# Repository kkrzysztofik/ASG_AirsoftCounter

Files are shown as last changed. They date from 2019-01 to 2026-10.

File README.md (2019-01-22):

Schemat mocno uproszczony, bez masy, ani zasilania. Same kable sygnałowe. Do otworzenia w progamie http://fritzing.org/home/

Budowa i części opisane w temacie:
https://forbot.pl/forum/topic/12780-airsoftowy-gadzet-koparka-airsoftcoin/

Filmik z działania: https://www.youtube.com/watch?v=qoA_SEkDOQQ

Przy pierwszym uruchomieniu trzeba odkomentować linijkę 27 z pliku System.cpp, żeby wgrać podstawowe ustawienia. Następnie trzeba uruchomić urządzenie, zakomentować linijkę ponownie i wgrać program ponownie. Dopiero wtedy zapis ustawień będzie działał poprawnie. 

Licencja mit, więc można budować, przerabiać, a nawet sprzedawać.

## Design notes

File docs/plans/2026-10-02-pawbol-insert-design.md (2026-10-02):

# Pawbol S-BOX 416-P insert: base tray and lid panel

Date: 2026-10-02
Status: model written 2026-10-02, `make mech` green (13 checks, 9 parts, all single solids). The
retention scheme and the cell cradle both changed while the geometry was being built; see "Changes
during implementation" below. Every number is either read from a source named beside it, or listed
under "Must be measured" / "Unverified".

The budget tier's Pawbol enclosure ships as an empty tub: **no mounting plate, no brass inserts, no
knockouts**. This spec adds two printed PETG parts so a unit can be assembled by dropping parts in
and turning four screws, instead of measuring standoffs into base bosses.

Follows the same generator philosophy as the boards (`design.py` -> `gen_sch.py`/`gen_pcb.py`): one
Python module holds the numbers, one command emits the artefacts.

## Goal

- Give the pack board, its four 18650 cells, the carrier and all off-board parts a defined home.
- Keep the assembly reversible and the enclosure unmodified apart from the holes the panel devices
  need anyway.
- Close the risk the pack design already flags: "spring-contact holders can open momentarily under
  shock (airsoft use) ... add a strap or lid". The printed cradle is that strap.

## Scope

In: the base tray, the lid panel, the speaker grille, drill templates, and the build tooling.

Out: the carrier and pack PCBs, the panel devices themselves, the Deluxe Kradex ZP240.190 enclosure
(240 x 191 x 106, has its own plate), the firmware.

## The enclosure: facts

Source: Pawbol *KARTA KATALOGOWA, Puszka instalacyjna serii S-BOX 190x140x70 / bez dławików*,
S-BOX 416_416B_416-P, fetched 2026-10-02. The drawing carries the note **"Wymiary A, B, C są
wymiarami wewnętrznymi S-BOX"** — A, B and C are inside dimensions.

| Quantity | Value | Origin |
|---|---|---|
| Inside (A x C x B) | 190 x 140 x **70** mm | drawing note; the 70 is the **base** interior, the lid recess sits on top of it |
| Outside | 196 x 146 mm, base height 78 mm | drawing |
| Wall thickness | **3 mm** | (196 − 190) / 2, confirmed by (146 − 140) / 2 |
| Corner screws | 4, plastic, through the **lid** into full-height corner columns | drawing + product photo |
| Corner column thread depth | about 50 mm (drawing dimension "50") | drawing, unverified |
| Seal | gasket between lid and rim, IP65 | product description |
| Body / lid | PS/ABS RAL 7035 / transparent, −25…+60 °C | catalog table |
| Supplied | **bare tub.** No plate, no inserts, no glands | shop listing, `COSTS.md` |
| Internal features | central cross rib with slots, round floor bosses | drawing |

**The box being ordered has plain side walls — no Ø37 PG29 membranes.** The shop's listing for
416-P advertises 10 knockouts at Ø37/PG29, but the version on order has none (confirmed
2026-10-02). Every wall penetration is therefore a hole that gets drilled. Treat *all* internal
floor features as unverified: do not design anything that depends on the rib or the floor bosses.

## Decisions

| Decision | Choice | Basis |
|---|---|---|
| Part split | **base tray + lid panel**, two prints | keeps the transparent lid face intact, so the LCD needs no window and no gasket |
| Retention | tray sleeves drop **over** the 4 corner columns and locate the tray in X/Y; the lid panel rests on the sleeve tops and the closed lid presses the whole stack down. **No screw stack change** | the column top and the lid plate share the rim plane, so a flange between them lifts the lid off its gasket — see "Changes during implementation" |
| LCD | 20x4 pressed against the inside of the clear lid by a printed frame | same call as the Kradex design (`2026-09-28-esp32-lora-carrier-design.md`): "LCD behind clear lid (no window)" |
| NFC | PN532 in a panel pocket, tapped through the clear lid | carrier design: 3–5 cm expected through 3 mm PC; keep >=20 mm off the LCD frame |
| Buttons | 2 x Ø16 in the **lid**, drilled with a printed 1:1 template | user 2026-10-02; matches the panel's button bosses |
| Speaker | 50 mm in a **wall**, printed **mesh grille** plate outside, foam gasket | user 2026-10-02 |
| Wall sealing | one printed bushing + O-ring per penetration, plus an internal backing block | user 2026-10-02; 3 mm PS/ABS cannot carry a tightened nut |
| Cells | printed **saddle rails** the cells rest in; the board's own holders capture them from above | pack design's shock-dropout risk. A separate hold-down bar was dropped: the holders already clamp the top, so a bar would add nothing |
| Panel vent | **none** | YAGNI. If the speaker sounds boxy in the sealed tub, add the small second mesh panel then |

## Changes during implementation

Three things the approved design assumed turned out not to survive contact with the geometry:

1. **The tray no longer takes the lid screws (was: option B).** The corner columns are solid to the
   rim and the lid seals on the rim, so a flange between the column top and the lid would lift the
   lid off its gasket. The sleeves now only locate the tray; the lid panel presses it down.
2. **The cell hold-down bar is gone.** The pack board's holders already clamp the cells from above,
   so the printed part only has to take the recoil load off the contacts. Two saddle rails do that
   with less plastic and no snap fit to get wrong.
3. **The carrier's posts are margin brackets.** All four of the carrier's M3 holes land inside the
   pack board's footprint, so posts cannot rise from the floor to the carrier. They stand in the Y
   margin either side of the pack board and reach in on 45-degree gusseted arms.

A fourth change is a finding rather than a decision: the LCD and the Heltec only clear each other by
5.5 mm on the assumed `LCD_DEPTH` of 13 mm. `check.py` fails if that narrows to under 2 mm.

## Interfaces

### A. Corner columns

The columns are solid from the floor to the rim, and the lid plate seals on the rim, so there is no
room between the column top and the lid for any printed flange: 3 mm of flange is 3 mm of lid lift
off its gasket. The tray therefore does not touch the screw stack at all.

Each corner gets a **sleeve** that drops over its column, 2 mm wall, stopping at the panel's
underside. The sleeves give the tray positive X/Y location, the box floor stops it going down, and
the lid panel — resting on the sleeve tops and pressed by the shut lid — stops it coming up.
`LEG_FLANGE_T` exists as a parameter in case the box proves to have room after all; it defaults to
0 and nothing else depends on it.

`SCREW_RASTER` is still needed, because it sets where the columns are. **Column size and raster are
unmeasured** — the fit coupon settles both.

### B. Board patterns

Read from the board modules, not invented here:

| Board | Outline | M3 hole raster | Source |
|---|---|---|---|
| Pack | 96 x 90 mm | (4, 4) (92, 4) (4, 86) (92, 86) — 88 x 82 | `hardware/pack.py:434,482` |
| Carrier | 90 x 60 mm | (3.5, 3.5) (86.5, 3.5) (3.5, 56.5) (86.5, 56.5) — 83 x 53 | `hardware/design.py:272,278` |

Both are `MountingHole_3.2mm_M3`. The tray posts are PETG, sized for an M3 self-tapping screw.
The pack board's own corner raster is still flagged provisional in the pack design doc, so the tray
posts are a parameter, not a constant.

### C. Cell cradle

Four troughs at the MYOUNG holder pitch, **21.66 mm** (pack design doc: holders 77 x 20.7 x 14.9 mm
bodies at 21.66 mm pitch), trough radius for an 18.4 mm cell plus clearance, with a snap bar over
the top. The pack board sits on posts above the cells and its holders sit in the troughs, so the
cradle takes the recoil load off the holder contacts.

### D. Wall penetrations

| Device | Hole | Notes |
|---|---|---|
| Key switch | Ø22.3 | EAO 82-6121.2000 / KS22; bushing also gives it something to tighten against |
| Speaker K50 | Ø50 | printed mesh grille plate outside, foam gasket; **the only hole that also gets a printed drill guide ring** |
| USB-C panel extension | Ø12.2 nominal, **measure the actual barrel thread** | IP67 only while capped or mated |
| SMA bulkhead | Ø6.5 | O-ring plus star washer, hex pocket inside to hold the nut |
| Buzzer BZ-38 | measure the body | no IP rating of its own — bushing + O-ring is what seals it |

Positions are free parameters; the defaults keep the SMA high on a long wall, away from the u.FL pad
and the LCD.

### E. Lid

- 2 x Ø16 button holes, 1:1 printed template, backed by the panel's button bosses.
- LCD frame presses the 20x4 against the clear face.
- PN532 pocket, >=20 mm from the LCD metal frame.
- 4 corner ears in the screw stack of interface A.

## What gets printed

| Part | Qty | Material | Purpose |
|---|---|---|---|
| Base tray | 1 | PETG | corner legs, cell cradle + snap bar, board posts, cable clips, wall backing blocks |
| Lid panel | 1 | PETG | LCD frame, button bosses, NFC pocket, 4 corner ears |
| Speaker grille plate | 1 | PETG | 50 mm mesh, covers the wall hole from outside, foam gasket |
| Drill guide ring | 1 | PETG | clamps to the wall for the Ø50 holesaw only |
| Drill templates | — | paper | 1:1 sheets, same style as the existing `fab/print_1to1.pdf` |

## The height budget

Measured from the tray floor up:

| Item | mm |
|---|---|
| Tray floor | 2.4 |
| 18650 cell | 18.4 |
| Pack board | 1.6 |
| Standoffs, pack -> carrier | 8 |
| Carrier | 1.6 |
| Heltec in its 2x18 headers | 15 |
| **Subtotal from the floor** | **47.0** |
| LCD + HW-61 backpack (hangs from the lid) | 12–20 |
| Lid panel | 3 |
| **Total** | **62–70** |

Against 70 mm of base interior plus the unmeasured lid recess. It fits, with the lid recess as the
margin. This replaces the first estimate, which wrongly assumed the 70 mm included the lid.

## Parts and repo layout

```
hardware/mech/
  insert.py      # parameters + the tray, panel, grille and template builders
  out/           # generated *.step/*.stl (gitignored); print_1to1.pdf is committed,
                 #   as fab/print_1to1.pdf already is for the boards
```

The build123d model is one module in the repo's style: all dimensions as named top-level parameters,
one `main()` that writes every artefact, one self-check that runs on plain `python3` without
build123d installed.

```bash
make mech          # new target in hardware/Makefile, next to `boards`
```

**Toolchain:** `uv` with PEP-723 inline script metadata, so `uv run hardware/mech/insert.py` resolves
build123d without a venv or a requirements file. Verified 2026-10-02: build123d 0.13.0 imports under
`uv run --with build123d` on this machine.

## Parameters (named, with defaults)

| Parameter | Default | Status |
|---|---|---|
| `BOX_IN` | (190, 140, 70) | firm |
| `WALL` | 3.0 | firm |
| `COLUMN_XY`, `COLUMN_SIZE` | — | **must measure** |
| `SCREW_RASTER` | — | **must measure** |
| `SCREW_THREAD` | M4 assumed | **must measure** |
| `LID_T`, `LID_RECESS` | — | **must measure** |
| `PACK_XY`, `PACK_HOLES` | (96, 90), 4 mm inset | from `pack.py` |
| `CARRIER_XY`, `CARRIER_HOLES` | (90, 60), 3.5 mm inset | from `design.py` |
| `CELL_PITCH`, `CELL_D` | 21.66, 18.4 | pack design doc |
| `STANDOFF_H` | 8.0 | stack budget |
| `FIT` (drop-in clearance) | 0.4 | tune on the coupon |
| `BUTTON_D` | 16.0 (19.0 Deluxe) | `COSTS.md` |
| `SPEAKER_D` | 50.0 | `OFFBOARD_PARTS.md` |
| `MESH_OPEN` (open area) | >= 40 % | acoustic floor for a printed grille |

## Must be measured before the first real print

1. Corner column: outer size, inner bore, depth, wall-to-column gap.
2. Corner screw: thread, length, how deep it engages.
3. Lid: thickness, the internal corner posts, and the recess depth above the base rim.
4. 20x4 LCD + HW-61 backpack depth.
5. Heltec V4 board-to-header-top height when seated in the carrier.
6. Button body depth and thread length; USB-C barrel thread; SMA thread length.

## v2 (2026-10-02): simplified tray

v1's tray was 117.7 cm3, and a per-feature measurement showed where it went:

| feature | v1 cm3 | share |
|---|---|---|
| floor plate | 44.5 | 35 % |
| wall backings + stems | 23.3 | 18 % |
| carrier posts + arms | 20.1 | 16 % |
| cell saddle rails | 18.6 | 15 % |
| corner L-sleeves | 12.3 | 10 % |
| pack posts | 5.5 | 4 % |
| cable clips | 2.2 | 2 % |

v2 is three changes, none of which moves a single interface:

1. **The floor's empty middle is cut away.** A rim and the two Y bands that actually carry the
   posts, clips and sleeves; the windows stop exactly at the saddle rail edges, because a window
   boundary inside a rail would leave a sliver of floor beside it. 32 % of the floor area goes.
2. **The wall backings are gone** (−23.3 cm3). They existed to hold a nut while you tighten a
   panel device in a 140 mm-deep tub. A nyloc and a finger do the same job. The devices, their
   hole sizes and their drill templates are unchanged.
3. **The saddle rails are 6 mm wide instead of 8** (−4.6 cm3).

Tray 117.7 → **77.9 cm3** (MJF) / 80.6 (FDM). Everything 145.7 cm3, down from 185.4.

### The carrier did not move, and that was decided by search

Moving the carrier onto the lid panel was measured at 20.1 cm3, about $6. It was not taken,
because it does not fit: an exhaustive search at 2 mm resolution over every legal panel position
found **609 valid LCD+carrier pairs and zero valid LCD+carrier+NFC triples**. The panel is
188.4 x 138.4; the LCD (98 x 60) and the carrier (90 x 60) already take two 60 mm bands, and the
NFC needs a 45 x 45 patch that is also >= 20 mm from the LCD frame, while four corner reliefs
punch the margins. Without the NFC it fits immediately (LCD at y 0.4–60.4, carrier at
64.4–124.4, 4 mm apart, ~50,000 legal button positions), but that would have moved the player's
tap from the top of the box to its side, for $6.

So the carrier keeps its margin posts and gusseted arms. Nothing on the panel, in the assembly
order or in the cable route changed between v1 and v2.

## Print cost

MJF and SLA are priced per cm3 of solid material, and the first quote came back at about $100 for one
unit. `quote.py` measures the exported mesh (`stl_volume_cm3`, a signed-tetrahedron sum, so it is
independent of the CAD) and puts a number on where that goes:

| Part | cm3 | Share |
|---|---|---|
| Tray | 77.9 | 53 % |
| Lid panel | 45.6 | 31 % |
| Grille | 8.0 | 5 % |
| Guide ring | 7.2 | 5 % |
| 4 wall rings | 6.9 | 5 % |
| **Total** | **145.7** | |

v1 was 262 cm3 before the guideline pass and 185.4 after it; v2 is 145.7, so the two rounds together
have taken 44 % off. The wall backings and the floor windows were the two features that were pure
bulk; the corner sleeves, saddles and posts are structure and do not shrink further without
giving something up.

A first pass took this from 262 cm3 to 180 cm3 by cutting the two features that were pure bulk: the
wall backings were 26 x 12 mm solid blocks (now a 20 x 6 mm nut pocket, which also stopped them
colliding with the corner columns) and the corner sleeves were closed square tubes (now L-shaped,
same location, a third of the material).

**Two big flat plates are the wrong shape for a volume-priced process.** The tray and lid are 88 % of
the cost and both are things an FDM printer does well: at 15-20 % infill they are roughly 40 g of
filament. Options, cheapest first: print them locally in PETG; buy them from an FDM service; or keep
MJF for the small parts, where the four bushings and the grille are about 15 cm3 together.

Do not skeletonise the tray further to chase cost. Its floor carries the posts, the saddles and the
wall backings, and the remaining bulk is structure, not slack.

## JLC3DP design guideline compliance

Source: <https://jlc3dp.com/help/article/3d-printing-design-guideline>, read 2026-10-02. The MJF
column applies. `check.py` asserts each rule, so a later tweak cannot quietly break one.

| Rule | Guideline | This design |
|---|---|---|
| Build size | MJF max 380 x 284 x 380; min 5 x 5 x 5 or 10 x 2 x 2 | largest 188.4 x 138.4 x 67.6; smallest a 4 mm thick ring, which passes on the 10 x 2 x 2 form |
| Wall thickness | 1.0 / 1.2 / 1.5 mm at 50 / 100 / 200 mm part size | every wall sized against its own part: floor field 1.6, sleeve 2.0, panel 2.5, mesh land 1.5, ring width 6.0 |
| Assembly clearance | 0.2-0.4 mm per side | 0.4 mm per side |
| Hole aperture vs depth | about 3x the diameter | pilot 2.7 x 5, clip groove 4.4 x 10, mesh 3.5 x 1.5 |
| Small columns | D = 3 mm permits H = 3-6 mm | posts are 4:1, so each gets a 3 mm 45-degree base flare |
| Escape holes | 2.5 mm minimum into any enclosed cavity | no part encloses a cavity; asserted by shell count |
| Embossed detail | 0.8 mm deep and wide | none modelled yet; the NFC "tap here" mark will need it |
| Threads | M6 minimum if printing threads | none printed; the posts take M3 self-tapping screws into a 2.7 mm pilot |

Four real non-compliances turned up, all fixed:

1. **Wall thickness.** The tray floor field was 1.2 mm where MJF wants 1.5 at this part size, and the
   speaker mesh land was 1.0 mm where it wants 1.2. The floor field is now 1.6 mm and the mesh land
   1.5 mm (2.7 holes became 3.5 mm at a 5.0 mm pitch, which still opens 42 %).
2. **Assembly clearance.** An 0.4 mm total drop-in gap is 0.2 mm per side, but MJF's hole tolerance is
   +/-0.3 mm *and* holes shrink, so the gap was inside the process noise and the tray could arrive
   unable to go in. `FIT` is now 0.8 mm: 0.4 mm per side.
3. **The bushings were degenerate.** Once the wall is drilled at the device's own size there is no
   annulus left for a barrel: for the SMA, 6.5 mm hole against a 6.4 mm device gives a *negative*
   wall. They are rings now, which is what a 3 mm PS/ABS wall around a 22 or 30 mm hole actually
   needs, and the O-ring still seats on the ring.
4. **The printed posts are 4:1 slender**, where the column table allows 2:1. They are attached at the
   base rather than free-standing, but bead blasting is unkind, so each gets a 3 mm 45-degree flare
   for about 2 cm3.

One thing to raise with the shop before committing: the guideline says a large hollow structure is
priced as a "special-shaped model" with a surcharge, and the tray and lid are exactly that.

## Verification

1. **Self-check** (`python3 -c` importable without build123d): bounding box fits `BOX_IN` minus
   clearance, the two post rasters equal the board modules' `PLACE["H*"]` coordinates, and the stack
   total in the table above is <= the base interior.
2. **Fit coupon first** — a single small print carrying one corner leg, one column sleeve and one
   board post. It settles interface A (the only interface with no second chance: a wrong column
   means a reprint of the whole tray). Print the coupon before the tray, always.
3. **1:1 paper templates** against the real box for the button and wall holes, before any drilling.
4. `make mech` green, plus a 1:1 outline print of the tray to lay on the box floor.

## Risks

- **Corner column unmeasured.** The leg is the one feature that cannot be salvaged after printing.
  Mitigated by the coupon and by `FIT` being a parameter.
- **Lid internal corner posts** may collide with the panel ears. Measure before printing the panel.
- **Screw length.** Adding 6 mm may exceed the original screw. Fallback: four longer plastic screws,
  or a printed captive-nut corner that drops the column's thread entirely.
- **Drilling PS/ABS by hand** crazes or cracks the wall. Use a step drill or holesaw at low speed,
  back the wall, and use the printed guide ring for the Ø50.
- **Printed mesh** attenuates high frequencies. Keep open area >=40 %, slots not round holes, and put
  the grille as close to the speaker as the wall allows.
- **Sealed tub** with the speaker inside: no vent. Accepted for now; the small mesh vent is the
  known upgrade path if it sounds boxy.
- **PETG at 60 °C** (the box's rated top): Tg is about 80 °C, so no creep expected, but the panels
  are clamped, not load-bearing.

## Unverified

- Every `must measure` item above.
- Whether the delivered plain-wall box still has the central cross rib and the floor bosses. Nothing
  in the design depends on them.
- The corner column's thread depth ("50" on the drawing is almost certainly this, but it was read
  from a section view, not from a dimension table).
- The exact 416-P lid screw part. The tray assumes a reusable, standard plastic screw.

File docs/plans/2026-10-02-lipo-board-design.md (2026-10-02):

# AirsoftCounter LiPo board: 2S/3S airsoft LiPo instead of the 18650 pack

Date: 2026-10-02
Status: hardware generated (`make BOARD=lipo all` into `fab/lipo/`). A third power board next to the 18650 pack variants A
(`2026-10-01-pack-board-design.md`) and B (`2026-10-02-pack-board-variant-b-design.md`). Fit one
power board per build; the carrier does not change.

## Goal

Run the device from the 2S/3S LiPo an airsoft player already carries (XT60 or T-plug, with a balance
lead). **No charging**: players charge on their own balance charger. The board must protect the
LiPo from over-discharge per cell, without relying on the Heltec firmware.

## Why a separate board

Putting a LiPo input on the 18650 pack board was rejected: feeding a buck into SYS lets the
BQ25601 BATFET charge the 18650s from the LiPo with nothing controlling it. Avoiding that needs
ideal-diode ORing before the key, a second ADC and board space the 96 x 90 mm pack does not have.
A separate board has no cells, charger or per-cell switches, so it is small.

A "dummy cell" (a buck module whose output goes into an 18650 holder) was rejected: it has no LVC.

## Why it keeps an MCU

The system is 1S throughout (`VBAT_SW` 3.0-4.2 V feeds the Heltec battery socket and the amp), so
the board bucks the LiPo down to a fake single cell. The low-voltage cutoff must **latch**: a cutoff
that removes its own supply restarts and trips again in a loop until the pack is flat (this kills
the "ADS1115 ALERT pulls buck EN" idea, and any Heltec-driven cutoff). An always-on MCU holds the
cutoff and does a per-cell check through the balance lead. Three comparators, a reference and a
latch would cost more parts than one STM32C071, and that chip is already used in variant A.

## Block diagram

```
XT60 pigtail ─ fuse 5 A ─ rev-pol P-FET ─ TVS ─┬─ HV LDO 3.3 V (Iq <= 5 uA) ── STM32C071 [always on]
                                               ├─ buck A -> 4.10 V -> VBAT_SW ─┐
                                               └─ buck B -> 5.07 V -> +5V ────┤ J_PWR1 6-pin XH
both buck EN = key (pull-up) AND MCU_OK (open-drain)                          │ to the carrier
balance 4-pin XH ─ dividers (always on) ─ MCU ADC; MCU = I2C slave 0x30 ──────┘
```

## Blocks

### Input
- **XT60 pigtail**: a short 14 AWG (1.5 mm2) lead soldered to the 1.5 mm2 2-pad solder-jumper
  footprint, with a female XT60 panel or inline connector. T-plug users use an adapter lead.
- **Fuse 5 A** SMD, first part after the input. A LiPo short is hundreds of amps.
- **Reverse polarity**: P-FET in the positive lead, gate to GND through a resistor, zener gate clamp.
- **TVS** across the input, standoff above 12.6 V (3S full), clamp below the bucks' absolute max.
- Input range to design for: **5.5-17 V working, >= 20 V absolute** (2S empty to 4S full, so 4S
  could be added later without new parts).

### Bucks
- **One IC type used twice**, >= 20 V input, >= 3 A, with an EN pin that has a defined threshold.
  Pick the part with datasheet facts and live stock, like P0 of the pack plan.
- **Buck A -> 4.10 V on `VBAT_SW`**: Heltec battery socket and amp (1.5 A peaks). 4.10 V is below
  4.2 V, so a plugged-in Heltec USB charges into the buck output harmlessly (the buck cannot
  sink; its output rises and it stops switching). Keep `VBAT_SW` bulk capacitance at the amp as on
  the carrier.
- **Buck B -> 5.07 V on `+5V`**: LCD, LEDs, buzzer. Two bucks convert more efficiently than a buck
  to 4 V plus the MT3608 boost back up, for the same part count.

### Always-on supply
- HV LDO 3.3 V, >= 20 V input, Iq <= 5 uA, feeding only the MCU and the divider gate.

### Enable
- **EN = key AND MCU_OK**: the off-board key (`J_KEY`, same connector as the pack boards) supplies
  the EN pull-up, so only microamps pass through it. The MCU pulls EN low through an open-drain pin
  to cut both bucks. Check the EN pin's voltage rating against the pull-up source.

### MCU (STM32C071)
| Function | Use |
|---|---|
| ADC | 3 balance taps + pack total, through dividers |
| GPIO out | buck EN override (open-drain kill FET) |
| I2C slave 0x30 | on the carrier bus over `J_PWR1`; pull-ups on the carrier (no back-powering) |
| Flashing | SWD pads + BOOT0; no USB on this board |

### Balance input
- **One 4-pin XH header**: a 2S balance plug (3-pin XH) fits its pins 1-3. Pin 4 (3S tap) gets a
  pull-down, so a 2S pack reads about 0 V there.
- Dividers sized for 4.2 V x 3 at the top tap, always on: with Basic megohm values they draw
  about 10 uA, next to the MCU's 85 uA Stop current. Each ADC pin gets a 100 nF cap for a low
  source impedance. The top tap is also the pack total, so no separate total divider.

### Carrier connector
`J_PWR1`, unchanged from the pack boards: 1-2 GND, 3 `VBAT_SW`, 4 `+5V`, 5-6 SDA/SCL.

## LVC policy (firmware, defaults to tune with real packs)

- At power-up detect the cell count: 3S tap below 0.5 V means 2S. Reject a pack with a cell below
  the cutoff (stay off, flag it).
- **Warn** at 3.5 V per cell under load (flag for the Heltec to show).
- **Cut** at 3.3 V on any cell, debounced about 2 s so amp peaks do not trip it. The cutoff
  **latches**: EN held low through key cycles.
- **Release** only when every cell rests above 3.7 V (in practice: a fresh pack was plugged in).
- No balance lead: run on the total voltage with the cell count unknown, so warn and stay off (or
  allow with an assumed count; decide during firmware).

Register map: a subset of variant A at 0x30 (version, flags, cell mV x3, cell count, state,
cutoff reason), so the Heltec driver and the `asg-core` `pack` register definitions carry over.

## Key-off drain

STM32C071 Stop about 85 uA (variant A figure) + LDO <= 5 uA + bucks in shutdown (a few uA) +
dividers always on (about 10 uA): **about 110 uA**, so more than a year to drain a 1300 mAh pack.
A LiPo left plugged in is not drained in practice.

## Left out
Charging, balancing, coulomb counting (no current sense), 4S (the input rating leaves room).

## Repo effort
- `hardware/lipo.py` as a board module, built with `make BOARD=lipo all` into `fab/lipo/`. Reuse
  the MCU block from `pack.py` by import if it separates cleanly, as `pack_b.py` does; otherwise copy it.
- Firmware: a `firmware/lipo` sibling of the deferred pack firmware (ADC, thresholds, one GPIO,
  I2C slave). Deferred together with the pack firmware.

## Parts (verified 2026-10-02)

Sources: vendor datasheets and the live JLCPCB parts API (type: B Basic / P Preferred / E Extended).

| Item | Decision | Source | Date |
|---|---|---|---|
| Buck (x2) | TPS54302DDCR, TSOT-23-6, C311983 (E): VIN 4.5-28 V rec / 30 V abs; VREF 0.596 V typ; EN rising 1.23-1.28 V, EN abs max 7 V (rec max 5.5 V); shutdown 2 uA; HS current limit 4/5/6 A; 100% duty at 6 V in / 4.1 V out; fSW 400 kHz | TI SLVSDG6C (rev. 2026-03) | 2026-10-02 |
| EN node | R_EN1 100k / R_EN2 47k: EN = 0.32 x VIN -> 4.17 V at 13.05 V and 5.37 V at 4S 16.8 V, under the 5.5 V recommended max and 7 V abs max | TI SLVSDG6C | 2026-10-02 |
| Feedback | Vout = 0.596 x (1 + Rtop/Rbot). Buck A 30k/5k1 -> 4.10 V; buck B 75k/10k -> 5.07 V. Datasheet recommends Rtop ~ 100k (Table 7-2); the Basic 30k/75k tops give exact E24 ratios at ~100 uA divider current while the key is on (bucks are off when the key is open) | TI SLVSDG6C Table 7-2 | 2026-10-02 |
| Output filter | 10 uH + 2 x 22 uF 25V per buck (Table 7-2: 10 uH, 44 uF at 5 V) | TI SLVSDG6C | 2026-10-02 |
| Inductor (x2) | Bourns SRN6045TA-100M, C2046332 (E): 10 uH +-20%, DCR 52 mOhm, Irms 3.20 A (40 C rise), Isat 4.60 A (30% L drop) >= 3.5 A, so one part for both bucks | Bourns SRN6045TA datasheet | 2026-10-02 |
| Always-on LDO | Holtek HT7533-1, SOT-89-3, C14289 (B): supply abs max -0.3..33 V, VIN max 30 V, Iq 2.5 uA typ / 4.0 uA max, 100 mA; pins 1 GND, 2 VIN, 3 VOUT; C_in = C_out = 10 uF | Holtek HT75xx-1 Rev 2.40 | 2026-10-02 |
| LDO series R | none: the 33 V abs max is above the SMBJ15A 24.4 V clamp | Holtek + Littelfuse | 2026-10-02 |
| Reverse FET | AO3401A, SOT-23, C15127 (B): VDS -30 V, VGS +-12 V, RDS(on) 60 mOhm at VGS -4.5 V, ID -4 A; pinout 1 G, 2 S, 3 D. Was AO3407A (E, VGS +-20 V); the 10 V gate clamp keeps VGS inside +-12 V | AOS AO3401A datasheet; JLCPCB API | 2026-10-02 |
| Input TVS | SMBJ15A, DO-214AA, C19077569 (P, hongjiacheng; was C113988 E): VRWM 15 V (above 12.6 V 3S full), VBR 16.7-18.5 V, VC 24.4 V at 24.6 A, 600 W; below the buck 30 V and LDO 33 V abs max | Littelfuse / Diodes SMBJ15A | 2026-10-02 |
| Gate clamp | MMSZ5240B, SOD-123, C19077425 (P): 9.5-10.5 V, 500 mW. Below the AO3401A's 12 V VGS limit, also with VIN at the 24.4 V TVS clamp (0.14 mA through R_REV1). Replaces BZT52C12 (E); the earlier "no Preferred 12 V zener" note was wrong (MMSZ5242B C19077426 is Preferred) | JLCPCB API | 2026-10-02 |
| Input leads | Connector_Wire:SolderWire-1.5sqmm_1x02_P6mm_D1.7mm_OD3mm, 14 AWG / 1.5 mm2: the ~3 A worst case at 2S empty is marginal on 1 mm2 (17 AWG); 1.5 mm2 matches common XT60 pigtails and the 1.7 mm hole takes 14 AWG | design-doc current; KiCad footprint | 2026-10-02 |
| Balance header | one B4B-XH-A (C144395): JST XH is a 2.5 mm friction-lock box-shrouded header; a 3-circuit XHP housing seats on pins 1-3 and locks on the full-length shroud wall. Tap 3 then reads 0 V on a 2S pack | JST XH series drawing | 2026-10-02 |
| Dividers | Basic 1M (C17514) / 470k (C17709): tap1 470k/1M -> x0.680, tap2 1M/470k -> x0.320, tap3 2M/470k -> x0.190; at 4.35 V/cell (13.05 V pack) the taps read 2.96 / 2.78 / 2.48 V, all under the 3.3 V ADC ref | design values | 2026-10-02 |

### Plan-time changes

- Balance dividers are always on: no divider switch and no separate pack-total divider (the top tap
  is the pack total). With Basic megohm values they draw about 10 uA, next to the MCU's 85 uA Stop
  current; each ADC pin gets a 100 nF cap for a low source impedance.
- No reset/boot buttons and no status LED: SWD pads only (a blank STM32C0 boots its ROM bootloader
  by itself). Saves the TACT and LED and their drain.
- The bucks default ON when the key is on: the kill FET's gate has a pull-down (R_GK), so the bucks
  run with the MCU unflashed (bring-up) and the firmware latches them off.
- One 10 uH inductor (`L_A` = `L_B`, C2046332) for both bucks: its 4.6 A Isat covers buck A's peaks.

## Generated

`hardware/lipo.py` -> `make BOARD=lipo all` writes `lipo.kicad_sch`, `lipo.kicad_pcb` and the JLCPCB
package into `fab/lipo/` (gerber zip, BOM/CPL, schematic and renders). Freerouting: 462 tracks/vias,
0 unrouted; ERC 0, DRC 0 violations, 0 schematic-parity issues; gerbers 11 files, 70 x 50 mm,
4 x 3.2 mm NPTH. The 49 placed parts are 38 Basic, 4 Preferred (75k C17819, BSS138 C7420339, MMSZ5240B C19077425, SMBJ15A C19077569) and
7 Extended LCSC numbers (9 placements): 4 SMD types (5 A fuse C48332, TPS54302 x2 C311983,
SRN6045TA x2 C2046332, STM32C071 C42116633) and the
3 through-hole XH headers (KEY C158012, BAL C144395, PWR C144397). Economic PCBA charges one
feeder-setup fee per SMD Extended type; the XH headers are per-joint.

**SW node width (whole-branch review, 2026-10-02).** The two switch nodes route at the Default
0.25 mm, not the Power 0.8 mm the plan listed: the TSOT-23-6 SW pad at 0.95 mm pitch only admits a
necked exit, so no class width widens the run (Freerouting left it unrouted at 0.8 mm). `SW_A`'s
~8 mm run carries buck A's inductor current, ~1.5-2 A RMS (Heltec TX peaks plus brief amp peaks);
0.25 mm / 1 oz is about 0.9-1.4 A at a 10-30 C rise, i.e. at the edge of its rating. It is accepted
for the bursty airsoft duty on a short run with GND pours on both layers; a manual neck-and-widen
(the autorouter cannot express it) is the upgrade path if a wider margin is wanted.

## Bring-up

Bench supply on `J_IN1` at 7.4 V with a 100 mA limit:
1. Key open: only the LDO runs. `TP_3V3` reads 3.3 V and the input current is a few hundred uA with a
   blank MCU (STM32C0 Stop ~85 uA + LDO ~2.5 uA + dividers ~10 uA + buck shutdown).
2. Key closed: `VBAT_SW` 4.10 V and `+5V` 5.07 V. The bucks default on because `R_GK` pulls the kill
   FET's gate low; the firmware latches them off later.
3. Reversed supply: no current (the reverse P-FET blocks; the TVS should not conduct).
4. Then a real 2S pack and a real 3S pack, reading the three balance taps through the firmware.

## Unverified
- STM32C071 system bootloader over I2C (AN2606): if it is supported, the Heltec could flash the
  board over `J_PWR1` and the SWD pads would be for recovery only.
- Debounce time and thresholds with a real amp load on a worn pack.

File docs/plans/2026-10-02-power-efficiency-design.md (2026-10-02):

# AirsoftCounter power efficiency: a weekend on the 18650 pack

Date: 2026-10-02
Status: docs and model done (E1-E3); firmware C2-C8 and validation wait for the hardware. No board changes.

## Goal

One charge of the 18650 pack (4x Samsung 35E, variant A or B) lasts a **weekend**: 2 game days of
10 h plus a 12 h night with the key left on, at 0 °C, on cells aged to 80 % capacity. A player's
LiPo (LiPo board) is a one-day battery and is swapped like a gun battery; it is out of scope.

## Where the energy goes (`hardware/power_budget.py`, Deluxe, game running)

| Load | mA (battery side) |
|---|---|
| 5 V rail via MT3608 (100 mA backlight planning value) | 209 |
| Heltec awake, LoRa RX (240 MHz, no light sleep) | 75 |
| GNSS | 29 |
| PN532 polling | 20 |
| LoRa TX + amp | 13 |
| **Total** | **346** |

Weekend budget: 13400 mAh x 0.84 usable x 0.8 (0 °C) x 0.8 (aged), minus 12 h parked at ~7 mA,
over 20 h of game = **~350 mA**. Today's estimate passes with no margin, and the backlight figure
is still a guess.

Modelled after the display change (E1, `power_budget.py` weekend block, budget 353 mA): today's
firmware with the backlight always on 236 mA (+50 % margin), backlight on a timeout 196 mA (+80 %),
optimized firmware 74 mA (+377 %). The Newhaven alone meets the goal; the firmware work is margin.

## Decisions

### 1. Display: Newhaven NHD-0420D3Z-FL-GBW-V3 replaces the blue 2004A + HW-61

One display for the Deluxe and Budget builds.

- Transflective STN(+), yellow-green: readable in daylight with the **backlight off**. The blue
  2004A is a negative panel and unreadable without its backlight.
- Backlight brightness 1-8 over I2C (`0xFE 0x53 n`, 1 = off, 100 us); the module PWMs it.
- 5 V, 21-44 mA total with the backlight on (datasheet), -20..+70 °C.
- I2C address 0x28 (7-bit), no clash (TCA9534 0x20/0x21, PN532 0x24, PAC1934 0x10, pack MCU
  0x30, ADS1115 0x48). **I2C max 50 kHz**: the shared bus runs at 50 kHz.
- 10k pull-ups on the module, so `R_SDA5/R_SCL5` stay DNP. Same 4 wires to `J_LCD1`
  (GND 5V SDA SCL): **no carrier change**.
- Ships in RS-232 mode: **bridge jumper R1** for I2C. 100 ms power-up delay before the first
  command. Its own command set (not HD44780), so C3 writes one small driver and the PCF8574 path
  is not needed.
- About $17 (Mouser 763-0420D3ZFLGBW-V3, Newhaven direct); TME has none.

Rejected: generic yellow-green 2004A + PCF8574 (on/off only, transmissive, backlight current
undocumented); SparkFun SerLCD RGB (3.3 V logic, not transflective); PWM from an ESP32 GPIO (only
GPIO43/44 are free and they are UART0); PWM by toggling PCF8574 P3 (keeps the CPU awake).

### 2. Firmware power requirements (added to the C-tasks, implemented with the hardware)

| Task | Requirement | Target |
|---|---|---|
| C2 | I2C at 50 kHz (Newhaven limit) | - |
| C3 | Backlight off after a timeout; on (level from config) for a button, card or game event | backlight ~5 % duty |
| C1/C4 | CPU 80 MHz + automatic light sleep | Heltec 75 -> ~20 mA |
| C4 | Light only the ring that carries information | rings 2x -> 1x |
| C6 | PN532 PowerDown between polls; poll only when a card is expected | 20 -> ~5 mA |
| GNSS | One fix at boot, then VGNSS off | 29 -> ~1 mA |
| LoRa | SX1262 RX duty cycle; HQ sends a preamble longer than the sleep window | protocol note |

`R_LLR1/R_LLB1` (0R today) stay the ring brightness knob if the rings are too bright.

### 3. Power model (`power_budget.py`)

- Backlight duty parameter (default 5 %) and the Newhaven current.
- An "optimized firmware" scenario with the targets above.
- A weekend check that prints PASS/FAIL against the budget for today's and the optimized
  firmware, and asserts in the self-check that the optimized one passes.

### 4. Validation (once the hardware exists)

- Instrument: pack variant A's PAC1934 energy accumulators (per-cell Wh); USB meter on `J_PWR1`
  as a cross-check.
- Run each `power_budget.py` scenario for 30 min, replace every EST figure with the measured one,
  re-run the weekend check.
- Pass: measured Deluxe game current fits the weekend budget (~350 mA) with at least 30 % margin.
- Soak: full charge, game-loop firmware until the pack MCU cuts off; compare with the model.

## Not doing (add if the measurements miss)

- +5V load switch: parked drain is ~90 mAh per night, under 1 % of the pack.
- Hardware backlight PWM, LiPo-board changes, lower LoRa TX power.

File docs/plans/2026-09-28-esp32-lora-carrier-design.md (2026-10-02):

# AirsoftCounter v2: Heltec V4 + LoRa carrier board and Rust firmware

Date: 2026-09-28
Status: design approved, implementation not started

## Goal

Replace the hand-wired Arduino Nano build (soldered point-to-point, hot glue,
per-unit LCD address tweaks, not waterproof) with:

- a KiCad carrier PCB for a **Heltec WiFi LoRa 32 V4 (no-display build, R2 or R8)**,
- LoRa **remote control from HQ** (start/stop/configure + status reports),
- **GPS** position in status reports,
- phone configuration over **WiFi AP + web page** (IR remote dropped),
- a **20x4 transflective I2C LCD** (Newhaven NHD-0420D3Z-FL-GBW-V3, see the power-efficiency design),
- **RFID/NFC cards**: player cards (score + per-player stats) and admin cards,
- a **loudspeaker** (I2S class-D amp) in addition to the buzzer, with GPIOs freed by an **I2C GPIO expander** (Part 6),
- a **weatherproof enclosure** (Kradex ZP240.190.105SJp, clear PC lid, IP67),
- firmware rewritten in **Rust** (esp-hal + Embassy).

Existing Nano units are left as they are; no Nano carrier is planned.

## Part 1: MCU board, pins, power

### Heltec V4 facts (verified from Heltec pin maps and Meshtastic variants)

- J2 and J3 are 1x18 2.54 mm headers, identical physical layout on V3/V4.
  V4 adds a separate 4-pin strip (GPIO15-18) at the antenna end: not used.
- Native USB (no USB-UART chip). 5V pin is powered **only from USB** (max 500 mA).
- Battery: SH1.25 2-pin socket, onboard charger. VBAT sense on GPIO1 via
  100k/390k divider (R2 needs ADC_Ctrl GPIO37 HIGH; R8 has no ADC_Ctrl).
- Internally used GPIOs:
  - 2, 5, 7: LoRa front end (KCT8103L CSD, CTX, LDO power) on V4.3
  - 8-14: SX1262 (NSS, SCK, MOSI, MISO, RST, BUSY, DIO1)
  - 38-42: GNSS connector (TX 38, RX 39, PPS 41; EN 34/RST 42/STANDBY 40 on R2, EN 42 on R8)
  - 33-37: octal PSRAM on R8
  - 35/36 (R2) or 46/40 (R8): LED / Vext
  - 0, 45, 46: strapping; 19/20: USB; 26: PSRAM CS
- All EU868 V4s are the 28 dBm high-power version.

### GPIO assignment (valid on both no-display V4-R2 and V4-R8)

| Signal | GPIO | Header pin |
|---|---|---|
| I2C SDA (LCD) | 4 | J3-15 |
| I2C SCL (LCD) | 3 | J3-14 |
| Red button in | 6 | J3-17 |
| Blue button in | 44 | J2-5 (U0RXD; firmware must not use UART0) |
| Red LED out | 47 | J2-13 |
| Blue LED out | 48 | J2-14 |
| Buzzer out | 21 | J2-16 |
| Battery sense | 1 | onboard |
| GPS | 38/39/41/42 (+40 R2) | Heltec GNSS connector, no carrier involvement |

Spare: GPIO43 and the top 4-pin strip. Left unconnected.

### Power path

**Superseded 2026-10-01:** the cell protector, key switch, 2 A PTC and MT3608 boost moved to the pack
board (`docs/plans/2026-10-01-pack-board-design.md`). The carrier now takes GND / GND / VBAT_SW / +5V
/ SDA_3V3 / SCL_3V3 on a 6-pin J_PWR1; J_BAT, J_KEY and the boost no longer exist here.

```
1S Li-ion (2x18650 parallel) ─J_BAT─ PTC 1A ─ key switch (J_KEY) ─ VBAT_SW ─┬─ J_HBAT ─> Heltec SH1.25 battery socket
                                                                            ├─ 220 µF bulk
                                                                            └─ MT3608 boost ─> 5V_AUX (LCD, button LEDs, buzzer)
Heltec 5V pin: NOT connected (it is the charger input; feeding it would loop).
```

- MT3608 with fixed feedback resistors (no trimmer modules: they can ship set to 20V+).
- Charging only happens with the key ON (known, accepted trade-off).
- With key OFF and USB plugged in, the Heltec charger output (no battery) feeds
  VBAT_SW, so the boost and 5V loads run from it. Chargers may cycle without a
  battery: LCD flicker on the bench is expected and harmless.
- Budget: ~150-250 mA from battery; 6000 mAh ≈ 24+ h.
- Parallel cells must be matched and equalised before connecting.

## Part 2: I/O circuits and connectors

- **Output drivers (x3: LED R, LED B, buzzer):** BSS138 low-side, 1k gate
  series, 10k gate pull-down (keeps loads off during boot). R_LOAD footprint in
  series with load: 150 Ω (red), 100 Ω (blue), 0 Ω for buzzer or 5V-LED buttons. *(As built: 0 Ω for both, because the chosen ONPOW LAS1-AGQ 6 V buttons have built-in LED resistors; see hardware/fab/OFFBOARD_PARTS.md.)*
  1N4148W flyback across buzzer.
- **Button inputs (x2):** 10k pull-up to 3V3, 100 nF to GND, 1k series to GPIO.
- **I2C level shift:** 2x BSS138, 4.7k pull-ups on 3V3 side; 5V-side pull-ups
  footprinted, DNP (backpack already has them).
- **Connectors:** JST-XH 2.50 mm vertical, silkscreen-labelled with pin names.

| Ref | Pins | To |
|---|---|---|
| J_BAT | 2 | battery holder |
| J_KEY | 2 | key switch |
| J_HBAT | 2 | Heltec battery socket (SH1.25 to XH pigtail) |
| J_LCD | 4 | GND, 5V, SDA, SCL |
| J_BTN_R, J_BTN_B | 4 | SW, GND, LED+, LED- |
| J_BUZ | 2 | buzzer |
| J_NFC | 4 | GND, 3V3, SDA, SCL (3V3 side of the I2C bus, 100 µF nearby) |

Heltec USB-C, LoRa u.FL and GNSS cable go straight from the Heltec to panel parts.
Heltec sits in 2x 1x18 female headers. Parts: 0805, SOT-23, SOT-23-6, THT connectors.

## Part 3: PCB and enclosure

- 2-layer, 1.6 mm, solid ground pour on bottom. 90 x 60 mm (holes must clear the Heltec), 4x M3 holes 3.5 mm from corners.
- Heltec along one long edge, USB-C at board edge; antenna end overhangs the
  outline (no copper under the antennas). Connectors along the opposite edge,
  same orientation. Power section grouped in one corner, away from u.FL.
- **Header row spacing: 22.86 mm** (measured from Heltec STEP: 2x18 holes, 2.54 pitch); still verify
  with a 1:1 paper print against a real board.
- Enclosure: **Kradex ZP240.190.105SJp** (240 x 191 x 106 mm, clear PC lid, IP67,
  brass inserts) + **ZP240.190-PCB** mounting plate.
  - Lid: 20x4 LCD behind clear lid (no window), 2x IP67 anti-vandal 5V-LED pushbuttons.
  - Walls: IP65 key switch, IP67 capped USB-C panel extension, SMA bulkhead with O-ring (high on a wall).
  - Floor plate: carrier on M3 standoffs, 2x18650 holder, cable ties.
  - L76K GNSS module on a standoff near the lid, away from the LCD frame and battery.

## Part 4: Rust firmware

### Stack

esp-hal 1.2 + Embassy (embassy-executor 0.10, esp-rtos 0.4), no_std.
Toolchain: `espup` (Xtensa Rust), `espflash`, `esp-generate`.

| Concern | Crate | Notes |
|---|---|---|
| HAL | esp-hal | |
| Radio | lora-phy 3.0 (SX1262) | TCXO 1.8V via DIO3, DIO2 as RF switch; FEM pins 7/2/5 driven manually |
| LCD | own driver for the Newhaven command set (0xFE prefix) | I2C 0x28 at 50 kHz, 100 ms power-up delay |
| GPS | nmea 0.8 | UART1 on 38/39 |
| Config | sequential-storage + esp-storage | defaults when key missing |
| Phone config | esp-radio (WiFi AP) + embassy-net + picoserve | esp-radio is beta: implemented last |
| Auth | ccm + aes | AES-CCM, pre-shared key, per-sender sequence counter (replay protection) |
| NFC | pn532 0.5 | verify embedded-hal 1.0 support first; fallback: own minimal driver (InListPassiveTarget + page read) |

### Layout

```
firmware/
├── core/    no_std, host-testable: game state machine, protocol encode/decode, auth, config types
└── device/  esp32s3 binary: tasks, drivers, pin map; features v4-r2 / v4-r8
```

### Radio protocol (raw LoRa, star)

- Packet: `[net_id, dev_id, seq, type, payload, tag]`, AES-CCM authenticated.
- HQ → device: START, STOP, CONFIG, PING. Device → HQ: STATUS (state, score, battery, GPS), ACK.
- Commands are ACKed and retried.
- Channel 869.525 MHz (g3 sub-band, 10% duty, ≤500 mW ERP). TX power set
  explicitly in code; never rely on driver defaults (hardware can do 28 dBm).

### Milestones

0. Toolchain + blinky on V4
1. LCD + buttons + outputs: port Airsoftcoin mode, no radio
2. Config storage + battery reading
3. RFID: player captures, admin menu, first-admin enrollment
4. LoRa PING/STATUS between two V4s, then authenticated commands and capture events
5. GPS in STATUS
6. WiFi AP config page (incl. admin card list/remove)
7. HQ firmware: USB-serial ↔ LoRa bridge on a bare V4

Out of scope for now: laptop HQ app, OTA updates, additional game modes.

## Part 5: RFID cards

### Hardware

- PN532 module ("NFC V3" red board) in I2C mode (DIP switches), address 0x24,
  on the **3V3 side** of the I2C bus, powered from Heltec 3V3 (500 mA budget).
- No IRQ/RST wires: firmware polls over I2C (GPIO43 is U0TXD and toggles at boot).
- Mounted under the clear lid with a "tap here" mark, ≥2 cm from the LCD metal
  frame. Expected range ~3-5 cm through 3 mm PC.

### Cards

- **Player card:** NTAG213/215 with NDEF text record `ASG1:<team>:<id>`,
  team `R` or `B`, id 1-999. Written with any phone NFC app.
- **Admin card:** identified by UID, allowlist in device config.
- Unknown card: error beep.

### Behaviour

- Ready state: player card tap = capture for the card's team with player id.
  Buttons still capture anonymously (player id 0).
- Admin card tap (any state) opens admin menu on LCD, navigated with the two
  buttons: Reset game / WiFi setup / Status (battery, radio, GPS).
- First admin: when no admin is enrolled, holding both buttons while tapping a
  card enrolls it.
- Each capture `(team, player_id, time)` is queued and sent to HQ as an ACKed
  event. HQ owns per-player stats.
- RF field polled in bursts (~50 ms on / 300 ms), only in states where a card
  does something (~20 mA average).
- Card text parsing (NTAG pages → TLV → NDEF text → `PlayerCard`) lives in `core`.

## Part 6: Audio, GPIO expander, fewer Extended parts (approved 2026-09-29)

### Why
The user asked for a real loudspeaker in addition to the buzzer, and for Basic JLCPCB
parts wherever possible. I2S needs 3 fast GPIOs and none are free on both V4 variants,
so every slow signal moves to an I2C GPIO expander.

### Native GPIO map (supersedes Part 1 for these pins)

| GPIO | Signal |
|---|---|
| 3 / 4 | I2C SCL / SDA (LCD via the level shifter, PN532, expander) |
| 47 | I2S BCLK |
| 48 | I2S LRCLK |
| 21 | I2S DIN |
| 6 | Expander INT (active low, open-drain, pull-up on the carrier) |
| 44, 43 | Spare, not connected on this revision |

### Expander (8 I/O, 3V3 side of the I2C bus)
- Inputs: BTN_R, BTN_B. The 10k pull-up, 100 nF and 1k series RC stay.
- Outputs: LED_R, LED_B and BUZ gate drives (same BSS138 low-side drivers with
  1k + 10k), plus AMP_SD (through a 1k resistor), which drives the amplifier's shutdown pin so it stays
  off during boot and while silent.
- Two spare I/O.
- Its I2C address must not collide with the PN532 (0x24) or the LCD backpack (0x27/0x3F).

### Speaker path
- *(As built 2026-09-30: U3 is an NS4168, not a MAX98357A; CTRL high selects the **right** I2S slot and there is
  no gain pin. See `hardware/fab/PART_ALTERNATIVES.md`.)*
- MAX98357A-class I2S class-D amplifier, **powered from VBAT_SW (3.0–4.2 V)**, not the
  5 V boost. That gives about 1 W into 8 Ω, or 1.5–2 W into 4 Ω if a 4 Ω speaker is
  used, and keeps audio peaks off the 5 V rail
  (no LCD flicker). GAIN_SLOT is tied to GND (12 dB); volume is set digitally in firmware.
- The output is BTL: the new 2-pin XH connector `J_SPK` must never be tied to GND
  (silkscreen note).
- Off-board: Visaton K 50 (2901; the WP variant is out of stock) (8 Ω, 2 W, IP65) in the enclosure wall behind a grille
  with a front gasket (see `hardware/fab/OFFBOARD_PARTS.md`). About 1 W into 8 Ω from
  VBAT. `ORDERING.md` must list this same 8 Ω part.

### Power changes
- Polyfuse raised to 2 A hold (1206L200/16NR, C22374899), for LoRa TX + audio peaks + boost.
- Bulk capacitance moves from THT electrolytics to Basic 1206 ceramics: 2x 47 µF 10 V
  (C96123) on VBAT_SW and 100 µF 6.3 V (C15008) on +3V3.
- The boost (MT3608), inductor and fuse have no Basic/Preferred equivalent at JLCPCB
  (the whole libraries were searched). The MT3608 stays, because 5 V loads remain
  about 200 mA.

### Firmware impact
- An expander driver handles buttons (via INT), LEDs, the buzzer and AMP_SD. P6/P7
  must be set as outputs driven low (the TCA9534 has no internal pull-ups).
- An audio task streams clips over I2S DMA from flash (beeps, siren, spoken lines).
- `core` gets a `Sound` event next to `Beep`.

## Part 7: Build variants (Deluxe / Budget) (approved 2026-09-30)

### Why
The Deluxe unit costs ~700 zł in parts (see `hardware/fab/COSTS.md`). A cheaper tier
should share the board, pin map and firmware `core`, not fork them.

### Model
One PCB, one pin map. A variant is a set of modules; a module is a set of board parts
left unpopulated when absent (`MODULES`/`VARIANTS` in `hardware/design.py`).
`jlc.py` writes a BOM/CPL per variant (`fab/jlc_bom.csv` = deluxe, `fab/jlc_bom_budget.csv`).

| Module | On-board parts | Off-board |
|---|---|---|
| buttons | 2 BSS138 LED drivers, RC input filters, `J_BTN_R/B` | 2 IP67 buttons |
| rfid | `J_NFC1` | PN532, cards |
| speaker | `U3` NS4168, caps, `R_SD1`, `R_SDPD1`, `J_SPK1` | VISATON K 50 |
| GPS, enclosure, key/toggle | none | L76K, box, switch |

Core (always): Heltec V4, power path, expander `U2`, buzzer path, LCD. The expander stays in
every variant because the LEDs, buzzer and buttons sit behind it.

- **Deluxe:** buttons + rfid + speaker + GPS, Kradex IP67, key switch.
- **Budget:** buttons only, Pawbol S-BOX 416-P IP65 box (190 x 140 x 70 mm inside), generic 16 mm buttons, no GPS, KS22 key (or a toggle). Same board.
- Any mix is valid if it has **buttons or RFID** (`design.check()` enforces it).

### Firmware
- I2C probe at boot: PN532 at 0x24, the expander at 0x20, the LCD at 0x27/0x3F. A missing module
  disables its task instead of failing.
- `cargo` features only for what cannot be probed: speaker fitted, buttons fitted, GPS fitted.
- No buttons: set expander P0/P1 as outputs (no pull-ups fitted, floating inputs would toggle INT).
- No speaker: the I2S nets (GPIO 47/48/21) and `AMP_SD` (expander P5, `U2.10`) have nothing fitted on the board.
  Firmware must leave GPIO 47/48/21 as inputs or unused (never drive them) and must not start the audio task.
- STATUS omits position without GPS. The buzzer is present in every variant.

### Open
Red 6 V ONPOW button availability, key-switch choice (maintained vs momentary), buzzer code,
budget generic-part prices: tracked in `hardware/fab/COSTS.md`.

## Open items to verify during implementation

- Heltec V4 header fit (paper print; 22.86 mm row spacing measured on V3 STEP).
- Heltec charger current: 540 mA (CN3165, R13 2.2k, V4.2 schematic); about 0.08C for 2x3400 mAh, slow but safe. Check again for V4.3.
- hd44780-driver and pn532 embedded-hal 1.0 compatibility.
- PN532 read range through the actual lid.
- ZP240.190.105 internal dimensions and plate hole pattern (Kradex drawing).
- Button choice: IP67 anti-vandal buttons with 5V LED (R_LOAD values depend on it).
- Measure idle current; MT3608 efficiency at light load.

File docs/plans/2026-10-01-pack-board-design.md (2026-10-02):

# AirsoftCounter pack board: 4x18650 power subsystem

Date: 2026-10-01
Status: hardware done 2026-10-01 (pack.py generated, routed and fabbed; `make boards` green). Pack
firmware is designed here but its implementation is deferred. Lines marked "verified" were checked
against a source; everything else is listed under "Unverified" at the end. The generated board is
96 x 90 mm with the four holders (MYOUNG BH-18650-A6AJ012, THT) on the **bottom** side and every SMD
part on top (2026-10-01 rework; the first layout, 140 x 100 mm with Keystone 1042 holders on top,
placed parts under the holder floor). Re-check the holder against its drawing and the hole pattern
against the ZP240.190 plate before ordering.

This is **variant A** (pack MCU). Variant B, the same pack with no MCU and the Heltec as I2C master,
is `2026-10-02-pack-board-variant-b-design.md` (hardware generated from `hardware/pack_b.py`; not fabbed); both are kept.

## Simplification delta (2026-10-02)

The first quote was about $140 for 5 assembled boards, mostly Extended setup fees (15 types x ~$3) and
per-board chip cost. Changes, regenerated with `make BOARD=pack all` (ERC/DRC/gerbers green):

- **No protector IC.** The four XB8089D (and their 1k/100nF) are gone; holder- goes straight to GND.
  Each job it did is covered elsewhere: short circuit by the per-cell 5 A fuse and the output PTC;
  overcharge by the BQ25601 (CV 4.208 V plus its battery over-voltage cutoff at 104 % of VREG,
  103-105 %, verified 2026-10-02 in the datasheet's BATOVP table); over-discharge by the default-off switches (a dead or reset MCU leaves every cell
  open through `R_PD`) and the firmware UV limit; reversed cell by the crowbar and fuse, as before.
  Remaining gap: firmware that runs but keeps a switch closed below 2.5 V. The firmware must run the
  IWDG and host-test the UV disconnect in `asg-core`.
- **One shared protector was rejected.** With the switches open the pack rail is at 0 V, the protector
  stays off and cuts the cells' negative from GND, so the MCU (powered through the diode-OR) never boots
  to close a switch: a lock-out.
- **Diode-OR:** 3x BAT54C (Extended) -> 5x B5819W SOD-123 (C8598, Basic), one per cell (`D_OR1-4`, in
  each cell's band) and one for SYS (`D_OR5`).
- **TS bias:** 5.23k/30.9k (Extended) -> 5.1k/30k (C27834/C17621, Basic). With the 10k B3435 NTC the
  thresholds move from 0/60 C to 0.5/60.8 C.
- **Sense taps** `R_SNSF*`/`R_SNSS*`: 0R -> 10R (C17415, Basic). Holder- is now solid GND, so a reversed
  cell's crowbar holds `CELL_F` at about -0.5 to -1 V until the fuse clears (ms), below the monitor's
  -0.3 V input limit; 10 Ohm limits the clamp current (PAC1934: +-100 mA per pin).
- **Monitor: 2x INA3221 -> 1x PAC1934T-I/JQ** (C623960, UQFN-16 4x4, Extended, 583 in stock), four
  channels in one chip, `Sensor_Energy:PAC1934x-xJQ`. Cell n on channel n; ADDRSEL to GND = 0x10;
  SLOW/ALERT -> MCU pin 28 (`R_ALERT` pull-up), PWRDN -> MCU pin 29 (`R_PWRDN` pull-up, so it runs
  without firmware). On-chip power accumulators do the coulomb counting. Facts under Datasheet facts.
- **Shunt 20 -> 10 mOhm** (FMF06FTHR010-LH, C105362, 1 W, 1 %): the PAC1934's differential limit is
  500 mV (INA3221: 26 V). Without the protector a hard short drives about 25 A per cell until the fuse
  clears; 10 mOhm keeps that at 0.25 V and gives a +-10 A full scale.
- **Result:** 11 SMD Extended types instead of 15, 104 placements instead of 115, 13 parts fewer per
  board. Assemble 2 of the 5 boards at JLC to cut the per-board chip cost further.
- Not changed: per-cell switching (any 1-4 cell combination), per-cell current/voltage/temperature,
  the MCU, charger, boost and connectors. The INA3221 and XB8089D datasheet notes further down are
  kept for the record; this section overrides them.

## Goal

Move all battery and power management off the carrier (`2026-09-28-esp32-lora-carrier-design.md`)
onto a separate **pack board** that holds four 18650 cells and manages each cell:

- **Runtime:** 4 x 3.35 Ah (Samsung INR18650-35E) = about 13.4 Ah, about double the current 2 cells.
  With `power_budget.py` (2026-10-01, still with the 100 mA backlight estimate): 33 h deluxe game with
  the backlight on and 60 h with it off at 20 C; 78 days parked with the key left on; 109 uA and so
  about 12 years for the pack's own electronics with the key off (cell self-discharge dominates after
  a season). The ~150 mOhm branch drop is not modelled: below 0.3 V at these currents, inside the
  0.84 usable-capacity derate.
- **Per-cell management:** short/overcurrent, over/under-voltage, temperature and current
  monitoring, and disabling a failing cell, so shorts, imbalance and ageing are caught.
- **Own USB-C charging** (about 2 A), so the Heltec USB-C becomes programming-only.
- **Key-off charging**: charger and pack sit upstream of the key switch.
- **Frees the carrier**, which is full.

## Topology

**1S4P** (all four cells in parallel, 3.0-4.2 V). Chosen because the load is under 1 W, the
runtime goal is capacity not voltage, and parallel cells cannot drift apart in voltage, so no
balancing is needed. Series stacks were rejected: they need a boost-capable charger, multi-cell
protection and balancing, and the 5.1 V boost already works from one cell.

Parallel-specific risks (not imbalance): inrush when joining unequal cells, a failing cell fed
by the healthy ones, and ageing mismatch (shows as slightly less runtime).

## Block diagram

```
USB-C (5.1k CC; D+/D- to the MCU for DFU)
  └─ BQ25601 charger (I2C to pack MCU, TS <- board NTC, ~2 A)
       ├─ BAT ── pack rail (1S4P, per-cell chain below)
       └─ SYS ─┬─ LDO 3.3 V (low Iq) ── STM32C071, PAC1934             [always on]
               └─ J_KEY (off-board) ─ F1 ─ VBAT_SW ─┬─ MT3608 boost ─ +5V ─┐
                                                    └──────────────────────┼─ 6-pin XH to carrier
                                                                           │  GND,GND,VBAT_SW,+5V,SDA,SCL
carrier: VBAT_SW -> J_HBAT1 -> Heltec battery socket;  VBAT_SW -> amp;  +5V -> LCD, LEDs, buzzer
```

## Pack board blocks

1. **USB-C input**, 5 V, 5.1k CC pull-downs (3 A bricks advertise 3 A to them). D+/D- go to the MCU.
2. **Charger: BQ25601RTWR** (C468236, 5877 in stock on 2026-10-01). Switching (little heat beside the
   cells), NVDC power path, I2C, /CE, /INT, TS input. Its power-on defaults (about 2 A, 4.208 V) charge
   correctly with a dead or unflashed MCU; its I2C watchdog restores them if the MCU hangs. A fifth NTC on
   TS gives the charger its own temperature limits without the MCU.
3. **Four cell holders**, MYOUNG BH-18650-A6AJ012 (LCSC C19184084), THT on the bottom side, hand-soldered.
   Polarity on the bottom silkscreen.
4. **Per-cell chain (x4)**, see below.
5. **MCU: STM32C071KBT6** (C42116633, LQFP-32, 600 in stock), see below.
6. **Boost and rails moved from the carrier:** MT3608 with L1, D1, R_FB1/2, C_IN1, C_OUT1/2, the
   2 A PTC F1 at the start of `VBAT_SW`, and the key-switch connector.

### Per-cell chain

```
holder+ ─ fuse ─┬─ shunt 10 mOhm ─┬─ back-to-back P-FET (2x AO3401A) ─ pack rail
                │                 │    gates: 1M to source (4 uA when on), pulled low by an N-FET <- MCU GPIO
                │                 └─ PAC1934 SENSE-; SENSE+ (= VBUS) on the fuse side reads this cell, also when off
                ├─ crowbar Schottky to holder- (a reversed cell blows the fuse)
                └─ B5819W diode-OR -> LDO -> MCU
holder- ─ GND (no protector IC since 2026-10-02)       bead NTC on each cell -> MCU ADC
```

- **Switch on the positive side, shunt on the cell side of it.** The PAC1934 measures bus voltage at SENSE+;
  with the shunt between cell and switch each channel reads its own cell even while it is disconnected,
  which the connect check needs. (The earlier FS8205-in-the-negative-lead idea read only the pack rail.)
- **Switch defaults to OFF.** A dead MCU leaves an open pack, which is also the over-discharge protection.
  Each switch has a **DNP 0 Ohm bypass** footprint for bring-up without firmware.
- **MCU power does not depend on the switches:** the four cell+ nodes and SYS are diode-ORed (5x B5819W) into the
  LDO, so the MCU runs from the highest cell at uA load even with every switch open, and from USB with no cells (DFU).
- **Shunt 10 mOhm:** 0.6 mV (200 LSB at 3 uV, bidirectional mode) for 60 mA per cell, +-10 A full scale
  (one cell carrying all load plus charge). The PAC1934 cancels its offset in the averaged result.
- **Fuse 5 A fast-blow:** above the per-cell working current (about 2 A); with no protector IC it is the
  hardware short-circuit protection. It must clear the crowbar current before the Schottky fails (see the
  fuse ruling under Datasheet facts).
- Series resistance per branch (fuse, shunt, two FETs) is about 130 mOhm, larger than the cell IR
  (about 35 mOhm) and matched between branches, so it helps current sharing.
- AO3401A and B5819W are JLC Basic. FS8205A is no longer used.

### MCU

| Function | Pins / parts |
|---|---|
| USB DFU | PA11/PA12 <- USB-C D-/D+ (crystal-less USB, ROM DFU, flashed with `dfu-util`) |
| Internal I2C (master) | PAC1934 (0x10), BQ25601 (0x6B); pull-ups to pack 3.3 V |
| External I2C (slave 0x30) | to the 6-pin XH; no pull-ups on the pack (the carrier's 3V3 ones are used) |
| GPIO out | 4x switch drive, BQ25601 /CE, one status LED |
| GPIO in / EXTI | BQ25601 /INT, PAC1934 SLOW/ALERT (pin 28) |
| GPIO out (monitor) | PAC1934 PWRDN (pin 29), pulled up |
| ADC | 4x cell NTC (divider fed from a GPIO, off between samples) |
| BOOT0 (PA14, shared with SWCLK), NRST (PF2) | BOOT0 button to 3V3 and a reset button: the MCU runs from the cells, so replugging USB does not reset it. A blank chip boots DFU by itself; later firmware can jump to DFU on command |
| SWD | 3 test pads |

Two I2C buses keep the Heltec the only master on the carrier bus. The slave pins are open-drain and the
pull-ups are on the carrier, so the pack cannot back-power the carrier through SDA/SCL with the key off.

## Pack firmware (designed, implementation deferred)

- Crate `firmware/pack` (embassy-stm32). The pure logic goes in an `asg-core` `pack` module (no_std,
  host-tested): connection sequence, disable policy, coulomb counting, and the register map, so the
  Heltec and the pack MCU share one definition.
- Loop: wake every few seconds (key off) or every second (load or charging), PAC1934 REFRESH then
  SLEEP (5 uA; PWRDN loses the configuration), apply policy, kick the BQ25601 watchdog, Stop mode. The
  PAC1934 ALERT wakes it early. Set the channels bidirectional (NEG_PWR register): charge current is negative.
- **Connection sequence:** read all four cells, close the median one, then every cell within about 50 mV
  of the rail. Others stay open and are flagged; no on-board equalising, rebalance such a cell externally.
- **Disable policy:** a cell is disconnected and flagged when, for longer than a debounce time, its current
  differs strongly from the mean of the others, its temperature rises well above the others or crosses an
  absolute limit, it carries near-zero current while the others carry load, or its voltage leaves the safe
  window. Thresholds are compile-time constants, set with real cells.
- Per-cell currents give real charge termination even with the key on (the charger only sees the sum).

Register map (little-endian, one burst read):

| Reg | Content |
|---|---|
| 0x00 | version |
| 0x01 | flags: per cell connected / disabled and reason (OV, UV, temp, mismatch, no-current, never connected) |
| 0x02.. | cell mV x4, cell mA x4 (signed), cell degC x4, pack SOC %, charger state |
| 0x40 | command: reconnect cell n, enter DFU |

## Heltec power feed (verified)

Source: `HTIT-WB32LAF_V4.3.pdf` from resource.heltec.cn, read 2026-10-01.

- The header "5V" pin (JP4 pin 2) is **`VUSB`**, wired directly to USB-C VBUS ahead of F1, with no diode.
  Feeding it would put pack power on the VBUS of any attached cable (back-feeding an unpowered host).
  **Do not use it.**
- The battery socket (JP2) is `VBAT`; Q1 (AO3401A) connects VBAT to the system rail when `VDD_5V` is absent,
  and D2 (LMBR340) diode-ORs USB in. Feeding JP2 from `VBAT_SW` is the configuration the board is designed for.
- **Decision:** the Heltec keeps its feed through `J_HBAT1` from `VBAT_SW`. While the Heltec USB is plugged
  in, its CN3165 (540 mA, `I=1188/R13`) charges the pack in parallel with the BQ25601; harmless (both CC/CV
  to 4.2 V, BQ25601 OVP and the MCU switches in the path). With the key off it feeds only `VBAT_SW` loads, as today.

## Carrier changes

Remove: `J_BAT1`, `J_KEY1`, `F1`, `U4`, `R_PROT1`, `C_PROT1`, the boost (`U1`, `L1`, `D1`, `R_FB1/2`,
`C_IN1`, `C_OUT1/2`). Merge `BAT_N` into `GND`.

Keep: `J_HBAT1` on `VBAT_SW` (Heltec feed, above) and `C_BULK1/2` on `VBAT_SW` beside the amp, whose 1.5 A
peaks now arrive through a cable and the key switch. The Heltec 5V pin stays unconnected.

Add one **6-pin XH** `J_PWR1`:

| Pin | Signal |
|---|---|
| 1-2 | GND |
| 3 | `VBAT_SW` (amp, Heltec battery socket) |
| 4 | `+5V` (LCD, LEDs, buzzer) |
| 5-6 | SDA, SCL (carrier 3V3 bus) |

Addresses on the carrier bus: 0x20 (expander), 0x24 (PN532), 0x27/0x3F (LCD backpack), 0x30 (pack MCU).
A 6-pin XH is a new Extended part (setup fee per order; see `ORDERING.md`). `power_budget.py` needs 4 cells,
the pack quiescent current and the branch series drop.

## Mechanical and assembly

- Board 96 x 90 mm: four holders (77 x 20.7 mm bodies, 21.66 mm pitch) on the bottom, all SMD parts on
  top above them; check the ZP240.190-PCB plate and enclosure (cells hang under the board).
- Holders and the four cell bead NTCs are hand-soldered THT on the bottom; all SMD parts stay on the top
  side for JLCPCB single-side assembly.
- Spring-contact holders can open momentarily under shock (airsoft use): choose holders with positive
  retention and add a strap or lid. Four parallel cells ride through a brief dropout of one.
- Keep the charger, boost and inductor away from the cells; NTCs must touch the cells.
- Unprotected cells: mark polarity and keep exposed contacts covered.

## Verification and bring-up

1. Generator checks: `check_netlist.py` / `check_gerbers.py` for the pack board, plus an assertion that
   every cell branch is fuse -> shunt -> switch -> rail in that order.
2. Bench, with a current-limited PSU in place of cells:
   - USB DFU enumerates (`dfu-util -l`).
   - With bypasses fitted: rail, LDO and charger come up; key-off quiescent current (target tens of uA).
   - BQ25601 stops at 4.208 V and its battery OVP trips with the PSU above it; firmware opens a cell
     at its UV limit; a short through the PSU limit is seen by the PAC1934 alert.
   - Reversed "cell": PSU at low current limit confirms the crowbar path; then one sacrificial cell with the
     real fuse.
   - Once firmware exists: switches close in order, a cell 200 mV off stays open; 2 A charge of four
     matched cells with per-cell current log (sharing, termination with key on).
3. Carrier: `make all` green after the removals; the Heltec boots from `J_HBAT1` fed by the pack.

## Risks

- **No protector IC (2026-10-02).** Over-discharge protection is firmware plus the default-off switches;
  a running MCU with wrong firmware can over-discharge a cell. Mitigated by the IWDG, a host-tested UV
  disconnect and the Heltec's own brown-out cutting the load with the key on.
- **Reversed cell.** Crowbar Schottky plus fuse; the fuse and Schottky I2t are unverified.
- **Ageing mismatch:** use matched cells from one batch and check capacity before building a pack.
- **No MCU, no power:** a firmware fault leaves the pack open until watchdog reset; bypass footprints exist
  for bring-up only.

## Repo effort

The hardware flow is generator-based (`design.py` -> `gen_sch.py`/`gen_pcb.py` -> KiCad -> `fab/`). A second
board means a second design definition and a second set of fab outputs, plus removing the parts listed
above from the carrier (and regenerating its BOM/CPL and `power_budget.py`).

## Parts (settled 2026-10-01, from datasheets and live JLCPCB stock)

Every LCSC number below was queried live against the JLCPCB parts API on 2026-10-01;
library type (B = Basic, P = Preferred Extended, E = Extended), maker and stock are recorded.

### Chosen parts

| Item | Decision | LCSC | Type | Stock | Source |
|---|---|---|---|---|---|
| MCU | STM32C071KBT6, LQFP-32, `MCU_ST_STM32C0:STM32C071KBTx` | C42116633 | E | 600 | JLCPCB API |
| Charger | BQ25601RTWR, QFN-24, `Battery_Management:BQ25601` | C468236 | E | 5877 | JLCPCB API |
| Current monitor | PAC1934T-I/JQ, UQFN-16 4x4, `Sensor_Energy:PAC1934x-xJQ` (was 2x INA3221 C181255) | C623960 | E | 583 | JLCPCB API 2026-10-02 |
| Cell protector | none since 2026-10-02 (was XB8089D C79928, see the simplification delta) | | | | |
| LDO | XC6206P332MR, SOT-23-3, `Regulator_Linear:XC6206PxxxMR` | C5446 | B | 474563 | JLCPCB API |
| P-FET (x8) | AO3401A, SOT-23, `Transistor_FET:AO3401A` | C15127 | B | 782223 | JLCPCB API |
| N-FET | BSS138, SOT-23, `Transistor_FET:BSS138` | C7420339 | P | (carrier part) | `design.py` |
| Diode-OR (x5) | B5819W (SL), SOD-123, `Device:D_Schottky` (was BAT54C C37704) | C8598 | B | 512045 | JLCPCB API 2026-10-02 |
| Crowbar + boost diode | SS34, SMA, `Diode:SS34` | C8678 | B | 4440087 | JLCPCB API |
| Charger inductor | Murata DFE322512F-1R5M, 1210, 1.5 uH, Irms 3.0 A, Isat 3.9 A, DCR 48 mOhm | C703084 | E | 4596 | Murata dynamic-model list + JLCPCB API |
| Boost IC / L / caps | MT3608 + 10 uH 2 A + 22 uF 25 V, copied from the carrier | C84817 / C2046332 / C12891 | E / E / B | | `design.py` |
| Branch fuse | Bourns SF-1206F500-2, 1206, 5 A fast, I2t 0.966 A2s | C48332 | E | 9975 | Bourns SF-1206F datasheet + JLCPCB API |
| Shunt | FOJAN FMF06FTHR010-LH, 1206, 10 mOhm 1% 1 W (was RLS12FTCR020 20 mOhm C163047) | C105362 | E | 244330 | JLCPCB API 2026-10-02 |
| NTC (charger TS) | Nanjing Shiheng CMFB 103F3435, 0805, 10k B3435 1% | C2889056 | E | 15625 | JLCPCB API |
| Tact switch (BOOT0, NRST) | XUNPU TS-1088-AR02016, SMD 4x3 mm, 2-pad, `Button_Switch_SMD:SW_SPST_TS-1088-xR020` | C720477 | B | 787409 | JLCPCB API |
| LED red (STAT) | NCD0805R1, 0805 | C84256 | B | 4820981 | JLCPCB API |
| LED green (MCU status) | KT-0805G, 0805 | C2297 | B | 3140725 | JLCPCB API |
| USB-C receptacle | HCTL HC-TYPE-C-16P-01A, `Connector_USB:USB_C_Receptacle_HCTL_HC-TYPE-C-16P-01A` | C2894897 | E | 43482 | JLCPCB API |
| USB-C symbol | `Connector:USB_C_Receptacle_USB2.0_14P` | | | | KiCad 9.0.8 |
| 6-pin XH | JST B6B-XH-A(LF)(SN), `Connector_JST:JST_XH_B6B-XH-A_1x06_P2.50mm_Vertical` | C144397 | E | 43646 | JLCPCB API |
| 18650 holder | MYOUNG BH-18650-A6AJ012, `local:BatteryHolder_MYOUNG_BH-18650-A6AJ012` (from drawing MY-CP-0373), bottom side, hand-soldered | C19184084 (off-board) | E | 3748 | JLCPCB API + MYOUNG drawing |
| Cell NTC (x4) | MF52A103F3435 bead, `local:NTC_Bead_P2.54mm`, bottom side, hand-soldered | C84036 (off-board) | E | 32878 | JLCPCB API |
| 4-pin XH | JST B4B-XH-A(LF)(SN), carrier part | C144395 | E | | `design.py` |

Pack-only passives (Basic where noted, all live-checked 2026-10-01): 1M 0805 C17514, 100k 0805 C149504,
5.1k 0805 C27834 (also CC1/CC2), 10 uF 0805 C15850, 4.7 uF 0805 C1779, 1 uF 0805 C28323,
47 nF 0805 C53134. TS bias resistors were the datasheet values 5.23 kOhm C17739 and 30.9 kOhm
C204398 (both Extended; kept exact because they set the JEITA window). The 5.2 mm-pitch TS-1187A
was dropped for the 2-pad TS-1088 so the symbol (`Switch:SW_Push`) pairs with a 2-pad footprint
without unconnected pads.

The `BAT54C` guess in the plan ("C47546 or similar") is wrong: C47546 is a BAT54**S** (series), not
common-cathode. Use C37704. There is no Basic BAT54C at JLC; it is Extended.

### Datasheet facts

**STM32C071KBT6** (DS14693 Rev 2, 2025-04; RM0490 Rev 5; both read 2026-10-01)

- LQFP-32 pin numbers (KiCad symbol cross-checked against DS14693 Table 12 and Figure 6):
  VDD 4, VSS 5, PF2-NRST 6, PA0-PA3 7-10, PA4 11, PA5 12, PA6 13, PA7 14, PB0 15, PB1 16, PB2 17,
  PA8 18, PA9 19, PC6 20, PA10 21, PA11 22, PA12 23, PA13 24, PA14-BOOT0 25, PA15 26, PB3 27,
  PB4 28, PB5 29, PB6 30, PB7 31, PB8 32. Unused/NC: PB8, PB9, PC14, PC15, PA9, PA10, PC6.
- USB FS device on PA11/PA12 is **crystal-less** (DS14693 section 3.20: "USB 2.0 FS device
  (crystal-less)"); the HSI48 oscillator plus CRS (SOF-based clock recovery) covers USB clock
  accuracy (DS14693 sections 3.16.2/3.20). No crystal parts.
- **Internal DP pull-up exists**: USB electrical table 67 gives `R_PU` on PA12 (USB_DP) 0.9-1.575 kOhm
  (typ 1.25 k). No external 1.5 k.
- ROM bootloader over USB on PA11/PA12 (DS14693 section 3.5). Boot selection (RM0490 Table 9 and
  FLASH_OPTR, 0x1FFF7800): the factory **option bytes are nBOOT_SEL = 1, NBOOT0 = 1, NBOOT1 = 1**,
  i.e. the **PA14-BOOT0 pin is ignored by default** and the NBOOT0 option bit selects main flash.
  Because a blank chip has the FLASH EMPTY flag set, first power-up is forced to system memory (USB
  DFU). Consequence: the BOOT0 button only does anything after an option-byte change that sets
  nBOOT_SEL = 0 (legacy BOOT0 pin) or NBOOT0 = 0; the board still works unflashed. Keep the button
  as a convenience for later firmware, not as the DFU entry path.
- NRST: factory `NRST_MODE = 11` (bidirectional reset, legacy NRST pin), so PF2-NRST works as an
  input with the 100 nF + reset button. It has an embedded weak pull-up (DS14693 pin table).
- Stop-mode current (DS14693 Table 32, 3 V, 25 C): typ **85.5 uA** all clocks off, 86.0 uA with
  RTC + LSE bypass; Standby typ 7.2 uA (Table 33); Shutdown lower (Table 34). A "tens of uA"
  pack quiescent target is **not** reachable with the MCU in Stop mode: budget about 85 uA for the MCU.

**BQ25601** (SLUSCK5A, March 2017, revised March 2023; read 2026-10-01)

- Application circuit (section 10.2, Figure 10-1): SW-BTST bootstrap 0.047 uF, PMID 10 uF ceramic to
  GND (pin table), SYS 10 uF, BAT 10 uF, REGN 4.7 uF / 10 V; inductor 1.5 MHz switcher,
  `ISAT >= ICHG + IRIPPLE/2` (eq. 3), ripple 20-40 % of ICHG (section 10.2.2.1). Chosen 1.5 uH / 3.9 A.
- Charging defaults with no host (Table 9-2): **ICHG 2.048 A, VREG 4.208 V**, precharge/termination
  180 mA, JEITA profile, 10 h safety timer. The I2C watchdog restores these defaults if the MCU hangs.
- PSEL (pin 2): **high = 500 mA, low = 2.4 A** input current limit in default mode (pin table, Table 9-1).
  Tie PSEL to GND for the ~2 A charge target.
- TS (pin 11, section 9.3.7.4 and Figure 9-5): resistor network from REGN to TS to GND in parallel with
  the thermistor. TI's worked 0-60 C example for a 103AT gives **RT1 = 5.23 kOhm (REGN-TS) and
  RT2 = 30.9 kOhm (TS-GND)** with the 10k B3435 NTC. Use those values (TH_CHG). Check at 25 C:
  RT2||NTC = 30.9k||10k = 7.56k, VTS/VREGN = 59 % inside the VT1/VT5 window.
- STAT (pin 4): open-drain, **6 mA sink** (Table: STAT output sink current), 10k + LED to a logic rail
  (pin table), LOW = charging, HIGH = done/disabled, blinking = fault (section 9.3.7).
- /CE (pin 9): LOW = charging enabled. Pull down 10k so charging runs with the MCU unpowered.
- /INT (pin 7): open-drain, 10k pull-up.
- /PG (pin 3): open-drain power-good. Not used: leave unconnected.
- /QON (pin 12): has an **internal 200 kOhm pull-up** (section 9.4.4.4), so it is safe to leave
  unconnected; not used.
- VAC is pin 1, VBUS is pin 24 (separate pins on the symbol): tie both to USB VBUS.

**PAC1934** (Microchip DS20005850E; read 2026-10-02)

- Pins (table 3-1, UQFN-16): SLOW/ALERT 1, VDD 2, GND 3, SM_CLK 4, SM_DATA 5, ADDRSEL 6, SENSE3- 7,
  SENSE3+ 8, SENSE4- 9, SENSE4+ 10, SENSE1+ 11, SENSE1- 12, SENSE2+ 13, SENSE2- 14, VDD I/O 15,
  PWRDN 16, EP 17 (not connected inside, "recommended" to GND). Matches `Sensor_Energy:PAC1934x-xJQ`.
- VDD 2.7-5.5 V, VDD I/O 1.62-5.5 V, 100 nF on each. Active 585 uA at 1024 samples/s, 16 uA at 8/s,
  SLEEP 5 uA, PWRDN 0.1 uA, but PWRDN keeps no configuration or data (section 4.1.6).
- Address (table 5-1): ADDRSEL resistor to GND, 0 Ohm = 0x10 ... tie to VDD = 0x1F.
- VBUS is measured at **SENSE+** (section 4); SENSE+ goes on the supply side of the shunt.
- Limits: SENSE pins -0.3 to 40 V absolute, common mode -0.2 to 32 V; **|SENSE+ - SENSE-| 500 mV
  absolute**; +-100 mA into any pin; back-to-back ESD diodes between SENSE+/- with 1 kOhm in series.
- VSENSE +-100 mV full scale; bidirectional per channel (NEG_PWR, 1Dh), default unipolar.
- SLOW/ALERT: input at power-up (high forces 8 samples/s); can be reprogrammed as open-drain ALERT.

**INA3221** (SBOS576C, revised September 2026; read 2026-10-01; replaced by the PAC1934 on 2026-10-02)

- A0 straps (Table 7-1): **GND = 0x40, VS = 0x41, SDA = 0x42, SCL = 0x43**. So U_INA1 A0 = GND (0x40),
  U_INA2 A0 = +3V3 (0x41).
- Pin numbers (Table 5-1): IN+1 12, IN-1 11, IN+2 15, IN-2 14, IN+3 2, IN-3 1; VS 4, GND 3, VPU 16,
  PV 10, Critical 9, Warning 8, TC 13, SDA 7, SCL 6, A0 5. Matches `Power_Management:INA3221`.
- **VPU (pin 16)** is the power-valid pull-up rail; the typical application connects it to the supply
  rail. Tie VPU to +3V3 (same as VS) with the 100 nF bypass (section 9.3: 0.1 uF close to VS/GND).
- Unused channels (section 7.4.2): connect the unused-channel **IN- externally to a used channel** and
  **float IN+**, or leave the channel unmonitored. For U_INA2 only ch1 is used, so short IN+2/IN-2 and
  IN+3/IN-3 together onto the ch1 IN- net (cell-4 sense); differential 0 V, common mode within range.
- Absolute maximum (section 6.1): differential (IN+)-(IN-) +/-26 V; **common-mode (IN+ + IN-)/2
  -0.3 V to 26 V**. The -0.3 V floor is the crowbar-event limit called out in the design.
- Input filter (section 7.4.3, Figure 7-8): **series R <= 10 Ohm** per input plus 0.1-1 uF to GND.
  **Not fitted** (ruling in `docs/HANDOVER-2026-10-01-pack-board-P0-P2.md`): the datasheet makes the
  filter conditional on noise above 1 MHz and the INA's averaging covers it. The sense taps
  (`R_SNSF*`/`R_SNSS*`, 0805) were 0R; since 2026-10-02 they are 10 Ohm, because without the protector
  holder- is solid GND and a reversed cell's crowbar pulls the INA inputs below -0.3 V until the fuse
  clears (simplification delta). No filter caps are fitted.

**XB8089D** (XySemi datasheet Apr 2022; read 2026-10-01)

- Protection thresholds: overcharge 4.25 V typ (4.2-4.3), overcharge release 4.10 V,
  overdischarge 2.5 V typ, overdischarge release 3.0 V. FET R_SS(ON) 20 mOhm typ.
- Overcurrent (section "Detection Current" / "Detection Delay Time"): **Overdischarge Current 1
  typ 10 A, delay 10 ms; Overdischarge Current 2 typ 15 A, delay 0.4 ms; Load Short-Circuit typ
  40 A, delay 75 us.** Current consumption in normal operation 6-12 uA.
- Recovery: overdischarge is released by charging (VDR) or by removing the load; overcurrent/
  short-circuit release when the load is removed (VM pin returns to GND). No latch, no host reset.
- **Fuse ruling.** The plan/design text said "5 A fast-blow, above the XB8089D overcurrent trip".
  The datasheet trip is 10 A, so a 5 A fuse is *below* it. The correct rule, and what the board uses:
  the fuse sits **above the maximum per-cell current** (about 2 A) and **below the crowbar fault
  current**, so it is the slow backup to the protector rather than a nuisance blow. Crowbar check:
  Bourns SF-1206F500-2 melting I2t = 0.966 A2s; at 20-30 A it clears in 0.966/400 .. 0.966/900 =
  **1.1-2.4 ms**. SS34 non-repetitive surge is **100 A for 8.3 ms** (Vishay/onsemi SS32-SS39), i.e.
  I2t about 41 A2s, so the diode sees under 3 A2s during clearing. The XB8089D short-circuit trip
  (40 A, 75 us) normally acts first; the fuse covers a sustained 10-15 A that the protector times out
  on and a failed protector during a reversed cell.

**XC6206P332MR** (Torex XC6206 series datasheet; read 2026-10-01): Iq **1.0 uA typ (3.0 uA max)**,
VIN 1.8-6.0 V, IOUT 200 mA (500 mA current limit). Confirmed C5446 is the -G SOT-23-3 Basic part.

**AO3401A** (AOS datasheet; read 2026-10-01): RDS(ON) **<= 85 mOhm at VGS = -2.5 V (typ 60 mOhm)**,
<= 60 mOhm at -4.5 V, ID -4.0 A. Back-to-back at a 3.0 V cell is about 120-130 mOhm per branch.

**Gate resistor:** 1 MOhm per cell (4 uA at 4.2 V, 16 uA for four) as already in the per-cell diagram.

### Footprints

All named footprints/symbols exist in KiCad 9.0.8: `Connector_USB:USB_C_Receptacle_HCTL_HC-TYPE-C-16P-01A`,
`Connector_JST:JST_XH_B6B-XH-A_1x06_P2.50mm_Vertical`,
`Battery:BatteryHolder_Keystone_1042_1x18650`,
`Package_DFN_QFN:QFN-24-1EP_4x4mm_P0.5mm_EP2.6x2.6mm` (BQ25601),
`Package_DFN_QFN:Texas_RGV0016A_VQFN-16-1EP_4x4mm_P0.65mm_EP2.1x2.1mm` (INA3221 RGV, no longer used),
`Package_DFN_QFN:UQFN-16-1EP_4x4mm_P0.65mm_EP2.6x2.6mm` (PAC1934, since 2026-10-02).

**18650 holder:** MYOUNG BH-18650-A6AJ012 (drawing MY-CP-0373, 2023-09-01): body 77 x 20.7 x
14.9 mm, flat SUS304 contacts (0.35 mm), THT tabs in plated slots 1.3 x 2.6 mm at 71.45 mm pitch, snap
pegs d3.3 at (+27.6, -8) / (-27.6, +8) and d2.4 at (+35.8, +8) mm (top view, + on the right). The bottom
view shows a floor window about 67 x 8 mm (scaled from the drawing, not dimensioned) that the bead NTC
uses. The Keystone 1042 used first is only 14.86 mm tall around an 18.3 mm cell, so its floor lies on
the board: the SMD parts placed under it in the first layout could not have fitted.

## Unverified (check before building)

Closed on 2026-10-01 by the datasheet and stock check above: XB8089D trip/release, fuse and Schottky
I2t, STM32C071 USB DFU / crystal-less USB / Stop current, BQ25601 defaults and TS network, AO3401A
RDS(on) at low gate voltage, holder and 6-pin XH LCSC/stock.

Still open, and only answerable with real hardware or the pack firmware:

- Long-term reliability of protected cells in parallel and the crowbar protection once a real fuse
  and a sacrificial cell are used (bench item).
- Pack quiescent current as built: the model puts the MCU Stop contribution at about 85 uA, so the
  "tens of uA" target is revised upward and measured on the bench (P6.1).
- Total LDO + monitor quiescent current as built.
- 18650 capacity (3350 mAh is the datasheet minimum used by `power_budget.py`) for the actual cells.
- embassy-stm32 support level for STM32C071 USB and Stop mode (firmware, deferred).
- ZP240.190 plate and enclosure hole pattern (M3 corners of the 96 x 90 mm board are provisional).
- BH-18650-A6AJ012 on the 1:1 print: tab slots, pegs, and the floor window (size and position are
  scaled from the drawing) leaving room for the bead NTC to reach the cell.

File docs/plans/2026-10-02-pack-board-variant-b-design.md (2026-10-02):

# AirsoftCounter pack board, variant B: no pack MCU (Heltec is the master)

Date: 2026-10-02
Status: hardware generated (`hardware/pack_b.py`, `make BOARD=pack_b all` into `fab/pack_b/`); the
Heltec firmware still to come. Variant A (pack MCU, STM32C071) is
`2026-10-01-pack-board-design.md` and stays the built and fabbed design; this doc only lists what
variant B changes. Both are kept so they can be compared and either one ordered. Facts marked
"verified" were read from the datasheet named next to them on 2026-10-02.

## Goal

Same pack functions as variant A (1S4P, per-cell switch in any 1-4 combination, per-cell voltage,
current and temperature, own USB-C charging, key-off charging), with no microcontroller and no
firmware on the pack. The Heltec reads and drives the pack over the I2C pair already on `J_PWR1`.

Why: one firmware instead of two, no DFU/USB data path, no option-byte and boot-pin handling, and
the pack's key-off drain drops from about 112 uA to about 30 uA (the STM32C071 Stop current, 85 uA,
was most of it).

## What changes against variant A

| Block | Variant A | Variant B |
|---|---|---|
| Brain | STM32C071 on the pack, I2C slave 0x30 to the Heltec | Heltec (`asg-device`), I2C master of the pack chips |
| Switch drive | 4 MCU GPIOs | **TCA9534** I/O expander (C783615, the carrier's part), address **0x21** |
| Switch default | OFF (`R_PD` 100k pulls the BSS138 gate low) | **ON** (1M pull-up to +3V3 on each BSS138 gate) |
| Cell NTCs | MCU ADC, divider fed by a GPIO | **ADS1115** (C37593), 4 single-ended channels, address **0x48**; divider fed by an expander pin |
| PAC1934 | always on, MCU puts it to sleep | **PWRDN held high only with the key on** (divider from `VBAT_SW`) |
| Charger /CE, /INT, PAC ALERT | MCU pins | expander pins, polled by the Heltec |
| Internal I2C bus + 4k7 pull-ups | yes | no: the pack chips sit on the carrier bus (pull-ups on the carrier) |
| USB-C | data to the MCU (DFU) | CC resistors only; D+/D- unconnected |
| Removed | | STM32C071, C_MCU1/2, C_NRST, R_BOOT, SW_BOOT, SW_RST, LED_MCU + R, 4 test pads, R_SCL_INT, R_SDA_INT, R_PWRDN (its +3V3 pull-up; the VBAT_SW divider replaces it) |

Unchanged: the cell branches (fuse, 10 mOhm shunt, back-to-back AO3401A, crowbar, 10R sense taps),
the B5819W diode-OR into the XC6206 LDO, the BQ25601 with its own board NTC on TS, the boost, the key
connector, the 6-pin XH and the carrier. **The carrier needs no change**: `J_PWR1` pins 5/6 simply
reach three pack chips instead of the pack MCU.

### Expander pin map (TCA9534, 0x21)

| Pin | Use | Direction / default |
|---|---|---|
| P0-P3 | SW1-SW4 BSS138 gate (cell switch) | output; at power-up an input (high-Z, *no internal pull-ups*, verified TCA9534 pin table), so the 1M pull-up turns the cell **on**. Write 0 to open a cell |
| P4 | NTC divider supply (4x 10k NTC + 10k) | output high only while sampling (4 x 165 uA otherwise) |
| P5 | BQ25601 /CE | output; at power-up high-Z, `R_CE` 10k pull-down keeps charging enabled |
| P6 | BQ25601 /INT | input, 10k pull-up |
| P7 | PAC1934 SLOW/ALERT | input, 10k pull-up (SLOW high = 8 samples/s until reprogrammed as ALERT) |

TCA9534 standby 0.9 uA typ at 3.6 V (verified). It runs from the always-on +3V3 (diode-OR -> LDO), so
it keeps the chosen cell set while the Heltec is off, through key-off and Heltec reboots; it only
returns to "all on" after the pack loses power completely. One hazard follows: if the policy
opens every cell, the Heltec - fed from the rail the expander controls - dies mid-command and the
pack stays dead until **all four** cells are removed to drop +3V3, so the firmware must never open
the last closed cell while a usable cell remains.

### I2C map on the carrier bus

0x10 PAC1934 (pack), 0x20 TCA9534 (carrier), **0x21 TCA9534 (pack)**, 0x24 PN532, 0x27/0x3F LCD
backpack, **0x48 ADS1115 (pack)**, **0x6B BQ25601 (pack)**. No collisions. 0x30 (pack MCU) is free.

### Power-up and the boot lock-out

Variant A needed the pack MCU, fed from the cells through the diode-OR, to close the default-off
switches; without an MCU nothing would close them, the pack rail would stay at 0 V and the Heltec
(fed from SYS through the key) could never boot. Variant B avoids this by making the switches
**default on**, like an ordinary power bank: insert cells, the rail comes up, the Heltec boots and
opens whatever cell its policy rejects. The diode-OR stays, so the expander, ADC and LDO stay powered
even when the Heltec opens every cell.

### Temperature

The 4 bead NTCs stay in the holder floor windows and are read by the ADS1115 (per-cell temperature
is kept). ADS1115 power-down 0.5 uA typ, its power-up default (verified, ADS111x 7.4 and table 5.5).

Rejected: the 4 NTCs in parallel on the BQ25601 TS pin. Computed with the TS window
(VT1 73.3 %, VT5 34.2 % of REGN, verified BQ25601 table): a bias that trips at 60 C with all four
cells at 60 C (RT1 1.3k, RT2 7.5k) trips only at **about 101 C for one hot cell** with the others at
25 C. A parallel network does not follow the hottest cell closely enough.

The BQ25601 keeps its own board NTC `TH_CHG` on TS, so charging still stops on temperature with the
Heltec off.

### PAC1934 power

With the key off nothing can put the PAC1934 to sleep (the Heltec is unpowered), and at its
power-up rate it draws 585 uA (16 uA with SLOW high). Its PWRDN pin is therefore driven from the
key-switched rail: a divider from `VBAT_SW` (for example 10k/47k: 4.2 V -> 3.46 V, 3.3 V -> 2.72 V)
keeps it running only while the key is on; with the key off it is in power-down (0.1 uA, verified).
PWRDN drops the configuration and the accumulators (verified, section 4.1.6), so the Heltec
configures it on every boot (bidirectional channels, sample rate, ALERT).

## Functionality kept and lost

| Function | Variant A | Variant B |
|---|---|---|
| Any 1-4 cell combination | yes | yes |
| Per-cell V, I, temperature | yes | yes (key on) |
| Coulomb counting | continuous | key on only; charge added with the key off is estimated from the charger's "done" state or rest voltage |
| Supervision with the key off (incl. key-off charging) | per-cell policy in the pack MCU | **none per cell**: the charger's CV, BATOVP (104 % of VREG, verified) and board-NTC TS limit, plus the fuses |
| Connect-check before a cell joins | yes (default off) | **no**: a cell joins as soon as it is inserted (power-bank behaviour; buy matched cells) |
| Reaction to a short / alert | MCU interrupt, ms | Heltec polling (about 1 s); the fuses handle hard shorts |
| Pack firmware, DFU | needed | none |
| Key-off drain (est.) | 112 uA | about 8 uA with every cell closed (TCA9534 1, ADS1115 0.5, PAC1934 0.1, BQ25601 4.5, LDO 1); each open cell adds 3.3 uA through its 1M gate pull-up at 3V3, so all four open is about 20 uA |

Option, not in the baseline: supervise key-off charging by letting USB power wake the Heltec. The
BQ25601 /PG (open-drain, low = good input) could drive an AO3401A that bridges SYS to `VBAT_SW`
around the key. The catch is that the Heltec then cannot tell whether the key is on (both feed the
same node); it needs a second key contact on the spare `J_KEY1` pins 3-4, which depends on the EAO
switch having one (unverified).

## Cost

| | Variant A | Variant B |
|---|---|---|
| SMD Extended types (about $3 each per order) | 11 | **12**: minus STM32C071, plus TCA9534 and ADS1115 |
| Main chips per board (rough) | STM32C071 | TCA9534 + ADS1115 (somewhat more) |
| Placements | 104 | about 98 (11 MCU-side parts out, about 5 in) |

Variant B is **not cheaper to order**; it is simpler to own (no second firmware) and draws less
with the key off. B without the ADS1115 (no per-cell temperature, board NTC only) would be 11 types.
A single chip that does both jobs exists, ADS7128 (8 pins, each ADC or GPIO, C2867992, 1297 in
stock), but it has no KiCad symbol and the GPIO power-up state is unchecked.

## Firmware

The `asg-core` `pack` module (connection policy, disable rules, coulomb counting) is unchanged in
substance but runs on the Heltec in `asg-device` instead of a pack MCU, and the register-map
section of variant A becomes a set of drivers: PAC1934 (configure on boot, REFRESH, read
accumulators), TCA9534 (switches, /CE, polling P6/P7), ADS1115 (single-shot per NTC with P4 on),
BQ25601 (status, watchdog kick or disable). Two rules the hardware forces on that policy: it must
never open the last currently-closed cell while any usable cell remains - opening every cell removes
the Heltec's own supply through the rail the expander controls, and the pack cannot recover without
pulling all four cells to drop +3V3 - and the TCA9534 output register must be loaded before P0-P3
become outputs, with P4 raised before each NTC conversion. Unlike the carrier expander, writing 0 to
the output register here opens all four cells. The policy must open a cell when the Heltec sees it
fail, since nothing else will while the key is on.

## Repo effort

Keep both: a second board module `hardware/pack_b.py` that imports `pack.py` and edits its
`PARTS`/`NETS`/placement (remove the MCU block, swap `R_PD*` for pull-ups, add `U_EXP`/`U_ADC` and
the PWRDN divider), built with `make BOARD=pack_b all` into `fab/pack_b/`. `pack.py` (variant A)
stays as it is.

## Unverified

- ADS7128 GPIO power-up state (only matters if it replaces TCA9534 + ADS1115).
- A second contact on the EAO 82-6121.2000 key switch (only for the USB-wakes-Heltec option).
- I2C behaviour with the key off: the pack chips are powered while the carrier pull-ups are not, so
  SDA/SCL sit low; check on the bench that no pack chip misreads the key-on/key-off edges.
- Cable length and bus capacitance: three more chips on the carrier bus over the XH cable; 100 kHz
  should be fine at 20-30 cm.

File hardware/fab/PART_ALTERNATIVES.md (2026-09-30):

# Part alternatives considered (not adopted)

Ideas from the parts-list review (2026-09-30). **Nothing here is built or verified on the board.**
JLCPCB stock, price and Basic/Extended status were not checked (the parts API was unreachable);
LCSC numbers below come from a web search and need confirming on jlcpcb.com/parts before use.

**Why bother:** U2 and U3 are Extended parts, so each carries a one-off setup fee on the order
(see `ORDERING.md`, "Setup fees"). Per-unit chip prices matter little at 2-5 boards. A swap only
pays off if the replacement is Basic or Preferred Extended (no fee), or is dropped outright.

## U2: TCA9534PWR (I2C GPIO expander, C783615)

| Option | Fit | Notes |
|---|---|---|
| PCF8574T (SOIC-16, C398075), PCF8574PW (TSSOP-16, C1542493) | Same pinout and 0x20 address range as the TCA9534 | See the differences below. Basic/Preferred status unverified. |
| PCA9534, PCA9554 | Same registers and pinout family as the TCA9534 | Only worth it if one is Preferred or Basic. No LCSC numbers found. |

**PCF8574 differences:**
- No direction/config registers, so the firmware changes.
- Quasi-bidirectional outputs: high is a weak (~100 uA) pull-up.
- Every pin **powers up high**. That would switch on the `Q_LR1`, `Q_LB1` and `Q_BZ1` gates and `AMP_SD`
  at every reset until the firmware writes to it. The TCA9534 powers up as inputs, and the 10k
  gate pull-downs keep those loads off.

**Decision:** keep the TCA9534. The saving is a setup fee, and the PCF8574 would need extra hardware or firmware to hold the buzzer and LEDs off at reset.

## U3: MAX98357AETE+T (I2S class-D amp, C910544), replaced by the NS4168

| Option | Fit | Notes |
|---|---|---|
| NS4168 (Nsiway) | Cheaper I2S amp with integrated DAC, about 2.5 W (MAX98357A: about 3.2 W) | Not footprint-compatible. Gain and channel/enable pins differ, so `AMP_SD`, the gain strap and the amp block (`U3`, `C_AMP1`, `C_AMP2`, `R_SD1`) need redoing. LCSC number and Basic/Extended status not checked. |
| No amp | Budget variant (`VARIANTS` in `design.py`) | Already drops `U3` and its setup fee. |

Into 8 ohm the board delivers about 1 W either way, so the NS4168 costs no real output.

**Decision (2026-09-30):** switched to the **NS4168** (C910588, Extended, $0.38 vs $1.33 at LCSC; same setup fee).
Symbol in `local.kicad_sym`, footprint `HSOP-8-1EP_3.9x4.9mm_P1.27mm_EP2.3x2.3mm_ThermalVias` (package EP is
2.0 mm). What changed with it:
- **CTRL instead of SD_MODE:** below 0.4 V = off, 0.9-1.15 V = left slot, 1.5 V-VDD = right slot. The expander
  drives it high, so **the firmware must put audio in the right I2S slot** (or both). CTRL's absolute maximum is
  VDD, so R_SD1 (1k) stays in series; `R_SDPD1` (10k to GND on `AMP_SD`) holds it off at reset, since no
  internal pull-down is documented. Pulses of 1-12 us on CTRL set the input high-pass filter; I2C expander
  writes are far slower, so the default filter stays.
- **No gain pin:** gain is fixed; volume is digital, as before.
- **13 mA quiescent when on** (MAX98357A: 2.4 mA): the firmware should hold CTRL low between clips.
- **C_AMP1** is now the 100 uF 6.3 V part (datasheet: ~100 uF + 1 uF at VDD; VBAT_SW stays under 4.2 V).

## To verify before acting

- Basic/Preferred/Extended status, stock and price of PCF8574T/PW, PCA9534, PCA9554 and NS4168 on JLCPCB.
- NS4168 pinout, footprint and gain/enable behaviour against the datasheet.

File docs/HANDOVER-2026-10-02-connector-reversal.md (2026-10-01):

# Handover: 2-wire connectors back to XH-2 (2026-10-02)

Reversed the 2026-09-30 `a42af2a` decision that unified every off-board connector on JST-XH 4-pin
B4B-XH-A (C144395), leaving pins 3-4 no-connect on the 2-wire loads. A 2-wire load now gets a 2-pin
B2B-XH-A (C158012); the four 4-wire connectors (LCD, NFC, BTN_R, BTN_B) and the 6-pin pack link
(J_PWR1, B6B-XH-A C144397) are unchanged.

Why: the unification bought one connector part number, but forced a 4-pin harness housing on every
2-wire lead and pushed J_BTN_R1 off the top edge for width. Both parts are through-hole Extended
types, so the 2-pin addition carries no feeder-setup fee, and it is cheaper per board.

## Changed

- `design.py`: `XH2` footprint; `J_HBAT1`/`J_BUZ1`/`J_SPK1` -> `Conn_01x02` + XH2; LCSC split
  (C158012 vs C144395); `XH_SPARE` gone. Top edge re-spaced at pad-1 x 10 / 30.5 / 41 / 56.5 / 72 for
  J_PWR1 / J_HBAT1 / J_BTN_R1 / J_LCD1 / J_NFC1 (~2 mm courtyard gaps). J_BTN_R1 is back on the top
  edge and its `REF_AT` workaround is gone.
- `gen_sch.py`: dropped the `XH_SPARE` no-connect test.
- `gen_pcb.py`: dropped the stale "2-wire connectors on 4-pin XH" label comment.
- `pack.py`: `J_KEY1` -> XH2 / C158012; `XH4` and `XH_SPARE` gone. Position unchanged (the freed
  length buys nothing on the right edge).
- `fab/ORDERING.md`, `fab/OFFBOARD_PARTS.md`: THT type counts, silk/preview note, housing list, backups.

## Verified

- `make boards` on KiCad 9.0.8: carrier 522 tracks, pack 1394 tracks, both 0 unrouted; ERC 0 errors /
  0 warnings and DRC 0 violations on both; `fab/` and `fab/pack/` regenerated.
- Carrier BOM gained one line: the 4-pin C144395 (LCD/NFC/BTN_R/BTN_B) and 2-pin C158012
  (HELTEC_BAT/BUZ/SPK) connector lines are now separate.
- C158012 checked live on LCSC: JST B2B-XH-A(LF)(SN), XH 2.5 mm THT, 2P, 3 A / 250 V, 322,420 in
  stock, $0.0409 at 20+.

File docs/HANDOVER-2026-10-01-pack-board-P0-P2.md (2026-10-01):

# Handover: pack board implementation (P0-P2 done, P3.1 in progress)

Date: 2026-10-01
Branch: `esp32-lora-design` (repo root `/home/kmk/dev/ASG_AirsoftCounter`)
Plan: `docs/plans/2026-10-01-pack-board-implementation.md` (the task list to execute)
Spec: `docs/plans/2026-10-01-pack-board-design.md` (binding design; has the P0 "Parts" section)
Working ledger: `.superpowers/sdd/2026-10-01-pack-board-implementation/progress.md` (git-ignored scratch;
this handover carries the durable version of it)

Goal of the plan: a JLCPCB-ready 4x18650 pack board (`hardware/pack.*`, `hardware/fab/pack/`) generated
by the same flow as the carrier, plus the carrier with its power section moved off (`J_PWR1`).

## State in one line

P0.1, P1.1-P1.5, P2.1, P2.2 are done, verified and committed. P3.1 (pack schematic layout) was started
and reverted because the block layout did not generate; P3.2 through P6.2 are not started. The carrier
still builds and its generated files are byte-identical to the committed routed set.

## Environment / commands

- Run everything from `hardware/`. Use `/usr/bin/python3` (only it has `pcbnew`); `kicad-cli` 9.0.8;
  Freerouting 2.4.1 jar in `hardware/tools/`; Java 25.
- `rtk` rewrites some output; use plain `make`, `/usr/bin/grep -F`, `diff`, `cmp` when output matters.
- Self-checks: `python3 board.py`, `python3 design.py` (carrier), `python3 pack.py` (pack).
- Carrier: `make pcb`, `make all`, `make boards`. Pack: `make BOARD=pack sch|pcb|route|check|fab`.
- `make all` takes ~4 min (autorouting). It rewrites tracked `fab/*.pdf` and the Gerber zip with new
  timestamps; restore them with `git checkout` if you do not intend to commit them.

Carrier byte-identity gate (same_as_base.sh was deleted in P1.5; recreate the check this way):

```sh
cd hardware && make pcb >/dev/null && mkdir -p /tmp/carrier_base && cp carrier.kicad_sch carrier.kicad_pro carrier.kicad_pcb /tmp/carrier_base/
git checkout -- carrier.kicad_pcb carrier.kicad_sch carrier.kicad_pro     # restore routed
# after a change:  make pcb >/dev/null && for f in carrier.kicad_sch carrier.kicad_pro carrier.kicad_pcb; do cmp "$f" "/tmp/carrier_base/$f"; done && git checkout -- carrier.kicad_*
```
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

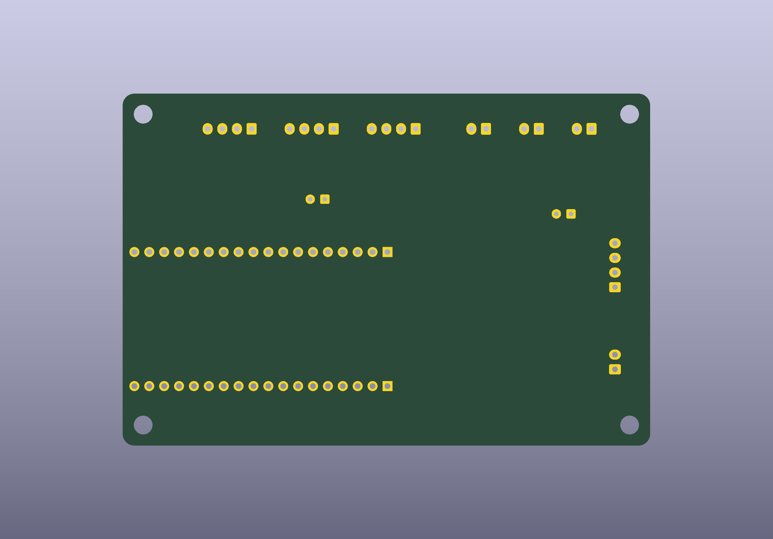
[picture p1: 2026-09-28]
hardware/fab/placed_bottom.png

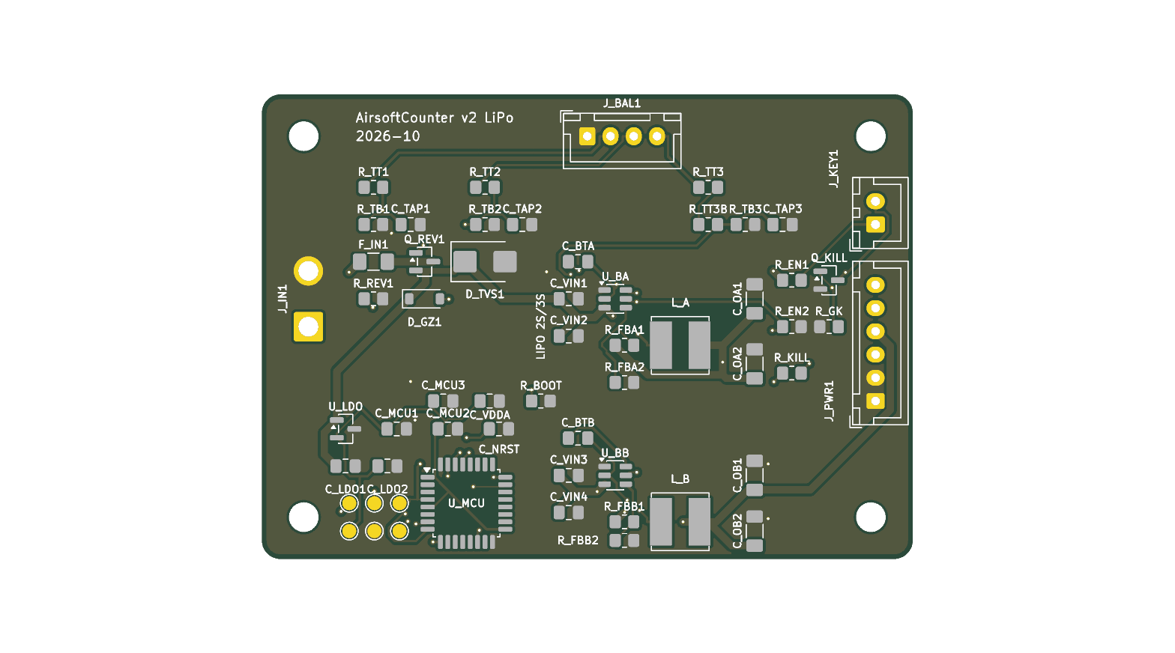
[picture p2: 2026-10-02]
hardware/fab/lipo_tme/top.png

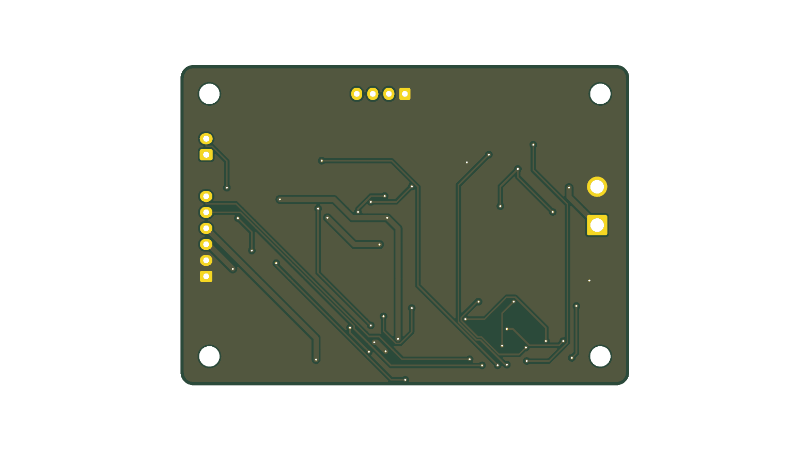
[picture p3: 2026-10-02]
hardware/fab/lipo/bottom.png

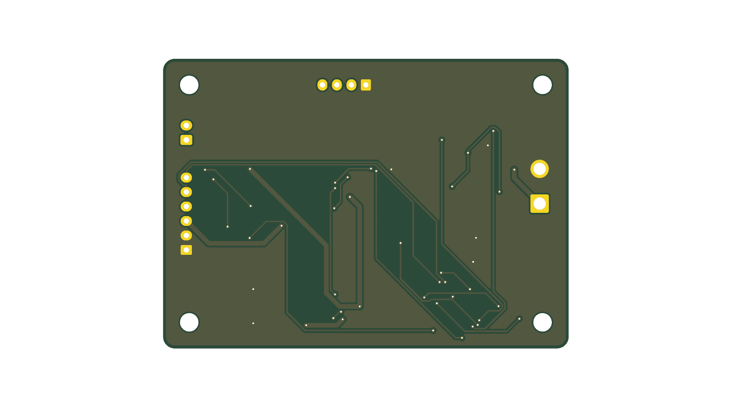
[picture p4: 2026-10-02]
hardware/fab/lipo_tme/bottom.png

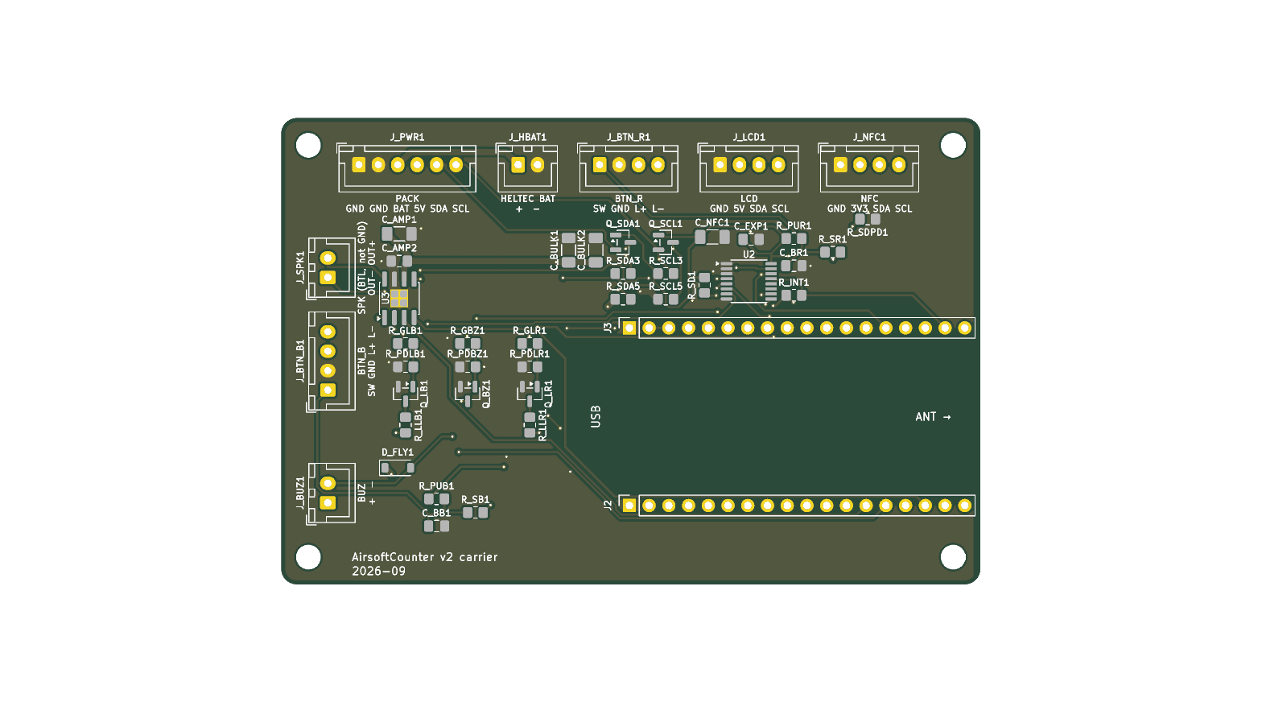
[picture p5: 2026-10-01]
hardware/fab/top.png

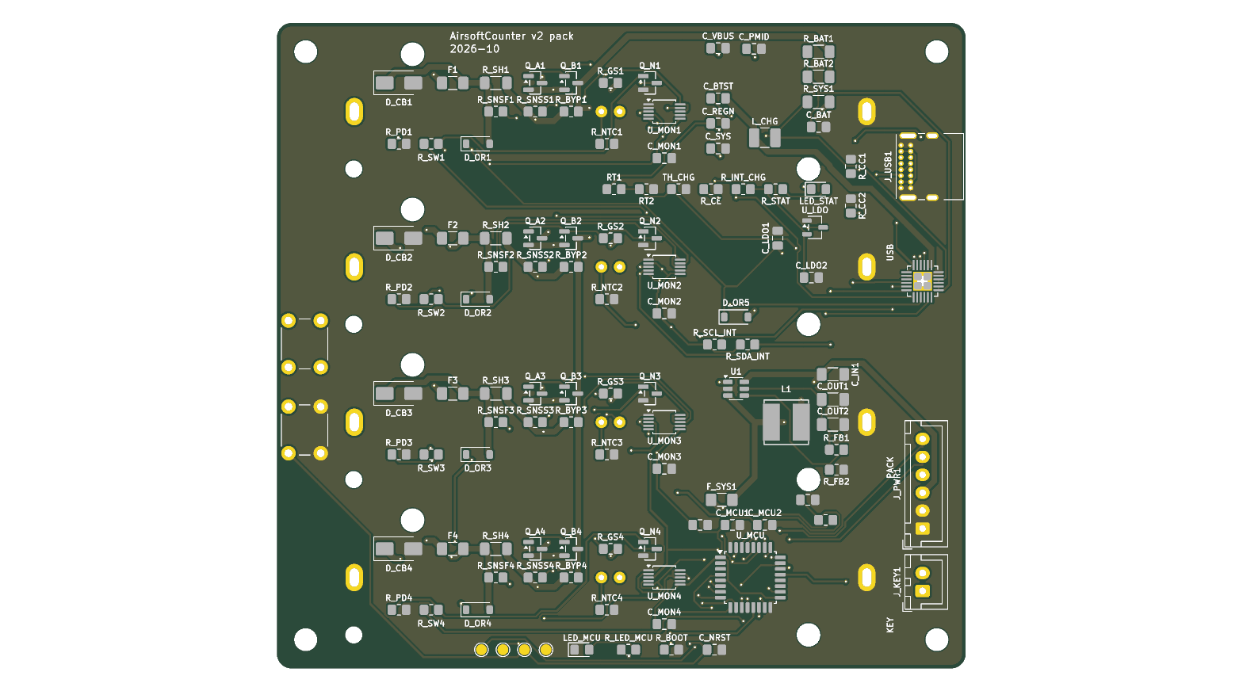
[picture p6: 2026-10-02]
hardware/fab/pack_tme/top.png

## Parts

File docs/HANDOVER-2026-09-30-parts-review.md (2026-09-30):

# Handover: PCB parts-list review (2026-09-30)

Branch: `esp32-lora-design` (pushed, latest commit `f516105`). The cloud session had no KiCad, so
**all source changes are made but nothing was regenerated.** Start by running `make all` in
`hardware/` on a machine with KiCad 9 and fixing whatever it reports.

## Commits this session

| Commit | What |
|---|---|
| `a42af2a` | All 9 off-board connectors unified to JST-XH 4-pin B4B-XH-A (C144395); the five 2-wire ones (BAT, KEY, HELTEC_BAT, BUZ, SPK) leave pins 3-4 NC (`design.XH_SPARE`, flagged no-connect in `gen_sch.py`). |
| `89aaec2` | AO3400A dropped; `Q_LR1`, `Q_LB1`, `Q_BZ1` now BSS138 (C7420339), like the I2C shifter. Loads are ~15 mA (ONPOW LAS1-AGQ 6 V ring) and ~8 mA (BZ-38), both from web-search snippets, not datasheets. |
| `7f64a6c` | `hardware/fab/PART_ALTERNATIVES.md`: TCA9534 (U2) and MAX98357A (U3) alternatives, none adopted. |
| `f516105` | Driver gate resistors 100R -> 1k, gate pull-downs 100k -> 10k; `hardware/fab/PARTS_REVIEW.md`. |

`ORDERING.md`, `OFFBOARD_PARTS.md`, `COSTS.md` and the design doc were updated to match. Current
counts: 19 BOM lines Deluxe / 18 Budget, 7 Extended types Deluxe / 6 Budget, 2 Preferred, 10 Basic.
`python3 design.py` passes.

## To do before this is usable (needs KiCad)

**Items 1–4 done locally (KiCad 9.0.8):** `make all` passes with ERC 0, DRC 0, 0 unrouted, and the
`fab/` outputs are regenerated (19/18 BOM lines). The six top connectors did not fit at 90x60, so
J_BTN_R1 moved to the bottom edge under J2; see the "As built" note under the placement table in the
implementation plan. Two-wire connectors label only pins 1-2 on silk (pads 3-4 blank = NC). In
`gen_sch.py` the five former 2-pin connectors (and F1, C_AMP1/2) were shifted, because `Conn_01x04`
has pin 2 on the symbol origin where `Conn_01x02` had pin 1. Item 5 (bench check) is still open.

**Later the same day:** U4 XB8089D cell protection added (the Heltec V4 has no UVLO), U3 swapped to the
NS4168, and `hardware/power_budget.py` added. See `PARTS_REVIEW.md` and `PART_ALTERNATIVES.md`.

1. **`gen_pcb.py` placement.** A 4-pin XH is ~12.4 mm long (2-pin ~7.4 mm). On the top edge
   J_BAT1/J_KEY1/J_HBAT1/J_LCD1 are 9-12 mm apart and will overlap; the left-edge J_SPK1/J_BTN_B1/J_BUZ1
   are tight. Re-place them; the 90x60 mm board may need to grow.
2. **Silkscreen `LABELS`** in `gen_pcb.py` for the now-unused pins 3-4.
3. **`make all`:** regenerates schematic, PCB, routing, ERC/DRC and `fab/*.csv` (`jlc_bom*.csv`,
   `bom.csv`, CPL). Those CSVs are stale until then.
4. **Schematic auto-router:** check `gen_sch.py` copes with the taller 4-pin symbols in the existing
   `BLOCKS` layout (may report clashes; adjust positions/block sizes).
5. **Gate divider:** with 1k gate R and 10k pull-down the FET gate sits at ~3.0 V (3.3 V x 10/11).
   Fine for ~15 mA loads; confirm on the bench.

## Open questions (nothing decided)

- **Battery protection.** F1 (2 A hold PTC) is the only protection on unprotected 18650s. Hold current
  derates to ~1.4 A at 60 C (estimate) vs ~1.5 A worst-case load, so nuisance trips are possible in a
  hot enclosure. There is no under-voltage cutoff on the board and the MT3608 EN is tied to VIN (always
  on). **Whether the Heltec V4 cuts off a discharged cell is unverified** (Heltec's datasheets were
  unreachable): check the V4 schematic. Options: protected cells, or firmware cutoff on VBAT sense
  (GPIO1) plus a boost enable on spare expander pin P6/P7 (`U2.11`/`U2.12`).
- **Optional merges not done:** `C_BULK1/2` to the 100 uF 6.3 V part (drops one line, less hot-plug
  margin); drop `D_FLY1` (BZ-38 is a piezo with generator, not inductive).
- **Alternatives unverified:** JLCPCB Basic/Extended status, stock and price of PCF8574T/PW,
  PCA9534, PCA9554, NS4168 were never checked (jlcpcb.com was unreachable). Decision so far: keep
  TCA9534 (PCF8574 powers up high, which would switch on buzzer/LEDs at reset) and MAX98357A.

## Reasoning recorded in the repo

- `hardware/fab/PART_ALTERNATIVES.md`, `hardware/fab/PARTS_REVIEW.md`
- Why the two ICs exist: MT3608 makes the 5 V rail (LCD, 6 V LED rings, buzzer) that the Heltec does
  not provide; TCA9534 frees GPIOs so I2S (47/48/21) fits, see "Part 6" of
  `docs/plans/2026-09-28-esp32-lora-carrier-design.md`.
- Setup fees apply only to Extended parts, so merging Basic values saves BOM lines, not money.

## Environment notes

- The cloud sandbox blocked jlcpcb.com and heltec.cn; nothing there could be verified.
- Bash tool calls failed intermittently on a safety-check error; retries eventually succeeded.

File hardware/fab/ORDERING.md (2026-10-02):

# Ordering the PCBs from JLCPCB (bare board or assembled)

**Separate boards, separate orders.** The carrier is `fab/carrier_gerbers_jlcpcb.zip` (90 x 60 mm,
sections 1-6 below), the 4x18650 pack board is `fab/pack/pack_gerbers_jlcpcb.zip` (96 x 90 mm,
section 7) and the 2S/3S LiPo board is `fab/lipo/lipo_gerbers_jlcpcb.zip` (70 x 50 mm, section 8).
The hand-build TME variants are the same three outlines, ordered **bare** (section 9).
The Economic setup fee is per order per Extended part type, so the totals below are per board.

Regenerate everything with `cd hardware && make boards` (all boards; it exits non-zero if ERC, DRC
or the gerber check fails, for any board).

## 1. Upload

Go to https://jlcpcb.com/, click "Order now" and upload **`fab/carrier_gerbers_jlcpcb.zip`** (9 Gerber layers + PTH/NPTH Excellon drill files).
JLC should detect **90 x 60 mm, 2 layers** on its own. If it shows a different size or layer count, stop and don't order.
Check the Gerber viewer: the outline has rounded corners, there are 4 mounting holes 3.5 mm in from each edge, and both sides have a GND pour.

## 2. Form settings

| Field | Setting | Why |
|---|---|---|
| Base material | FR-4 | |
| Layers | 2 | |
| Dimensions | 90 x 60 mm (auto) | |
| PCB Qty | 5 | This is the minimum. |
| Product type | Industrial/consumer electronics | |
| Different design | 1 | |
| Delivery format | Single PCB | No panel needed for hand assembly. |
| PCB thickness | 1.6 mm | Matches the design and the standoffs. |
| PCB color | Green | Cheapest and fastest. Other colours work but can take longer. |
| Silkscreen | White | |
| Surface finish | LeadFree HASL (recommended) or HASL with lead | Leaded HASL is the cheapest and a bit easier to hand-solder. Lead-free is RoHS, which suits an EU build and lead-free solder. ENIG is not needed. |
| Outer copper weight | 1 oz | |
| Via covering | Tented | This is the standard option for small vias. |
| Min via hole size/diameter | 0.3mm/(0.4/0.45mm), the default | The design uses 0.3 mm drill vias with a 0.6 mm pad. |
| Board outline tolerance | ±0.2 mm (Regular) | |
| Mark on PCB | Default (order number) | JLC prints its order number somewhere on the silkscreen. Placing it at a chosen spot needs a marker text on the board, which this design doesn't have. Removing it is a paid option. It is harmless for this board. |
| Electrical test | Flying Probe Fully Test | Free for small boards. |
| Gold fingers | No | |
| Castellated holes | No | |
| Edge plating | No | |
| Impedance control | No | |
| Confirm production file | Optional | "Yes" means you approve JLC's processed files before production. It is slower, but a useful extra check on a first order. |
| PCB assembly / stencil | Off for a bare board | For an assembled board, see section 5. |

Leave the other fields at their defaults. Price and lead time follow from these choices. Compare the options on the form itself.

## 3. Board facts (for capability questions)

| Item | Value |
|---|---|
| Size / layers | 90 x 60 mm, 2 copper layers, rounded corners |
| Material / thickness | FR-4, 1.6 mm, 1 oz outer copper |
| Min track / clearance | 0.25 mm signal / 0.8 mm power tracks (0.15 mm rule, for necks into the fine-pitch U1/U2/U3 pads); 0.2 mm clearance |
| Vias | 0.6 mm pad / 0.3 mm drill, tented (56 vias, 8 of them GND), plus 4 thermal vias of the same size in U3's exposed pad |
| Plated component holes | 0.95 / 1.0 mm (the U3 thermal vias are 0.3 mm, like the vias) |
| Non-plated holes | 4 x 3.2 mm (M3 mounting), in the NPTH drill file |
| Copper to board edge | 0.5 mm |
| Silkscreen | text 0.8–1.0 mm, 0.15 mm stroke, top only |
| Copper pours | GND on top and bottom |
| Components | top side only (SMD + THT), no bottom-side parts |
| Special features | none: no castellations, edge plating, gold fingers or impedance control |

## 4. Before paying: Heltec fit check (Task A5)

You can get a price quote now. **Don't pay until the 1:1 paper fit check has passed** with a real Heltec V4:

1. Print `fab/print_1to1.pdf` at 100 % (no "fit to page"). Check the scale on the J2/J3 header holes: the centres of the first and last hole in a row are **43.2 mm** apart (17 x 2.54 mm), and the two header rows are **22.86 mm** apart. The board is plotted from the page's top-left corner, so the top and left board edges may not print. That is expected, so don't use the outline as the scale reference.
2. Push the Heltec header pins through the paper at J2/J3. All 18 pins of each row should go straight through.
3. Orientation: the Heltec's USB-C end goes at the **"USB"** label (the left end of the header rows, where pin 1 is the **square** pad in each row), and the antenna end points at **"ANT →"** and the right board edge. **J3 (GPIO1–7) is the top row**; the rows are labelled J3/J2 at the left and "Heltec_J3"/"Heltec_J2" at the right. A mirrored or reversed module would put GND/3V3 on GPIO pins.

## 5. Assembly (PCBA, optional)

JLC can assemble every on-board part, SMD and through-hole, from `fab/jlc_bom.csv` (parts with LCSC numbers) and `fab/jlc_cpl.csv` (placements). Both are written and checked by `make all` (`jlc.py`). The DNP pull-ups R_SDA5/R_SCL5 and the mounting holes are left out on purpose.

**Service.** Use **Economic** PCBA. It solders through-hole parts by wave soldering and takes 2 to 50 boards (older JLC pages say 30). Standard PCBA needs a board of at least 70 x 70 mm, and at 90 x 60 mm this one only fits as a panel. Sources: https://jlcpcb.com/capabilities/pcb-assembly-capabilities and https://jlcpcb.com/help/article/pcb-assembly-faqs

**Steps**

1. Upload `fab/carrier_gerbers_jlcpcb.zip` and fill in the form as in section 2.
2. Turn on "PCB Assembly". Choose **Economic**, assemble the **Top** side, and set how many boards to assemble (2 or all 5).
3. Upload **`fab/jlc_bom.csv`** as the BOM and **`fab/jlc_cpl.csv`** as the CPL / pick-and-place file.
4. Check the parts matching. There are 14 BOM lines, and each should match the LCSC number in its row with stock for your quantity. Nothing should be left unmatched or skipped.
5. Open the 3D placement preview and do the checks below before you confirm.

**Through-hole parts are included**: J2/J3 (1x18 sockets) and the 8 JST-XH headers (7 off-board plus J_PWR1). JLC solders them by wave soldering and charges per THT joint on top of the SMD assembly. The price shows on the form. The old THT electrolytics (220 µF C_BULK1, 100 µF C_NFC1) are gone: the bulk capacitors are now 1206 ceramics (2x 47 µF on VBAT_SW, 100 µF on 3V3).

**Setup fees.** Economic PCBA charges a setup (feeder loading) fee, about $3 per order, for each **SMD Extended** part type. Basic and Preferred Extended parts don't have it, and through-hole parts don't either (JLC lists them as Extended, but they are wave-soldered). This board has:

- **2 SMD Extended types (fee):** U2 (TCA9534PWR, C783615) and U3 (NS4168, C910588). About $6 per order. (U4, U1, L1 and F1 moved to the pack board in P5; see section 7.)
- **4 through-hole Extended types (no loading fee, per-joint THT charge instead):** J2/J3 socket (C2905422), the JST-XH 4-pin (C144395: LCD, NFC, BTN_R, BTN_B) and 2-pin (C158012: HELTEC_BAT, BUZ, SPK) off-board connectors, and J_PWR1 (JST-XH 6-pin, C144397).
- None of the two SMD Extended types has a Basic or Preferred replacement (JLC parts API, 2026-09-30: I2C expanders and I2S/class-D amps were searched). The only ways to cut the
  fee are the Budget variant (no U3) or hand-soldering some of them yourself.
- Cheaper alternatives for U2 and U3 that were considered are in `PART_ALTERNATIVES.md`; other review findings are in `PARTS_REVIEW.md`.
- **2 Preferred Extended types (no fee):** BSS138 (Q_SDA1/Q_SCL1 and the three low-side drivers, C7420339) and the 75k resistor (R_FB1, C17819).
- **8 Basic types:** everything else, including the ceramic bulk capacitors C_BULK1/C_BULK2 (47 µF 10 V, C96123) and C_NFC1 (100 µF 6.3 V, C15008), and the 0 Ω LED jumpers R_LLR1/R_LLB1 (C17477).

**Placement preview checks.** The CPL uses KiCad's rotations with no JLC corrections. Sources disagree on the SOT-23 offset (180° or −90°), and JLC's engineers correct rotation using the silkscreen polarity marks. Mid X/Y is the centre of each part's courtyard, so the through-hole parts sit on their holes. In the preview, check:

| Part | What to check |
|---|---|
| U1 (SOT-23-6) | The pin-1 dot sits at the silkscreen pin-1 mark. |
| U2 (TCA9534, TSSOP-16) | The pin-1 dot sits at the silkscreen pin-1 mark (top left, on the R_SD1 side). |
| U3 (NS4168, eSOP-8) | The pin-1 dot sits at the silkscreen pin-1 mark (U3 is rotated 90°: pin 1 is at the lower left, towards J_BTN_B1). The exposed pad is centred on the square pad with its vias. |
| Q_SDA1, Q_SCL1, Q_LR1, Q_LB1, Q_BZ1 (SOT-23) | The single pin (drain, pin 3) is on the single-pad side. These are the parts most likely to be off by 90° or 180°. |
| D1 (SMA), D_FLY1 (SOD-123) | The cathode band is on the silkscreen band side. |
| U4 (XB8089D, SOIC-8-EP) | gone: the protector is on the pack board now (section 7). |
| J2, J3 | Pin 1 is on the square pad at the USB end, and the socket covers all 18 holes. |
| J_PWR1 (6-pin XH) | The latch/key side faces the board edge, and pin 1 is at the left (see the silkscreen "PACK" label: GND GND BAT 5V SDA SCL). |
| JST-XH headers | The latch/key side faces the same way as the silkscreen outline, and each header's pin count matches its label (2-pin HELTEC_BAT/BUZ/SPK, 4-pin LCD/NFC/BTN_*). |

If a part is wrong, fix its `Rotation` in `fab/jlc_cpl.csv` (degrees, counter-clockwise positive) and upload the file again. You can also leave it and note it in the order, because JLC's engineers follow the silkscreen polarity marks. Don't edit the CSVs by hand as a long-term fix: `make all` rewrites them.

**Stock.** The J2/J3 socket (about 2.8k in stock) and L1 (about 3.2k), as of 2026-09-29, are the parts most likely to run out. Verified backups: socket C2897381, JST-XH 4-pin clone C37815, BSS138 C82045 (check the 2-pin XH's own clone separately). (The old PTC backup C5358568 is a 1 A part and no longer fits F1.) To switch, change the number in `LCSC` in `design.py` and run `make all`. Check the new part's package and pinout on its LCSC page first.

**Budget variant.** The same board, assembled without the speaker and NFC modules (see `design.py` `VARIANTS`
and `COSTS.md`). Order the same Gerber zip, then upload **`fab/jlc_bom_budget.csv`** and
**`fab/jlc_cpl_budget.csv`** instead. Differences from the steps above:

- 13 BOM lines and 36 placements (Deluxe: 14 and 43). Nothing else in the form changes.
- **1 SMD Extended type**, not 2: U3 (NS4168, C910588) is not fitted, so its setup fee is gone. The Preferred (1) and Basic (8) counts are unchanged.
- Not fitted: U3, C_AMP1, C_AMP2, R_SD1, J_SPK1 and J_NFC1. In the placement preview, check that none of them appear.
- Buy the speaker and the PN532 only if you add those modules later; the footprints stay empty on the board.

## 6. Parts

A bare board ships without parts. `fab/bom.csv` lists the on-board parts to buy separately, grouped by value and footprint. The DNP pull-ups R_SDA5/R_SCL5 are left out on purpose.
Off-board parts (details in `docs/plans/2026-09-28-esp32-lora-carrier-design.md`, Parts 1–3 and 5):

- Heltec WiFi LoRa 32 V4 (no display, EU868) and an L76K GNSS module
- PN532 NFC module ("NFC V3", I2C mode)
- 20x4 serial LCD Newhaven NHD-0420D3Z-FL-GBW-V3 (bridge R1 for I2C)
- 2x ONPOW LAS1-AGQ-11E/x/6V IP67 pushbuttons (6 V ring LED with a built-in resistor, so R_LLR1/R_LLB1 are 0 Ω jumpers; fit a resistor there to dim an LED)
- Active 5 V buzzer
- Weatherproof **8 Ω, 2 W speaker** on J_SPK (see below)
- IP65 key switch (its lead goes to the pack board's J_KEY1)
- 4x MYOUNG BH-18650-A6AJ012 holders and 4x MF52 10k B3435 bead NTCs (hand-soldered on the pack board's
  bottom side) and 4 matched INR18650-35E cells
- JST-XH 6-pin cable, straight 1:1, carrier J_PWR1 <-> pack J_PWR1 (pin 1 to pin 1)
- IP67 USB-C panel extension
- u.FL-to-SMA bulkhead pigtail and an 868 MHz antenna
- SH1.25-to-XH battery pigtail (for the Heltec battery input)
- JST-XH housings and crimps
- M3 standoffs
- Kradex ZP240.190.105SJp enclosure and ZP240.190-PCB mounting plate

**Speaker.** U3 (NS4168) drives J_SPK as a bridge-tied load (BTL): both pins switch, and neither is ground. Connect the speaker's two leads straight to J_SPK (pin 1 OUT-, pin 2 OUT+, as on the silkscreen) and **never connect either lead to GND, the enclosure or a shared return wire**: that shorts an output stage. Use an **8 Ω, 2 W** speaker (Visaton K 50; roughly 0.6 W into 8 Ω from a 1S cell, estimated from the datasheet's 1.2 W into 4 Ω at 3.6 V), plus an ePTFE acoustic vent in the enclosure wall if needed.

Other files in `fab/`: `schematic.pdf`, `top.png`/`bottom.png` (3D renders), `gerbers/` (created by `make all` and not committed: the unzipped Gerbers plus drill maps and a Gerber job file, which are not in the zip).

## 7. The pack board (4 x 18650)

`fab/pack/pack_gerbers_jlcpcb.zip`, 96 x 90 mm, 2 layers, 1.6 mm, rounded corners, top-side
assembly only (the cell holders go on the bottom, by hand). Upload it as its own order and fill in the form as in section 2 (JLC auto-detects the
size and layer count; if it shows something else, stop). Schematic `fab/pack/schematic.pdf`, renders
`fab/pack/top.png` / `bottom.png`.

**Assembly.** Same Economic PCBA flow. BOM `fab/pack/jlc_bom.csv` (36 lines), CPL
`fab/pack/jlc_cpl.csv` (103 placements, all top side). The DNP 0R bring-up bypasses R_BYP1-R_BYP4 are
left off on purpose. **By hand, after the board arrives:**
1. **Bead NTCs TH1-TH4** (MF52A103F3435, LCSC C84036) on the **bottom** side, bead in the middle of each
   holder outline (it sits in the holder's floor window and touches the cell), leads soldered on top.
   Fit them before the holders.
2. **Holders BT1-BT4** (MYOUNG BH-18650-A6AJ012, LCSC C19184084) on the **bottom** side: the snap pegs
   locate them, the two tabs are soldered on top. The bottom silkscreen `+` marks the positive end; all
   four face the same way.
3. **Charger NTC TH_CHG** (0805 10k B3435, CMFB 103F3435, LCSC C2889056) on the **top** side, between
   RT2 and R_CE. Left off, the charger reads "cold" and does not charge.
The holders and NTCs are not in the BOM/CPL (JLC's Economic PCBA is top side only; TH_CHG is left off
to save its Extended setup fee).

**Setup fees (SMD Extended types, about $3 each).** 10 types, about $30 per order:
BQ25601RTWR (C468236), STM32C071KBTx (C42116633), PAC1934T-I/JQ (C623960),
MT3608 (C84817), the 1.5 uH charger inductor (C703084), the 10 uH boost inductor (C2046332),
the USB-C receptacle (C2894897), the 10 mOhm shunt (C105362),
the 5 A fuse (C48332) and the 2 A PTC (C22374899). None has a Basic replacement at JLC (parts API,
2026-10-02; the MT3608 -> TPS61040 (Preferred) swap was rejected: about 89 mA out at 3.0 V in, worst
case, against an 82 mA peak +5V load). The 2026-10-02 simplification removed the XB8089D, BAT54C and the 5.23k/30.9k TS pair
and replaced the two INA3221s with one PAC1934
(design doc, "Simplification delta"). To cut the per-board chip cost, assemble 2 of the 5 boards. **2 through-hole Extended types** (no loading fee, per-joint charge):
J_KEY1 (XH 2-pin, C158012) and J_PWR1 (XH 6-pin, C144397). **Preferred (no fee):** 75k (C17819) and
BSS138 (C7420339). Everything else is Basic.

**Placement preview checks** (the CPL carries KiCad rotations, no JLC corrections):

| Part | What to check |
|---|---|
| U_CHG (BQ25601, QFN-24) | The pin-1 dot sits at the silkscreen pin-1 mark. |
| U_MCU (STM32C071, LQFP-32) | The pin-1 dot sits at the silkscreen pin-1 mark. |
| U_MON (PAC1934, UQFN-16) | The pin-1 dot sits at the silkscreen pin-1 mark; the exposed pad is centred. |
| Q_A*/Q_B*/Q_N* (SOT-23) | The single pin (drain, pin 3) is on the single-pad side. Most likely to be off by 90/180 deg. |
| D_CB*, D_OR*, D1 (SMA / SOD-123) | The cathode band is on the silkscreen band side. |
| J_USB1 (USB-C) | The opening faces the right board edge (the "USB" silk); the shield pads straddle their holes. |
| BT1-BT4, TH1-TH4 (bottom side), TH_CHG | Not in the CPL: hand-soldered (see Assembly above). |
| LED_STAT, LED_MCU | The cathode (bar) is on the silkscreen band side. |

**Board facts.** 96 x 90 mm, 1 oz; 142 vias of 0.6/0.3 mm (tented); signal tracks 0.25 mm, power
0.8 mm (0.15 mm rule for necks into the fine-pitch QFN/LQFP/UQFN pads); NPTH: 4 x 3.2 mm M3
mounting, 12 holder snap pegs (3.3/2.4 mm) and 2 USB-C shell pins (0.65 mm); PTH: 8 plated holder-tab
slots 1.3 x 2.6 mm, 0.95/1.0 mm (J_KEY1/J_PWR1), 0.8 mm (bead NTCs) and 0.6 mm (the USB-C shell).
GND pours on both layers.

**Note.** The M3 hole pattern is provisional (the ZP240.190 plate is unmeasured). With the cells under
the board, standoffs need about 20 mm plus clearance (holder 14.9 mm, the cell top sits higher). Before paying
for boards, put a real BH-18650-A6AJ012 on the 1:1 print (`fab/pack/print_1to1.pdf`): check the tab
slots and pegs, and that the floor window leaves room for the bead NTC (design doc, Unverified).

## 8. The LiPo board (2S/3S)

`fab/lipo/lipo_gerbers_jlcpcb.zip`, 70 x 50 mm, 2 layers, 1.6 mm, rounded corners, top-side
assembly only. Upload it as its own order and fill in the form as in section 2 (JLC auto-detects the
size and layer count; if it shows something else, stop). Schematic `fab/lipo/schematic.pdf`, renders
`fab/lipo/top.png` / `bottom.png`.

**Assembly.** Same Economic PCBA flow. BOM `fab/lipo/jlc_bom.csv` (25 lines), CPL
`fab/lipo/jlc_cpl.csv` (49 placements, all top side). **By hand, after the board arrives:**
1. The XT60 pigtail on `J_IN1`: two solder pads at a 6 mm pitch with a 1.7 mm drill. Use a 14 AWG /
   1.5 mm2 lead (design doc, Parts) and a female XT60 inline or panel connector; T-plug users use an
   adapter lead. `J_IN1` is not in the BOM/CPL.
2. The five test pads (`TP_SWDIO`, `TP_SWCLK`, `TP_NRST`, `TP_3V3`, `TP_GND`) are bare pads: solder a
   wire for bring-up, or leave them and use a pogo/SWD adapter. They are not in the BOM/CPL either.

Order an XT60 female pigtail (or a bare female XT60 + 14 AWG wire) and JST-XH housings/crimps for
`J_BAL1` (4-pin; a 2S 3-pin plug fits pins 1-3), `J_KEY1` (2-pin, the IP65 key switch) and `J_PWR1`
(6-pin, the same 1:1 harness as the pack board's `J_PWR1`).

**Bring-up** (bench supply on `J_IN1`, 7.4 V, 100 mA limit; see the design doc's Bring-up):
key open -> only 3.3 V on `TP_3V3`, a few hundred uA in; key closed -> 4.10 V on `VBAT_SW` and
5.07 V on `+5V`; reversed supply -> no current; then a real 2S and a real 3S pack.

**Setup fees (SMD Extended types, about $3 each).** 4 types, about $12 per order: the 5 A fuse
(C48332), TPS54302DDCR (C311983), SRN6045TA-100M (C2046332) and STM32C071KBTx (C42116633). None has
a Basic/Preferred replacement (parts API, 2026-10-02). **3 through-hole Extended types** (no
loading fee, per-joint charge): `J_KEY1` (C158012), `J_BAL1` (C144395), `J_PWR1` (C144397).
**Preferred (no fee):** 75k (C17819), BSS138 (C7420339), MMSZ5240B (C19077425) and SMBJ15A
(C19077569). Everything else is Basic.

**Placement preview checks** (the CPL carries KiCad rotations, no JLC corrections):

| Part | What to check |
|---|---|
| U_BA/U_BB (TPS54302, TSOT-23-6) | The pin-1 mark sits at the silkscreen pin-1 mark. |
| U_MCU (STM32C071, LQFP-32) | The pin-1 corner sits at the silkscreen pin-1 mark. |
| Q_REV1/Q_KILL (SOT-23) | The single pin (drain, pin 3) is on the single-pad side. |
| D_GZ1 (SOD-123), D_TVS1 (SMB) | The cathode band is on the silkscreen band side. |
| J_KEY1/J_BAL1/J_PWR1 (XH) | The latch side faces the same way as the silkscreen outline; pin 1 is at the marked end. |
| `J_IN1` (solder pads) | Not in the CPL: hand-soldered. |

**Board facts.** 70 x 50 mm, 1 oz; 462 tracks/vias; signal 0.25 mm, power 0.8 mm (the two SW nodes
stay 0.25 mm: the TSOT-23-6 SW pad at 0.95 mm pitch cannot take 0.8 mm; accepted, the runs are
~8 mm with GND pours on both layers); vias 0.6/0.3 mm (tented);
PTH 0.95/1.0 mm (the XH headers) and the 1.7 mm `J_IN1` solder pads; NPTH 4 x 3.2 mm M3. GND pours
on both layers.

**Note.** 4S is out of scope, but the input rating (TPS54302 28 V, HT7533-1 30 V) leaves room if the
SMBJ15A is swapped for a higher-standoff TVS.

## 9. TME hand-build boards (carrier_tme, pack_tme, lipo_tme)

The same three boards re-drawn for an iron-only build from TME parts. **Order bare PCBs only, no JLC
assembly**: `fab/carrier_tme/carrier_tme_gerbers_jlcpcb.zip` (90 x 60 mm, settings as sections 1-2),
`fab/pack_tme/pack_tme_gerbers_jlcpcb.zip` (96 x 90 mm, section 7) and
`fab/lipo_tme/lipo_tme_gerbers_jlcpcb.zip` (70 x 50 mm, section 8).

**Parts.** Upload `fab/tme_bom_all.csv` (`symbol;qty`, all three boards, written by
`/usr/bin/python3 tme_all.py`) to TME Quick Buy: small passives carry spares (+10 %, at least 5) and
resistors are rounded up to TME's 100 pcs cut tape. `fab/<board>_tme/tme_bom.csv` is one board's exact
count. Substitutes for parts TME lacked (2026-10-02): INA226AIDGSR for the INA228 (same pins and
addresses; the firmware needs INA226 registers), TPS563200DDCR for the LiPo TPS54302 (3.3 uH, 22k/56k
dividers; **17 V max input**, so 3S only), SRN6045-3R3Y, SSA34 (SMA), Bel C1F-5 fuses. **PCM5100APWR
(carrier_tme U_DAC) is not in the list**: TME only had it as 70 pcs tubes or 2000 pcs reels, so buy
one at LCSC or Mouser. The other LCSC-only parts are not in it: the pack's 18650 holders (MYOUNG
BH-18650-A6AJ012) and bead NTCs, plus the off-board parts in `fab/offboard/`.

**Hand-solder notes.**
- **BQ25601 (U_CHG, pack_tme)** is a QFN-24 with a 1.5 mm plated hole through the exposed pad
  (`local:QFN-24-...HandSolder`, pads extended 0.6 mm): flux the pad ends and drag the numbered pins,
  then fill the exposed pad through the hole from the **back** with the iron tip.
- The **USB4085** USB-C and the **6x6 tact switches** are through-hole and must clear the bottom-side
  holders; the pack places them in the holder-free strips. Check `fab/<board>_tme/print_1to1.pdf`
  (F.Fab + silk, with the QFN pin-1 marker) before soldering.
- The LQFP-32 L072 and the VSSOP-10 INA226s are leaded and drag-solderable.

**Board facts.** Same outline, holes and 2-layer stack as the JLC originals; the pack keeps 0.8 mm
power traces except `+5V`, which is 0.25 mm (82 mA peak) so the MCP1640's fine VOUT pad takes it.

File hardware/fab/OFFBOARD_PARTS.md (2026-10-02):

# Off-board parts (per device)

These are the parts the carrier and pack PCBs do not carry. Codes and URLs were checked live on
2026-09-29; stock changes, so re-check before ordering. Sources are TME (tme.eu) and
Botland (botland.com.pl) where possible; anything else is marked **other**. Prices and
cheaper alternatives per row are in the section below the table.

Order lists (per device, TME codes re-checked 2026-10-02) are in `offboard/`: `tme_offboard.csv` and
`tme_offboard_crimp.csv` (only for crimping your own leads instead of the pigtails of #25) go
straight into TME Quick Buy > "Upload from file"; `offboard_other.csv` is everything else, with a
Build column (all / pack / lipo). The board parts themselves have the same lists next to each JLC BOM
(`tme_bom.csv`, `tme_other.csv`, written by `tme.py`).

| # | Part | Qty | Shop | Code | URL | Notes |
|---|---|---|---|---|---|---|
| 1 | Heltec WiFi LoRa 32 V4 (863–870 MHz, no display, S3R2 or S3R8) | 1 | **other: Heltec** (DE warehouse) | variant selector | https://heltec.org/project/wifi-lora-32-v4/ | Not sold at Botland or TME. Confirm the no-display build is selectable; the page says "custom orders without OLED" go through sales. Pick R2 or R8 deliberately (different firmware build). The 28 dBm version needs EU TX-power capping in firmware. |
| 2 | Heltec L76K GNSS module | 1 | **other: Heltec** | – | https://heltec.org/project/l76-gnss-module/ | 1.25 mm 8-pin cable included. Mount under the clear lid, facing the sky. |
| 3 | PN532 NFC module | 1 | **other: kamami.pl** | Czytnik RFID/NFC PN532 13,56MHz Mifare I2C/SPI + brelok i karta | https://kamami.pl/szukaj?controller=search&s=PN532 | **24.90 zł, verified 2026-09-29.** Same boxed red "V3" board with card and fob as Botland MOD-08240, which is 59.90 zł. Check the photo shows the I2C DIP switches; the PN532 sits at 0x24 and the Newhaven LCD is fixed at 0x28, so they do not clash. |
| 4 | NTAG213 player cards | per player | TME | RFID-GW-NTAG213 | https://www.tme.eu/pl/details/rfid-gw-ntag213/moduly-i-czytniki-rfid/goodwin/pvc-white-card-ntag213-thermal-s-n/ | Alternative: stickers RFID-STICK-NT213. Write `ASG1:R:017` with any phone NFC app. |
| 5 | 20x4 serial LCD, transflective yellow-green | 1 | Mouser | 763-0420D3ZFLGBW-V3 (Newhaven NHD-0420D3Z-FL-GBW-V3) | https://www.mouser.com/c/?q=NHD-0420D3Z-FL-GBW-V3 | ~$17 (also Newhaven direct, DigiKey NHD-0420D3Z-FL-GBW-V3-ND; TME has none). 5 V, 98x60 mm PCB, 13.5 mm max depth, **4x Ø2.5 mm holes** on a 93x55 mm grid (M2.5, not M3; see #21). STN(+) transflective: readable in daylight with the backlight off. Backlight 1-8 by I2C command. I2C 0x28 (7-bit), **50 kHz max**, 10k pull-ups on the module (carrier R_SDA5/R_SCL5 stay DNP). **☐ Before wiring: bridge jumper R1 (I2C mode)** — it ships in RS-232 mode. **☐ On arrival: measure** 5.0 V supply current at backlight level 8 and level 1; those replace `LCD_ON_5V` and `LCD_IDLE_5V` in `power_budget.py`. I2C is on **J2** (2.54 mm holes, no pins fitted: 1 SPISS, 2 SDO, 3 SCL, 4 SDA, 5 VSS, 6 VDD), not J1 (RS-232). The order differs from J_LCD1, so solder the XHP-4 pigtail crossed: XH 1 GND -> J2.5, XH 2 5V -> J2.6, XH 3 SDA -> J2.4, XH 4 SCL -> J2.3; J2.1/J2.2 open. |
| 6 | Red button, IP67, 19 mm, 6 V ring LED | 1 | TME | V19-11R-06R-S | https://www.tme.eu/pl/details/v19-11r-06r-s/przelaczniki-przyciskane/onpow/las1-agq-11e-r-6v/ | ONPOW LAS1-AGQ-11E/R/6V. Use COM+NO. The LED has a built-in resistor, so the carrier's R_LLR1 is 0 Ω. Test brightness at 5 V. |
| 7 | Blue button, IP67, 19 mm, 6 V ring LED | 1 | TME | V19-11R-06B-S | https://www.tme.eu/pl/details/v19-11r-06b-s/przelaczniki-przyciskane/onpow/las1-agq-11e-b-6v/ | As #6 (R_LLB1 is 0 Ω). |
| 8 | Buzzer, panel piezo with generator, 3–28 V, 90 dB | 1 | TME | BZ-38 | https://www.tme.eu/pl/details/bz-38/sygnalizatory-piezoelektr-z-generatorem/ | No IP rating: seal it to the wall with a gasket or silicone. |
| 9 | Loudspeaker, waterproof IP65, 8 Ω 2 W, 50 mm | 1 | TME | VS-K50-8 | https://www.tme.eu/pl/details/vs-k50-8/glosniki/visaton/2901/ | VISATON K 50 (2901), 10.23–14.20 zł, 829 in stock 2026-09-30; the WP (2915) is out of stock, only a narrower 250 Hz–10 kHz band. Mount behind a grille of holes with a front gasket. **Never connect a speaker lead to GND** (BTL output). Smaller option: VS-K36WP-8 (36 mm, 1 W). |
| 10 | Key switch, IP65, 22 mm, 2 maintained positions | 1 | TME | 82-6121.2000 | https://www.tme.eu/pl/details/82-6121.2000/stacyjki-i-zamki/eao/ | EAO; only 5 were in stock. Check the datasheet for a rating of at least 1 A at 5 V DC. Its two leads run to the **pack board's J_KEY1** (not the carrier, since P5); current is the whole pack, so keep the leads short and thick. |
| 11 | 18650 holder, MYOUNG BH-18650-A6AJ012 (THT, flat stainless contacts) | 4 | LCSC | C19184084 | https://www.lcsc.com/product-detail/C19184084.html | **Hand-soldered on the pack board's bottom side** (not in the JLC BOM/CPL): two THT tabs plus three snap pegs per holder; drawing MY-CP-0373 is what the footprint follows. Order it with the JLC parts (LCSC) or separately. Unprotected cells only (protected cells are longer). Polarity is on the bottom silkscreen. Fallback with a KiCad footprint: MPD BH-18650-PC (taller, 21.3 mm; needs a footprint swap). Avoid generic coil-spring holders (uneven contact resistance, loose pin pitch). |
| 11a | Bead NTC, MF52A103F3435 (10k, B3435, 1 %) | 4 | LCSC | C84036 | https://www.lcsc.com/product-detail/C84036.html | TH1-TH4, hand-soldered on the bottom side in each holder's floor window, before the holders; the bead should touch the cell. |
| 12 | 18650 cell, Samsung INR18650-35E | 4 | Botland | BAL-15216 | https://botland.com.pl/akumulatory-li-ion/15216-ogniwo-18650-li-ion-samsung-inr18650-35e-3400mah-5904422343071.html | Buy all four in one batch and match their voltages before inserting. Parallel cells that differ will fight through the protectors (design doc, Risks). |
| 13 | USB-C panel extension, IP67 with cap, male–female, about 30 cm | 1 | **other: Allegro / AliExpress** | – | – | None suitable at TME or Botland. Generic ones are IP67 only with the cap closed. |
| 14 | u.FL (IPEX) to SMA pigtail, 150 mm | 1 | TME | GSM-IPX/SMA-150 | https://www.tme.eu/pl/details/gsm-ipx_sma-150/anteny-gps/sr-passives/ | Check in the datasheet that it is SMA (not RP-SMA) female bulkhead with a nut. Alternative: Botland SPF-02942 (10 cm). |
| 15 | 868 MHz antenna, SMA male | 1 | TME | ANT-868-CW-RCS-SMA | https://www.tme.eu/pl/details/ant-868-cw-rcs-sma/anteny-rf/linx-technologies-te-connectivity/ | 3.6 dBi. Short stub alternative: 2J0C15-868-C885G. Avoid RP-SMA antennas. |
| 16 | Heltec battery plug: Molex PicoBlade 2-pin housing | 1 | TME | MX-51021-0200 | https://www.tme.eu/pl/details/mx-51021-0200/zlacza-sygnalowe-raster-1-25mm/molex/51021-0200/ | Heltec's "SH1.25" mates with **PicoBlade 1.25 mm**, not JST SH or GH. **Check polarity with a meter.** |
| 17 | PicoBlade crimp contacts | 2 (+spares) | TME | MX-50079-8000 | https://www.tme.eu/pl/details/mx-50079-8000/zlacza-sygnalowe-raster-1-25mm/molex/50079-8000/ | 26–28 AWG wire only; keep the lead short. |
| 18-19 | JST XHP housings | 4 x XHP-4, 4 x XHP-2 (+spares) | TME | XHP-4, XHP-2 | https://www.tme.eu/pl/details/xhp-4/zlacza-sygnalowe-raster-2-50mm/jst/ | Pin count matches the wires. Carrier XHP-4: LCD, NFC, BTN_R, BTN_B (all four positions used). Carrier XHP-2: HELTEC_BAT, BUZ, SPK. Pack XHP-2: KEY. Search TME for the XHP-2 in the same series. Plus a spare of each. |
| 18b | JST XHP-6 housing and cable, carrier <-> pack | 2 housings, 1 cable | TME | XHP-6 | https://www.tme.eu/pl/details/xhp-6/zlacza-sygnalowe-raster-2-50mm/jst/ | The power link: **straight 1:1, pin 1 to pin 1** on both boards (GND GND BAT 5V SDA SCL). Both boards' J_PWR1 are pin-1-left on the top edge, so a straight cable keeps the polarity. Make it short and use 24 AWG; it carries the pack current. Check pin 1 with a meter before plugging in. |
| 20 | JST SXH-001T-P0.6 crimp contacts | ~30 | TME | SXH-001T-P0.6 | https://www.tme.eu/pl/details/sxh-001t-p0.6/zlacza-sygnalowe-raster-2-50mm/jst/ | 28–22 AWG. No crimper? Botland kit JUS-19558 (clone parts, contacts still need crimping). |
| 21 | M3 brass standoffs | 8 | Botland | KAB-09700 (120-pc kit) | https://botland.com.pl/tuleje-dystansowe/9700-tuleja-dystansowa-mosiezna-rozne-rozmiary-m3-zestaw-120szt-5904422308179.html | Carrier (4 holes) and LCD (4 holes), so 8 standoffs. **The Newhaven LCD holes are Ø2.5 mm: M3 does not fit, so its 4 standoffs must be M2.5** (or drill the LCD holes out to 3.2 mm, clear of traces). The kit is 52.90 zł for 120 pcs: buy loose standoffs, or the kit only when building several units. |
| 22 | Enclosure Kradex ZP240.190.105SJp, clear lid, IP67 | 1 | Botland (in stock) / TME | KDX-16650 / ZP240.190.105SJP TM ABSPC | https://botland.com.pl/obudowy/16650-kradex-hermetyczna-obudowa-zp240190105sjp-ip67-tm-abs-240x190x105mm-z-mosieznymi-tulejami-jasnoszara-przezroczysta-5905275016433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 | Botland's has an ABS base; TME's `ZP240.190.105SJP TM ABSPC` is the same box (all-PC: `ZP240.190.105SJP TM PC`, out of stock 2026-09-29). |
| 23 | Kradex ZP240.190-PCB mounting plate | 1 | TME | ZP240.190-PCB | https://www.tme.eu/pl/details/zp240.190-pcb/obudowy-akcesoria-pozostale/kradex/ | "While stocks last" (38 in stock). |
| 24 | Harness wire, 24 AWG stranded | – | any | – | – | XH contacts take up to 0.34 mm² and PicoBlade up to 0.13 mm². |
| 25 | Pre-crimped pigtails, JST-XH | 1 set | **other: msalamon / Allegro** | – | see "Ready-made cables" below | Alternative to #16–20. Arrives already terminated, so **no crimper is needed**. Per-lead list and links below. |

## Prices and cheaper alternatives

Checked 2026-09-29. The Botland and kamami figures were read live from the shop pages.
TME blocks scripted fetches (HTTP 403), so TME figures are **estimates — verify before
ordering**. Swaps marked **no** are not viable: the `J_NFC` I2C port, the L76K GNSS pinout
and the Heltec V4 pin map are frozen by the carrier.

| # | Price (2026-09-29) | Cheaper option | Saving | Risk |
|---|---|---|---|---|
| 1 | est. ~95 zł (Heltec) | V4 → V3 | ~25 zł | **no** — pins, FEM pins and R2/R8 PSRAM differ |
| 2 | est. ~65 zł (Heltec) | ATGM336H / NEO-6M | ~35 zł | **no** — L76K-specific EN/RST/STANDBY pins |
| 3 | **24.90 zł** (kamami, verified) | AliExpress clone, 10–20 zł | 35 zł vs Botland | none — same red V3 board |
| 4 | est. ~3 zł each | NTAG213 stickers (#4 alternative) | ~2.5 zł each | low — cards get handled, stickers do not |
| 5 | ~$17 (Mouser) | generic yellow-green 2004A + PCF8574 backpack, ~25 zł | ~45 zł | **high** — on/off backlight only, transmissive (unreadable in sun with the backlight off), firmware needs the HD44780 driver back |
| 6, 7 | est. ~35 zł each (TME) | generic 19 mm IP67 6 V ring-LED | ~30 zł total | low — must be **6 V**, not 12 V |
| 8 | est. ~15 zł (TME) | generic active 5 V piezo with generator | ~10 zł | low |
| 9 | est. ~45 zł (TME) | generic IP65 8 Ω 2 W speaker | ~25 zł | low — the amp only makes ~1 W into 8 Ω |
| 10 | est. ~90 zł (TME) | generic 22 mm IP65 2-position keyswitch | ~60 zł | low — it carries only ~250 mA |
| 12 | **29.90 zł each** (Botland, verified) | cheaper 2600 mAh cell | ~30 zł | **no** — eats the 24 h runtime |
| 14 | est. ~15 zł (TME) | AliExpress u.FL→SMA pigtail | ~10 zł | low |
| 15 | est. ~70 zł (TME) | any 863–870 MHz SMA whip | ~45 zł | **medium** — this one sets LoRa range |
| 16–20 | est. ~10 zł total | pre-crimped pigtails (row 25) | see row 25 | none |
| 21 | **52.90 zł** (Botland, verified, 120-pc kit) | buy 8 standoffs | ~40 zł | none |
| 22 | **119.90 zł** (Botland, verified) | generic IP65 clear-lid box | ~30–60 zł | **high** — clear lid, 105 mm depth and 20x4 LCD constrain the fit |
| 23 | est. ~15 zł (TME) | 3 mm acrylic cut to size | ~15 zł | low |
| 25 | est. ~15 zł set | — | avoids a crimper | none |

**The crimper is the biggest single line and is not in the table.** A usable JST/PicoBlade
crimper is 60–250 zł. Pre-crimped pigtails (#25) cost ~15 zł and remove that purchase,
which is more than every other swap here combined. Order them before anything else.

## Ready-made cables (no crimper)

Checked 2026-10-02. Every board connector is a JST XH 2.5 mm header (B*B-XH-A). Shops sell the mating
XHP housing on a wire as a "JST-XH 2,54 **męski**, przewód 20 cm + gniazdo" set: the wired plug is what
you need; the loose PCB socket in the bag is a spare. "XH2.54" and "XH2.5" are the same series. All
pigtails below are single-ended (bare tinned ends), 26 AWG, 20 cm: solder and heat-shrink the far end.

| Lead | Board end | Far end | Buy | Qty | Link | Notes |
|---|---|---|---|---|---|---|
| Carrier J_PWR1 <-> pack / LiPo J_PWR1 | XHP-6 | XHP-6 | 2 x 6-pin pigtail, joined wire-to-wire **1:1** | 2 | [msalamon 6-pin, 2.68 zł](https://sklep.msalamon.pl/produkt/przewod-gniazdo-jst-xh-254mm-20cm-6-pin/) | Cut both to ~7 cm and join same colour to same colour, so pin 1 meets pin 1. Ready double-ended cables exist ([Keszoox 6-pin, 22 AWG, "Same Side"](https://keszoox.com/products/jst-xh-2-54mm-6pin-cable-connector-both-sided), ~$4.26, often sold out), but **never buy a "Reverse Side" one**: it swaps BAT with I2C. 26 AWG is enough for a 15 cm link; 22-24 AWG if you can get it. |
| J_LCD1 | XHP-4 | LCD I2C pins | 4-pin pigtail | 1 | [msalamon 4-pin, 2.37 zł](https://sklep.msalamon.pl/produkt/przewod-gniazdo-jst-xh-254mm-20cm-4-pin/) | **Newhaven NHD-0420D3Z:** solder into the J2 holes (no pins fitted), crossed: XH 1 GND -> J2.5, XH 2 5V -> J2.6, XH 3 SDA -> J2.4, XH 4 SCL -> J2.3. **Fallback 2004A + PCF8574 backpack (HW-61):** its header is GND VCC SDA SCL, so it is straight; solder to the pins or use an XH-to-Dupont-female lead ([Abra](https://abra-electronics.com/interconnects/connectors/jst-connectors/jst-xh/con-jst-xh-4d-connector-jst-4-pin-xh2-54-to-dupont-jumper-connector-female-4x1-pin-20cm.h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), [Funduino](https://funduinoshop.com/en/components/cable-systems/kabeltypen/jst-system/jst-xh2.54-male-to-dupont-female-cable-4p-24awg-150cm)). |
| J_NFC1 | XHP-4 | PN532 I2C header | 4-pin pigtail | 1 | as J_LCD1 | Solder straight into the PN532 holes instead of the supplied pin strip; the V3 board's I2C header is GND VCC SDA SCL, same as J_NFC1. |
| J_BTN_R1, J_BTN_B1 | XHP-4 | button lugs | 4-pin pigtail | 2 | as J_LCD1 | Solder to the ONPOW lugs (COM/NO, LED +/-) per the carrier silkscreen. |
| J_BUZ1, J_SPK1, pack J_KEY1 | XHP-2 | buzzer leads, speaker tabs, key switch | 2-pin pigtail | 3 | [Gotronik 6-pack, 14.15 zł](https://www.gotronik.pl/wtyczka-jst-xh254-z-przewodem-20cm-gniazdo-x-6szt-p-5042.html) / [msalamon 2-pin, 2.16 zł](https://sklep.msalamon.pl/produkt/przewod-gniazdo-jst-xh-254mm-20cm-2-pin/) (out of stock 2026-10-02) | Allegro has the same for ~2 zł ("JST XH 2.54 2pin z przewodem 20cm"). |
| J_HBAT1 | XHP-2 | Heltec battery socket (1.25 mm) | 2-pin XH pigtail + **the battery cable that ships with the Heltec V4** | 1 | as above | The V4 box contains two SH1.25 leads (battery, solar). Join one to an XH-2 pigtail: XH 1 = VBAT (+), XH 2 = GND. **Check the Heltec lead's polarity with a meter** before joining; 1.25 mm leads have no standard colours. Spares: Allegro "Micro JST 1.25 2PIN" (PicoBlade-compatible; avoid "GH1.25", which does not mate). Makes #16-17 unnecessary. |
| LiPo J_IN1 | solder pads | battery XT60 | XT60 **female** (gniazdo) with 14 AWG, 10 cm | 1 | [Botland 7517](https://botland.store/wires-and-power-connectors/7517-xt60-socket-with-cable-10cm-5904422335854.html) / [modele.sklep.pl, 3.99 zł](https://modele.sklep.pl/gniazdo-xt-60-z-przewodem-14awg-10-cm-czarny-czerwony-msp-p-3526.html) | Battery packs carry the male XT60, so the board lead is the female. Matches the 1.7 mm pad holes (14 AWG). |
| LiPo J_BAL1 | B4B-XH | battery balance plug | **nothing** | – | – | The pack's balance plug (XHP-4 for 3S, XHP-3 for 2S on pins 1-3) plugs straight in. |

Per device: 2 x 6-pin, 4 x 4-pin, 4 x 2-pin pigtails, plus the XT60 lead for the LiPo build; about 25 zł
with spares. Before the first plug-in, **meter every lead pin 1 to pin 1**: cheap pigtails use random colours.

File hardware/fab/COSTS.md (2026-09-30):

# Per-unit cost: Deluxe and Budget variants

Checked 2026-09-30, PLN gross. **V** = read from a shop page; **~** = estimate or unverified generic part.
TME hides its exact price, so a TME figure is the high end of its schema price range, which matched the
gross price on the items cross-checked. Excludes the carrier PCB/PCBA (no quote yet), shipping, standoffs
and wire (never priced). Player cards are ~3 zł each on top.

Variants are defined in `hardware/design.py` (`MODULES`, `VARIANTS`); `make fab` writes
`fab/jlc_bom.csv`/`jlc_cpl.csv` (deluxe) and `fab/jlc_bom_budget.csv`/`jlc_cpl_budget.csv`.

## Presets

| Line | Deluxe | Budget | Basis |
|---|---|---|---|
| Heltec V4 (863–870 MHz, no display) | 85 | 85 | V: $17.90–27.50 range, exact option price shown only at checkout |
| LCD 20x4 I2C | 34.90 | 34.90 | V Botland |
| Buttons, 2x | ~93 | ~42 | Deluxe: ONPOW 19 mm IP67, blue 46.46 V, red not stocked (est. same). Budget: generic 16 mm IP65 metal, 5 V LED (Allegro ~20.99 each), IP rating unverified |
| Buzzer | 22 | ~15 | Deluxe: 3–28 V piezo, 13.45–22.22 V (the BZ-38 URL redirected to this part, code unconfirmed) |
| Key switch | 53.33 | 53.33 | V TME AUSPICIOUS KS22-1O/C, 38.11–53.33, 322 in stock; maintained, IP65 |
| 2x 18650 cells | 59.80 | 59.80 | V Botland (2x 29.90) |
| 2x 18650 holders | 7.80 | 7.80 | V Botland (2x 3.90) |
| Antenna + u.FL pigtail | 53.74 | ~30 | Deluxe: Linx 40.51 V + pigtail 13.23 V. Budget: generic whip ~ (sets LoRa range: test first) |
| USB-C panel extension | ~35 | ~35 | ~ IP67 when capped/mated accepted. Fallback: Kamami 32.02 V + rubber plug 1.90 V + gasket |
| JST/PicoBlade connectors | ~10 | ~10 | ~ |
| Enclosure | 178.55 | 65.74 | Deluxe: Kradex ZP240.190.105SJp 119.90 V + plate 58.65 V. Budget: Pawbol S-BOX 416-P, 52.59–65.74 V at TME (36 in stock); 34.05 at elektryczny.pl but 2 in stock |
| L76K GPS | 29 | – | V $8 + cable |
| PN532 NFC | 24.90 | – | V kamami |
| Speaker (VISATON K 50, IP65, 8 Ω 2 W) | 14.20 | – | V TME 10.23–14.20, 829 in stock |
| **Total (priced lines)** | **~700** | **~440** (~390 with a ~5 zł toggle) | Budget: ~305 of it is V |

## Module mix

Add or remove per module. Everything works on the same PCB; only the BOM changes (see `design.MODULES`).

| Module | Adds | Deluxe part | Budget part | On-board parts dropped when absent |
|---|---|---|---|---|
| Buttons | +93 / +42 | ONPOW pair | generic 16 mm pair | 2 BSS138 drivers, 2 RC input filters, `J_BTN_R/B` |
| RFID | +24.90 (+3/card) | PN532 | same | `J_NFC1` |
| Speaker | +14.20 | VISATON K 50 | same | NS4168 (`U3`), its caps, `R_SD1`, `R_SDPD1`, `J_SPK1` |
| GPS | +29 | L76K | same | none (Heltec connector only) |
| Key vs toggle | +53.33 vs ~5 | KS22 | KS22 or toggle | none |
| Enclosure | 178.55 / 65.74 | Kradex + plate | Pawbol | none |

Rules: a variant needs **buttons or RFID** (`design.check()` fails otherwise). RFID without buttons means no
local admin menu. Dropping the speaker also drops the only Extended-part setup fee on the amp (`U3`, C910588);
`U2` (the expander) stays in every variant because the LEDs, buzzer and buttons sit behind it.

## Budget trade-offs

- **Buttons:** IP65 instead of IP67, unbranded, 16 mm hole instead of 19 mm. A 12 V ring LED would be dim on
  our 5 V rail (~3 mA estimated); buy a 5 V-rated one. Buy one pair as a test first.
- **Key switch:** 3 A / 230 V AC rating, no published DC rating (our load is ~250 mA at 4 V).
- **Case:** Pawbol S-BOX 416-P is IP65 (manufacturer catalog), clear PS/ABS/PC lid, 4 plastic screws, IK08.
  The catalog lists **190 x 140 x 70 mm as inside dimensions** (whether the 70 mm includes the lid depth is
  not stated). No brass inserts and no mounting plate: standoffs into the base bosses or glued bases. Wall
  thickness and boss spacing unknown: do a 1:1 mock-up with one box before ordering more.
- **USB-C:** IP67 only while capped or mated; open while charging or flashing. Accepted.
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

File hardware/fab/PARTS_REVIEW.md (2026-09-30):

# Parts review notes (2026-09-30)

Findings from reviewing the fuse, capacitors, resistors and diodes. Datasheet figures are typical
values, not checked against the exact LCSC parts. JLCPCB stock/price was not checked (API unreachable).

## Changed

- Driver gate resistors 100R -> 1k and gate pull-downs 100k -> 10k (`design.py`): removes two BOM
  lines (C17408, C149504); every 0805 resistor is now 10k, 1k, 4k7, 0R or the 75k feedback part.
  The gate divider sets the FET gate to about 3.0 V (3.3 V x 10k / 11k) instead of 3.3 V. That is
  still well above the BSS138 threshold for ~15 mA loads. Costs about 0.3 mA per active driver.
- Both parts were Basic, so this saves no setup fee, only BOM lines.
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

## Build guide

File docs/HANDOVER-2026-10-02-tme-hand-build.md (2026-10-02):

# Handover: TME hand-build boards (T0-T4 and T5.1 done, T5.2 blocked, T6 not started)

Date: 2026-10-02
Branch: `esp32-lora-design` (repo root `/home/kmk/dev/ASG_AirsoftCounter`)
Plan: `docs/plans/2026-10-02-tme-hand-build-implementation.md` (the task list to execute)
Spec: `docs/plans/2026-10-02-tme-hand-build-design.md` (binding design; its "Parts" section is the T0.1 result)
Working ledger: `.superpowers/sdd/2026-10-02-tme-hand-build-implementation/progress.md` (git-ignored
scratch; this handover carries the durable version of it)

Goal of the plan: iron-solderable, TME-sourced versions of the carrier, pack A and LiPo boards
(`hardware/{carrier,pack,lipo}_tme.*`, `hardware/fab/<board>_tme/`), generated by the same flow as the
JLC boards. Firmware is out of scope.

## State in one line

T0.1, T1.1-T1.3, T2.1, T3.1-T3.3 and T4.1-T4.2 are done, verified and committed (`1c71c9c..86c59a3`);
**the LiPo and carrier TME boards build green**. T5.1 is done (pack data + self-check). **T5.2 (pack
schematic/PCB) is blocked** on the schematic autorouter; T6.1 and T6.2 are not started. The four JLC
boards still build and their `hardware/fab/` output is byte-identical to before this plan.

## Environment / commands

Run everything from `hardware/`. Use `/usr/bin/python3` (the `pcbnew` bindings are only in the system
Python). `rtk` rewrites output; use plain `make`, `/usr/bin/grep -F` and `diff` when you need exact text.

- Build one board: `make BOARD=<board> all` (sch -> netlist parity -> pcb -> autoroute -> ERC -> DRC -> fab).
  `<board>` is one of `carrier pack pack_b lipo carrier_tme pack_tme lipo_tme`.
- Faster loop while iterating on placement: `make BOARD=<board> pcb` then
  `kicad-cli pcb drc --schematic-parity --severity-all -o build/<board>_drc.rpt <board>.kicad_pcb`.
  On an unrouted board only courtyard/silk/parity matter; unconnected-pad reports are expected.
- Schematic only: `make BOARD=<board> sch`; a failed layout writes `build/<board>_bad.kicad_sch`
  and prints the clash list.
- Every board module self-checks: `/usr/bin/python3 <board>.py`. The JLC originals must stay green:
  `for b in carrier pack pack_b lipo; do BOARD=$b /usr/bin/python3 -c "from board import design; design.check()"; done`
- Toolchain in use: kicad-cli 9.0.8, pcbnew 9.0.8, freerouting-2.4.1.jar, openjdk 25, GNU make.

## What is committed (9a0eb18..86c59a3)

- `docs/plans/2026-10-02-tme-hand-build-design.md` — the "Parts" section replaces "Facts to confirm":
  every datasheet fact with its source and date, plus the 16 new TME symbols. Facts came from local
  PDFs (`pdftotext`) for TI/Diodes/Microchip; **st.com is unreachable from this host** (curl, the web
  fetch tool and the markitdown MCP all fail/time out), so the STM32L072KZT6 datasheet was fetched from
  the `part-elec.com` mirror and the AN2606 bootloader facts from the ST community plus the datasheet's
  USB/CRS sections.
- `hardware/board.py` — `check_structure` gains the TME rule: a module with a `TME` table must have no
  LCSC/placements, every bought part (not DNP, not `NOT_TME`, not a mounting hole) must have a TME
  symbol, and no stale table entries. Self-checked in `__main__` (RED->GREEN).
- `hardware/tme.py` — `from_lcsc(lcsc_table, keys)` helper, and a `BOARD` ending in `_tme` writes
  `$FAB/tme_bom.csv` straight from the module (`symbol;qty`). `import board` (not
  `from board import design`) is deliberate: a board module imports `tme`, so the form-import cycled.
- `hardware/Makefile` — `make fab` skips `jlc.py` for `%_tme` boards; `board.py` maps the three new
  names. (The `boards:` lines are T6.2 and are NOT added yet.)
- `hardware/tools/handsolder_qfn.py` + `hardware/local.pretty/QFN-24-1EP_4x4mm_P0.5mm_EP2.6x2.6mm_HandSolder.kicad_mod`
  — the BQ25601 land pattern extended 0.6 mm outward with the exposed pad as a 1.5 mm plated hole.
  Build + reload self-check: `/usr/bin/python3 tools/handsolder_qfn.py` -> `handsolder_qfn ok`.
- `hardware/lipo.py` — `LDO_VIN`/`TAP_ADC_PIN` constants; `check_power_path(m=None)` reads them.
- `hardware/lipo_tme.py` + `lipo_tme.kicad_{sch,pcb,pro}` + `fab/lipo_tme/` — L072 + AP7381-33SA-7.
- `hardware/carrier_tme.py` + `carrier_tme.kicad_{sch,pcb,pro}` + `fab/carrier_tme/` — PCM5100A + PAM8302A.
- `hardware/pack_tme.py` — the complete pack data module (self-checks), including the USB4085 drill
  floors (`PTH_COMPONENT_MIN = 0.4`, no USB NPTH), **but see the blocker below**.

Verification evidence (all re-run at handover time):

| command | result |
|---|---|
| `/usr/bin/python3 board.py` | `board.py self-check ok` |
| four JLC `design.check()` | all `ok` |
| `/usr/bin/python3 lipo_tme.py` | `lipo_tme ok: 62 parts, 31 nets` |
| `/usr/bin/python3 carrier_tme.py` | `carrier_tme ok: 65 parts, 43 nets` |
| `/usr/bin/python3 pack_tme.py` | `pack_tme ok: 129 parts, 78 nets` |
| `make BOARD=lipo_tme all` | exit 0, ERC 0/0, DRC 0 violations / 0 unconnected / 0 parity, `tme_bom.csv` 26 lines |
| `make BOARD=carrier_tme all` | exit 0, ERC 0/0, DRC 0/0/0, `tme_bom.csv` 22 lines |
| `git diff 9a0eb18..HEAD -- hardware/fab` (JLC dirs) | no change |

The generated files are committed (`.kicad_sch`, `.kicad_pcb`, `.kicad_pro`, `bom.csv`,
`schematic.pdf`, `top.png`, `bottom.png`, `print_1to1.pdf`, `tme_bom.csv`, the Gerber zip). The
`gerbers/` scratch dir is git-ignored.

## The blocker: T5.2 (pack schematic/PCB)

`gen_sch` cannot route `pack_tme`. `BOARD=pack_tme /usr/bin/python3 gen_sch.py` fails with an
`IndexError` in `name_label` (an empty-routed one-block net). Diagnostics from a monkeypatched
`gen_sch.astar`/`route`:

- Draft 1 — four INA228s in one row in block 1 (spacing 35.56 mm, tags at y 137.16): 7 router
  failures (`SDA_INT`, `SCL_INT` from the INA228 row; `NRST`, `BOOT0`, `SCL_EXT`, `MON_ALERT` from the
  MCU block) and one empty-routed net.
- Draft 2 — 2x2 INA228 grid at 50 mm spacing, tags moved to y 158.75: still at least one empty-routed
  net and the same `name_label` crash.
- The failing starts always have open neighbours, so it is the **goal region** that is unreachable, not
  the pin's escape: usually the pull-up pins in block 1 or the MCU tree. The relevant symbol change is
  that `MCU_ST_STM32L0:STM32L072KZTx` is 25.4 mm wide (pins at x +/-15.24) versus the C071's 15.24 mm
  (pins at +/-10.16), which shifts every MCU pin's escape corridor. The INA228 (via INA226) symbol is
  ~20 x 25 mm.

Both drafts were reverted; `hardware/pack_tme.py` is at the T5.1 commit and still self-checks. The
T5.2 edits are in git's reflog if you want them, but they do not work.

**What to do:** design the pack `BLOCKS`/`PLACE` fresh around the wider L072 symbol and the four
INA228s. The most promising direction is to put each INA228 in the **cell block it serves** (next to
that cell's shunt) instead of four in one block, which also matches the plan's intent for the PCB
("each next to its cell's shunt pair, Kelvin traces from the 10R split"). The carrier TME block (see
`carrier_tme.py` `BLOCKS[1]`) shows the pattern that finally routed: 25.4 mm part spacing, explicit
global labels for every internal net, and `"wired": {...}` + tags for rails whose pins are 2.54 mm
apart. Also note `gen_sch` writes `build/<board>_bad.kicad_sch` and prints the clash list on failure —
use it as the oracle instead of guessing.

## PCB constraints for T5.2 (from the plan, all still relevant)

- 96 x 90 mm, holders on the bottom, SMD on top, unchanged outline and holes. The four 18650 holders
  cover roughly x 8-85 in each cell band, so **only x < 8 and x > 85 are holder-free**.
- `J_USB1` (GCT USB4085, through-hole) must not sit over a holder and keeps its board-edge position
  (`_STRIP["J_USB1"] = (90, 23, 90)`). Its footprint has **no NPTH** and 0.4 mm signal drills, so
  `PTH_COMPONENT_MIN` must be lowered to 0.4 and the USB shell entries must be dropped from
  `NPTH_EXPECT`. The committed `pack_tme.py` already does this.
- The BQ25601 hand-solder footprint is 1.2 mm larger; nothing within 1 mm of its pad ends, and its
  back-side exposed-pad hole must not be under a holder (it is soldered from the back). The right strip
  (`x > 85`) is the only holder-free place big enough for the 7.7 mm footprint; the left margin is only
  8 mm wide. The committed `pack_tme.py` moves `U_CHG` to `(90, 36)` and the THT tact switches to
  `(4, 58)`/`(4, 66)` for this reason.
- `BOTTOM = {BT1..4, TH1..4}` (holders and bead NTCs are bottom-side).

## Not started: T6.1 and T6.2

- **T6.1** `power_budget.py --tme`: L072 Stop current (Table 37: 0.43 uA typ; features list: 0.86 uA
  Stop + RTC + 20 KB retention), 4x INA228 (2.8 uA typ shutdown), PCM5100A standby (0.5 mA typ) +
  PAM8302A shutdown instead of the NS4168. Must still pass the weekend target.
- **T6.2** add `$(MAKE) BOARD=carrier_tme|pack_tme|lipo_tme all` to the Makefile `boards:` target,
  update the design doc status (built; deviations), and add the "TME hand-build" section to
  `hardware/fab/ORDERING.md` (order bare PCBs only; TME Quick Buy from `tme_bom.csv`; hand-solder notes
  for the QFN; LCSC-only parts: holders and bead NTCs). Run `make boards` (seven boards) and the
  Conventions check.

## Rulings and decisions (all carried in the ledger, with their cost)

- **R_INP = R_INN = 240 k** (carrier amp gain). PAM8302A differential gain is
  `20 log(150k / (10k + R_IN))`; the DAC's full-scale differential is 2 x 2.1 Vrms = 4.2 Vrms, the BTL
  swing at VDD 3.6 V is ~2.55 Vrms, so the gain must be <= 0.607 -> R_IN >= 237 k. TME symbol
  `SMD0805-240K-1%`.
- **Tact switch = Omron B3F-1000** (6x6 mm THT, 4.5x6.5 mm pitch), which matches
  `Button_Switch_THT:SW_PUSH_6mm`. The plan named no symbol.
- **L1 = Bourns SRN6045-4R7Y** (TME `SRN60454R7Y-BOU-0`, Isat 4 A) on the existing `LRN6045`
  footprint; the plan's guess `SRN6045TA-4R7M` is not in the TME catalogue.
- **lipo_tme keeps `NOT_ASSEMBLED`** (the plan said `set()`). `gen_sch` marks the `TestPoint`/
  `SolderWire` symbols `in_bom=no` from the library and `gen_pcb` only honours `DNP|NOT_ASSEMBLED`, so
  an empty set produced 7 `footprint_symbol_mismatch` parity errors. Same applies to pack_tme, which
  keeps variant A's set minus `TH_CHG` (now bought at TME).
- **`tme.py` imports `board` as a module** and reads `board.design` inside `main()`; the form-import
  ran during `board`'s own import and cycled.
- **Carrier amp block** (this one took many iterations; read `carrier_tme.py` before touching it):
  every DAC/amp net has an explicit global label, `+3V3`/`GND` are `"wired"` in that block (the DAC's
  three supply pins are 2.54 mm apart and cannot each take a power port - `port_comb` only combines
  horizontally facing pins), the block sits at `(403.86, 12.7)`, and the 17 new parts' reference text is
  hidden. PCB: DAC/amp passives were placed with a courtyard-and-silk free-space search, 6-22 mm from
  `U_AMP`.
- **lipo_tme C_MCU3/C_VDDA sit ~11 mm from U_MCU** (the LQFP-32 corner is fully occupied), found by the
  same free-space search.
- **`pack_tme` adds only C_MON3/C_MON4**: the plan re-added C_MON1/C_MON2 that variant A already wires
  (caught by `check_structure`'s duplicate-pin rule).
- **QFN paste apertures over the exposed pad are kept** (`pcbnew.FootprintRemove`/`Remove` segfaults,
  and F.Paste is unused without a stencil). **`FootprintSave` returns `None`** in this SWIG build, so
  `handsolder_qfn.build()` asserts the file is non-empty instead.
- **TME stock**: INA228AIDGSR and PCM5100APWR showed 0 in stock on 2026-10-02 and the USB4085 16346.
  Stock is checked at order time (per the design doc).

## Environment gotchas (save yourself the time)

- **TME blocks curl (HTTP 403)** and its search page is JS-rendered, so neither curl nor a plain fetch
  sees results. What worked: `tme.eu` product-detail pages are indexed by Exa, so a
  `web_search` with `domainFilter: ["tme.eu"]` returns pages that show the `TME Symbol:` field. The
  product URL shape is `https://www.tme.eu/en/details/<symbol-lower>/...`. Single `fetch_content` calls
  on detail URLs also work but rate-limit (HTTP 429) after a couple.
- **st.com is unreachable**; use a datasheet mirror or the vendor page. TI/Diodes/Microchip PDFs fetch
  fine with curl and `pdftotext -layout` greps.
- **`gen_sch` layout rules** that cost the most time: `name_label` needs a straight run >= the label
  length with free cells on both sides (short internal nets fail), `rail_ports` gives each pin its own
  power port unless the pins face the same side and are 2 cells apart (`port_comb`), and every part must
  be in exactly one block, inside that block's rectangle. Tags are claimed before routing and must land
  on free grid cells. `STEP` is 1.27 mm.
- The pi-lens hook blocks edits that leave unguarded `open()` or unsorted imports; `ruff check <file>`
  is the repo's linter and is clean on all the committed files. `pcbnew` and local sibling imports need
  `# pyright: ignore[reportMissingImports]`.
- `make BOARD=lipo_tme all` and `make BOARD=carrier_tme all` take a few minutes each (freerouting).

## Suggested next steps, in order

1. Rebuild the pack `BLOCKS`/`PLACE` for the L072 + four INA228s (one INA228 per cell block is the
   most promising), get `make BOARD=pack_tme all` green, commit T5.2.
2. T6.1 (`power_budget.py --tme`), then T6.2 (`boards:` target, design doc status, `ORDERING.md`), then
   `make boards` for all seven.
3. Before ordering: print `fab/<board>_tme/print_1to1.pdf` and check the THT USB-C, the tact switches
   and the BQ25601 footprint with an iron tip (the design doc's Verification section).
4. Delete the plan workspace (`.superpowers/sdd/2026-10-02-tme-hand-build-implementation/`) once the
   final review is clean.

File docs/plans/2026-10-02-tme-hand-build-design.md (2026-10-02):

# TME hand-build variants: carrier, pack A, LiPo (design)

Date: 2026-10-02. Status: built (T0-T6); the three boards pass `make boards`. Layout deviations are
recorded at the end of "Changes against this design".

## Goal

A second version of the carrier, pack A (MCU) and LiPo boards that can be built **by hand with
an iron only** from parts **TME (tme.eu) stocks**. JLCPCB makes bare PCBs; nothing is machine-placed.
The JLC-assembled originals (`design.py`, `pack.py`, `pack_b.py`, `lipo.py`) and their fab files stay
as they are. Pack B gets no TME version (not requested).

## Why the parts change

`hardware/tme.py` (commit cf7939c) maps the JLC BOMs to TME. Not at TME: STM32C071KBT6 (pack A,
LiPo), MT3608 (pack A), NS4168 (carrier), TS-1088 (pack A). Not iron-solderable: BQ25601 (QFN-24)
and PAC1934 (UQFN-16), both with exposed pads.

## Structure

- New board modules `carrier_tme.py`, `pack_tme.py`, `lipo_tme.py`. Each imports its original and edits
  PARTS/NETS/placement, the same way `pack_b.py` derives from `pack.py`. `board.py` and the Makefile learn
  `BOARD=carrier_tme|pack_tme|lipo_tme`; outputs go to `hardware/fab/<board>/`.
- Each module carries a `TME` table `(value, footprint) -> TME symbol` instead of `LCSC`, and `assembled()`
  returns no parts. `board.check_structure` requires every non-mechanical part to have a TME symbol when
  the module has a `TME` table (and keeps the LCSC rule for the JLC boards).
- `make fab` for a TME board writes the Gerber zip, `tme_bom.csv` (TME Quick Buy `symbol;qty`, straight
  from the module's TME table), the schematic PDF, renders and the 1:1 print. No JLC BOM/CPL.

## Part changes

Approved chip set (all found in the TME catalogue on 2026-10-02):

| Block | JLC version | TME hand-build version |
|---|---|---|
| MCU, pack A + LiPo | STM32C071KBT6 (LQFP-32) | **STM32L072KZT6** (LQFP-32): crystal-less USB on PA11/PA12, I2C1 (PB6/PB7, internal master) + I2C3 (PA8/PB4, carrier link slave), ADC on PA0-PA7/PB0/PB1, Stop ~0.4 uA (C071: ~85 uA) |
| Cell monitor, pack A | PAC1934 (UQFN-16) | **4x INA228AIDGSR** (VSSOP-10): 20-bit, on-chip energy + charge accumulators, addresses 0x40-0x43 by A0/A1, ALERTs open-drain wired together to one MCU EXTI |
| Charger, pack A | BQ25601RTWR | **BQ25601RTWT** (same die, TME), on an iron footprint: pads extended ~0.6 mm beyond the body for drag soldering, 1.5 mm plated hole under the exposed pad soldered from the back. Keeps power path, I2C 0x6B, defaults, TS. |
| USB-C, pack A | HCTL HC-TYPE-C-16P-01A (SMD) | **GCT USB4085-GF-A** (through-hole, USB 2.0) |
| Boost, pack A | MT3608 | **MCP1640T-I/CHY** (SOT-23-6, true output disconnect); FB divider for 1.21 V reference |
| BOOT/RESET buttons, pack A | TS-1088 (SMD 3.9x3) | THT 6x6 mm tact switches |
| Charger NTC TH_CHG, pack A | CMFB 0805 (hand) | **Vishay NTCS0603E3103FLT** (10k B3435 1 %, 0603 on 0805 pads) |
| Audio, carrier | NS4168 (eSOP-8, I2S class-D) | **PCM5100APWR** (TSSOP-20 I2S DAC on +3V3, PLL from BCK, no MCLK) + **PAM8302AADCR** (SO-8 class-D on VBAT_SW), DAC L/R driven in antiphase into the amp's differential input, 240 k input resistors set the gain; expander AMP_SD drives the amp SD and the DAC XSMT. Firmware stays I2S. |
| LDO, LiPo | HT7533-1 (SOT-89, 30 V) | **AP7381-33SA-7** (SOT-23, 40 V, pin order 1 VI / 2 VO / 3 GND) |

Everything else maps 1:1 through the `tme.py` table (the substitutes there: Kingbright LEDs,
1N5819HW-7-F, ERJ8BWFR010V shunts, DFE322520FD-1R5M inductor, ZL262-18SG sockets, 1206L200PR PTC).
All packages are leaded or chip passives; the BQ25601 is the one exposed-pad QFN and gets the iron
footprint.

Rejected: LTC4002 leaded charger (no power path, no I2C control), Charger 6 Click module MIKROE-4576
(same BQ25601 but 62 PLN, out of stock, bulky), STM32G0B1KBT6 (higher Stop current), STM32C031K6T6
(no I2C2/USB), INA219 (12-bit, no accumulator), PDM-to-RC audio (firmware change, weaker), MCP1703AT
(18 V abs max under the 24 V TVS clamp).

## Changes against this design (from the implementation plan)

- LiPo LDO is the SOT-23 **AP7381-33SA-7**, not the SOT-89 AP7381-33Y-13: KiCad has a symbol only for
  the SOT-23 one, TME stocks it, and the LDO carries only the MCU (mA). Pinout 1 VI, 2 VO, 3 GND.
- Amp is **PAM8302AADCR** (SO-8), not AASCR: AAD is the 1.27 mm SOP-8, AAS the 0.65 mm MSOP-8.
- The carrier link uses **I2C1 (PB6/PB7)** on both boards; the pack's internal bus uses **I2C3
  (PA8/PB4)**. I2C1 is the port the ROM bootloader listens on, so the Heltec could flash a pack or
  LiPo MCU over the cable later.
- **PCM5100A XSMT sits on AMP_SD**: the expander line that enables the amp also unmutes the DAC.
- **MCP1640 needs no catch diode** (synchronous): `D1` goes. FB divider 75k/24k -> 1.21 V x 4.125 = 4.99 V.
- Amp input resistors **R_INP = R_INN = 240 k** (see Parts below for the arithmetic).

## Layout deviations (from the T5.2 build)

- **One INA228 per cell block** (schematic), beside that cell's 10R Kelvin split, instead of four in
  the PAC1934's monitor block: four long sense routes disappear and the four monitors stop crowding
  one block. The monitor block keeps only the diode-OR and the 3V3 LDO.
- **`+5V` drops out of the 0.8 mm Power net class** (0.25 mm Default): the MCP1640's VOUT is a
  0.95 mm-pitch SOT-23 pad that cannot take a 0.8 mm track, and the rail's peak is 82 mA. `VBAT_SW`
  stays 0.8 mm.
- **Default clearance 0.15 mm** (was 0.2) on pack_tme: the USB4085's own through-hole pads sit
  0.15 mm apart. JLCPCB's 2-layer minimum is 0.127 mm.
- **The hand-solder QFN's pin-1 silk marker moves to F.Fab**: the extended pads cover it, so the
  marker is printed (F.Fab is in the 1:1 print) instead of clipped by solder mask.
- **Pack placement**: `U_CHG` moves to the holder-free right strip (its exposed pad is filled from
  the back), `J_USB1` pulls in to x 87 so its silk clears the board edge, the THT tact switches sit
  in the left holder-free strip (x 1.6, rotated) and `J_PWR1`/`J_KEY1` shift down to make room.

## Parts (verified 2026-10-02)

Datasheets read on 2026-10-02; TME symbols checked against tme.eu product pages the same day. Stock is
not reserved: it is checked at order time.

- **STM32L072KZT6** (DS10690 Rev3 `stm32l072kz.pdf`, AN2606, RM0367). LQFP-32 7x7 mm; the pin table
  matches the KiCad symbol `MCU_ST_STM32L0:STM32L072KZTx`: 1 VDD, 4 NRST, 5 VDDA, 16/32 VSS, 17 VDD,
  21 PA11/USB_DM, 22 PA12/USB_DP, 18 PA8/I2C3_SCL, 27 PB4/I2C3_SDA, 29 PB6/I2C1_SCL, 30 PB7/I2C1_SDA,
  31 BOOT0 (dedicated pin). USB is crystal-less: HSI48 trimmed by the CRS from the USB SOF signal
  (S3.17.5, S3.18), so no crystal on PA11/PA12. Stop mode IDD 0.43 uA typ / 1.00 uA max at -40..25 C
  (Table 37); the features list gives 0.86 uA typ for Stop + RTC + 20 KB RAM retention. NRST has an
  internal filter and takes a 100 nF external cap (Figure 29). Decoupling: 100 nF per VDD pin plus
  100 nF + 1 uF on VDDA/VREF+ and a bulk cap (Figures 32/33). BOOT0 (pin 31) pull-down 10k keeps the
  main-flash boot. Bootloader: AN2606's STM32L0 table (and ST community reports for L071) give I2C1 on
  PB6/PB7 and USB DFU on PA11/PA12 for LQFP-32; the I2C slave address is set by the master, no hardware
  change (the AN3154/AN4221 protocol is firmware-side, out of scope).
- **INA228AIDGSR** (SBOSA20 `ina228.pdf`). VSSOP-10, 20-bit, on-chip energy and charge accumulators,
  open-drain active-low ALERT, I2C. Address pins A1/A0 (Table 7-2): GND/GND 0x40, GND/VS 0x41,
  GND/SDA 0x42, GND/SCL 0x43 -> cells 1-4 = A1 GND, A0 = GND / +3V3 / SDA_INT / SCL_INT. Shunt full
  scale ADCRANGE=0 is +-163.84 mV = 312.5 nV/LSB, so the 10 mOhm shunt spans +-16 A. Input filtering:
  series R should stay <= 100 Ohm; the datasheet says 10 Ohm in series already protects the inputs up
  to the 40 V differential limit (S8.1.4), so the 10 R split is kept. Shutdown quiescent current 2.8 uA
  typ / 5 uA max; VBUS pin impedance 1 MOhm active, 10 nA leakage in shutdown.
- **PCM5100APWR** (SLAS859C `pcm5100a.pdf`). TSSOP-20, 3.0-3.6 V only on AVDD/CPVDD/DVDD, 2.1 Vrms
  ground-centered line output. Tying SCK to AGND selects the internal PLL clocked from BCK (S9.1,
  Figure 33), i.e. 3-wire I2S, no MCLK. Straps: FMT low = I2S, FLT low = normal latency, DEMP low =
  de-emphasis off; XSMT low = soft mute, high = unmute (tie to AVDD if unused; here AMP_SD). Caps from
  Figure 33: CAPP-CAPM flying cap 2.2 uF, VNEG 2.2 uF, LDOO 0.1 uF, each supply 0.1 uF + 10 uF. Output
  filter 470 R + 2.2 nF to GND (the output load spec assumes 10 kOhm). Standby current with clocks
  stopped: DVDD 3.3 V 0.5 mA typ / 0.8 mA max; the part auto power-downs after BCK/LRCK are low > 1 s
  (S11.5.2).
- **PAM8302AADCR** (DS36130 `pam8302a.pdf`). AAD = SO-8 (1.27 mm), AAS = MSOP-8 (0.65 mm); we use the
  SO-8. Differential gain A = 20 log(150k / (10k + R_IN)): internal R_F = 150 k, R_I = 10 k, so the bare
  part is 23.5 dB and an external R_IN in series at the input pin lowers it. Sizing: the DAC full-scale
  differential signal is 2 x 2.1 Vrms = 4.2 Vrms; the BTL output at VDD 3.6 V can swing about 7.2 Vpp =
  2.55 Vrms, so the gain must be <= 2.55 / 4.2 = 0.607. R_IN >= 150k / 0.607 - 10k = 237 k ->
  **R_INP = R_INN = 240 k** (gain 0.60, 2.52 Vrms out, just under clipping). C_INP/C_INN = 1 uF gives a
  high-pass corner of 1 / (2 pi 250k 1u) = 0.64 Hz. SD: logic low shuts the amp down; V_IH >= 1.2 V,
  V_IL <= 0.4 V, so the 3.3 V expander line drives it directly through the existing 1 k. ISHDN <= 1 uA,
  quiescent 4 mA typ / 8 mA max no-load. VDD 2.0-5.5 V (VBAT_SW about 4.1 V).
- **MCP1640T-I/CHY** (DS20002234 `mcp1640.pdf`). SOT-23-6, V_FB = 1.21 V (1.175/1.21/1.245). Maximum
  output current 350 mA at VIN 3.3 V / VOUT 5.0 V, so the 82 mA +5V peak from `power_budget.py` has more
  than 4x margin. Recommended L = 4.7 uH, C_IN = C_OUT = 10 uF. EN is high above 90 % of VIN, so EN is
  tied to VBAT_SW. The base MCP1640 (no B/C/D suffix) has true output disconnect, so no catch diode.
  L1 becomes a 4.7 uH/2 A part on the existing LRN6045 (6x6 mm) footprint: L peak is well under 1 A, and
  the TME-confirmed SRN6045-4R7Y has Isat 4 A. FB divider 75k/24k -> 1.21 x (1 + 75/24) = 4.99 V.
- **AP7381-33SA-7** (DS39917 `ap7381.pdf`). SOT-23 pin descriptions: 1 VIN, 2 VOUT, 3 GND; this matches
  KiCad's `Regulator_Linear:AP7381-33SA-7` (extends AP7381-28SA-7: 1 VI, 2 VO, 3 GND). VIN 3.3-40 V
  (abs max 45 V); the LiPo VIN is 6.0-12.6 V. Dropout 1000 mV at 100 mA / 3.3 V, so VIN >= 4.3 V at
  100 mA and the 6.0 V floor leaves 1.7 V. Ground current 2.5 uA at 0 A / 25 uA at 100 mA, and the load
  is the MCU only (mA). C_IN 1 uF / C_OUT 2.2 uF typical, low-ESR ceramic compatible, so the 10 uF in
  and out is inside the stable range.
- **BQ25601 RTW land pattern** (SLUSD90 `bq25601.pdf`). WQFN-24 (RTW) 4 x 4 mm x 0.75 mm, 0.5 mm pitch,
  exposed pad 2.6 x 2.6 mm (generic package view 4224801). KiCad's
  `Package_DFN_QFN:QFN-24-1EP_4x4mm_P0.5mm_EP2.6x2.6mm` encodes the land pattern: numbered pads
  0.25 mm wide x 0.825 mm long on 0.5 mm pitch, E pad 2.6 x 2.6 mm. T2.1 extends each numbered pad
  0.6 mm outward and drills a 1.5 mm plated hole through the E pad.

### TME symbols (new parts and values, checked 2026-10-02)

| part / value | TME symbol |
|---|---|
| STM32L072KZT6 | `STM32L072KZT6` |
| INA228AIDGSR | `INA228AIDGSR` |
| PCM5100APWR | `PCM5100APWR` |
| PAM8302AADCR | `PAM8302AADCR` |
| MCP1640T-I/CHY | `MCP1640T-I/CHY` |
| AP7381-33SA-7 | `AP7381-33SA-7` |
| USB4085-GF-A | `USB4085-GF-A` |
| TACT 6x6 (Omron B3F-1000, 4.5x6.5 mm pitch) | `B3F-1000` |
| 24k 0805 | `0805W8F2402T5E` |
| 240k 0805 | `SMD0805-240K-1%` |
| 470R 0805 | `0805W8F4700T5E` |
| 2.2 nF 0805 | `CC0805KRX7R9BB222` |
| 2.2 uF 0805 | `CL21A225KAFNNNE` |
| 1 uF 0805 | `CL21B105KBFNNNE` |
| 10k NTC 0603 | `NTCS0603E3103FLT` |
| 4.7 uH 6x6 | `SRN60454R7Y-BOU-0` |

Every other part maps 1:1 through the `tme.py` table (Kingbright LEDs, 1N5819HW-7-F, ERJ8BWFR010V
shunts, DFE322520FD-1R5M inductor, ZL262-18SG sockets, 1206L200PR PTC).

## Verification

- `make BOARD=<board>_tme all` per board: design check, netlist parity, ERC, DRC (schematic parity),
  Gerber check, TME BOM written.
- Each module's self-check (`/usr/bin/python3 <board>_tme.py`), including pin-role checks like the
  originals (USB on PA11/PA12, I2C ports, ADC pins, INA228 addresses distinct).
- `power_budget.py`: L072 Stop current, 4x INA228, PCM5100A standby; the weekend target must still pass.
- Before ordering: 1:1 print fit check of the THT USB-C, tact switches and the BQ25601 footprint.

## Firmware impact (deferred, noted for the C-tasks)

Pack and LiPo firmware target STM32L072 instead of STM32C071 (embassy-stm32 supports both); the pack
reads four INA228s on I2C3 instead of one PAC1934; the carrier/pack link moves to I2C1 (PB6/PB7) on both
boards. Carrier audio stays I2S; the amp enable stays on the expander. The DAC L/R are driven in
antiphase (the firmware sends the right channel inverted, R = -L) so the amp sees a differential signal;
XSMT is on the same AMP_SD line, so enabling the amp also unmutes the DAC.

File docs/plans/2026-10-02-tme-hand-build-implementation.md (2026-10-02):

# TME Hand-Build Boards Implementation Plan

> **For Claude:** REQUIRED SUB-SKILL: Use superpowers:executing-plans to implement this plan task-by-task.

**Goal:** Iron-solderable, TME-sourced versions of the carrier, pack A and LiPo boards
(`hardware/{carrier,pack,lipo}_tme.*`, `hardware/fab/<board>_tme/`), generated by the same flow as the JLC
boards, as specified in `docs/plans/2026-10-02-tme-hand-build-design.md`. Firmware is out of scope.

**Architecture:** Three new board modules derive from the originals by import and edit, exactly like
`pack_b.py` derives from `pack.py`. Each carries a `TME` table `(value, footprint) -> TME symbol` instead
of `LCSC` and an empty `assembled()` (nothing is machine-placed). `board.check_structure` gains the TME
rule; the Makefile skips `jlc.py` for `*_tme` boards and `tme.py` writes their Quick Buy list straight
from the module. One project footprint is new: the BQ25601 QFN-24 with iron-friendly pads.

**Tech stack:** Python 3 (`/usr/bin/python3`, needed for `pcbnew`), KiCad 9 (`kicad-cli`, pcbnew API),
Freerouting 2.4.1 (`hardware/tools/`), GNU make. TME catalogue lookups through WebFetch.

**Conventions (read before starting):**
- Run everything from `hardware/`. Use `/usr/bin/python3`. `rtk` rewrites output; use plain `make`,
  `/usr/bin/grep -F`, `diff` when you need exact output.
- TME blocks curl (HTTP 403). Look symbols up with WebFetch on
  `https://www.tme.eu/pl/katalog/?queryPhrase=<part>` (the `/en/` path rate-limits sooner; URL-encode `/`
  as `%2F`). Every new TME symbol gets a comment `# <maker part>, <what it is> (TME 2026-10-xx)`.
- The originals (`design.py`, `pack.py`, `pack_b.py`, `lipo.py`) and their `fab/` output must not change,
  except the two small refactors named in T1.2 and T3.1. After every task run
  `for b in carrier pack pack_b lipo; do BOARD=$b /usr/bin/python3 -c "from board import design; design.check()"; done`.
- Commit after every task; end messages with the attribution line in use for this repo.
- Pin numbers below come from the KiCad 9 symbols, read 2026-10-02:
  - `MCU_ST_STM32L0:STM32L072KZTx` (LQFP-32): 1 VDD, 2 PC14, 3 PC15, 4 NRST, 5 VDDA, 6-13 PA0-PA7,
    14 PB0, 15 PB1, 16 VSS, 17 VDD, 18 PA8 (I2C3_SCL), 19 PA9, 20 PA10, 21 PA11 (USB_DM), 22 PA12 (USB_DP),
    23 PA13 (SWDIO), 24 PA14 (SWCLK), 25 PA15, 26 PB3, 27 PB4 (I2C3_SDA), 28 PB5, 29 PB6 (I2C1_SCL),
    30 PB7 (I2C1_SDA), 31 BOOT0 (dedicated pin, unlike the C071), 32 VSS.
  - `Sensor_Energy:INA228` (VSSOP-10): 1 A1, 2 A0, 3 ALERT, 4 SDA, 5 SCL, 6 VS, 7 GND, 8 VBUS, 9 IN-, 10 IN+.
  - `Audio:PCM5100A` (TSSOP-20): 1 CPVDD, 2 CAPP, 3 CPGND, 4 CAPM, 5 VNEG, 6 OUTL, 7 OUTR, 8 AVDD, 9 AGND,
    10 DEMP, 11 FLT, 12 SCK, 13 BCK, 14 DIN, 15 LRCK, 16 FMT, 17 XSMT, 18 LDOO, 19 DGND, 20 DVDD.
  - `Amplifier_Audio:PAM8302AAD` (SOP-8): 1 SD, 2 NC, 3 IN+, 4 IN-, 5 OUT+, 6 VDD, 7 GND, 8 OUT-.
  - `Regulator_Switching:MCP1640x-xCHY` (SOT-23-6): 1 SW, 2 GND, 3 EN, 4 VFB, 5 VOUT, 6 VIN.
  - `Regulator_Linear:AP7381-33SA-7` (SOT-23): 1 VI, 2 VO, 3 GND.
  - `Connector_USB:USB_C_Receptacle_GCT_USB4085` has the same pad names as the HCTL part (A1..B12, S1),
    so the USB nets carry over unchanged.

## Changes against the design doc (record them in it in T0.1)

- **LiPo LDO is the SOT-23 AP7381-33SA-7**, not the SOT-89 AP7381-33Y-13: KiCad has a symbol only for the
  SOT-23 one, TME stocks it, and the LDO carries only the MCU (mA). Pinout 1 VI, 2 VO, 3 GND.
- **Amp is PAM8302AADCR (SOP-8)**, not AASCR: AAD is the 1.27 mm SOP-8, AAS the 0.65 mm MSOP-8. Confirm in T0.1.
- **The carrier link uses I2C1 (PB6/PB7) on both boards; the pack's internal bus uses I2C3 (PA8/PB4).**
  I2C1 is the port the ROM bootloader listens on (confirm in AN2606), so the Heltec could flash a pack or
  LiPo MCU over the cable later.
- **PCM5100A XSMT sits on AMP_SD**: the expander line that enables the amp also unmutes the DAC.
- **MCP1640 needs no catch diode** (synchronous): `D1` goes. FB divider 75k/24k -> 1.21 V x 4.125 = 4.99 V.

---

## Phase T0: part facts (gates everything)

### Task T0.1: Verify datasheet facts, record them in the design doc

No code. Output: a "Parts" section appended to `docs/plans/2026-10-02-tme-hand-build-design.md` (one row per
item: decision, source section/table, date), the changes above recorded, and the "Facts to confirm" list
replaced by the results. Check:

1. **STM32L072KZT6** (DS10690, AN2606, RM0367): bootloader interfaces and the I2C1 address and pins; USB
   DFU on PA11/PA12 without a crystal (CRS); BOOT0 pin behaviour with a 10k pull-down; Stop current with
   RTC; VDDA tied to VDD with 100 nF + 1 uF; NRST 100 nF.
2. **INA228** (SBOSA20): A1/A0 address table (expect GND/GND 0x40, GND/VS 0x41, GND/SDA 0x42, GND/SCL 0x43),
   ALERT open drain, IN+/IN- series resistor limit (the board has 10R), shunt range at ADCRANGE=0
   (+-163.84 mV; 10 mOhm -> +-16 A), VBUS input impedance, shutdown current.
3. **PCM5100A** (SLASE12): SCK tied low = PLL from BCK; FMT/FLT/DEMP straps for I2S, normal filter, no
   de-emphasis; XSMT high = unmute; capacitor values for CAPP-CAPM, VNEG, LDOO, and supply decoupling; full
   scale 2.1 Vrms; standby current with BCK stopped; recommended output RC (470R + 2.2 nF).
4. **PAM8302A** (DS36130): package code per suffix (AAD = SOP-8?), gain formula against the input resistor,
   SD threshold (driven from 3.3 V logic through 1k), VDD 2.0-5.5 V, quiescent and shutdown current.
   Pick R_INP/R_INN so a full-scale differential DAC signal (2 x 2.1 Vrms) does not clip the amp at
   VDD 3.6 V; record the arithmetic.
5. **MCP1640** (DS20002234): VFB 1.21 V; output current at VIN 3.0 V / VOUT 5.0 V (must cover the 82 mA
   +5V peak from `power_budget.py`); recommended inductor (expect 4.7 uH) and its saturation current;
   output capacitance; EN threshold with EN tied to VIN.
6. **AP7381-33SA-7**: input range, dropout at 100 mA, quiescent current, output capacitor range (the board
   has 10 uF in and out).
7. **BQ25601 RTW land pattern** (SLUSD90, mechanical section): pad size and pitch, so T2.1's extension is
   measured from the right edge; exposed pad 2.6-2.7 mm.
8. **TME symbols** for every part new in this plan, plus values not yet in `tme.py`: STM32L072KZT6,
   INA228AIDGSR, PCM5100APWR, PAM8302AADCR, MCP1640T-I/CHY, AP7381-33SA-7, USB4085-GF-A, a THT 6x6 mm
   tact switch (`SW_PUSH_6mm` footprint), 24k 0805 (`0805W8F2402T5E`), 470R 0805 (`0805W8F4700T5E`),
   2.2 nF / 1 uF / 2.2 uF 0805 MLCCs, the 4.7 uH inductor (if T0.1 #5 changes it; `SRN6045TA-4R7M`?),
   and the 1k/10k already in `tme.py`.

Commit: `docs: TME hand-build part facts`.

---

## Phase T1: flow support

### Task T1.1: `check_structure` knows TME boards (test first)

**Files:** Modify `hardware/board.py`.

**Step 1: failing check.** Add to the end of `check_structure(m)`:

```python
    if hasattr(m, "TME"):
        # Hand-built board: nothing machine-placed, every bought part has a TME symbol.
        assert not m.LCSC and not m.assembled(), "TME board must have no LCSC parts / placements"
        bought = {(v, fp) for r, (v, sym, fp) in m.PARTS.items()
                  if sym != "Mechanical:MountingHole" and r not in m.DNP | m.NOT_TME}
        missing = sorted(k for k in bought if k not in m.TME)
        assert not missing, f"parts without a TME symbol: {missing}"
        stale = m.TME.keys() - bought
        assert not stale, f"TME entries no part uses: {stale}"
```

**Step 2:** run the four existing board checks (Conventions). Expected: all `ok` (no module has `TME`).

**Step 3: commit** `hw: board.check_structure checks TME tables`.

### Task T1.2: `tme.py` writes the list for a TME board

**Files:** Modify `hardware/tme.py`.

In `main()`, before the `jlc_bom*.csv` loop:

```python
    board_name = os.environ.get("BOARD", "")
    if board_name.endswith("_tme"):
        sys.path.insert(0, str(HERE))
        from board import design  # pyright: ignore[reportMissingImports]
        qty = {}
        for r, (v, sym, fp) in design.PARTS.items():
            if sym != "Mechanical:MountingHole" and r not in design.DNP | design.NOT_TME:
                qty[design.TME[(v, fp)]] = qty.get(design.TME[(v, fp)], 0) + boards
        (FAB / "tme_bom.csv").write_text("".join(f"{s};{n}\n" for s, n in sorted(qty.items())))
        print(f"tme ok ({board_name}): {len(qty)} TME lines")
        return
```

Also export a helper the modules use to reuse the existing LCSC -> TME mapping (DRY):

```python
def from_lcsc(lcsc_table, keys):
    """TME symbols for the (value, footprint) keys a JLC module already maps to LCSC numbers."""
    return {k: TME[lcsc_table[k]] for k in keys if k in lcsc_table and lcsc_table[k] in TME}
```

Run the four JLC boards' `FAB=... /usr/bin/python3 tme.py` (from the cf7939c commit message) and
`git diff --stat fab/`: expected no change. Commit `hw: tme.py writes TME-board lists`.

### Task T1.3: `board.py` and the Makefile know the `*_tme` boards

**Files:** Modify `hardware/board.py` (the module map), `hardware/Makefile`.

- `board.py`: add `"carrier_tme": "carrier_tme", "pack_tme": "pack_tme", "lipo_tme": "lipo_tme"` to the map.
- Makefile `fab`: wrap `$(PY) jlc.py` so it runs only for JLC boards:

  ```make
  ifeq ($(filter %_tme,$(BOARD)),)
  	$(PY) jlc.py
  endif
  	$(PY) tme.py
  ```

  and the `kicad-cli sch export bom` line stays (it reads the schematic, fine for both).
- `boards:` target: add `$(MAKE) BOARD=carrier_tme all`, `pack_tme`, `lipo_tme` lines (after T5).

No module exists yet, so there is no run here beyond `make -n BOARD=lipo_tme fab | /usr/bin/grep -c jlc.py`
(expected `0`) and `make -n BOARD=lipo fab | /usr/bin/grep -c jlc.py` (expected `1`). Commit.

---

## Phase T2: the iron-friendly BQ25601 footprint

### Task T2.1: Generate `local.pretty/QFN-24-1EP_4x4mm_P0.5mm_EP2.6x2.6mm_HandSolder`

**Files:** Create `hardware/tools/handsolder_qfn.py`, `hardware/local.pretty/QFN-24-1EP_4x4mm_P0.5mm_EP2.6x2.6mm_HandSolder.kicad_mod`.

The script loads KiCad's `Package_DFN_QFN:QFN-24-1EP_4x4mm_P0.5mm_EP2.6x2.6mm`, and with pcbnew:
- every numbered SMD pad 1-24: lengthen by `EXT = 0.6` mm **outward only** (grow the pad's long side by EXT
  and move its centre outward by EXT/2, away from the footprint origin along that side's normal);
- pad 25 (exposed): becomes a plated through-hole pad, rect 2.6 x 2.6 on F.Cu/B.Cu/masks, drill
  `HOLE = 1.5` mm, so the pad is soldered from the back through the hole; drop the paste layer;
- courtyard grown by EXT on all sides; description says how it is meant to be soldered;
- saved with `pcbnew.FootprintSave` into `local.pretty`.

Self-check in the script (`__main__`): reload the saved footprint and assert 24 SMD pads each `EXT` longer
than the source, pad 25 PTH with drill 1.5 mm, pad-to-pad gap between neighbours unchanged, and the
extended pads' outer edge ~0.6 mm beyond the original. Run `/usr/bin/python3 tools/handsolder_qfn.py`,
expected `handsolder_qfn ok`. Open it in the footprint viewer once and look. Commit both files.

---

## Phase T3: LiPo (smallest change, proves the flow)

### Task T3.1: Parametrise `lipo.check_power_path` (refactor, original stays green)

**Files:** Modify `hardware/lipo.py`.

Replace the two hard-coded spots with module constants so a derived module can reuse the check:

```python
LDO_VIN = "U_LDO.2"                      # HT75xx-1 SOT-89: 1 GND, 2 VIN, 3 VOUT
TAP_ADC_PIN = {1: "U_MCU.7", 2: "U_MCU.8", 3: "U_MCU.9"}

def check_power_path(m=None):
    """Input order and the EN wiring the latched cutoff depends on."""
    import sys
    m = m or sys.modules[__name__]
    net_of = {p: n for n, mem in m.NETS.items() for p in mem}
    ...
    for p in ("D_TVS1.1", "D_GZ1.1", "U_BA.3", "U_BB.3", m.LDO_VIN, "R_EN1.1"):
    ...
        assert net_of[m.TAP_ADC_PIN[i]] == f"TAP{i}_ADC", f"tap {i} not on its ADC pin"
```

Run `BOARD=lipo ... design.check()`: `lipo ok`. Commit `hw: lipo power-path check reads its pins from the module`.

### Task T3.2: `lipo_tme.py` (check first)

**Files:** Create `hardware/lipo_tme.py`.

**Step 1:** write the module header, `NAME = "lipo_tme"`, `TITLE`, and a `check()` that runs
`board.check_structure(this)`, `lipo.check_power_path(this)` and `check_mcu()`:

```python
def check_mcu():
    net_of = {p: n for n, m in NETS.items() for p in m}
    want = {"U_MCU.1": "+3V3", "U_MCU.17": "+3V3", "U_MCU.5": "+3V3", "U_MCU.16": "GND",
            "U_MCU.32": "GND", "U_MCU.4": "NRST", "U_MCU.31": "BOOT0", "U_MCU.23": "SWDIO",
            "U_MCU.24": "SWCLK", "U_MCU.29": "SCL_EXT", "U_MCU.30": "SDA_EXT",
            "U_LDO.1": "VIN", "U_LDO.2": "+3V3", "U_LDO.3": "GND"}
    for p, n in want.items():
        assert net_of.get(p) == n, f"{p} on {net_of.get(p)}, want {n}"
```

Run `/usr/bin/python3 lipo_tme.py`: expected FAIL (no PARTS yet).

**Step 2: data.** Import `lipo` and `tme`; copy and edit:

```python
LQFP32, SOT23 = lipo.LQFP32, lipo.SOT23
PARTS = dict(lipo.PARTS)
PARTS["U_MCU"] = ("STM32L072KZT6", "MCU_ST_STM32L0:STM32L072KZTx", LQFP32)
PARTS["U_LDO"] = ("AP7381-33SA-7", "Regulator_Linear:AP7381-33SA-7", SOT23)
PARTS["C_MCU3"] = ("100nF", *lipo.C0805)      # second VDD pin (17)
PARTS["C_VDDA"] = ("1uF", *lipo.C0805)        # VDDA (5); value per T0.1
PARTS["TP_BOOT0"] = ("BOOT0", "Connector:TestPoint", lipo.TP)
LDO_VIN = "U_LDO.1"
TAP_ADC_PIN = {1: "U_MCU.7", 2: "U_MCU.8", 3: "U_MCU.9"}   # PA1-PA3

NETS = {n: [p for p in m if not p.startswith(("U_MCU.", "U_LDO."))] for n, m in lipo.NETS.items()}
NETS["VIN"] += ["U_LDO.1"]
NETS["+3V3"] += ["U_LDO.2", "U_MCU.1", "U_MCU.17", "U_MCU.5", "C_MCU3.1", "C_VDDA.1"]
NETS["GND"] += ["U_LDO.3", "U_MCU.16", "U_MCU.32", "C_MCU3.2", "C_VDDA.2"]
NETS["NRST"] += ["U_MCU.4"]
NETS["BOOT0"] = ["U_MCU.31", "R_BOOT.1", "TP_BOOT0.1"]           # dedicated BOOT0 pin
NETS["SWCLK"] = ["U_MCU.24", "TP_SWCLK.1"]
NETS["SWDIO"] = ["U_MCU.23", "TP_SWDIO.1"]
NETS["SCL_EXT"] = ["U_MCU.29", "J_PWR1.6"]                       # I2C1, bootloader port
NETS["SDA_EXT"] = ["U_MCU.30", "J_PWR1.5"]
NETS["KILL_DRV"] = ["R_KILL.1", "U_MCU.14"]                      # PB0
for i in (1, 2, 3):
    NETS[f"TAP{i}_ADC"] += [TAP_ADC_PIN[i]]
NC_PINS = {f"U_MCU.{p}" for p in (2, 3, 6, 10, 11, 12, 13, 15, 18, 19, 20, 21, 22, 25, 26, 27, 28)}

DNP, NC_PARTS = set(lipo.DNP), set()
NOT_ASSEMBLED = set()
# Not bought at TME: test pads and the input pigtail's pads are copper only.
NOT_TME = {"J_IN1", "TP_SWDIO", "TP_SWCLK", "TP_NRST", "TP_3V3", "TP_GND", "TP_BOOT0"}
LCSC = {}
_KEYS = {(v, fp) for r, (v, _, fp) in PARTS.items() if r not in NOT_TME and fp != lipo.MH}
TME = tme.from_lcsc(lipo.LCSC, _KEYS)
TME |= {
    ("STM32L072KZT6", LQFP32): "STM32L072KZT6",
    ("AP7381-33SA-7", SOT23): "AP7381-33SA-7",
    ("1uF", lipo.C0805[1]): "CL21B105KBFNNNE",
}
MODULES, VARIANTS = {}, {"standard": set()}
def assembled(variant="standard"): return []
```

Keep every layout name (`BLOCKS`, `PLACE`, `REF_AT`, rules, `W/H`, ...) from `lipo` by assignment as
`pack_b.py` does; edit only what the parts above need (T3.3). Note `TP_SWCLK` was `SWCLK/BOOT0` on the C071:
set its value to `"SWCLK"`.

**Step 3:** `/usr/bin/python3 lipo_tme.py`: expected `lipo_tme ok: ...`. Fix until it passes (the usual
misses: a net left with one pin after the MCU pins were stripped, an NC pin also on a net). Commit.

### Task T3.3: LiPo schematic, PCB, fab

**Files:** Modify `hardware/lipo_tme.py` (BLOCKS/PLACE edits only).

1. `make BOARD=lipo_tme sch`: the MCU block takes the new symbol; add `C_MCU3`, `C_VDDA`, `TP_BOOT0` to the
   MCU block's `parts` (copy the block like `pack_b._copy_blocks`). ERC clean (`make BOARD=lipo_tme check`
   reports it).
2. Placement: the LQFP-32 is the same size; the AP7381 is a SOT-23 where the SOT-89 was. Put `C_MCU3`
   at the pin-17 side, `C_VDDA` at pin 5, `TP_BOOT0` next to the other test pads. Hand-solder clearance:
   keep 1 mm between parts so an iron tip fits.
3. `make BOARD=lipo_tme all`: green (ERC, DRC with schematic parity, Gerber check, `fab/lipo_tme/tme_bom.csv`).
4. Check the list: every line's symbol is in the T0.1 results; `wc -l fab/lipo_tme/tme_bom.csv` matches
   the distinct TME symbols.

Commit `hw: LiPo TME hand-build board`.

---

## Phase T4: carrier

### Task T4.1: `carrier_tme.py` with the DAC + amp (check first)

**Files:** Create `hardware/carrier_tme.py`.

**Step 1:** `check()` = `board.check_structure(this)` + the carrier's header checks (refactor nothing:
call `design.check`'s logic by copying its header-pin block into a `check_header(m)` here, reading `m`) +
`check_audio()`:

```python
def check_audio():
    net_of = {p: n for n, m in NETS.items() for p in m}
    want = {"U_DAC.13": "I2S_BCLK", "U_DAC.15": "I2S_LRCLK", "U_DAC.14": "I2S_DIN",
            "U_DAC.17": "AMP_SD", "U_DAC.12": "GND", "U_DAC.16": "GND", "U_DAC.11": "GND",
            "U_DAC.10": "GND", "U_DAC.1": "+3V3", "U_DAC.8": "+3V3", "U_DAC.20": "+3V3",
            "U_AMP.1": "AMP_SD_R", "U_AMP.6": "VBAT_SW", "U_AMP.7": "GND",
            "U_AMP.5": "SPK_P", "U_AMP.8": "SPK_N"}
    for p, n in want.items():
        assert net_of.get(p) == n, f"{p} on {net_of.get(p)}, want {n}"
    assert "U3" not in PARTS
```

Run: FAIL. **Step 2: data**, from `design` (`import design, tme`):

```python
TSSOP20 = "Package_SO:TSSOP-20_4.4x6.5mm_P0.65mm"
SOIC8 = "Package_SO:SOIC-8_3.9x4.9mm_P1.27mm"
C0805, R0805 = design.C0805, design.R0805
PARTS = {r: v for r, v in design.PARTS.items() if r != "U3"}
PARTS |= {
    "U_DAC": ("PCM5100APWR", "Audio:PCM5100A", TSSOP20),
    "C_DCP": ("2.2uF", *C0805),    # CAPP-CAPM flying cap       (values per T0.1 #3)
    "C_DNEG": ("2.2uF", *C0805),   # VNEG
    "C_DLDO": ("100nF", *C0805),   # LDOO
    "C_DVDD": ("100nF", *C0805), "C_DAVDD": ("100nF", *C0805), "C_DCPV": ("100nF", *C0805),
    "C_DBULK": ("10uF", *C0805),
    "R_OL": ("470R", *R0805), "C_OL": ("2.2nF", *C0805),    # DAC output RC, left
    "R_OR": ("470R", *R0805), "C_OR": ("2.2nF", *C0805),    # right (antiphase)
    "C_INP": ("1uF", *C0805), "R_INP": ("<T0.1>", *R0805),  # amp input coupling + gain resistor
    "C_INN": ("1uF", *C0805), "R_INN": ("<T0.1>", *R0805),
    "U_AMP": ("PAM8302AADCR", "Amplifier_Audio:PAM8302AAD", SOIC8),
}
NETS = {n: [p for p in m if not p.startswith("U3.")] for n, m in design.NETS.items()}
NETS["I2S_BCLK"] += ["U_DAC.13"]; NETS["I2S_LRCLK"] += ["U_DAC.15"]; NETS["I2S_DIN"] += ["U_DAC.14"]
NETS["AMP_SD"] += ["U_DAC.17"]
NETS["AMP_SD_R"] += ["U_AMP.1"]
NETS["SPK_P"] += ["U_AMP.5"]; NETS["SPK_N"] += ["U_AMP.8"]
NETS["VBAT_SW"] += ["U_AMP.6"]
NETS["+3V3"] += ["U_DAC.1", "U_DAC.8", "U_DAC.20", "C_DVDD.1", "C_DAVDD.1", "C_DCPV.1", "C_DBULK.1"]
NETS["GND"] += ["U_DAC.3", "U_DAC.9", "U_DAC.19", "U_DAC.10", "U_DAC.11", "U_DAC.12", "U_DAC.16",
                "C_DNEG.2", "C_DLDO.2", "C_DVDD.2", "C_DAVDD.2", "C_DCPV.2", "C_DBULK.2",
                "C_OL.2", "C_OR.2", "U_AMP.7"]
NETS |= {
    "DAC_CAPP": ["U_DAC.2", "C_DCP.1"], "DAC_CAPM": ["U_DAC.4", "C_DCP.2"],
    "DAC_VNEG": ["U_DAC.5", "C_DNEG.1"], "DAC_LDOO": ["U_DAC.18", "C_DLDO.1"],
    "DAC_OL": ["U_DAC.6", "R_OL.1"], "DAC_OR": ["U_DAC.7", "R_OR.1"],
    "AUD_L": ["R_OL.2", "C_OL.1", "C_INP.1"], "AUD_R": ["R_OR.2", "C_OR.1", "C_INN.1"],
    "AMP_INP_C": ["C_INP.2", "R_INP.1"], "AMP_INN_C": ["C_INN.2", "R_INN.1"],
    "AMP_INP": ["R_INP.2", "U_AMP.3"], "AMP_INN": ["R_INN.2", "U_AMP.4"],
}
NC_PINS = set(design.NC_PINS) | {"U_AMP.2"}
NOT_TME = set()   # every carrier part is bought at TME (J2/J3 sockets: ZL262-18SG)
```

Confirm in T0.1 whether `R_INP/R_INN` are needed at all (the PAM8302 may have fixed internal input
resistors); if not, drop them and wire the coupling caps to the pins. The firmware sends the right channel
inverted (`R = -L`), so the amp sees a differential signal; note that in the design doc's firmware section.

`TME = tme.from_lcsc(design.LCSC, keys) | {...new symbols from T0.1 #8...}`; `LCSC = {}`;
`assembled()` returns `[]`; `MODULES = {}`; `VARIANTS = {"standard": set()}` (the TME build is the full
deluxe set). `DNP` stays `{"R_SDA5", "R_SCL5"}`.

**Step 3:** `/usr/bin/python3 carrier_tme.py`: `carrier_tme ok`. Commit.

### Task T4.2: Carrier schematic, PCB, fab

**Files:** Modify `hardware/carrier_tme.py` (BLOCKS/PLACE/REF_AT/GND_VIAS).

1. Schematic: replace the "I2S speaker amp" block's parts with the DAC, its caps, the RC/coupling network
   and the amp; tags for I2S_*, AMP_SD, +3V3. `make BOARD=carrier_tme sch` + ERC clean.
2. PCB: the NS4168 area (around (15, 23), J_SPK1 side) now holds the SOP-8 amp; the TSSOP-20 DAC goes
   between the J2 I2S pins (J2.13/14/16) and the amp, its caps on the pin side they serve (CPVDD/CAPP/CAPM/
   VNEG pins 1-5 together, LDOO/DVDD 18-20 together). Remove `GND_VIAS` entries naming `U3`; keep the two
   for C_AMP1/C_AMP2. Keep 1 mm part spacing for the iron. If the area is too small, move `C_AMP1` (1206)
   rather than the connectors (connector positions are fixed by the enclosure).
3. `make BOARD=carrier_tme all` green. Commit `hw: carrier TME hand-build board`.

---

## Phase T5: pack A

### Task T5.1: `pack_tme.py` data (check first)

**Files:** Create `hardware/pack_tme.py`.

**Step 1:** `check()` = `board.check_structure(this)` + `check_branches()` + `check_mcu()`:

```python
def check_branches():
    """Every cell: holder+ -> fuse -> shunt -> back-to-back P-FET -> pack rail; its own INA228 senses across
    the shunt through the 10R split, VBUS on the cell side; addresses 0x40-0x43 by A1/A0."""
    net_of = {p: n for n, m in NETS.items() for p in m}
    addr = {1: ("GND", "GND"), 2: ("GND", "+3V3"), 3: ("GND", "SDA_INT"), 4: ("GND", "SCL_INT")}
    for i in range(1, 5):
        assert net_of[f"BT{i}.1"] == net_of[f"F{i}.1"], f"cell {i}: holder+ not on fuse"
        assert net_of[f"F{i}.2"] == net_of[f"R_SH{i}.1"] == net_of[f"R_SNSF{i}.1"], f"cell {i}: fuse -> shunt"
        assert net_of[f"R_SNSF{i}.2"] == net_of[f"U_MON{i}.10"] == net_of[f"U_MON{i}.8"], f"cell {i}: IN+/VBUS"
        assert net_of[f"R_SH{i}.2"] == net_of[f"Q_A{i}.3"] == net_of[f"R_SNSS{i}.1"], f"cell {i}: shunt -> FET"
        assert net_of[f"R_SNSS{i}.2"] == net_of[f"U_MON{i}.9"], f"cell {i}: IN-"
        assert net_of[f"Q_B{i}.3"] == "VPACK" and net_of[f"BT{i}.2"] == "GND", f"cell {i}: rail"
        assert (net_of[f"U_MON{i}.1"], net_of[f"U_MON{i}.2"]) == addr[i], f"INA228 {i} address"
        assert net_of[f"U_MON{i}.3"] == "MON_ALERT" and net_of[f"U_MON{i}.6"] == "+3V3"
        assert (net_of[f"U_MON{i}.4"], net_of[f"U_MON{i}.5"]) == ("SDA_INT", "SCL_INT")
```

`check_mcu()` as in T3.2 with: `U_MCU.21` USB_DM, `.22` USB_DP, `.18` SCL_INT, `.27` SDA_INT (I2C3),
`.29` SCL_EXT, `.30` SDA_EXT (I2C1), `.6-.9` NTC1-4 (PA0-PA3), `.10` NTC_PWR, `.11/.12/.13/.14` SW1-4_DRV,
`.15` CHG_CE, `.26` CHG_INT, `.28` MON_ALERT, `.25` LED_MCU_DRV, `.31` BOOT0, `.4` NRST, `.23` SWDIO,
`.24` SWCLK; and `U_CHG` footprint is the `local:` hand-solder one; `"D1" not in PARTS`; `U1` is MCP1640
with `U1.6` and `U1.3` on VBAT_SW, `U1.5` on +5V, `U1.4` on FB. Run: FAIL.

**Step 2: data** (`import pack, tme`). Parts:

```python
LQFP32, SOT23_6, R0805, C0805 = pack.LQFP32, pack.SOT23_6, pack.R0805, pack.C0805
VSSOP10 = "Package_SO:VSSOP-10_3x3mm_P0.5mm"
QFN24_HAND = "local:QFN-24-1EP_4x4mm_P0.5mm_EP2.6x2.6mm_HandSolder"
USB_THT = "Connector_USB:USB_C_Receptacle_GCT_USB4085"
TACT_THT = "Button_Switch_THT:SW_PUSH_6mm"
_REMOVED = {"U_MON", "R_PWRDN", "D1"}
PARTS = {r: v for r, v in pack.PARTS.items() if r not in _REMOVED}
PARTS["U_CHG"] = ("BQ25601RTWT", "Battery_Management:BQ25601", QFN24_HAND)
PARTS["U_MCU"] = ("STM32L072KZT6", "MCU_ST_STM32L0:STM32L072KZTx", LQFP32)
PARTS["C_MCU3"] = ("100nF", *C0805)
PARTS["C_VDDA"] = ("1uF", *C0805)
PARTS["J_USB1"] = ("USB4085-GF-A", pack.PARTS["J_USB1"][1], USB_THT)
PARTS["SW_BOOT"] = ("TACT 6x6", "Switch:SW_Push", TACT_THT)
PARTS["SW_RST"] = ("TACT 6x6", "Switch:SW_Push", TACT_THT)
PARTS["U1"] = ("MCP1640T-I/CHY", "Regulator_Switching:MCP1640x-xCHY", SOT23_6)
PARTS["R_FB2"] = ("24k", *R0805)                     # 1.21 V x (1 + 75/24) = 4.99 V
PARTS["TH_CHG"] = ("10k NTC 0603", *PARTS["TH_CHG"][1:])
for i in range(1, 5):
    PARTS[f"U_MON{i}"] = ("INA228AIDGSR", "Sensor_Energy:INA228", VSSOP10)
    PARTS[f"C_MON{i}"] = ("100nF", *C0805)
# L1 changes only if T0.1 #5 says so (4.7 uH): PARTS["L1"] = ("4u7 2A", "Device:L", pack.LRN6045)
```

Nets: strip every `U_MCU.*`, `U_MON.*`, `U1.*`, `D1.*`, `R_PWRDN.*` member, delete `MON_PWRDN`, then add:

```python
MCU = {"+3V3": [1, 5, 17], "GND": [16, 32], "NRST": [4], "BOOT0": [31], "SWDIO": [23],
       "SWCLK": [24], "USB_DM": [21], "USB_DP": [22], "SCL_INT": [18], "SDA_INT": [27],
       "SCL_EXT": [29], "SDA_EXT": [30], "NTC_PWR": [10], "CHG_CE": [15], "CHG_INT": [26],
       "MON_ALERT": [28], "LED_MCU_DRV": [25],
       "NTC1": [6], "NTC2": [7], "NTC3": [8], "NTC4": [9],
       "SW1_DRV": [11], "SW2_DRV": [12], "SW3_DRV": [13], "SW4_DRV": [14]}
for net, pins in MCU.items():
    NETS.setdefault(net, []).extend(f"U_MCU.{p}" for p in pins)
NETS["SWCLK"] = NETS.get("SWCLK", []) + ["TP_SWCLK.1"]       # BOOT0 is its own pin now
NETS["BOOT0"] = [p for p in NETS["BOOT0"] if p != "TP_SWCLK.1"]
NETS["+3V3"] += ["C_MCU3.1", "C_VDDA.1", *(f"U_MON{i}.6" for i in range(1, 5)),
                 *(f"C_MON{i}.1" for i in range(1, 5)), "U_MON2.2"]
NETS["GND"] += ["C_MCU3.2", "C_VDDA.2", "U1.2", *(f"U_MON{i}.7" for i in range(1, 5)),
                *(f"C_MON{i}.2" for i in range(1, 5)), *(f"U_MON{i}.1" for i in range(1, 5)), "U_MON1.2"]
NETS["SDA_INT"] += [*(f"U_MON{i}.4" for i in range(1, 5)), "U_MON3.2"]
NETS["SCL_INT"] += [*(f"U_MON{i}.5" for i in range(1, 5)), "U_MON4.2"]
NETS["MON_ALERT"] += [f"U_MON{i}.3" for i in range(1, 5)]
NETS["VBAT_SW"] += ["U1.6", "U1.3"]        # VIN, EN tied high
NETS["SW"] = ["U1.1", "L1.2"]
NETS["FB"] = ["U1.4", "R_FB1.2", "R_FB2.1"]
NETS["+5V"] += ["U1.5"]
for i in range(1, 5):
    NETS[f"SNS_F{i}"] = [p for p in NETS[f"SNS_F{i}"]] + [f"U_MON{i}.10", f"U_MON{i}.8"]
    NETS[f"SNS_S{i}"] = [p for p in NETS[f"SNS_S{i}"]] + [f"U_MON{i}.9"]
NC_PINS = ({p for p in pack.NC_PINS if not p.startswith(("U_MCU.", "U1."))}
           | {f"U_MCU.{p}" for p in (2, 3, 19, 20)})
```

(The internal pull-ups `R_SCL_INT/R_SDA_INT` and `R_ALERT` stay from variant A. The KiCad USB-C symbol
and the USB4085 share pad names, so `USB_*`, `CC*`, `VBUS` nets carry over.) Check that `pack.py`'s
`SW_PIN/NTC_PIN` use is fully replaced: no `U_MCU.` member may be left from the C071 map
(`assert not any(p in old_c071_only ...)` is covered by the pin checks).

`DNP = set(pack.DNP)`; `NOT_ASSEMBLED = set()`;
`NOT_TME = {"BT1".."BT4", "TH1".."TH4"} | test pads` (holders and bead NTCs come from LCSC, see
`fab/offboard/offboard_other.csv`); `LCSC = {}`;
`TME = tme.from_lcsc(pack.LCSC, keys) | {new parts}` including `("10k NTC 0603", ...): "NTCS0603E3103FLT"`.

**Step 3:** `/usr/bin/python3 pack_tme.py`: `pack_tme ok`. Commit.

### Task T5.2: Pack schematic, PCB, fab

**Files:** Modify `hardware/pack_tme.py` (BLOCKS/PLACE/REF_AT).

1. Schematic: block 1 (PAC1934) becomes four INA228s in a row with their caps and address straps; block 2's
   MCU takes the L072 symbol (it is larger: re-place tags); the boost block loses D1. ERC clean.
2. PCB (96 x 90 mm, holders on the bottom, all SMD on top, unchanged outline and holes):
   - four INA228 (3 x 3 mm VSSOP) each next to its cell's shunt pair, Kelvin traces from the 10R split as
     variant A did for the PAC1934; this frees the PAC1934 spot;
   - the USB4085 is through-hole: it must not sit over a holder (bottom side); keep its board-edge position;
   - the tact switches are 6 x 6 mm THT: same rule; put them on the MCU side near the edge;
   - the BQ25601 hand-solder footprint is 1.2 mm larger; nothing may sit within 1 mm of its pad ends;
     its back-side hole must not be under a holder (needs iron access from the bottom).
3. `make BOARD=pack_tme all` green. Print `fab/pack_tme/print_1to1.pdf` and check the holders, USB4085,
   tact switches and the QFN with an iron tip.
4. Commit `hw: pack A TME hand-build board`.

---

## Phase T6: power model and docs

### Task T6.1: `power_budget.py` for the TME builds

**Files:** Modify `hardware/power_budget.py`.

Add a `--tme` switch (or a second scenario table, whichever matches the file's structure): MCU Stop current
from T0.1 #1 instead of 85 uA, 4x INA228 (active and shutdown currents from T0.1 #2) instead of the PAC1934,
PCM5100A standby + PAM8302 shutdown instead of the NS4168. Run both scenarios; expected: the weekend target
still passes for the TME pack build. Commit.

### Task T6.2: Docs and the `boards` target

**Files:** Modify `hardware/Makefile` (`boards:` gains the three TME boards), the design doc (status: built;
any deviation found during layout), `hardware/fab/ORDERING.md` (a short "TME hand-build" section: order bare
PCBs only, no assembly; upload `fab/<board>_tme/tme_bom.csv` to TME Quick Buy; hand-solder notes for the
QFN footprint: flux, drag the pad ends, then fill the EP hole from the back; LCSC-only parts: holders and
bead NTCs).

Run `make boards` (all seven) and the Conventions check. Commit `docs: TME hand-build boards`.

---

## Done when

- `make boards` builds carrier, pack, pack_b, lipo, carrier_tme, pack_tme and lipo_tme with ERC/DRC clean.
- Every `fab/*_tme/tme_bom.csv` symbol was found in the TME catalogue (T0.1), and `tme_bom.csv` covers every
  bought part (the T1.1 check enforces it).
- The JLC boards' `fab/` output is byte-identical to before this plan (except files the plan names).
- `power_budget.py` passes the weekend target for the TME pack build.

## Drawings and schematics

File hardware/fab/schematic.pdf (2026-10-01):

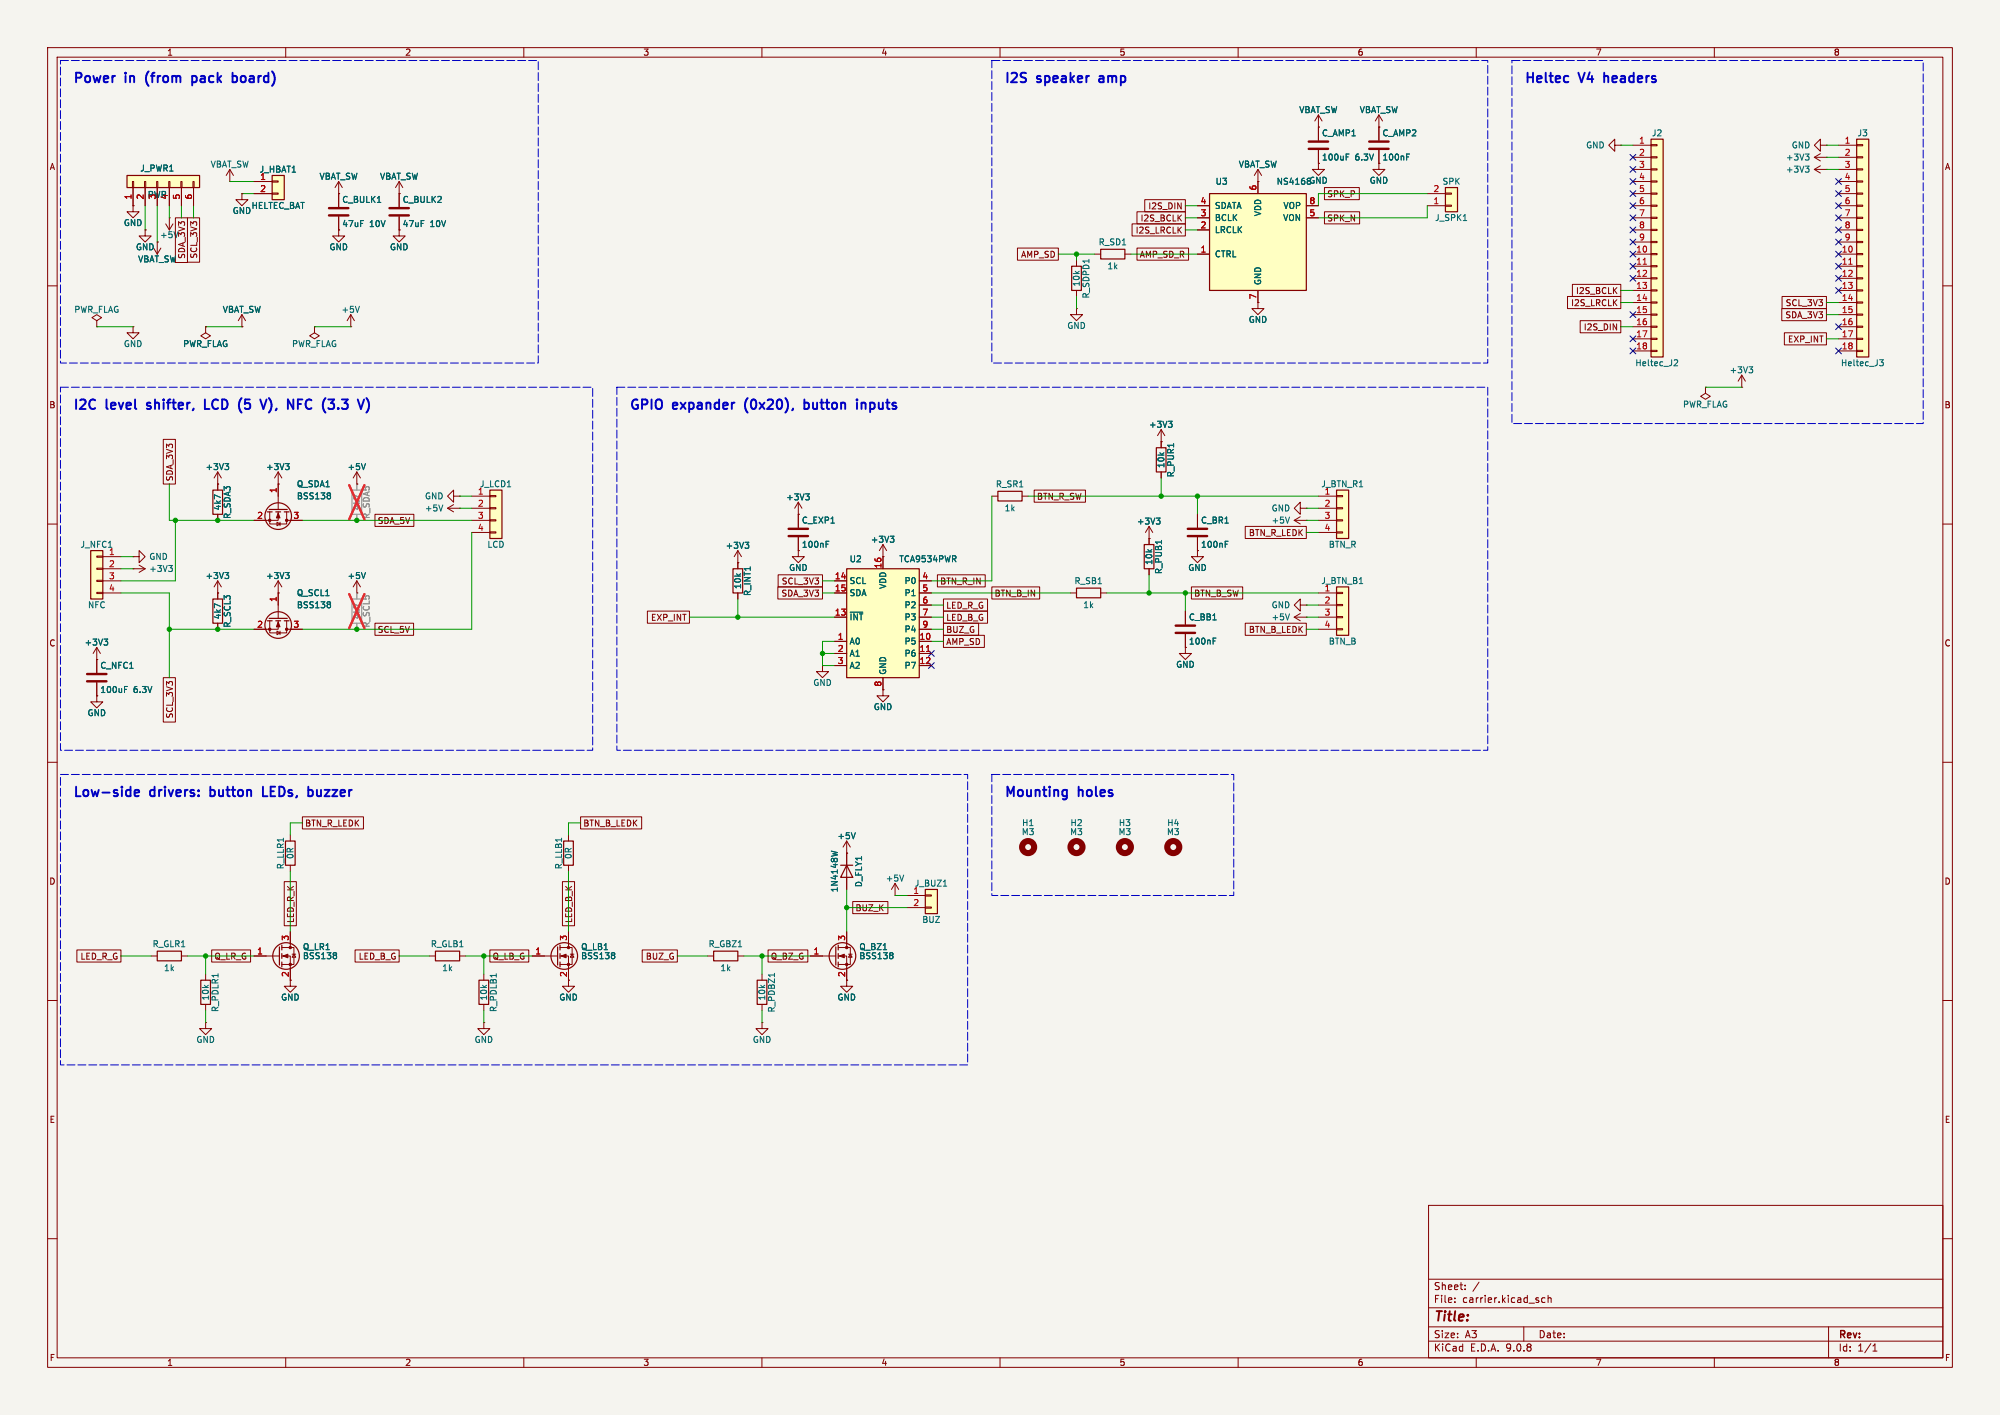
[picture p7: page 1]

Power in (from pack board)

Id: 1/1 Title: File: carrier.kicad_sch Sheet: /

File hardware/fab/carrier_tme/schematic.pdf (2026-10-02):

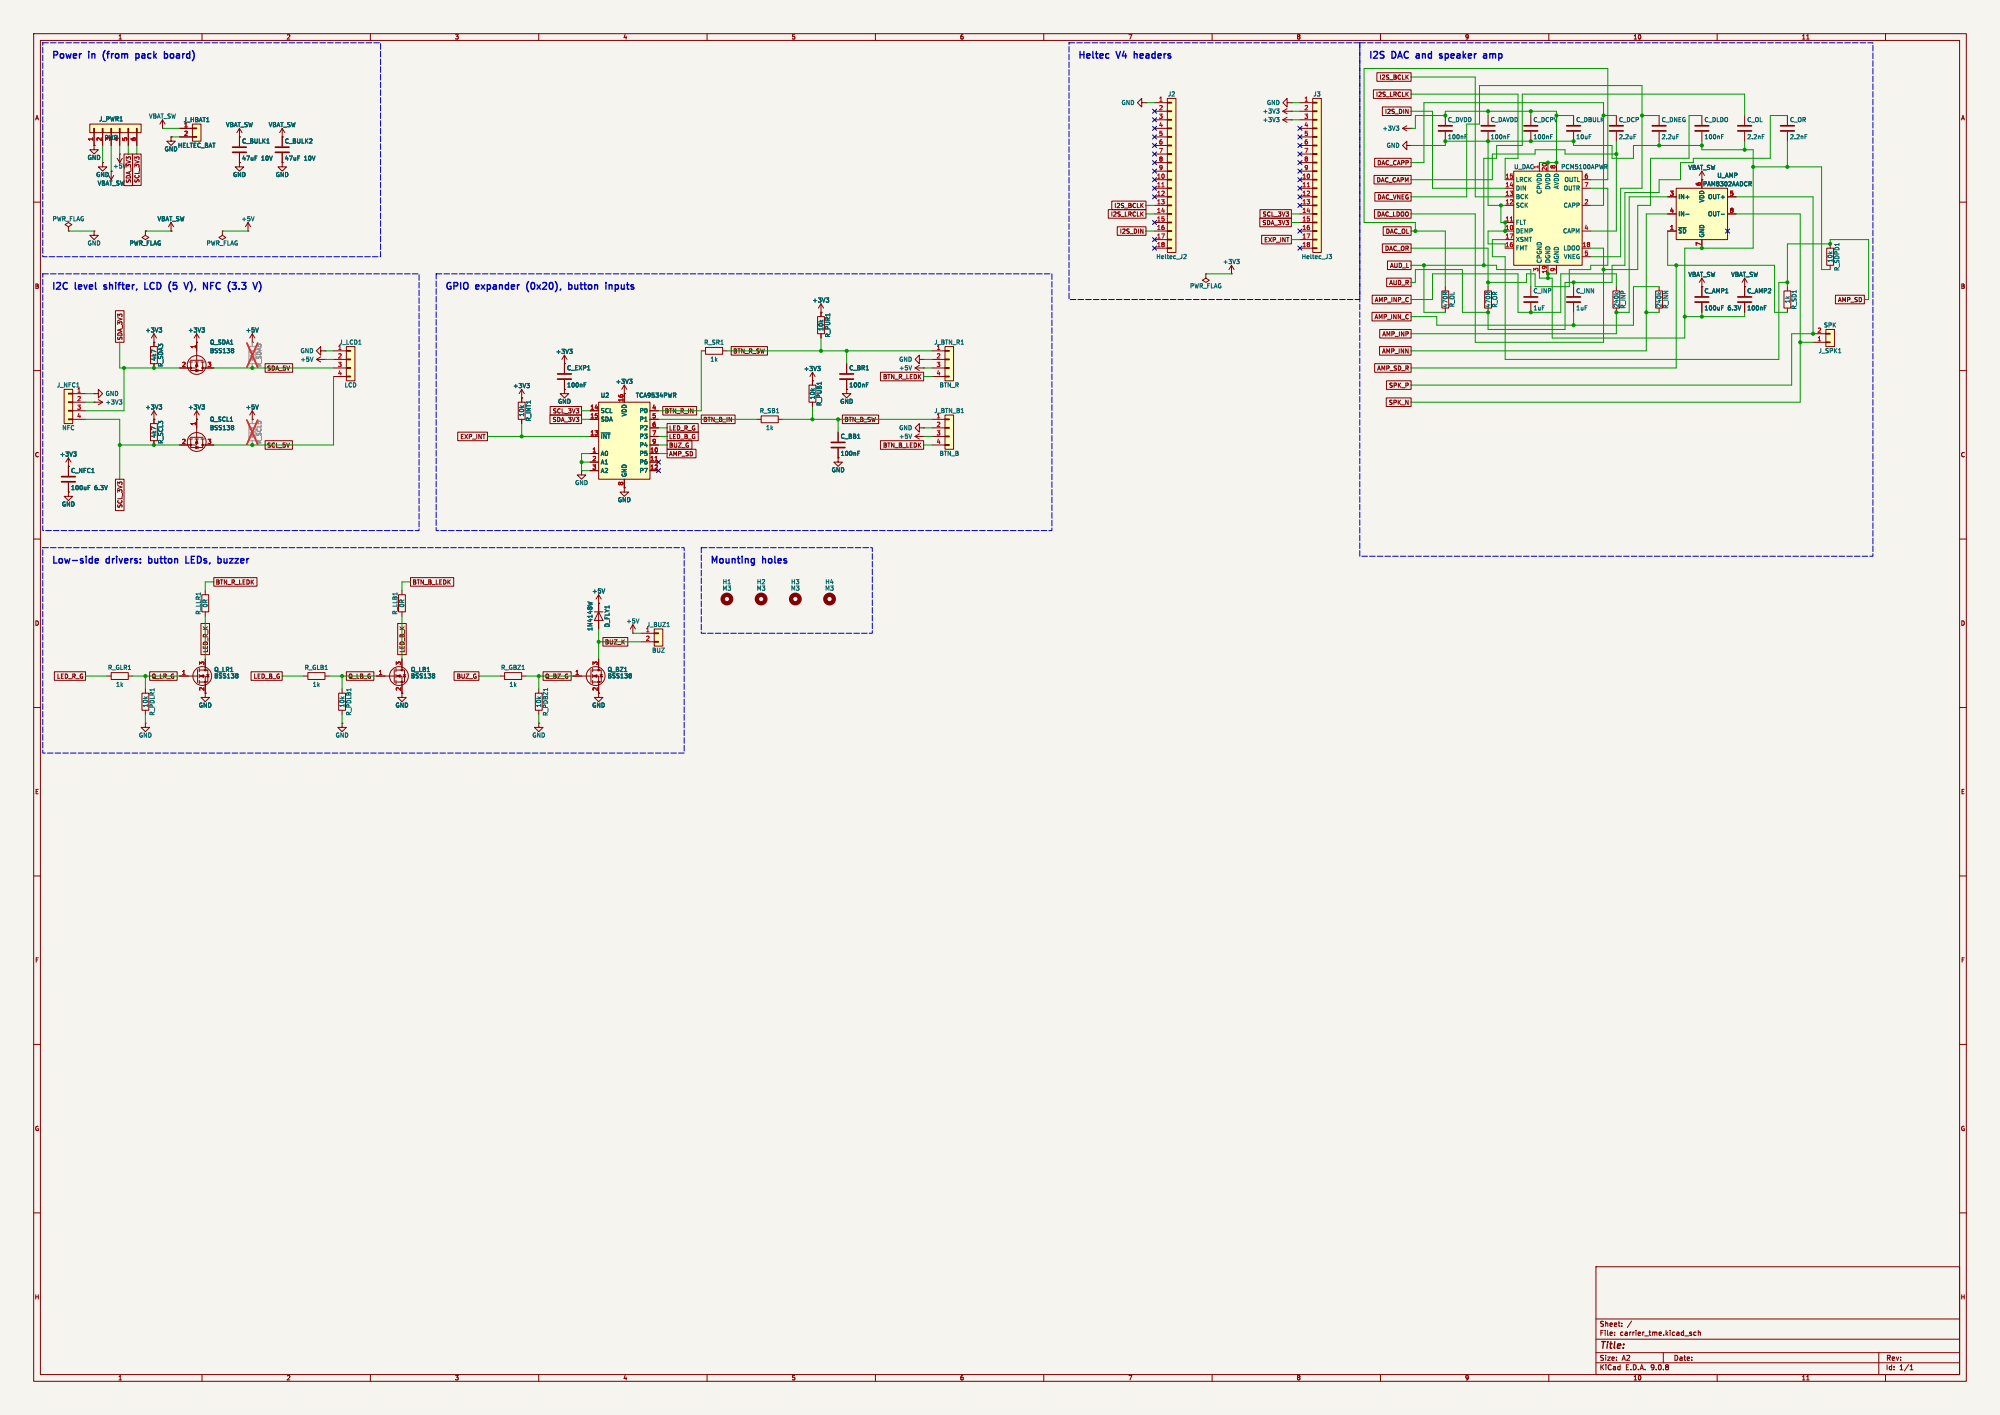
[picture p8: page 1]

I2C level shifter, LCD (5 V), NFC (3.3 V)

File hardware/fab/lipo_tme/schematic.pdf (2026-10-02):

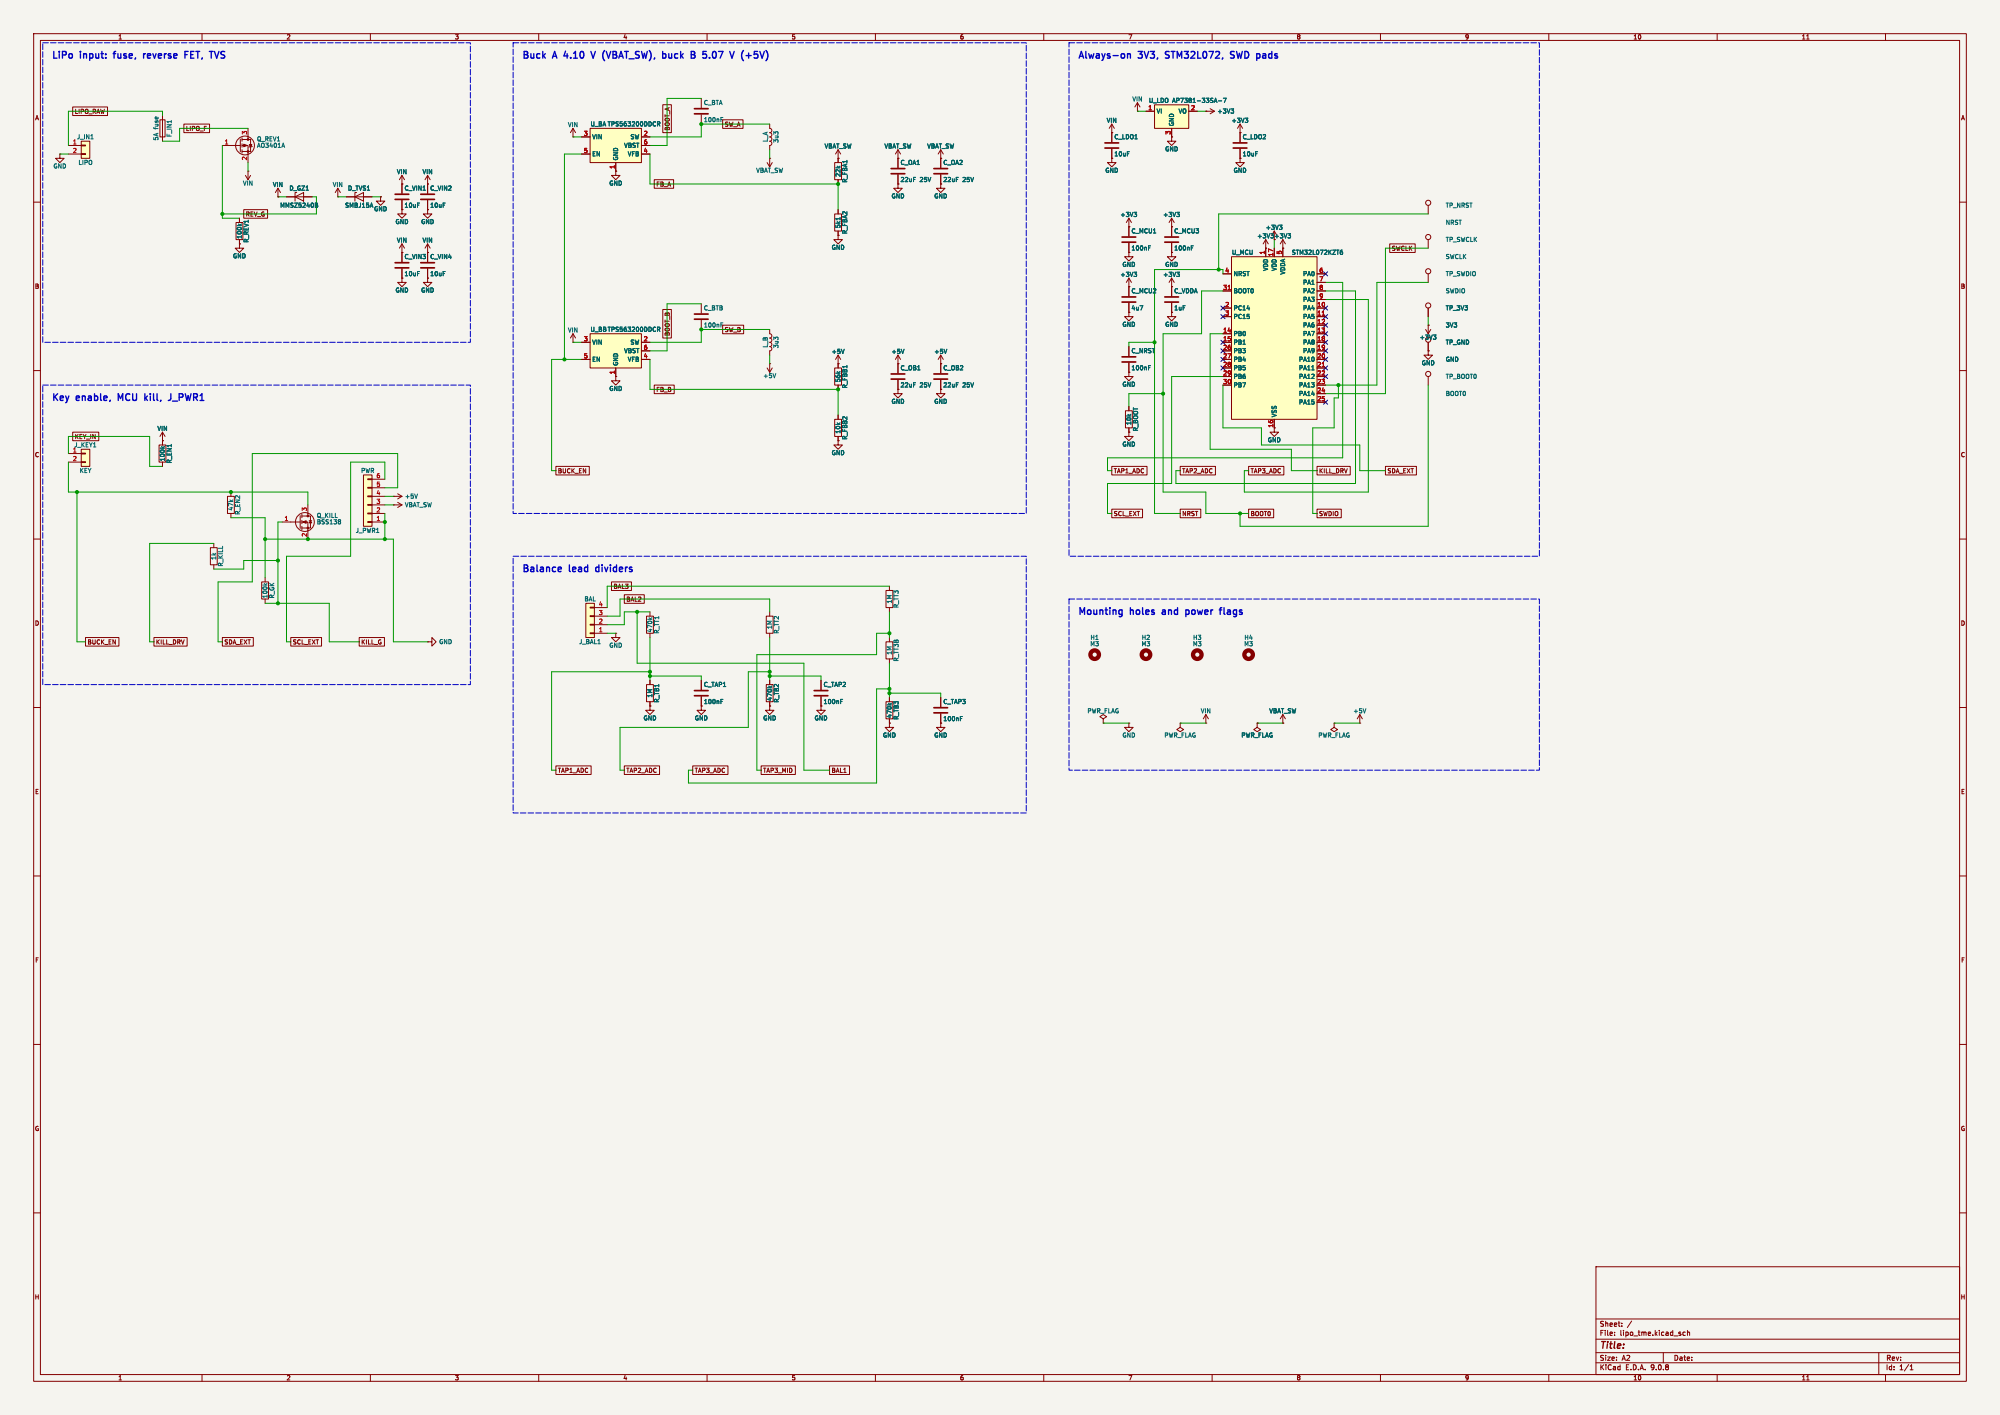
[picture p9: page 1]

1 SW 2 VBST 6 VFB 4 GND

1 SW 2 VBST 6 VFB 4 U_BB TPS563200DDCR GND GND

1 SW 2 VBST 6 VFB 4 GND R_EN1 100k VIN

22uF 25V GND GND GND R_TB2 470k GND

Key enable, MCU kill, J_PWR1

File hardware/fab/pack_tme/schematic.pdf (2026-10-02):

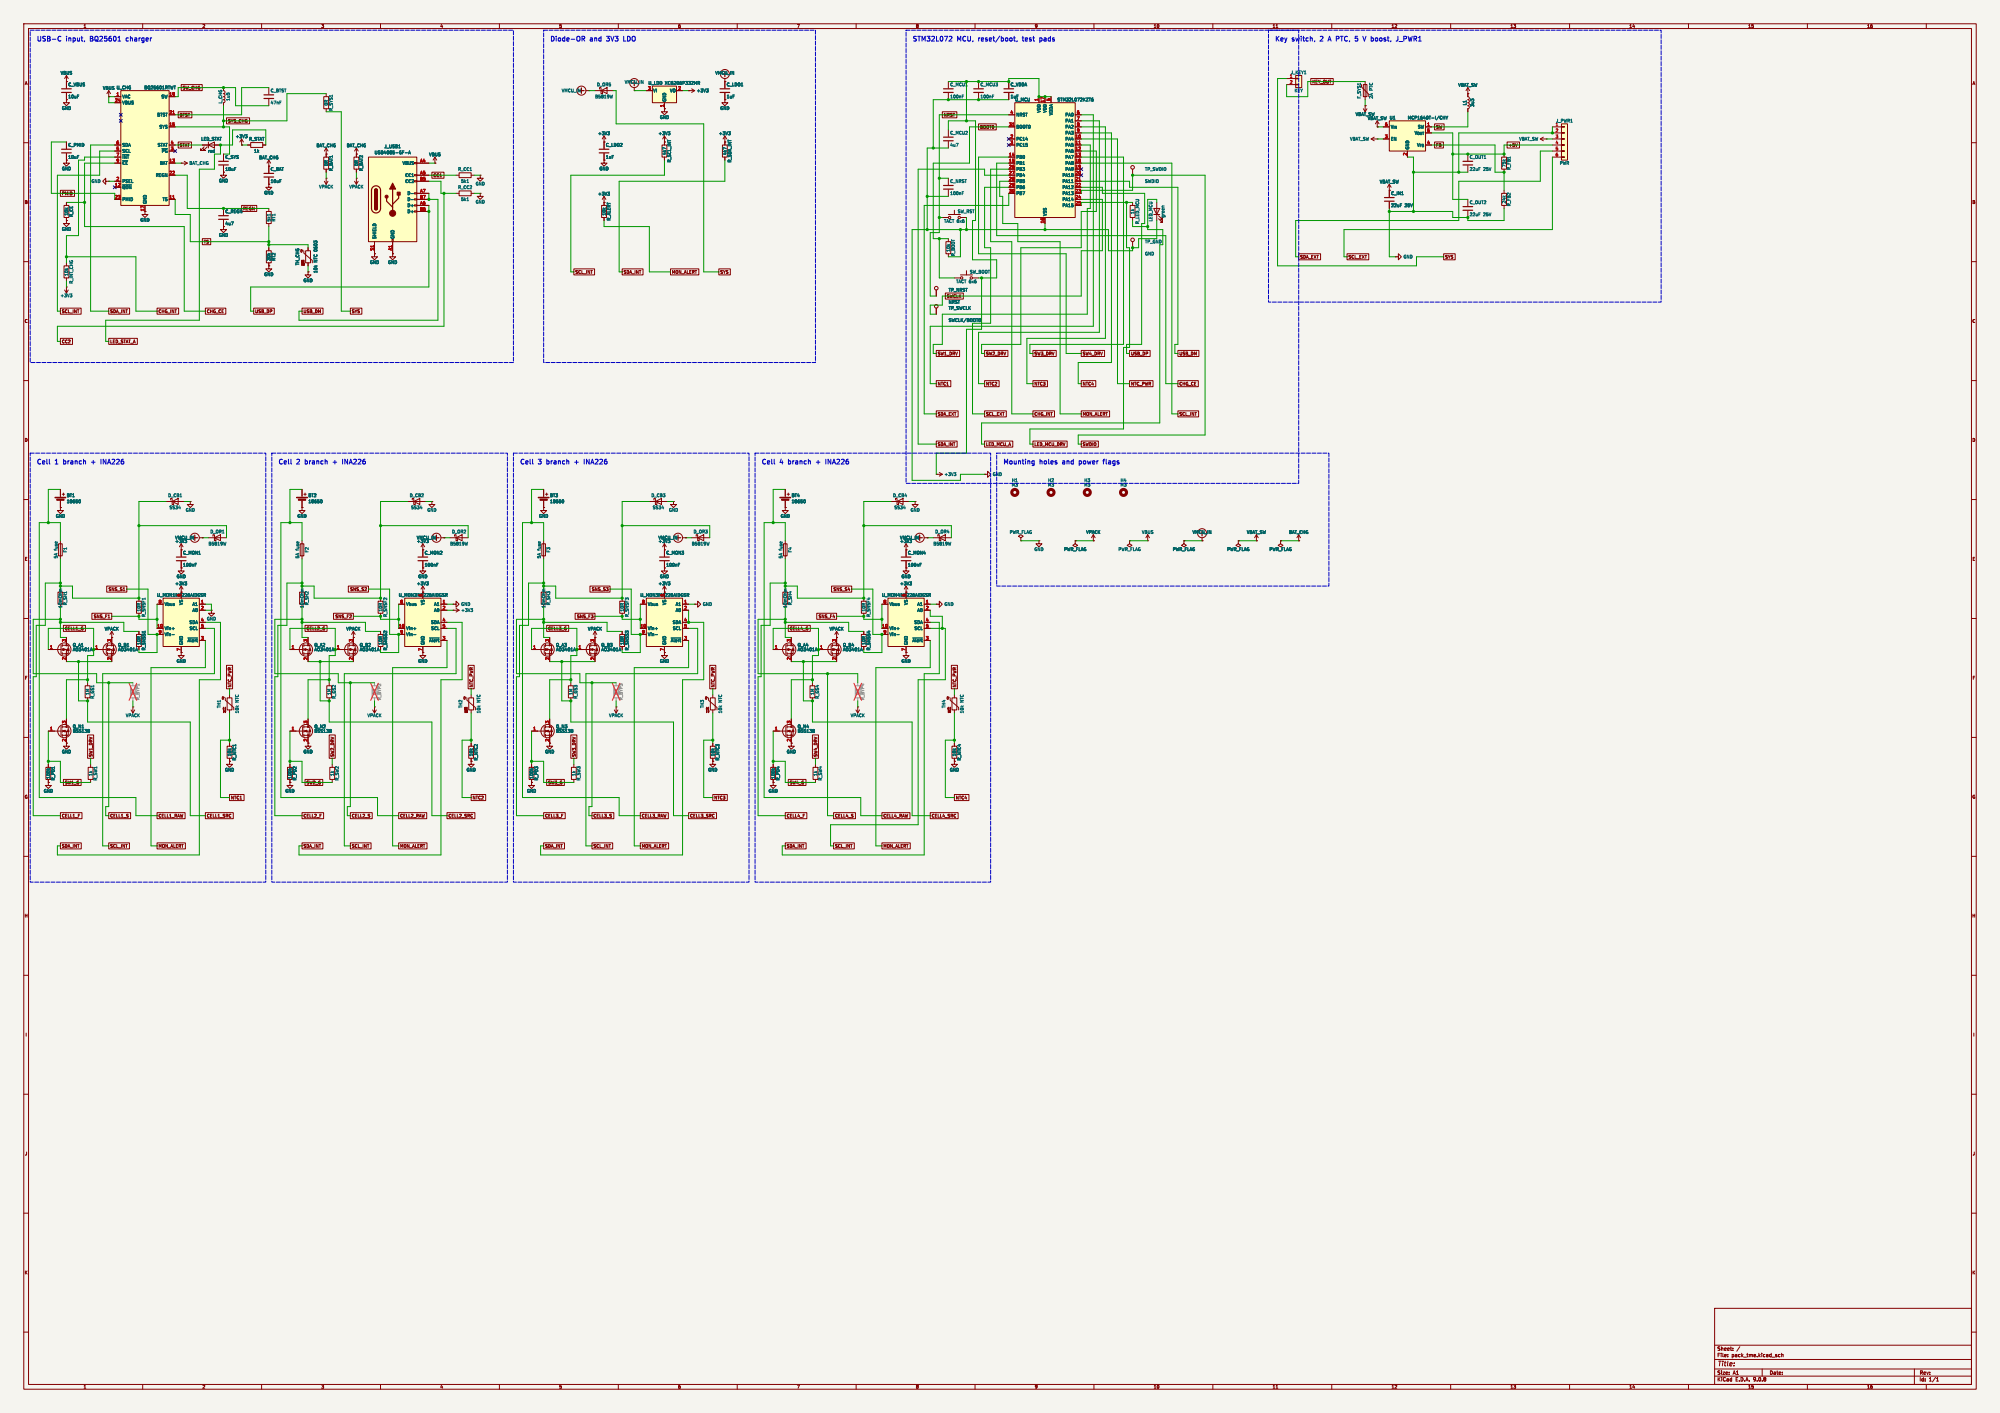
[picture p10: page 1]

Key switch, 2 A PTC, 5 V boost, J_PWR1

Mounting holes and power flags

7 A1 1 A0 2 SDA 4 SCL 5 ~{Alert}3 GND GND

3 2 Q_N4 BSS138 GND GND R_NTC3 10k TH3 10k NTC GND

7 A1 1 A0 2 SDA 4 SCL 5 ~{Alert}3 R_SNSS3 10R R_PD2 100kGND GND R_NTC2 10k +3V3 GND

Id: 1/1 Title: File: pack_tme.kicad_sch Sheet: /

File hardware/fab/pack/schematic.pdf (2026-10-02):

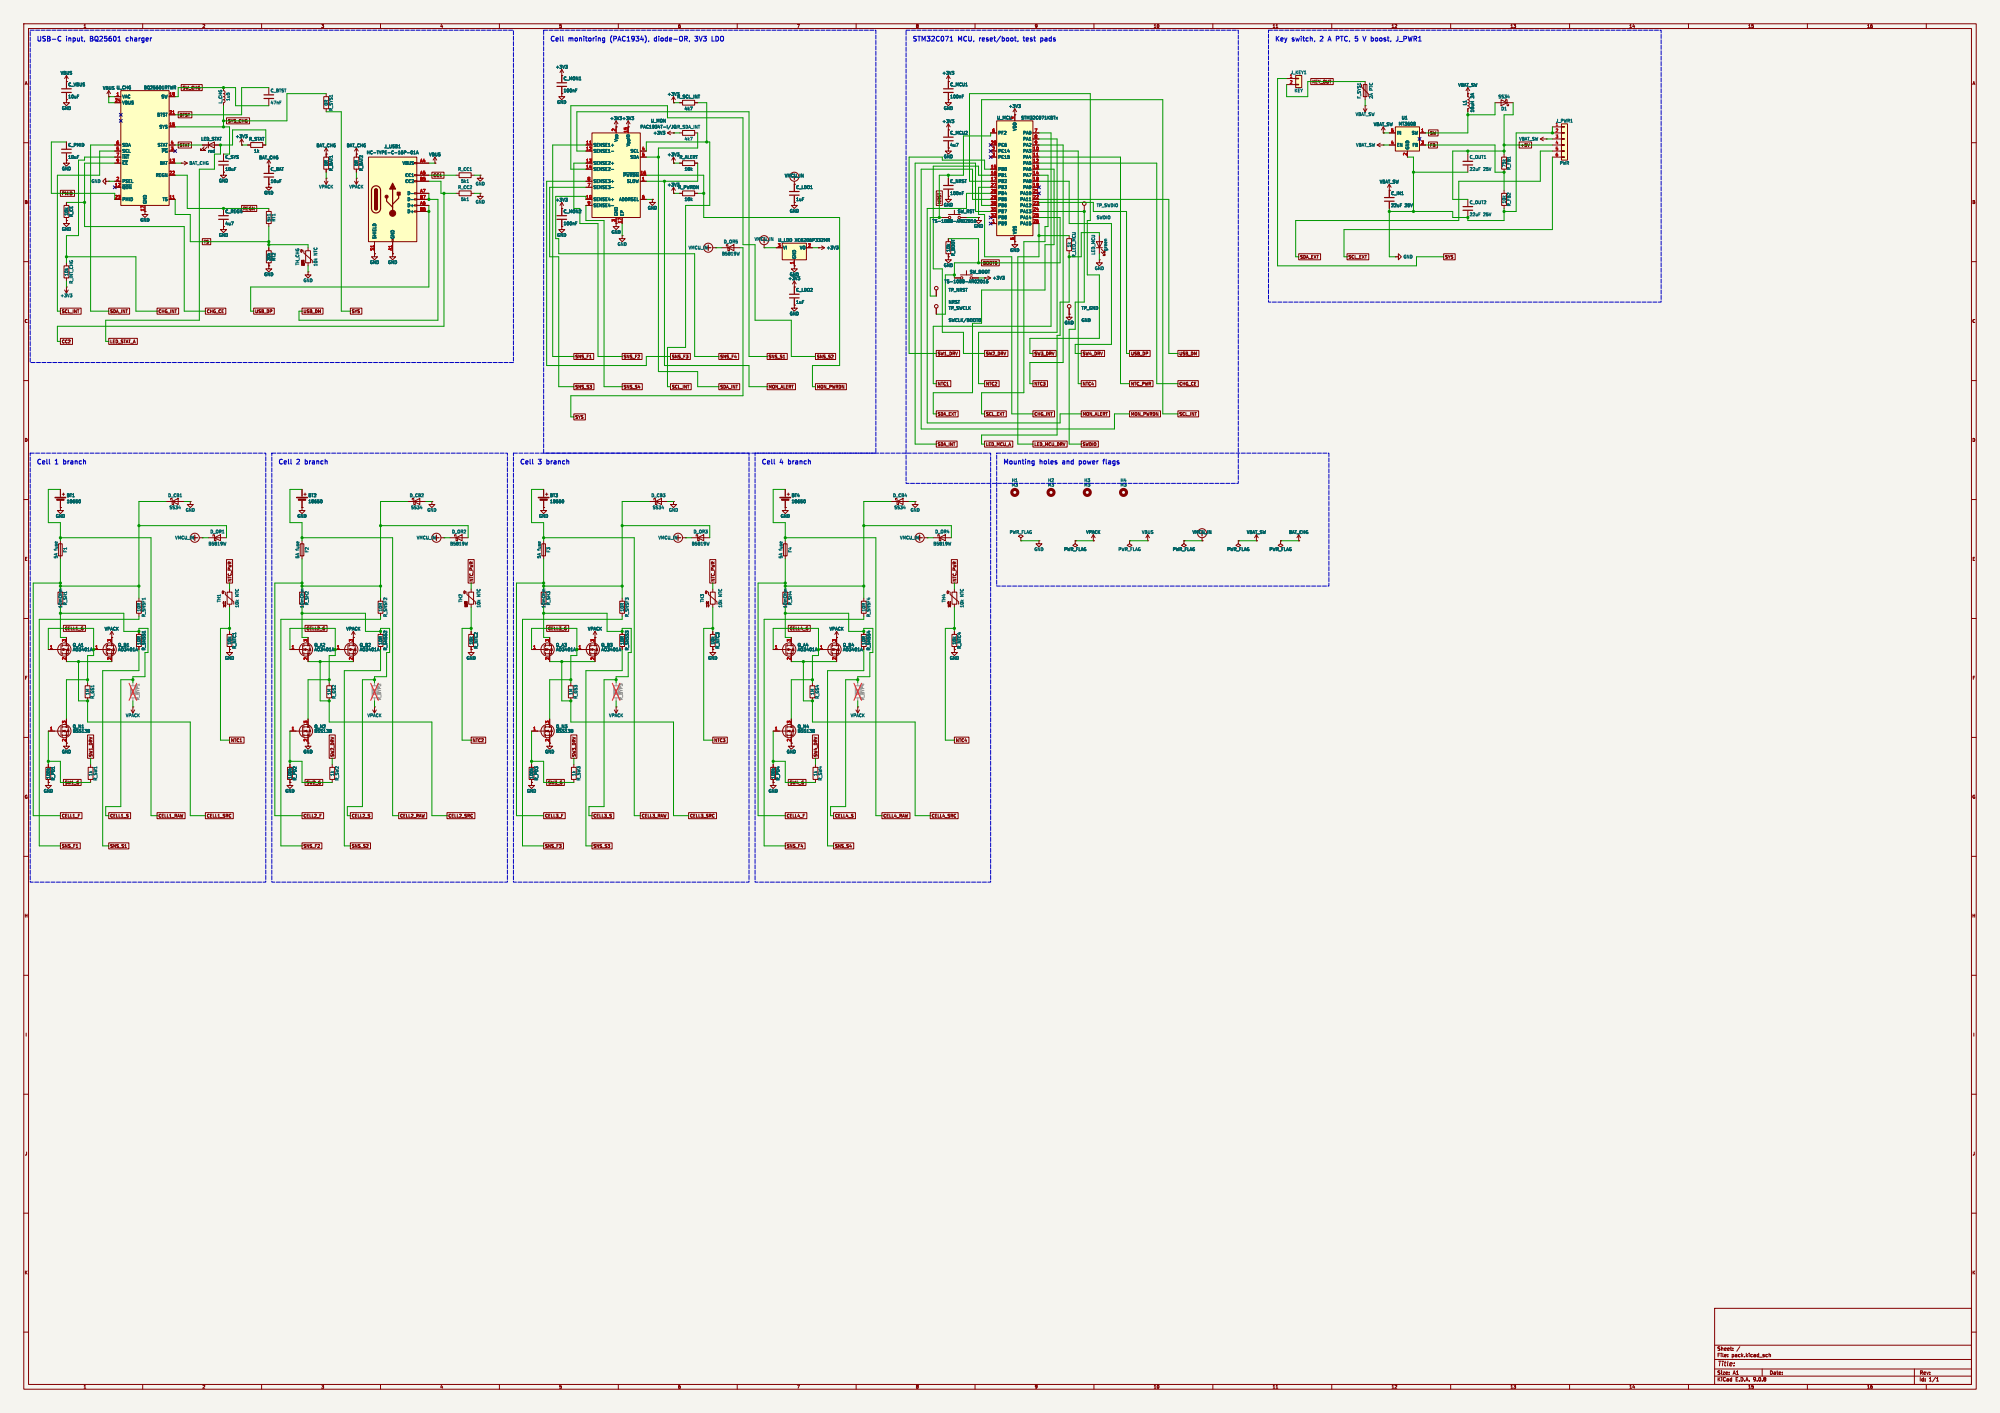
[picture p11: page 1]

3 EP 17 V_{DD}IO15 SCL 4 SDA 5 ~{PWRDN} 16 SLOW 1 ADDRSEL 6 +3V3 +3V3 +3V3 VBUS

3 EP 17 V_{DD}IO15 SCL 4 SDA 5 ~{PWRDN} 16 SLOW 1 ADDRSEL 6 U_MON

3 2 GND GND R_NTC3 10k GND GND R_PD4 100k Q_N4 BSS138 1

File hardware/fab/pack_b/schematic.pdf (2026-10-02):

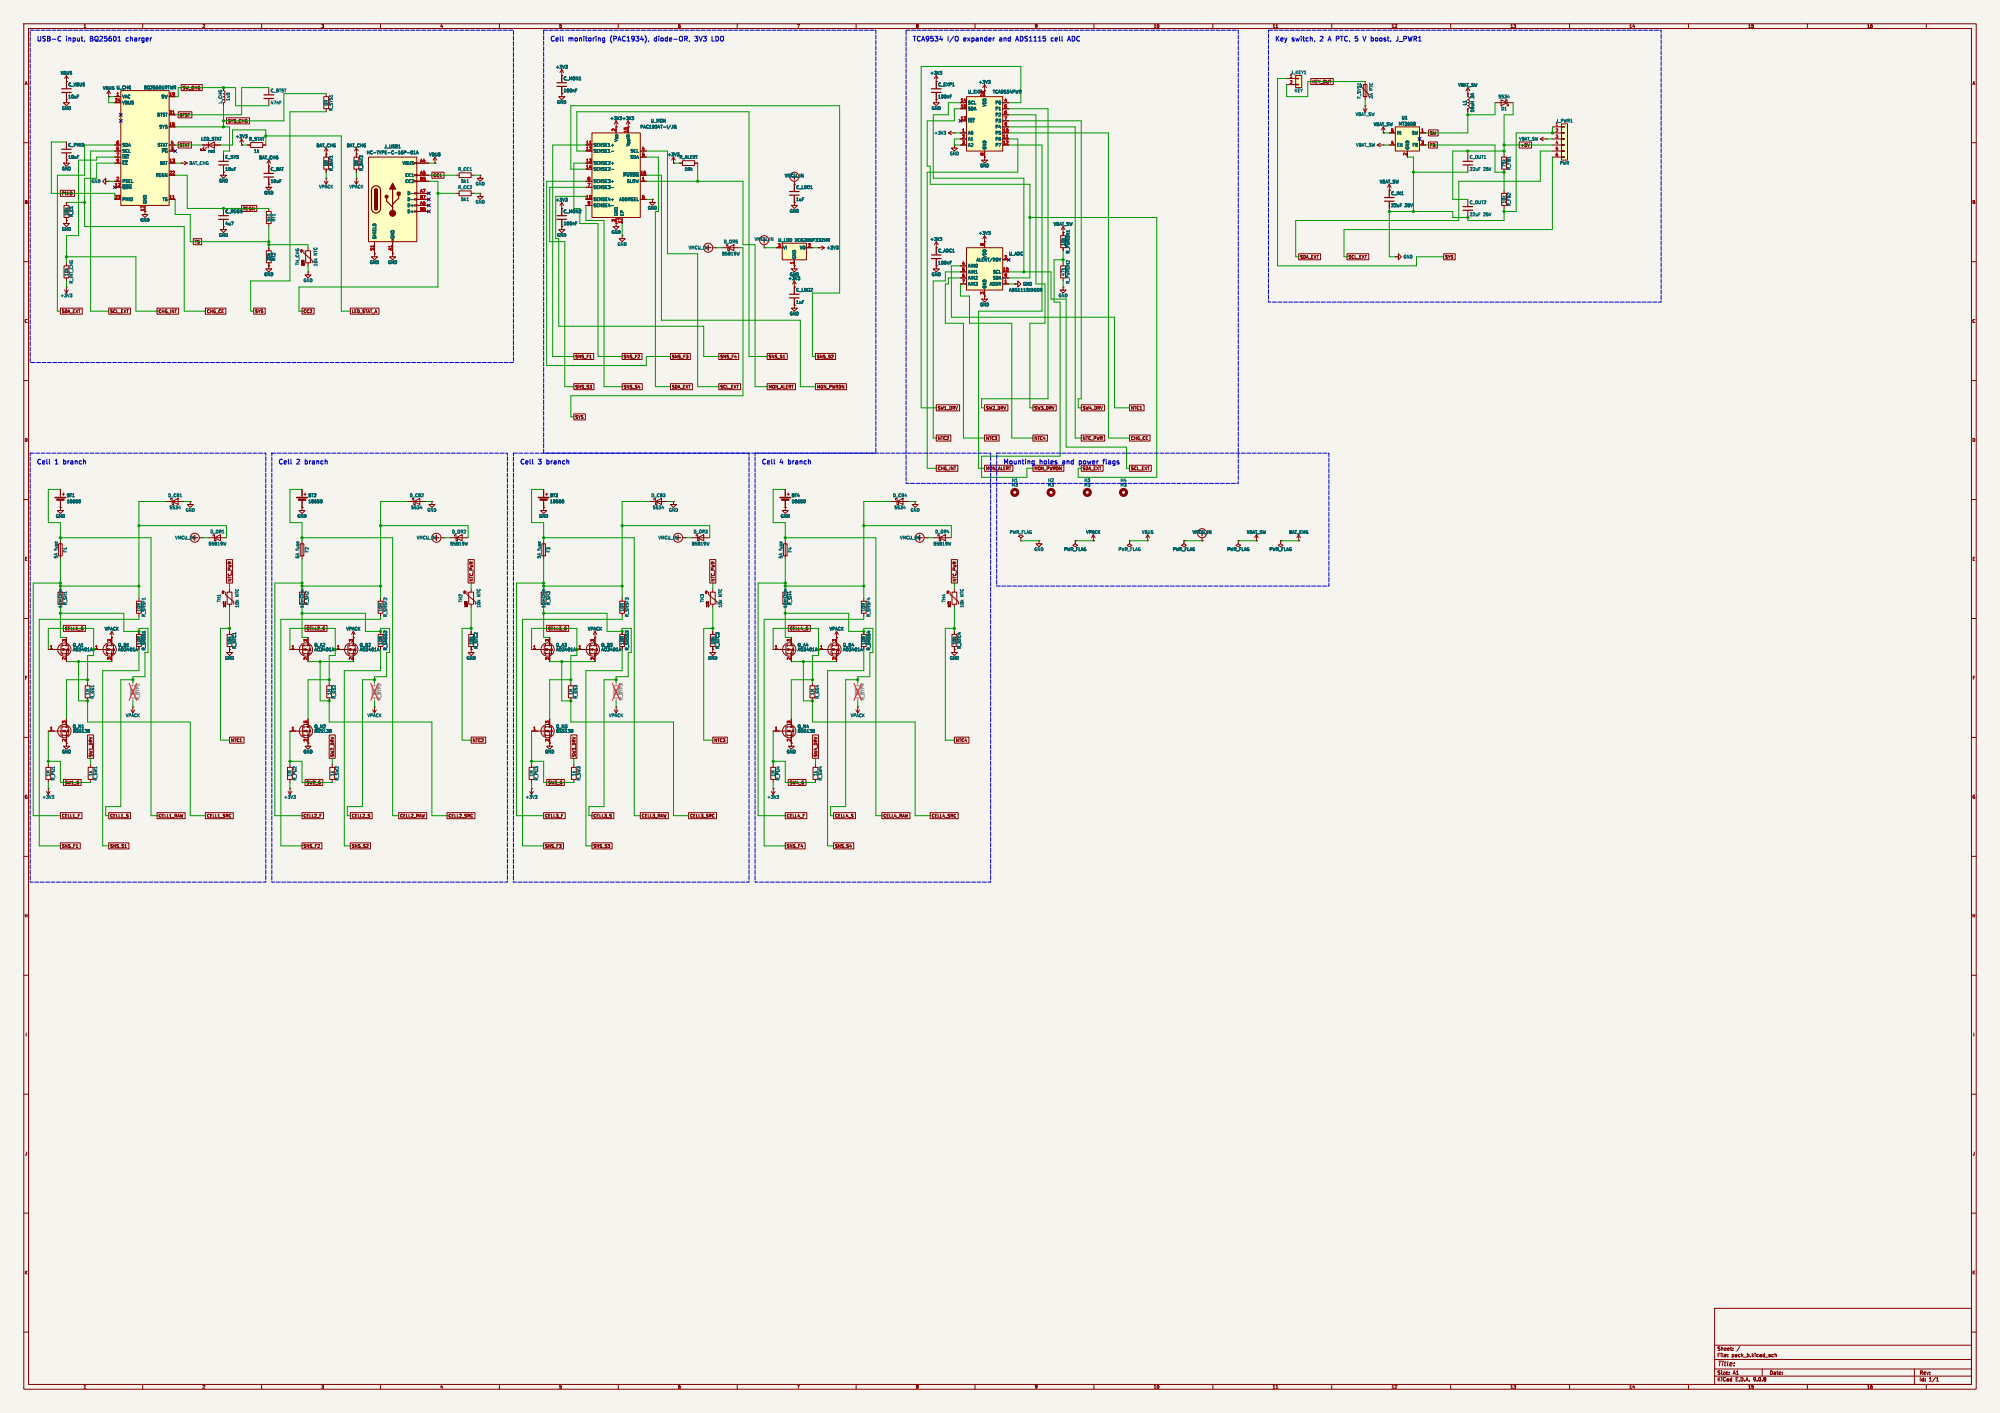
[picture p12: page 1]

TCA9534 I/O expander and ADS1115 cell ADC

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

3 EP 17 V_{DD}IO15 SCL 4 SDA 5 ~{PWRDN} 16 SLOW 1 ADDRSEL 6 +3V3 U_LDO XC6206P332MR

Id: 1/1 Title: File: pack_b.kicad_sch Sheet: /

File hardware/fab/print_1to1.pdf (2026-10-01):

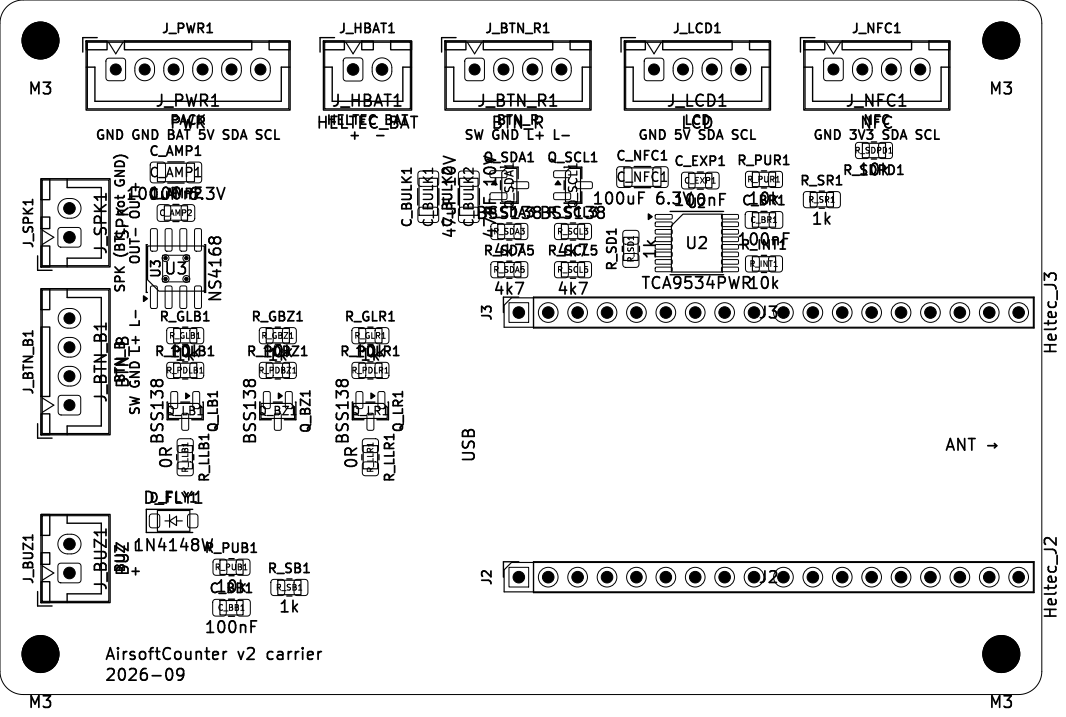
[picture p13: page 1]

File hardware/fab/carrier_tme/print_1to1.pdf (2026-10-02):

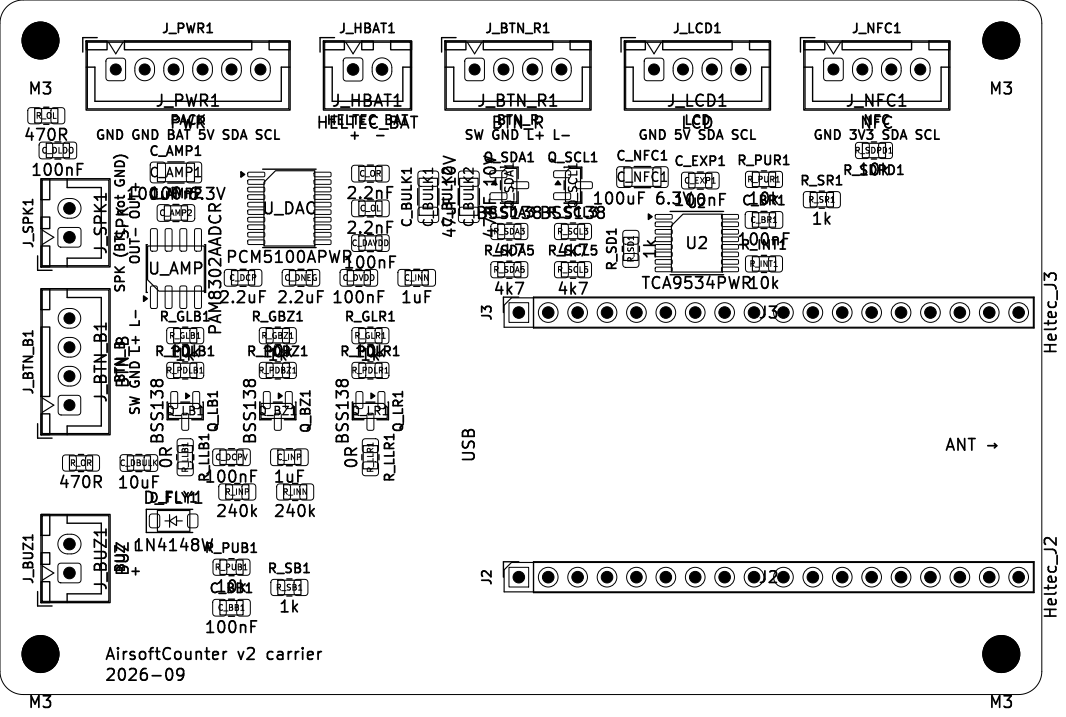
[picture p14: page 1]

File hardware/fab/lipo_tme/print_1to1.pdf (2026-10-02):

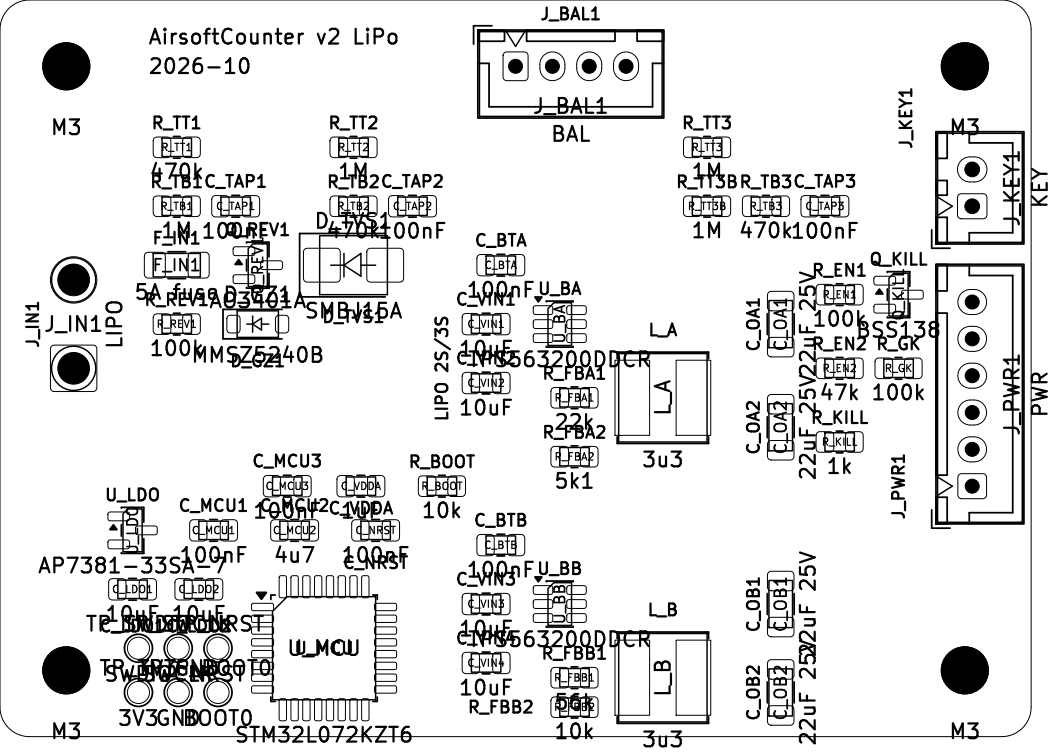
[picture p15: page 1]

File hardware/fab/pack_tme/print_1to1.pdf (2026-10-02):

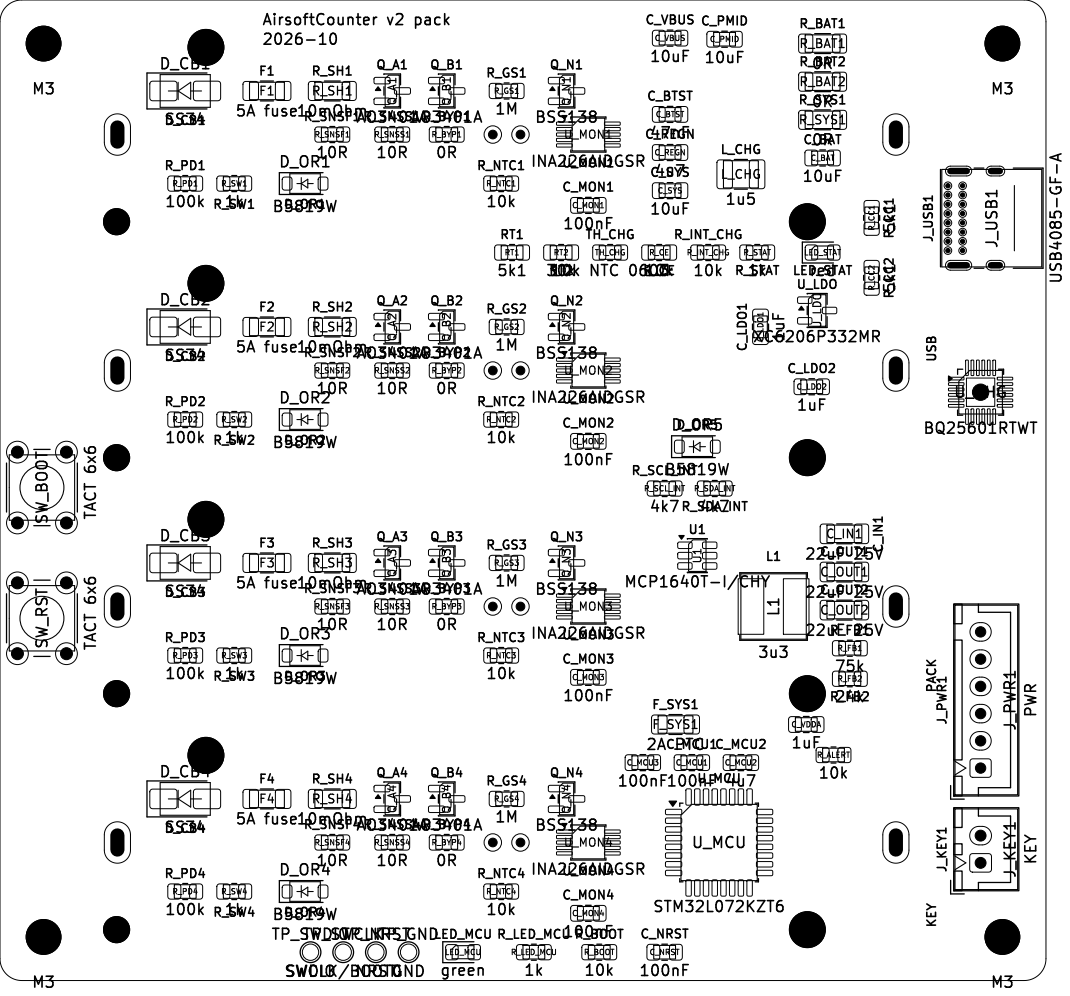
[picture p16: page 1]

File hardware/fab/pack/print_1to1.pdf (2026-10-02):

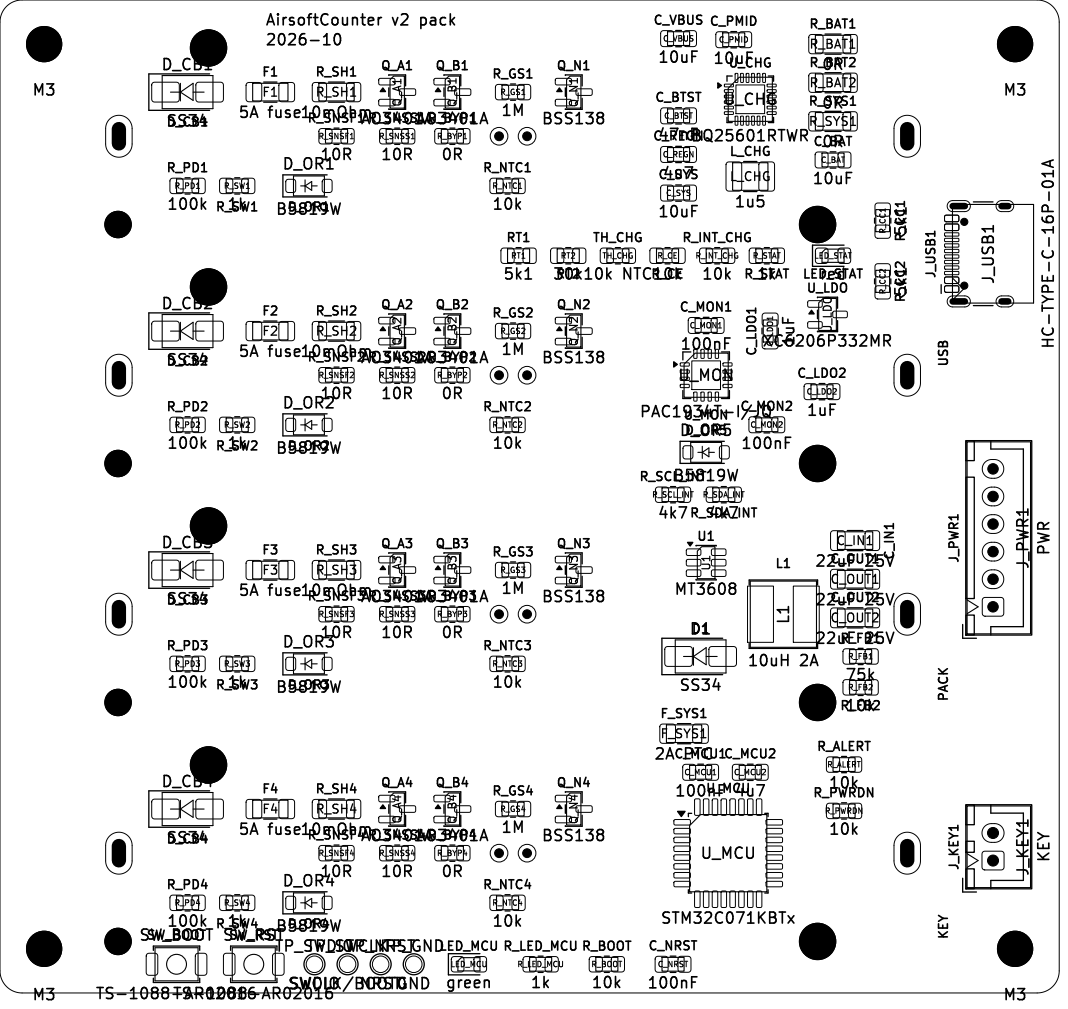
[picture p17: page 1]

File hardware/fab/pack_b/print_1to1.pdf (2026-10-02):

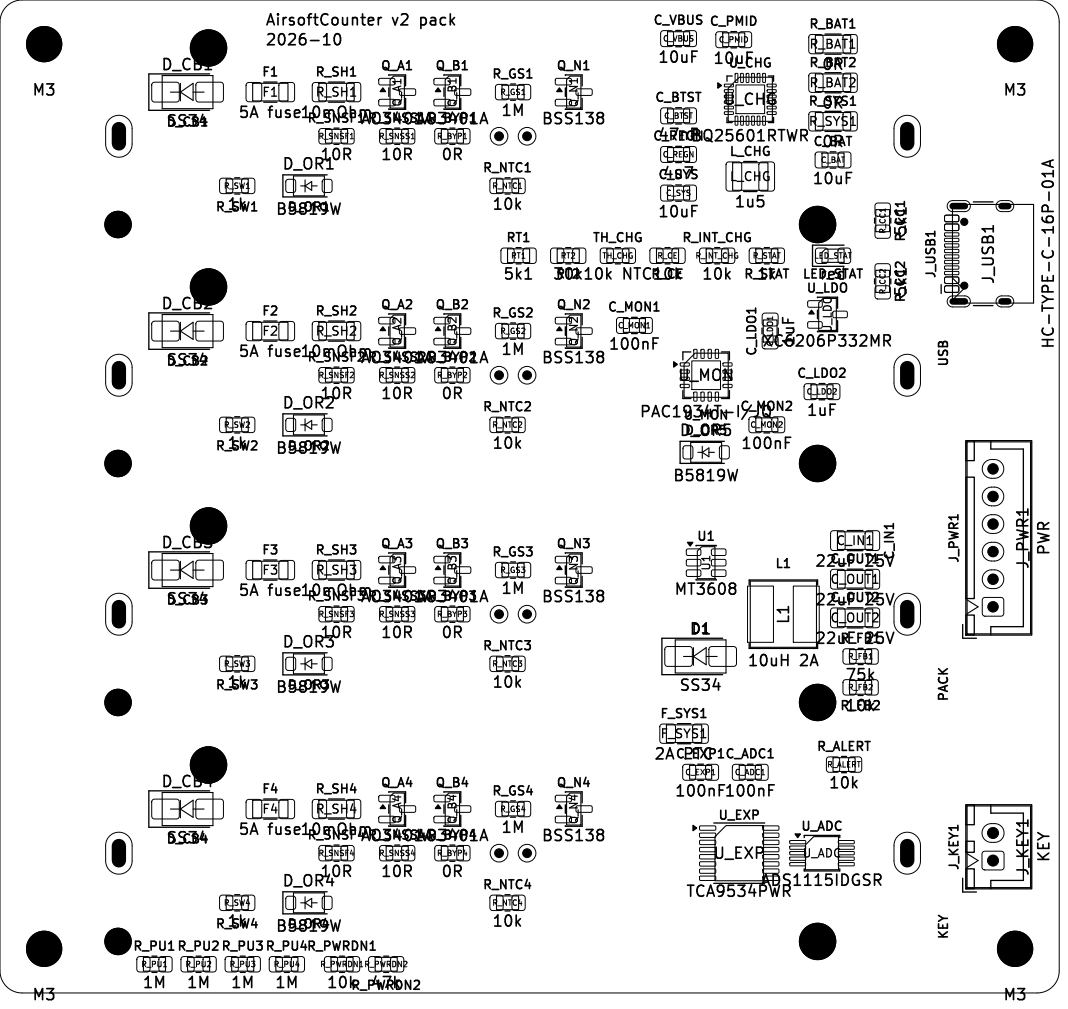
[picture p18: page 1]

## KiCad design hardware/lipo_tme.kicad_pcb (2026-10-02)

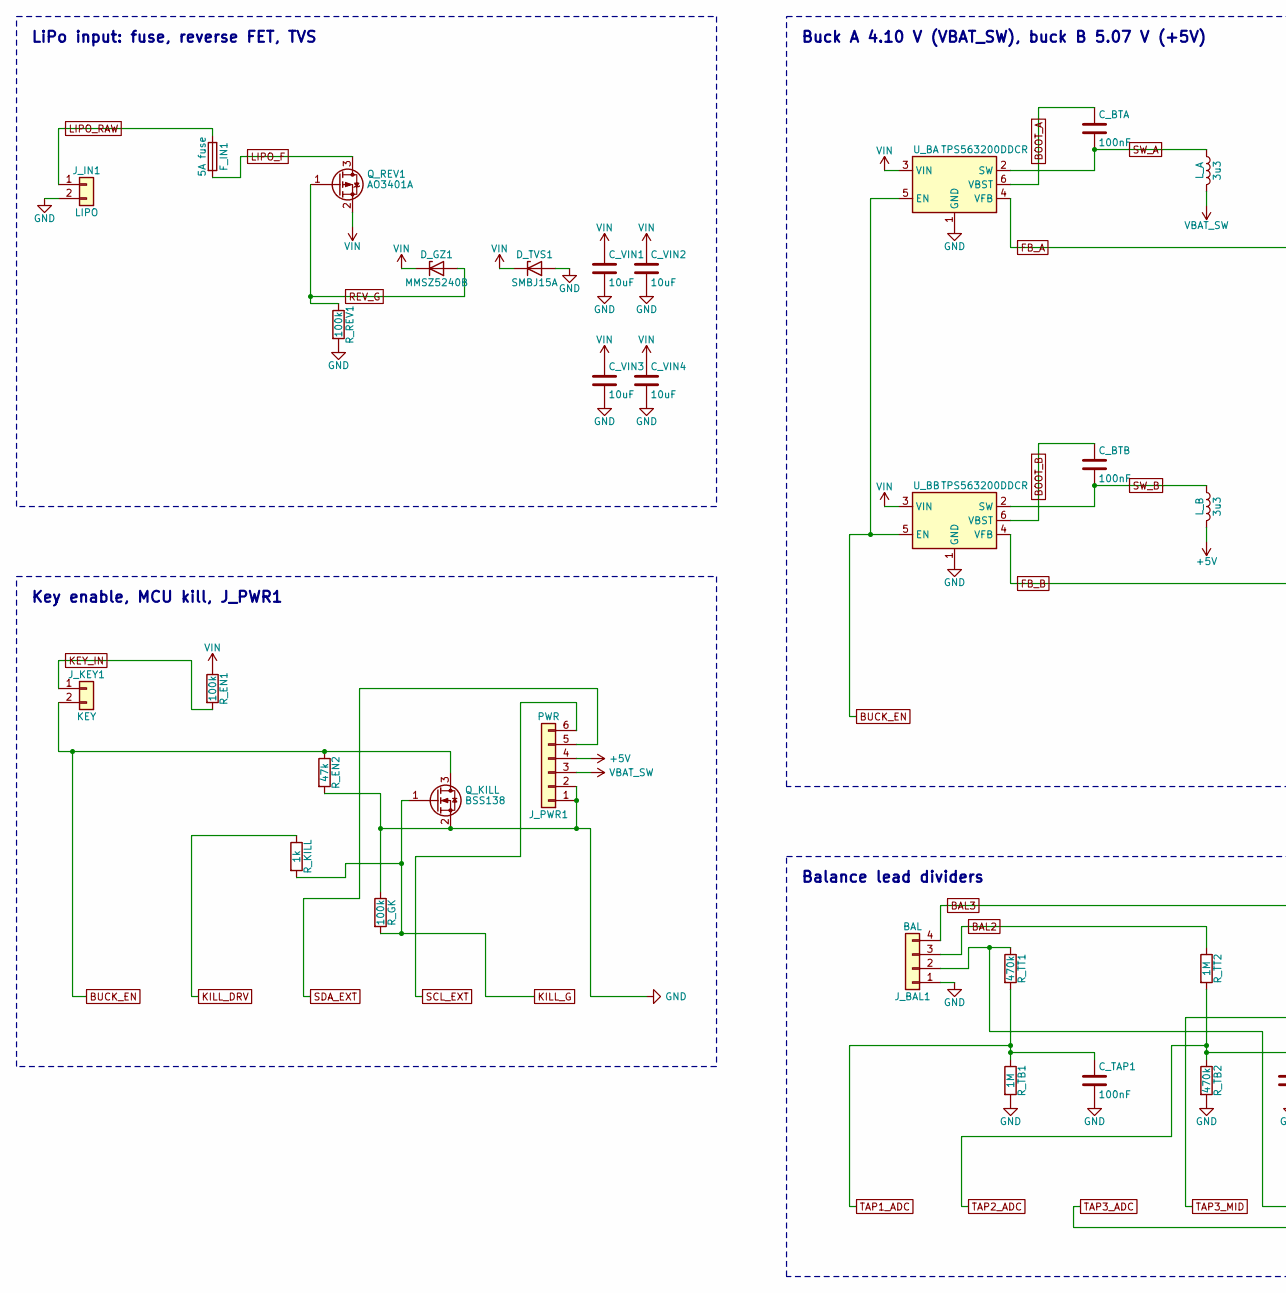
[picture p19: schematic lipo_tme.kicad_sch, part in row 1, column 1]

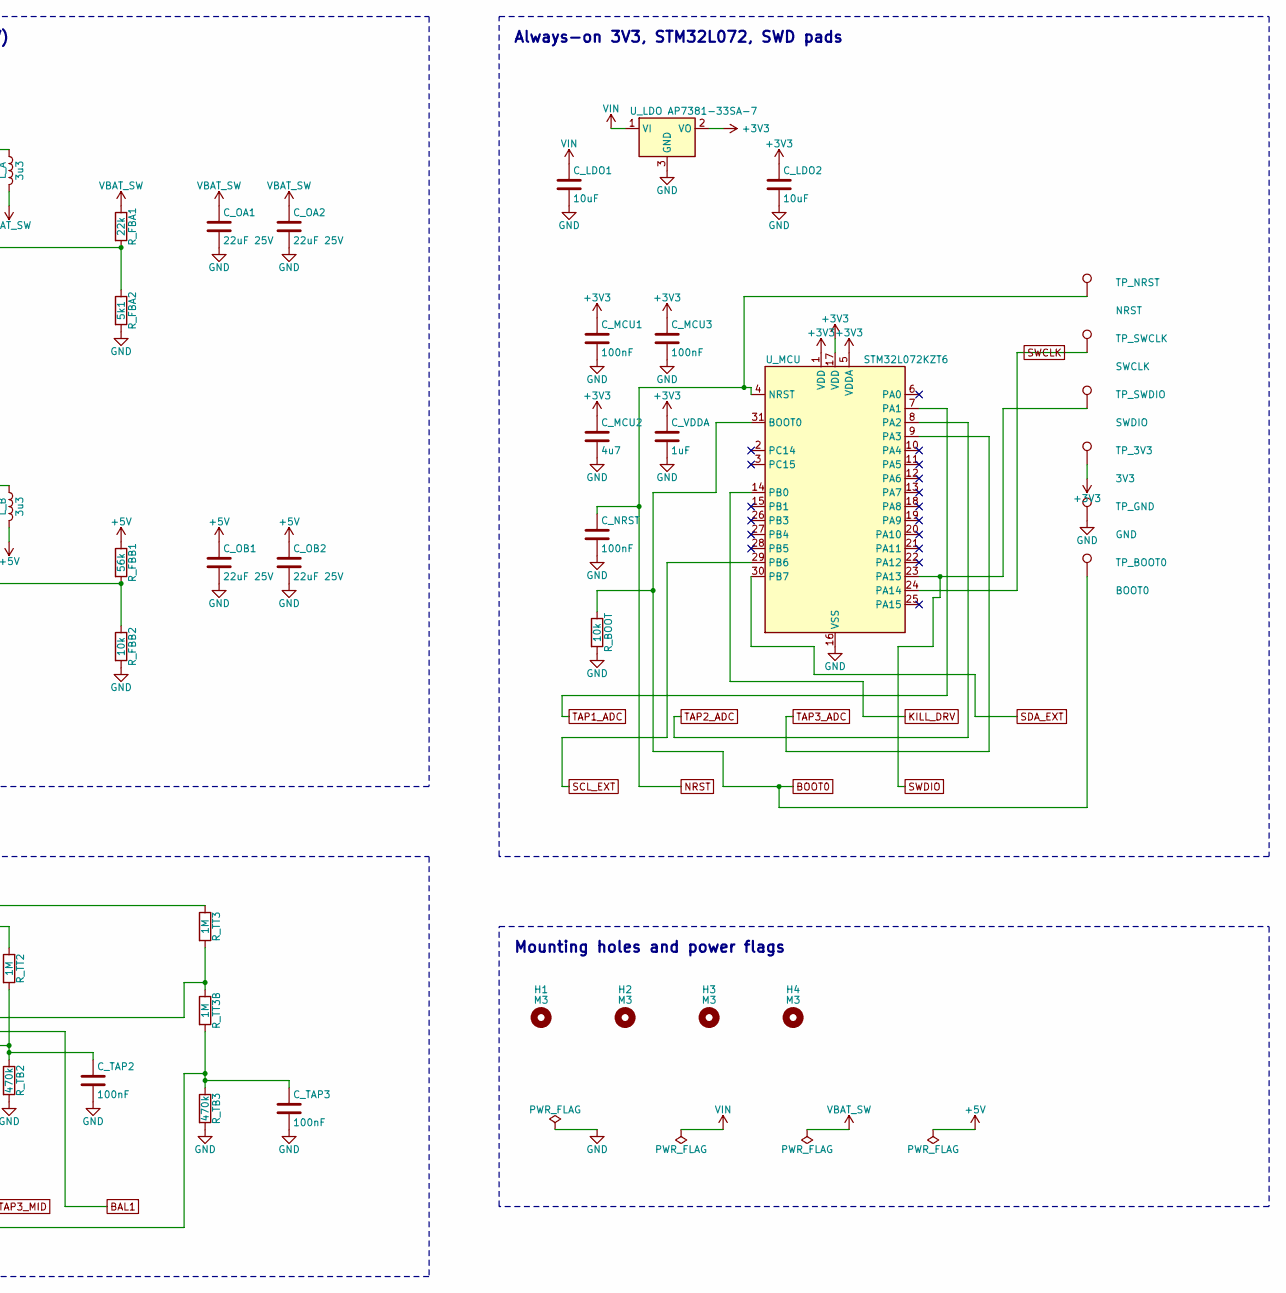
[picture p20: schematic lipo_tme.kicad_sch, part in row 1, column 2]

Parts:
C_BTA: 100nF; C_0805_2012Metric_Pad1.18x1.45mm_HandSolder
C_BTB: 100nF; C_0805_2012Metric_Pad1.18x1.45mm_HandSolder
C_LDO1, C_LDO2: 10uF; C_0805_2012Metric_Pad1.18x1.45mm_HandSolder
C_MCU1, C_MCU3: 100nF; C_0805_2012Metric_Pad1.18x1.45mm_HandSolder
C_MCU2: 4u7; C_0805_2012Metric_Pad1.18x1.45mm_HandSolder
C_NRST: 100nF; C_0805_2012Metric_Pad1.18x1.45mm_HandSolder
C_OA1, C_OA2: 22uF 25V; C_1206_3216Metric_Pad1.33x1.80mm_HandSolder
C_OB1, C_OB2: 22uF 25V; C_1206_3216Metric_Pad1.33x1.80mm_HandSolder
C_TAP1, C_TAP2, C_TAP3: 100nF; C_0805_2012Metric_Pad1.18x1.45mm_HandSolder
C_VDDA: 1uF; C_0805_2012Metric_Pad1.18x1.45mm_HandSolder
C_VIN1, C_VIN2, C_VIN3, C_VIN4: 10uF; C_0805_2012Metric_Pad1.18x1.45mm_HandSolder
D_GZ1: MMSZ5240B; D_SOD-123
D_TVS1: SMBJ15A; D_SMB
F_IN1: 5A fuse; Fuse_1206_3216Metric_Pad1.42x1.75mm_HandSolder
H1, H2, H3, H4: M3; MountingHole_3.2mm_M3
J_BAL1: BAL; JST_XH_B4B-XH-A_1x04_P2.50mm_Vertical
J_IN1: LIPO; SolderWire-1.5sqmm_1x02_P6mm_D1.7mm_OD3mm
J_KEY1: KEY; JST_XH_B2B-XH-A_1x02_P2.50mm_Vertical
J_PWR1: PWR; JST_XH_B6B-XH-A_1x06_P2.50mm_Vertical
L_A: 3u3; L_Bourns_SRN6045TA
L_B: 3u3; L_Bourns_SRN6045TA
Q_KILL: BSS138; SOT-23
Q_REV1: AO3401A; SOT-23
R_BOOT: 10k; R_0805_2012Metric_Pad1.20x1.40mm_HandSolder
R_EN1: 100k; R_0805_2012Metric_Pad1.20x1.40mm_HandSolder
R_EN2: 47k; R_0805_2012Metric_Pad1.20x1.40mm_HandSolder
R_FBA1: 22k; R_0805_2012Metric_Pad1.20x1.40mm_HandSolder
R_FBA2: 5k1; R_0805_2012Metric_Pad1.20x1.40mm_HandSolder
R_FBB1: 56k; R_0805_2012Metric_Pad1.20x1.40mm_HandSolder
R_FBB2: 10k; R_0805_2012Metric_Pad1.20x1.40mm_HandSolder
R_GK: 100k; R_0805_2012Metric_Pad1.20x1.40mm_HandSolder
R_KILL: 1k; R_0805_2012Metric_Pad1.20x1.40mm_HandSolder
R_REV1: 100k; R_0805_2012Metric_Pad1.20x1.40mm_HandSolder
R_TB1: 1M; R_0805_2012Metric_Pad1.20x1.40mm_HandSolder
R_TB2, R_TB3: 470k; R_0805_2012Metric_Pad1.20x1.40mm_HandSolder
R_TT1: 470k; R_0805_2012Metric_Pad1.20x1.40mm_HandSolder
R_TT2, R_TT3, R_TT3B: 1M; R_0805_2012Metric_Pad1.20x1.40mm_HandSolder
TP_3V3: 3V3; TestPoint_Pad_D1.5mm
TP_BOOT0: BOOT0; TestPoint_Pad_D1.5mm
TP_GND: GND; TestPoint_Pad_D1.5mm
TP_NRST: NRST; TestPoint_Pad_D1.5mm
TP_SWCLK: SWCLK; TestPoint_Pad_D1.5mm
TP_SWDIO: SWDIO; TestPoint_Pad_D1.5mm
U_BA: TPS563200DDCR; TSOT-23-6
U_BB: TPS563200DDCR; TSOT-23-6
U_LDO: AP7381-33SA-7; SOT-23
U_MCU: STM32L072KZT6; LQFP-32_7x7mm_P0.8mm

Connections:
+3V3: C_LDO2.1, C_MCU1.1, C_MCU2.1, C_MCU3.1, C_VDDA.1, TP_3V3.1, U_LDO.2 (VO), U_MCU.1 (VDD), U_MCU.5 (VDDA), U_MCU.17 (VDD)
+5V: C_OB1.1, C_OB2.1, J_PWR1.4, L_B.2, R_FBB1.1
BAL1: J_BAL1.2, R_TT1.1
BAL2: J_BAL1.3, R_TT2.1
BAL3: J_BAL1.4, R_TT3.1
BOOT0: R_BOOT.1, TP_BOOT0.1, U_MCU.31 (BOOT0)
BOOT_A: C_BTA.1, U_BA.6 (VBST)
BOOT_B: C_BTB.1, U_BB.6 (VBST)
BUCK_EN: J_KEY1.2, Q_KILL.3 (D), R_EN2.1, U_BA.5 (EN), U_BB.5 (EN)
FB_A: R_FBA1.2, R_FBA2.1, U_BA.4 (VFB)
FB_B: R_FBB1.2, R_FBB2.1, U_BB.4 (VFB)
GND: C_LDO1.2, C_LDO2.2, C_MCU1.2, C_MCU2.2, C_MCU3.2, C_NRST.2, C_OA1.2, C_OA2.2, C_OB1.2, C_OB2.2, C_TAP1.2, C_TAP2.2, C_TAP3.2, C_VDDA.2, C_VIN1.2, C_VIN2.2, C_VIN3.2, C_VIN4.2, D_TVS1.2 (A), J_BAL1.1, J_IN1.2, J_PWR1.1, J_PWR1.2, Q_KILL.2 (S), R_BOOT.2, R_EN2.2, R_FBA2.2, R_FBB2.2, R_GK.1, R_REV1.2, R_TB1.2, R_TB2.2, R_TB3.2, TP_GND.1, U_BA.1 (GND), U_BB.1 (GND), U_LDO.3 (GND), U_MCU.16 (VSS), U_MCU.32 (VSS)
KEY_IN: J_KEY1.1, R_EN1.2
KILL_DRV: R_KILL.1, U_MCU.14 (PB0)
KILL_G: Q_KILL.1 (G), R_GK.2, R_KILL.2
LIPO_F: F_IN1.2, Q_REV1.3 (D)
LIPO_RAW: F_IN1.1, J_IN1.1
NRST: C_NRST.1, TP_NRST.1, U_MCU.4 (NRST)
REV_G: D_GZ1.2 (A), Q_REV1.1 (G), R_REV1.1
SCL_EXT: J_PWR1.6, U_MCU.29 (PB6)
SDA_EXT: J_PWR1.5, U_MCU.30 (PB7)
SWCLK: TP_SWCLK.1, U_MCU.24 (PA14)
SWDIO: TP_SWDIO.1, U_MCU.23 (PA13)
SW_A: C_BTA.2, L_A.1, U_BA.2 (SW)
SW_B: C_BTB.2, L_B.1, U_BB.2 (SW)
TAP1_ADC: C_TAP1.1, R_TB1.1, R_TT1.2, U_MCU.7 (PA1)
TAP2_ADC: C_TAP2.1, R_TB2.1, R_TT2.2, U_MCU.8 (PA2)
TAP3_ADC: C_TAP3.1, R_TB3.1, R_TT3B.2, U_MCU.9 (PA3)
TAP3_MID: R_TT3.2, R_TT3B.1
VBAT_SW: C_OA1.1, C_OA2.1, J_PWR1.3, L_A.2, R_FBA1.1
VIN: C_LDO1.1, C_VIN1.1, C_VIN2.1, C_VIN3.1, C_VIN4.1, D_GZ1.1 (K), D_TVS1.1 (K), Q_REV1.2 (S), R_EN1.1, U_BA.3 (VIN), U_BB.3 (VIN), U_LDO.1 (VI)

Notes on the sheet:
LiPo input: fuse, reverse FET, TVS
Buck A 4.10 V (VBAT_SW), buck B 5.07 V (+5V)
Key enable, MCU kill, J_PWR1
Always-on 3V3, STM32L072, SWD pads
Balance lead dividers
Mounting holes and power flags

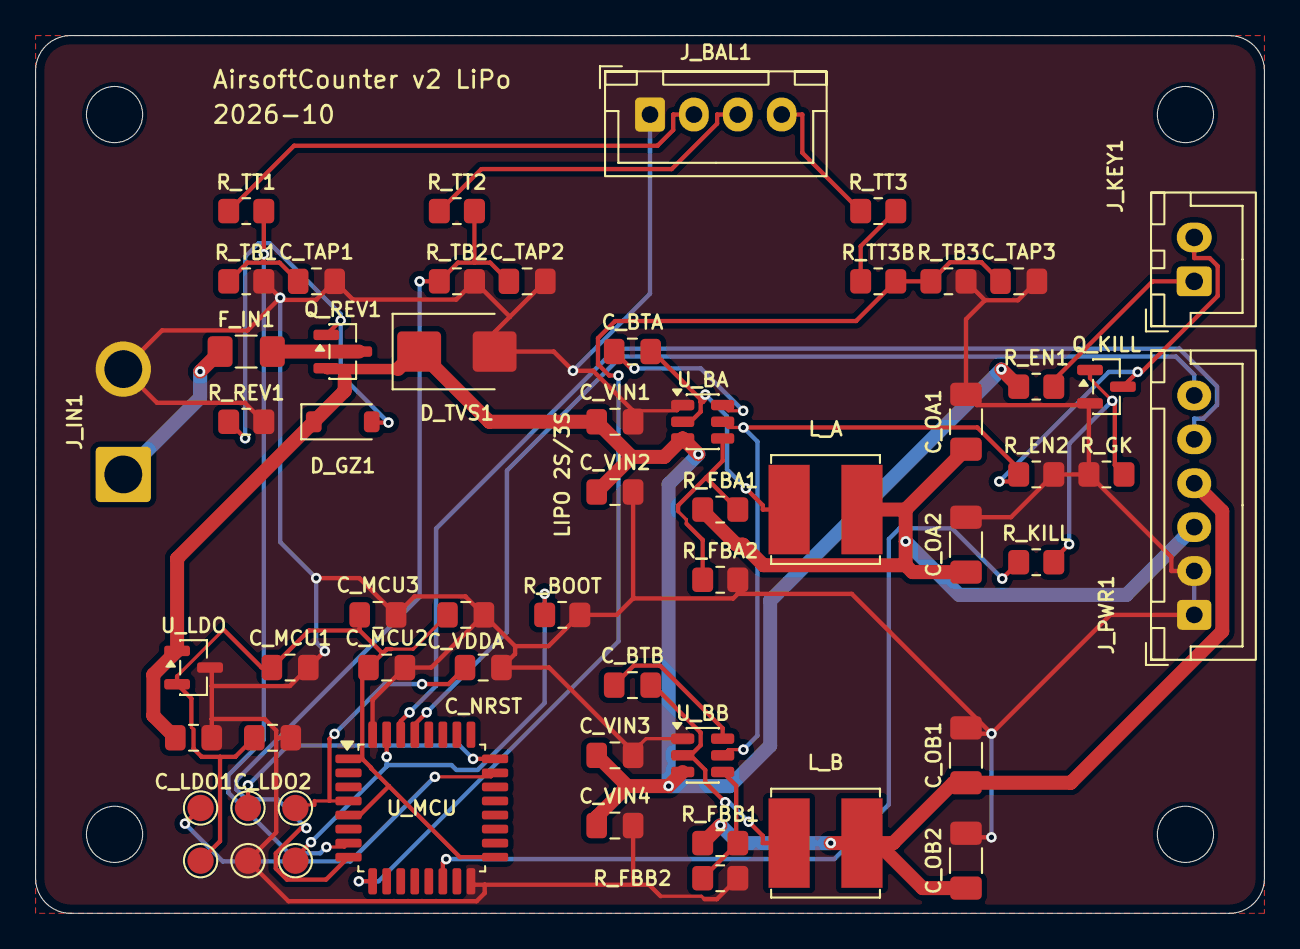
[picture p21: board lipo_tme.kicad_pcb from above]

Board: 2 copper layers, 70.0 x 50.0 mm, 62 parts (0 on the bottom side), 31 nets.

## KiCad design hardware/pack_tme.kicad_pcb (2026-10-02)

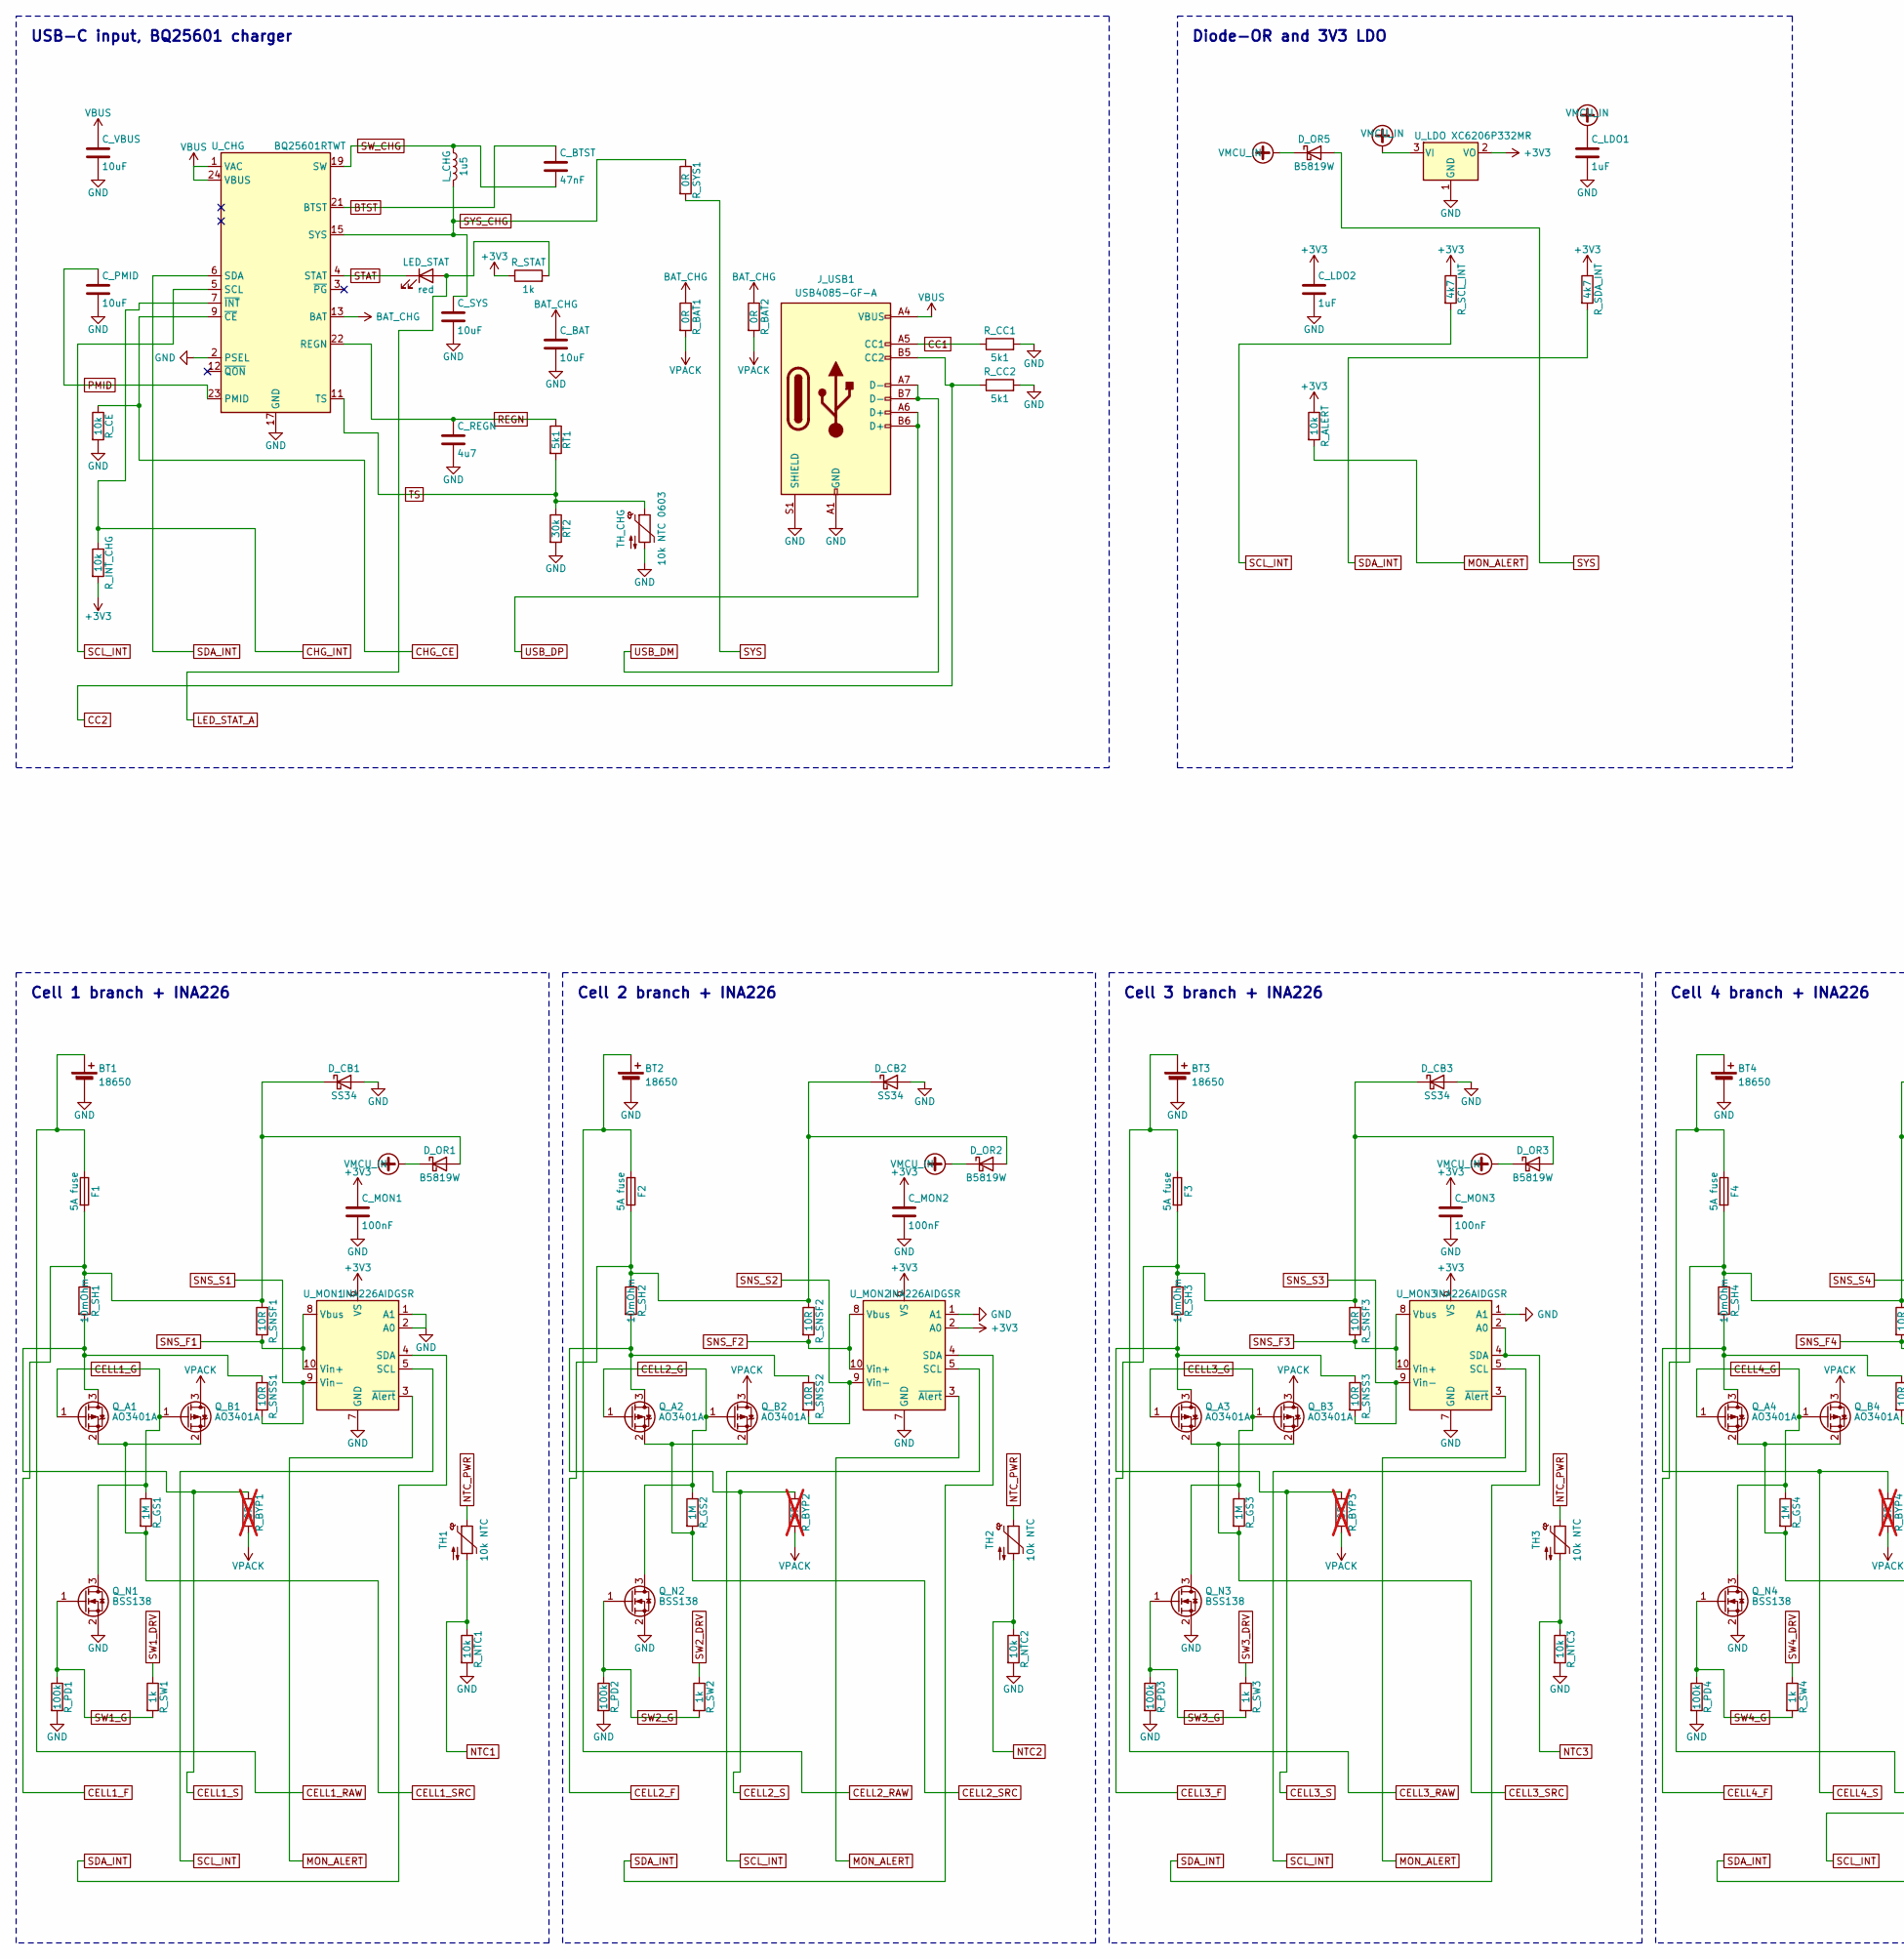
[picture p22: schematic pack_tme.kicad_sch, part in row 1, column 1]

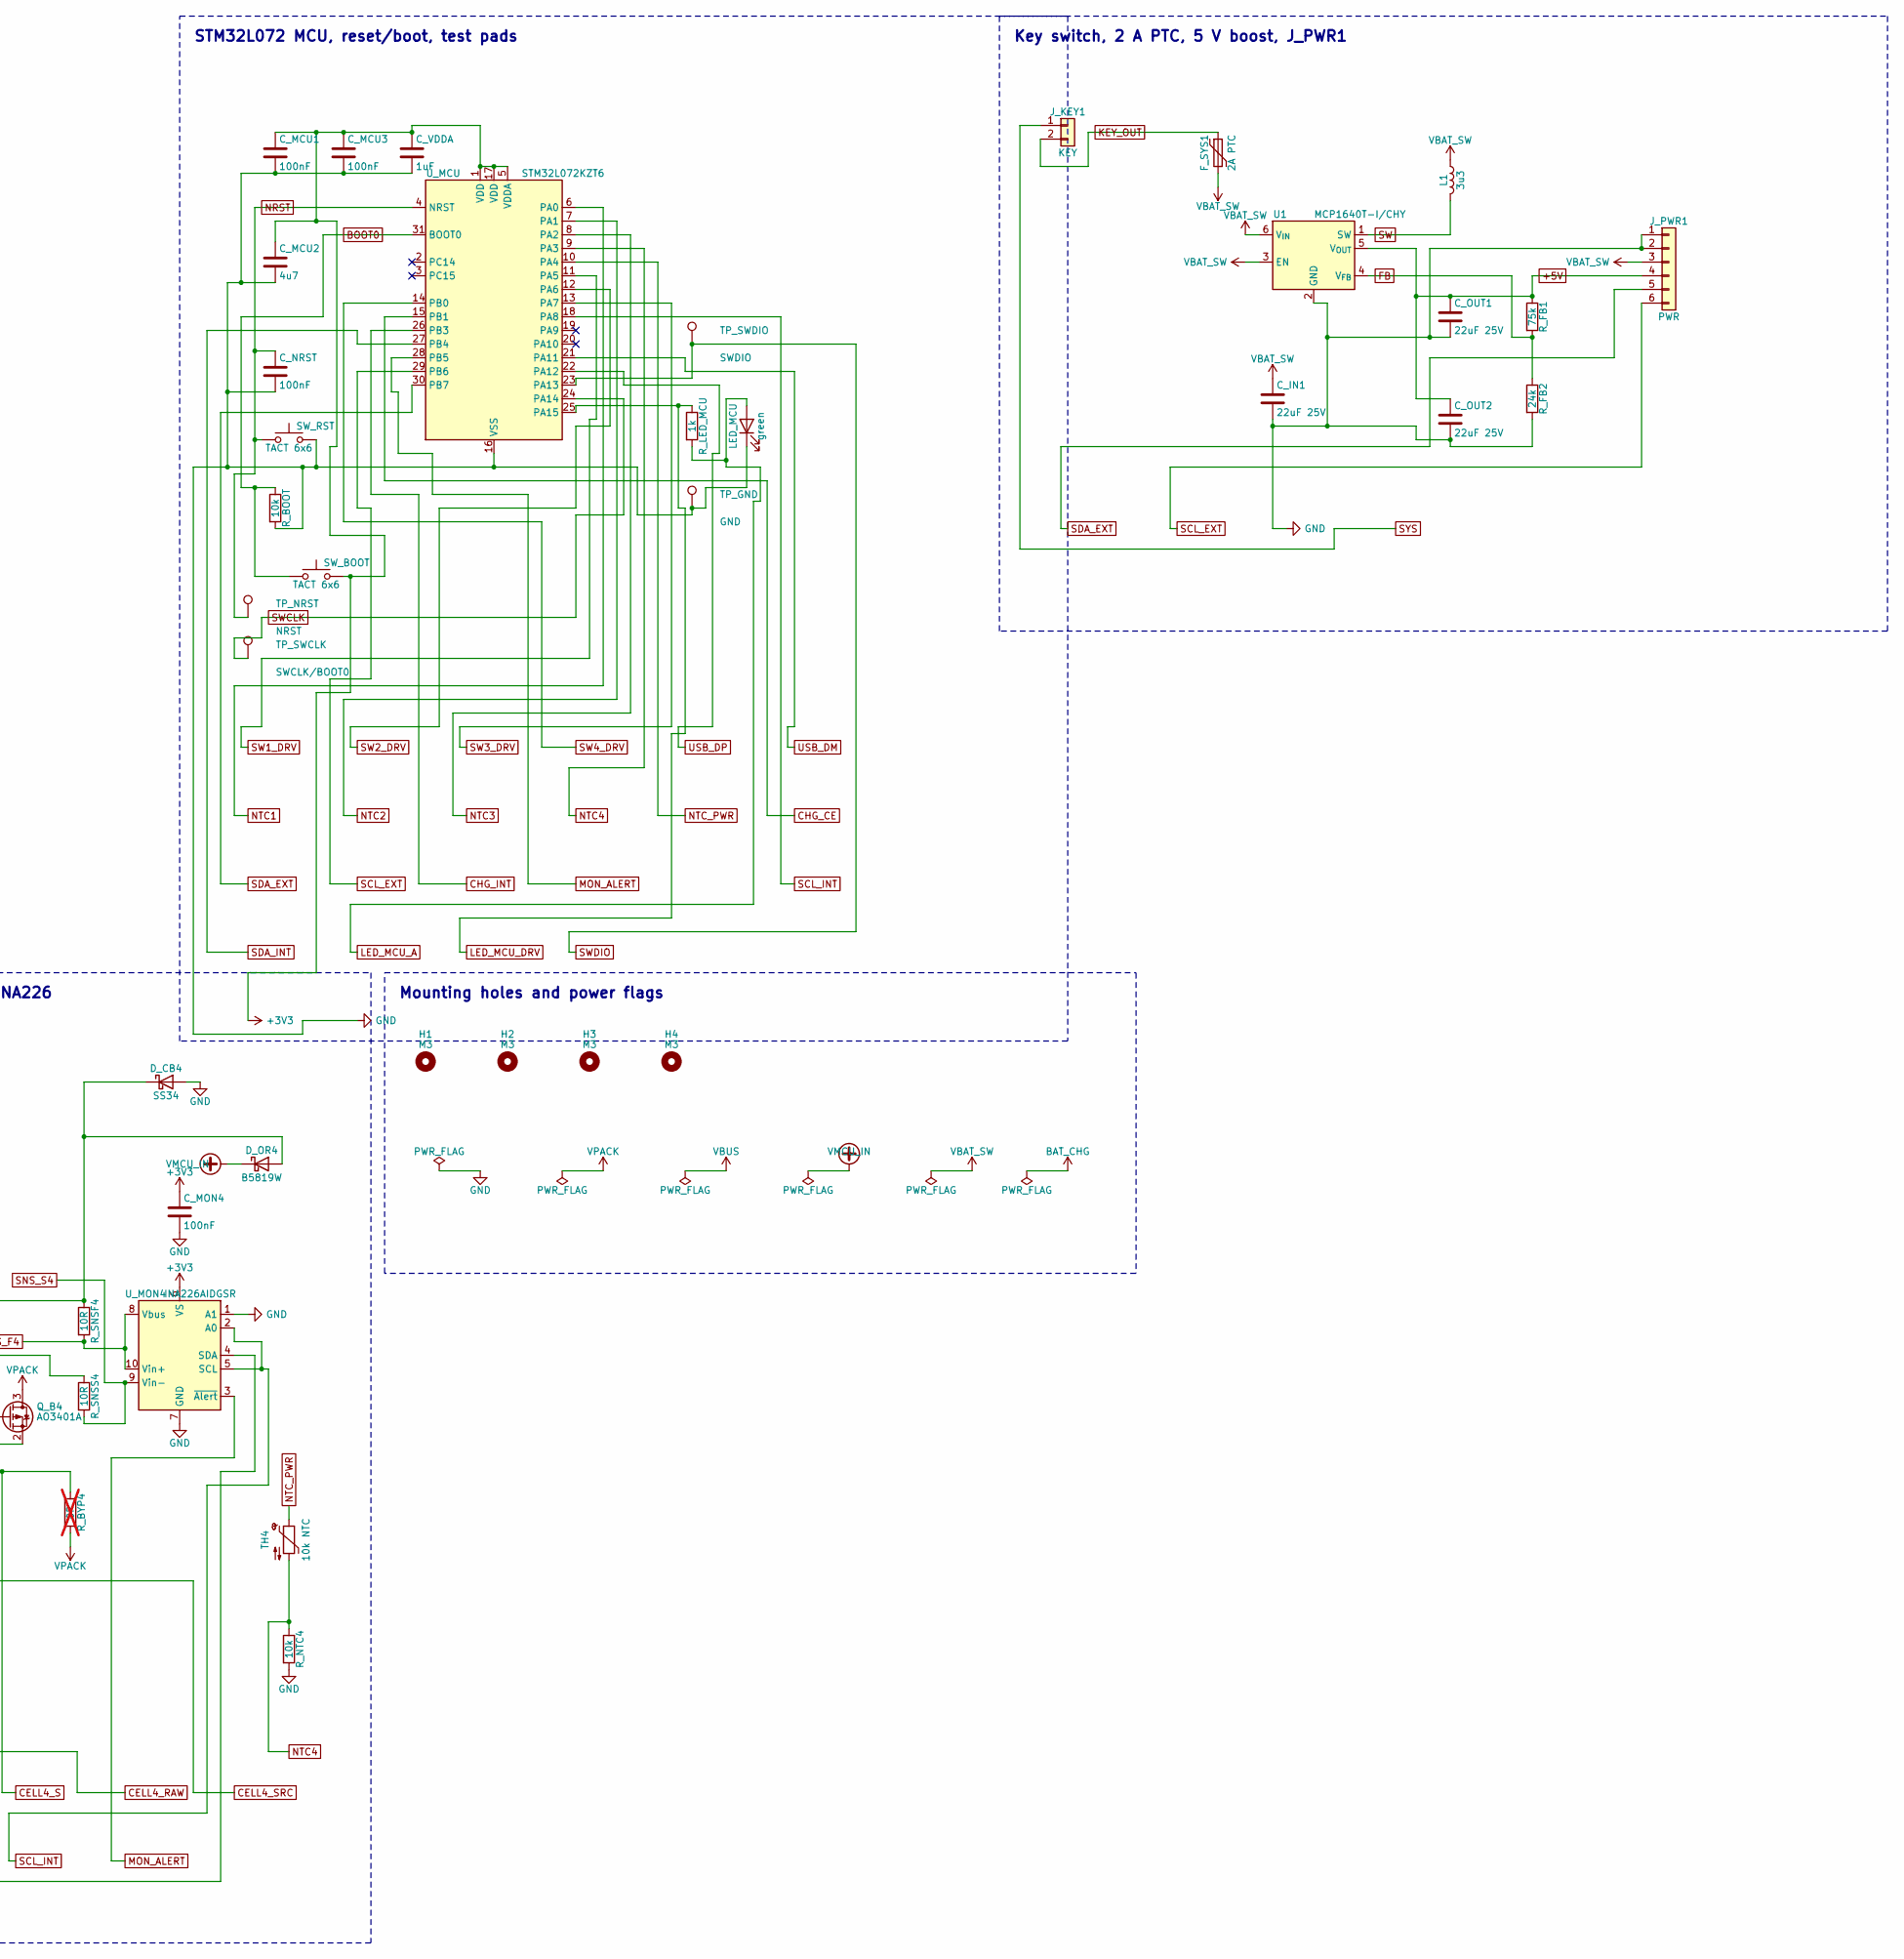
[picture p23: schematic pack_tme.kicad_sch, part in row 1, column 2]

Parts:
BT1, BT2, BT3, BT4: 18650; BatteryHolder_MYOUNG_BH-18650-A6AJ012
C_BAT: 10uF; C_0805_2012Metric_Pad1.18x1.45mm_HandSolder
C_BTST: 47nF; C_0805_2012Metric_Pad1.18x1.45mm_HandSolder
C_IN1: 22uF 25V; C_1206_3216Metric_Pad1.33x1.80mm_HandSolder
C_LDO1, C_LDO2: 1uF; C_0805_2012Metric_Pad1.18x1.45mm_HandSolder
C_MCU1, C_MCU3: 100nF; C_0805_2012Metric_Pad1.18x1.45mm_HandSolder
C_MCU2: 4u7; C_0805_2012Metric_Pad1.18x1.45mm_HandSolder
C_MON1, C_MON2, C_MON3, C_MON4: 100nF; C_0805_2012Metric_Pad1.18x1.45mm_HandSolder
C_NRST: 100nF; C_0805_2012Metric_Pad1.18x1.45mm_HandSolder
C_OUT1, C_OUT2: 22uF 25V; C_1206_3216Metric_Pad1.33x1.80mm_HandSolder
C_PMID: 10uF; C_0805_2012Metric_Pad1.18x1.45mm_HandSolder
C_REGN: 4u7; C_0805_2012Metric_Pad1.18x1.45mm_HandSolder
C_SYS: 10uF; C_0805_2012Metric_Pad1.18x1.45mm_HandSolder
C_VBUS: 10uF; C_0805_2012Metric_Pad1.18x1.45mm_HandSolder
C_VDDA: 1uF; C_0805_2012Metric_Pad1.18x1.45mm_HandSolder
D_CB1, D_CB2, D_CB3, D_CB4: SS34; D_SMA
D_OR1, D_OR2, D_OR3, D_OR4, D_OR5: B5819W; D_SOD-123
F1, F2, F3, F4: 5A fuse; Fuse_1206_3216Metric_Pad1.42x1.75mm_HandSolder
F_SYS1: 2A PTC; Fuse_1206_3216Metric_Pad1.42x1.75mm_HandSolder
H1, H2, H3, H4: M3; MountingHole_3.2mm_M3
J_KEY1: KEY; JST_XH_B2B-XH-A_1x02_P2.50mm_Vertical
J_PWR1: PWR; JST_XH_B6B-XH-A_1x06_P2.50mm_Vertical
J_USB1: USB4085-GF-A; USB_C_Receptacle_GCT_USB4085
L1: 3u3; L_Bourns_SRN6045TA
LED_MCU: green; LED_0805_2012Metric_Pad1.15x1.40mm_HandSolder
LED_STAT: red; LED_0805_2012Metric_Pad1.15x1.40mm_HandSolder
L_CHG: 1u5; L_1210_3225Metric_Pad1.42x2.65mm_HandSolder
Q_A1, Q_A2, Q_A3, Q_A4: AO3401A; SOT-23
Q_B1, Q_B2, Q_B3, Q_B4: AO3401A; SOT-23
Q_N1, Q_N2, Q_N3, Q_N4: BSS138; SOT-23
RT1: 5k1; R_0805_2012Metric_Pad1.20x1.40mm_HandSolder
RT2: 30k; R_0805_2012Metric_Pad1.20x1.40mm_HandSolder
R_ALERT: 10k; R_0805_2012Metric_Pad1.20x1.40mm_HandSolder
R_BAT1, R_BAT2: 0R; R_1206_3216Metric_Pad1.30x1.75mm_HandSolder
R_BOOT: 10k; R_0805_2012Metric_Pad1.20x1.40mm_HandSolder
R_BYP1, R_BYP2, R_BYP3, R_BYP4: 0R; R_0805_2012Metric_Pad1.20x1.40mm_HandSolder; not fitted
R_CC1, R_CC2: 5k1; R_0805_2012Metric_Pad1.20x1.40mm_HandSolder
R_CE: 10k; R_0805_2012Metric_Pad1.20x1.40mm_HandSolder
R_FB1: 75k; R_0805_2012Metric_Pad1.20x1.40mm_HandSolder
R_FB2: 24k; R_0805_2012Metric_Pad1.20x1.40mm_HandSolder
R_GS1, R_GS2, R_GS3, R_GS4: 1M; R_0805_2012Metric_Pad1.20x1.40mm_HandSolder
R_INT_CHG: 10k; R_0805_2012Metric_Pad1.20x1.40mm_HandSolder
R_LED_MCU: 1k; R_0805_2012Metric_Pad1.20x1.40mm_HandSolder
R_NTC1, R_NTC2, R_NTC3, R_NTC4: 10k; R_0805_2012Metric_Pad1.20x1.40mm_HandSolder
R_PD1, R_PD2, R_PD3, R_PD4: 100k; R_0805_2012Metric_Pad1.20x1.40mm_HandSolder
R_SCL_INT: 4k7; R_0805_2012Metric_Pad1.20x1.40mm_HandSolder
R_SDA_INT: 4k7; R_0805_2012Metric_Pad1.20x1.40mm_HandSolder
R_SH1, R_SH2, R_SH3, R_SH4: 10mOhm; R_1206_3216Metric_Pad1.30x1.75mm_HandSolder
R_SNSF1, R_SNSF2, R_SNSF3, R_SNSF4: 10R; R_0805_2012Metric_Pad1.20x1.40mm_HandSolder
R_SNSS1, R_SNSS2, R_SNSS3, R_SNSS4: 10R; R_0805_2012Metric_Pad1.20x1.40mm_HandSolder
R_STAT: 1k; R_0805_2012Metric_Pad1.20x1.40mm_HandSolder
R_SW1, R_SW2, R_SW3, R_SW4: 1k; R_0805_2012Metric_Pad1.20x1.40mm_HandSolder
R_SYS1: 0R; R_1206_3216Metric_Pad1.30x1.75mm_HandSolder
SW_BOOT: TACT 6x6; SW_PUSH_6mm
SW_RST: TACT 6x6; SW_PUSH_6mm
TH1, TH2, TH3, TH4: 10k NTC; NTC_Bead_P2.54mm
TH_CHG: 10k NTC 0603; R_0805_2012Metric_Pad1.20x1.40mm_HandSolder
TP_GND: GND; TestPoint_Pad_D1.5mm
TP_NRST: NRST; TestPoint_Pad_D1.5mm
TP_SWCLK: SWCLK/BOOT0; TestPoint_Pad_D1.5mm
TP_SWDIO: SWDIO; TestPoint_Pad_D1.5mm
U1: MCP1640T-I/CHY; SOT-23-6
U_CHG: BQ25601RTWT; QFN-24-1EP_4x4mm_P0.5mm_EP2.6x2.6mm_HandSolder
U_LDO: XC6206P332MR; SOT-23-3
U_MCU: STM32L072KZT6; LQFP-32_7x7mm_P0.8mm
U_MON1, U_MON2, U_MON3, U_MON4: INA226AIDGSR; VSSOP-10_3x3mm_P0.5mm

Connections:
+3V3: C_LDO2.1, C_MCU1.1, C_MCU2.1, C_MCU3.1, C_MON1.1, C_MON2.1, C_MON3.1, C_MON4.1, C_VDDA.1, R_ALERT.1, R_INT_CHG.2, R_SCL_INT.1, R_SDA_INT.1, R_STAT.1, SW_BOOT.2, U_LDO.2 (VO), U_MCU.1 (VDD), U_MCU.5 (VDDA), U_MCU.17 (VDD), U_MON1.6 (VS), U_MON2.2 (A0), U_MON2.6 (VS), U_MON3.6 (VS), U_MON4.6 (VS)
+5V: C_OUT1.1, C_OUT2.1, J_PWR1.4, R_FB1.1, U1.5 (V_{OUT})
BAT_CHG: C_BAT.1, R_BAT1.1, R_BAT2.1, U_CHG.13 (BAT), U_CHG.14 (BAT)
BOOT0: R_BOOT.1, SW_BOOT.1, U_MCU.31 (BOOT0)
BTST: C_BTST.1, U_CHG.21 (BTST)
CC1: J_USB1.A5 (CC1), R_CC1.1
CC2: J_USB1.B5 (CC2), R_CC2.1
CELL1_F: D_CB1.1 (K), D_OR1.2 (A), F1.2, R_SH1.1, R_SNSF1.1
CELL1_G: Q_A1.1 (G), Q_B1.1 (G), Q_N1.3 (D), R_GS1.1
CELL1_RAW: BT1.1 (+), F1.1
CELL1_S: Q_A1.3 (D), R_BYP1.1, R_SH1.2, R_SNSS1.1
CELL1_SRC: Q_A1.2 (S), Q_B1.2 (S), R_GS1.2
CELL2_F: D_CB2.1 (K), D_OR2.2 (A), F2.2, R_SH2.1, R_SNSF2.1
CELL2_G: Q_A2.1 (G), Q_B2.1 (G), Q_N2.3 (D), R_GS2.1
CELL2_RAW: BT2.1 (+), F2.1
CELL2_S: Q_A2.3 (D), R_BYP2.1, R_SH2.2, R_SNSS2.1
CELL2_SRC: Q_A2.2 (S), Q_B2.2 (S), R_GS2.2
CELL3_F: D_CB3.1 (K), D_OR3.2 (A), F3.2, R_SH3.1, R_SNSF3.1
CELL3_G: Q_A3.1 (G), Q_B3.1 (G), Q_N3.3 (D), R_GS3.1
CELL3_RAW: BT3.1 (+), F3.1
CELL3_S: Q_A3.3 (D), R_BYP3.1, R_SH3.2, R_SNSS3.1
CELL3_SRC: Q_A3.2 (S), Q_B3.2 (S), R_GS3.2
CELL4_F: D_CB4.1 (K), D_OR4.2 (A), F4.2, R_SH4.1, R_SNSF4.1
CELL4_G: Q_A4.1 (G), Q_B4.1 (G), Q_N4.3 (D), R_GS4.1
CELL4_RAW: BT4.1 (+), F4.1
CELL4_S: Q_A4.3 (D), R_BYP4.1, R_SH4.2, R_SNSS4.1
CELL4_SRC: Q_A4.2 (S), Q_B4.2 (S), R_GS4.2
CHG_CE: R_CE.1, U_CHG.9 (~CE), U_MCU.15 (PB1)
CHG_INT: R_INT_CHG.1, U_CHG.7 (~INT), U_MCU.26 (PB3)
FB: R_FB1.2, R_FB2.1, U1.4 (V_{FB})
GND: BT1.2 (-), BT2.2 (-), BT3.2 (-), BT4.2 (-), C_BAT.2, C_IN1.2, C_LDO1.2, C_LDO2.2, C_MCU1.2, C_MCU2.2, C_MCU3.2, C_MON1.2, C_MON2.2, C_MON3.2, C_MON4.2, C_NRST.2, C_OUT1.2, C_OUT2.2, C_PMID.2, C_REGN.2, C_SYS.2, C_VBUS.2, C_VDDA.2, D_CB1.2 (A), D_CB2.2 (A), D_CB3.2 (A), D_CB4.2 (A), J_PWR1.1, J_PWR1.2, J_USB1.A1 (GND), J_USB1.A12 (GND), J_USB1.B1 (GND), J_USB1.B12 (GND), J_USB1.S1 (SHIELD), LED_MCU.1 (K), Q_N1.2 (S), Q_N2.2 (S), Q_N3.2 (S), Q_N4.2 (S), RT2.2, R_BOOT.2, R_CC1.2, R_CC2.2, R_CE.2, R_FB2.2, R_NTC1.2, R_NTC2.2, R_NTC3.2, R_NTC4.2, R_PD1.2, R_PD2.2, R_PD3.2, R_PD4.2, SW_RST.2, TH_CHG.2, TP_GND.1, U1.2 (GND), U_CHG.2 (PSEL), U_CHG.17 (GND), U_CHG.18 (GND), U_CHG.25 (GND), U_LDO.1 (GND), U_MCU.16 (VSS), U_MCU.32 (VSS), U_MON1.1 (A1), U_MON1.2 (A0), U_MON1.7 (GND), U_MON2.1 (A1), U_MON2.7 (GND), U_MON3.1 (A1), U_MON3.7 (GND), U_MON4.1 (A1), U_MON4.7 (GND)
KEY_OUT: F_SYS1.1, J_KEY1.2
LED_MCU_A: LED_MCU.2 (A), R_LED_MCU.2
LED_MCU_DRV: R_LED_MCU.1, U_MCU.25 (PA15)
LED_STAT_A: LED_STAT.2 (A), R_STAT.2
MON_ALERT: R_ALERT.2, U_MCU.28 (PB5), U_MON1.3 (~Alert), U_MON2.3 (~Alert), U_MON3.3 (~Alert), U_MON4.3 (~Alert)
NRST: C_NRST.1, SW_RST.1, TP_NRST.1, U_MCU.4 (NRST)
NTC1: R_NTC1.1, TH1.2, U_MCU.6 (PA0)
NTC2: R_NTC2.1, TH2.2, U_MCU.7 (PA1)
NTC3: R_NTC3.1, TH3.2, U_MCU.8 (PA2)
NTC4: R_NTC4.1, TH4.2, U_MCU.9 (PA3)
NTC_PWR: TH1.1, TH2.1, TH3.1, TH4.1, U_MCU.10 (PA4)
PMID: C_PMID.1, U_CHG.23 (PMID)
REGN: C_REGN.1, RT1.1, U_CHG.22 (REGN)
SCL_EXT: J_PWR1.6, U_MCU.29 (PB6)
SCL_INT: R_SCL_INT.2, U_CHG.5 (SCL), U_MCU.18 (PA8), U_MON1.5 (SCL), U_MON2.5 (SCL), U_MON3.5 (SCL), U_MON4.2 (A0), U_MON4.5 (SCL)
SDA_EXT: J_PWR1.5, U_MCU.30 (PB7)
SDA_INT: R_SDA_INT.2, U_CHG.6 (SDA), U_MCU.27 (PB4), U_MON1.4 (SDA), U_MON2.4 (SDA), U_MON3.2 (A0), U_MON3.4 (SDA), U_MON4.4 (SDA)
SNS_F1: R_SNSF1.2, U_MON1.8 (Vbus), U_MON1.10 (Vin+)
SNS_F2: R_SNSF2.2, U_MON2.8 (Vbus), U_MON2.10 (Vin+)
SNS_F3: R_SNSF3.2, U_MON3.8 (Vbus), U_MON3.10 (Vin+)
SNS_F4: R_SNSF4.2, U_MON4.8 (Vbus), U_MON4.10 (Vin+)
SNS_S1: R_SNSS1.2, U_MON1.9 (Vin-)
SNS_S2: R_SNSS2.2, U_MON2.9 (Vin-)
SNS_S3: R_SNSS3.2, U_MON3.9 (Vin-)
SNS_S4: R_SNSS4.2, U_MON4.9 (Vin-)
STAT: LED_STAT.1 (K), U_CHG.4 (STAT)
SW: L1.2, U1.1 (SW)
SW1_DRV: R_SW1.1, U_MCU.11 (PA5)
SW1_G: Q_N1.1 (G), R_PD1.1, R_SW1.2
SW2_DRV: R_SW2.1, U_MCU.12 (PA6)
SW2_G: Q_N2.1 (G), R_PD2.1, R_SW2.2
SW3_DRV: R_SW3.1, U_MCU.13 (PA7)
SW3_G: Q_N3.1 (G), R_PD3.1, R_SW3.2
SW4_DRV: R_SW4.1, U_MCU.14 (PB0)
SW4_G: Q_N4.1 (G), R_PD4.1, R_SW4.2
SWCLK: TP_SWCLK.1, U_MCU.24 (PA14)
SWDIO: TP_SWDIO.1, U_MCU.23 (PA13)
SW_CHG: C_BTST.2, L_CHG.1, U_CHG.19 (SW), U_CHG.20 (SW)
SYS: D_OR5.2 (A), J_KEY1.1, R_SYS1.2
SYS_CHG: C_SYS.1, L_CHG.2, R_SYS1.1, U_CHG.15 (SYS), U_CHG.16 (SYS)
TS: RT1.2, RT2.1, TH_CHG.1, U_CHG.11 (TS)
USB_DM: J_USB1.A7 (D-), J_USB1.B7 (D-), U_MCU.21 (PA11)
USB_DP: J_USB1.A6 (D+), J_USB1.B6 (D+), U_MCU.22 (PA12)
VBAT_SW: C_IN1.1, F_SYS1.2, J_PWR1.3, L1.1, U1.3 (EN), U1.6 (V_{IN})
VBUS: C_VBUS.1, J_USB1.A4 (VBUS), J_USB1.A9 (VBUS), J_USB1.B4 (VBUS), J_USB1.B9 (VBUS), U_CHG.1 (VAC), U_CHG.24 (VBUS)
VMCU_IN: C_LDO1.1, D_OR1.1 (K), D_OR2.1 (K), D_OR3.1 (K), D_OR4.1 (K), D_OR5.1 (K), U_LDO.3 (VI)
VPACK: Q_B1.3 (D), Q_B2.3 (D), Q_B3.3 (D), Q_B4.3 (D), R_BAT1.2, R_BAT2.2, R_BYP1.2, R_BYP2.2, R_BYP3.2, R_BYP4.2

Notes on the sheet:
USB-C input, BQ25601 charger
Diode-OR and 3V3 LDO
STM32L072 MCU, reset/boot, test pads
Key switch, 2 A PTC, 5 V boost, J_PWR1
Cell 1 branch + INA226
Cell 2 branch + INA226
Cell 3 branch + INA226
Cell 4 branch + INA226
Mounting holes and power flags

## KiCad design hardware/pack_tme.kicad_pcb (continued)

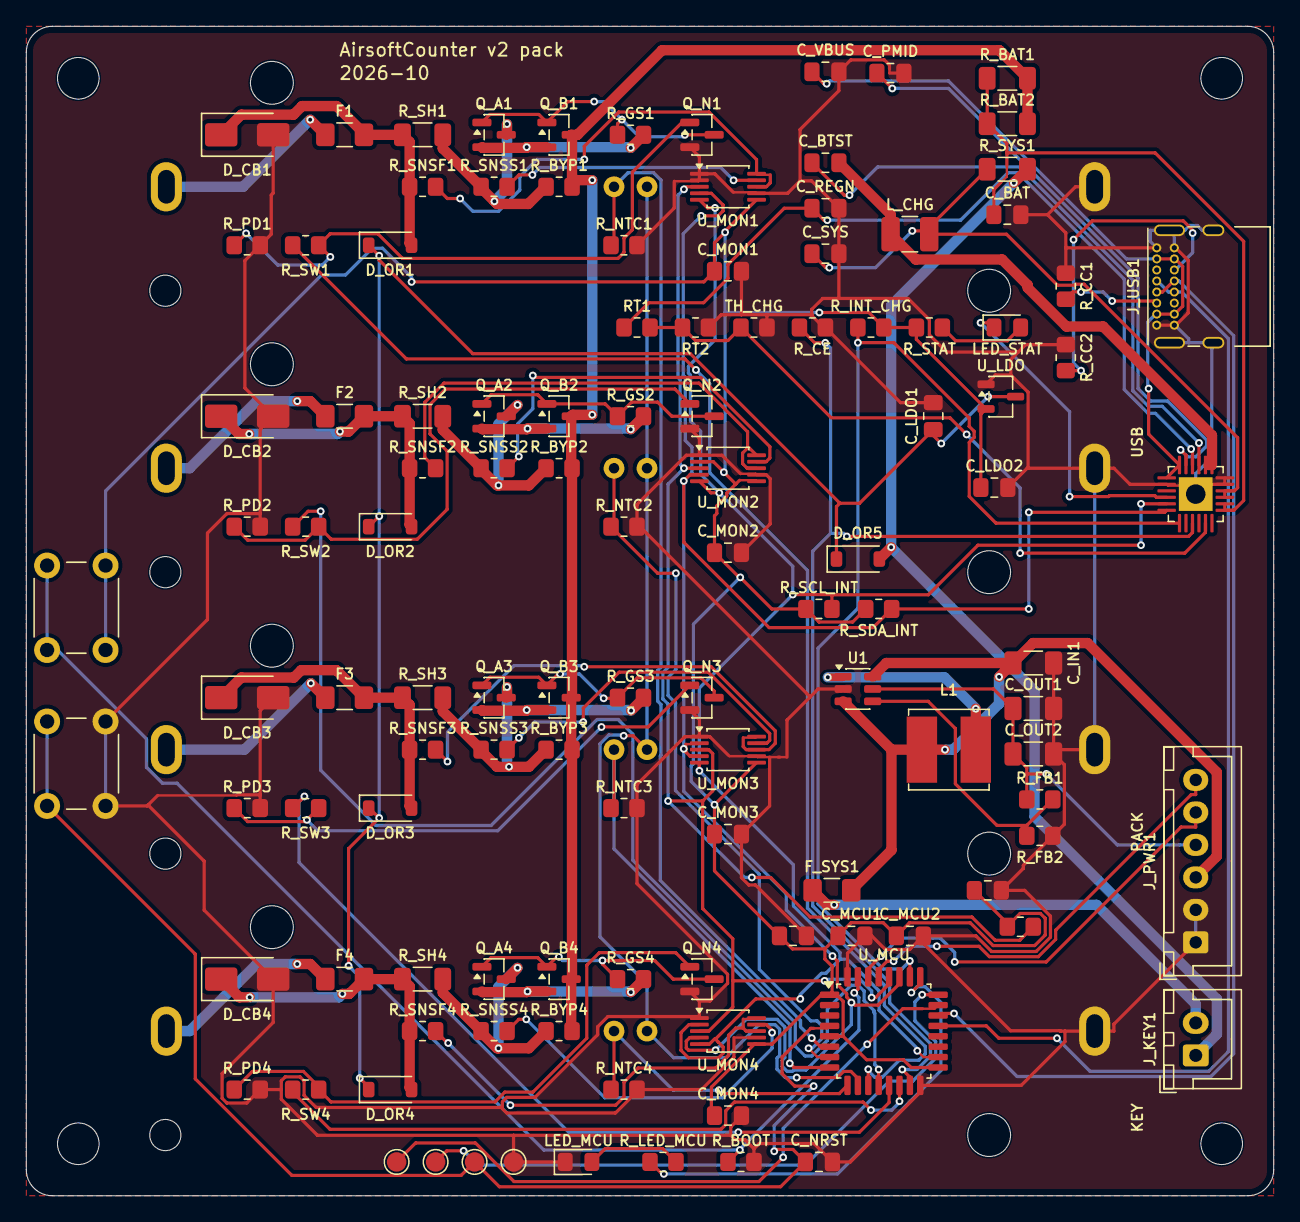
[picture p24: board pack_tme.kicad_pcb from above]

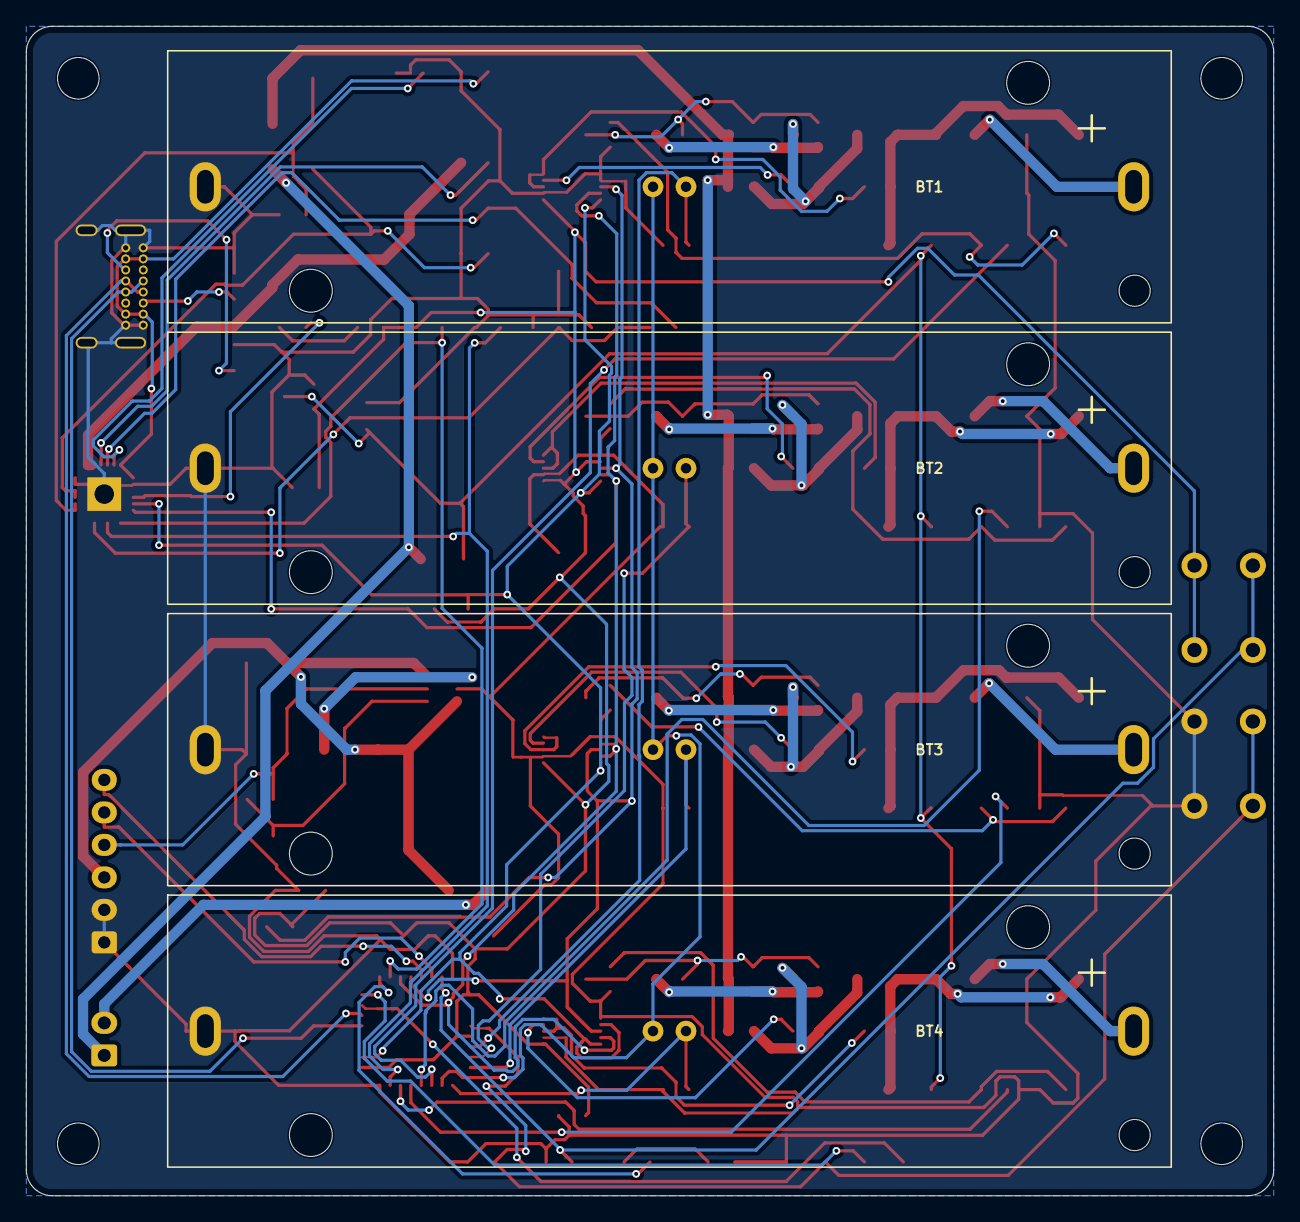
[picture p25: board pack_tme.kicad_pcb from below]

Board: 2 copper layers, 96.0 x 90.0 mm, 129 parts (8 on the bottom side), 78 nets.

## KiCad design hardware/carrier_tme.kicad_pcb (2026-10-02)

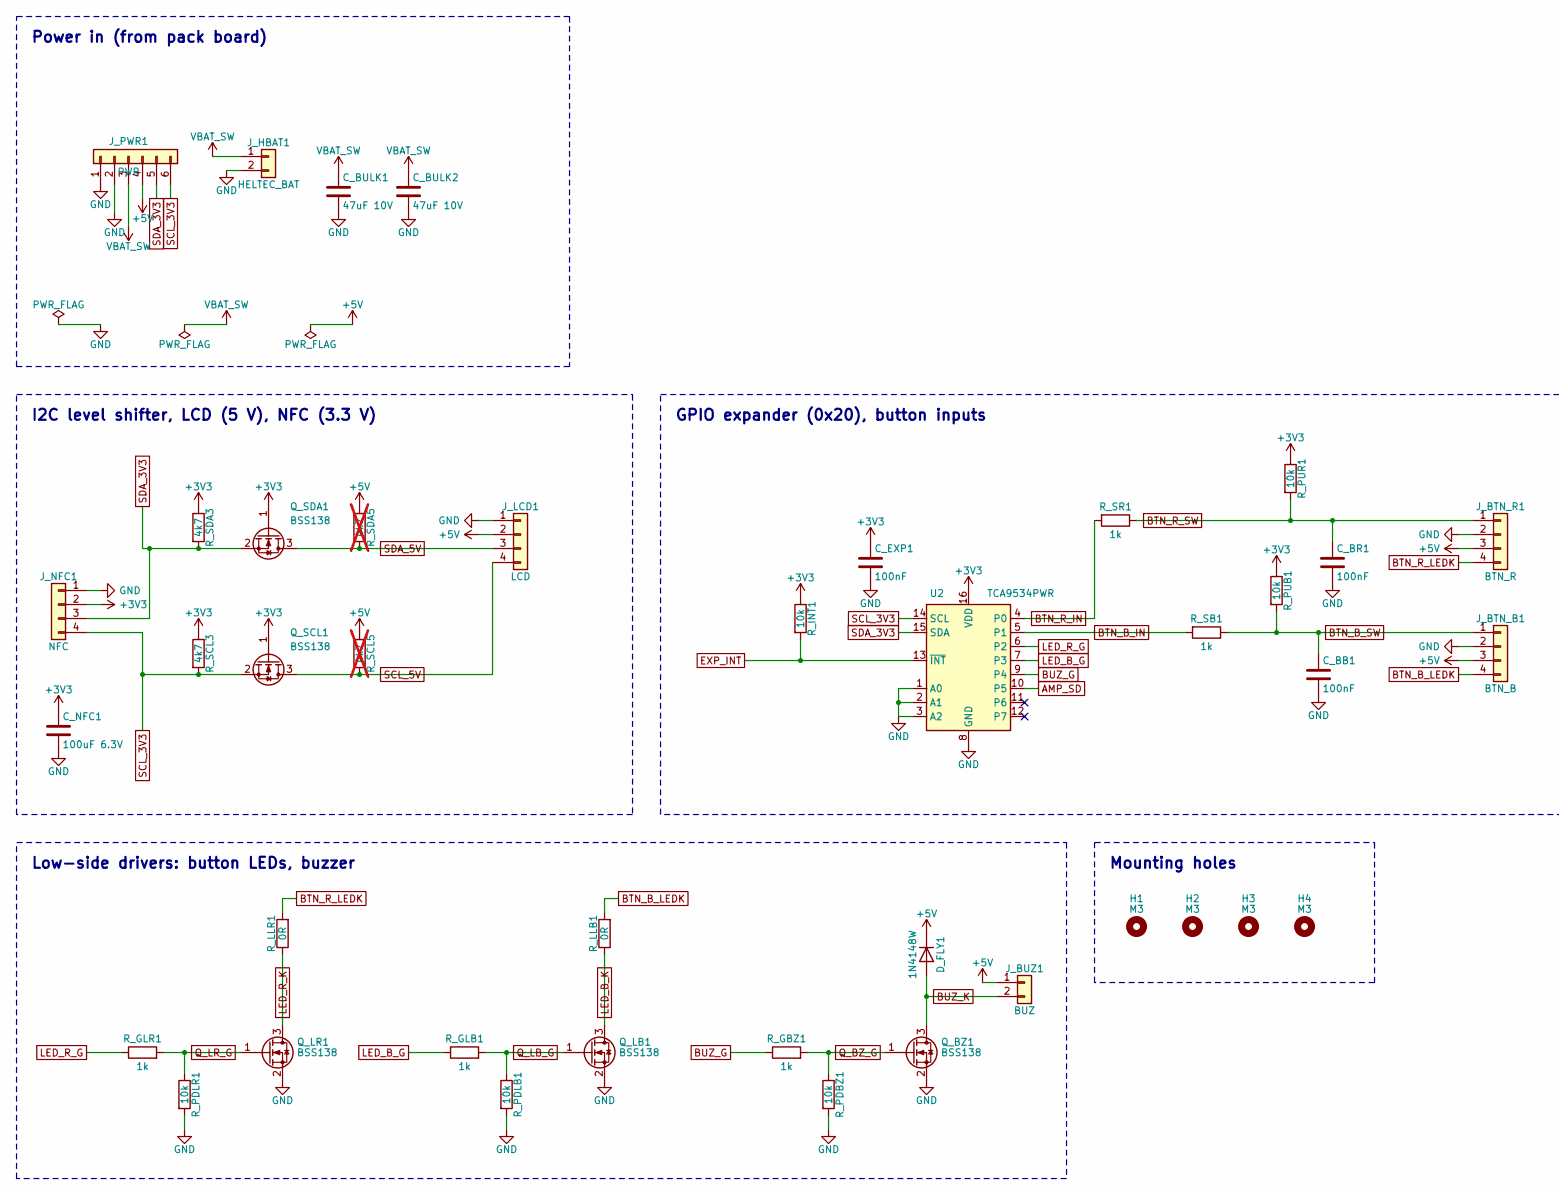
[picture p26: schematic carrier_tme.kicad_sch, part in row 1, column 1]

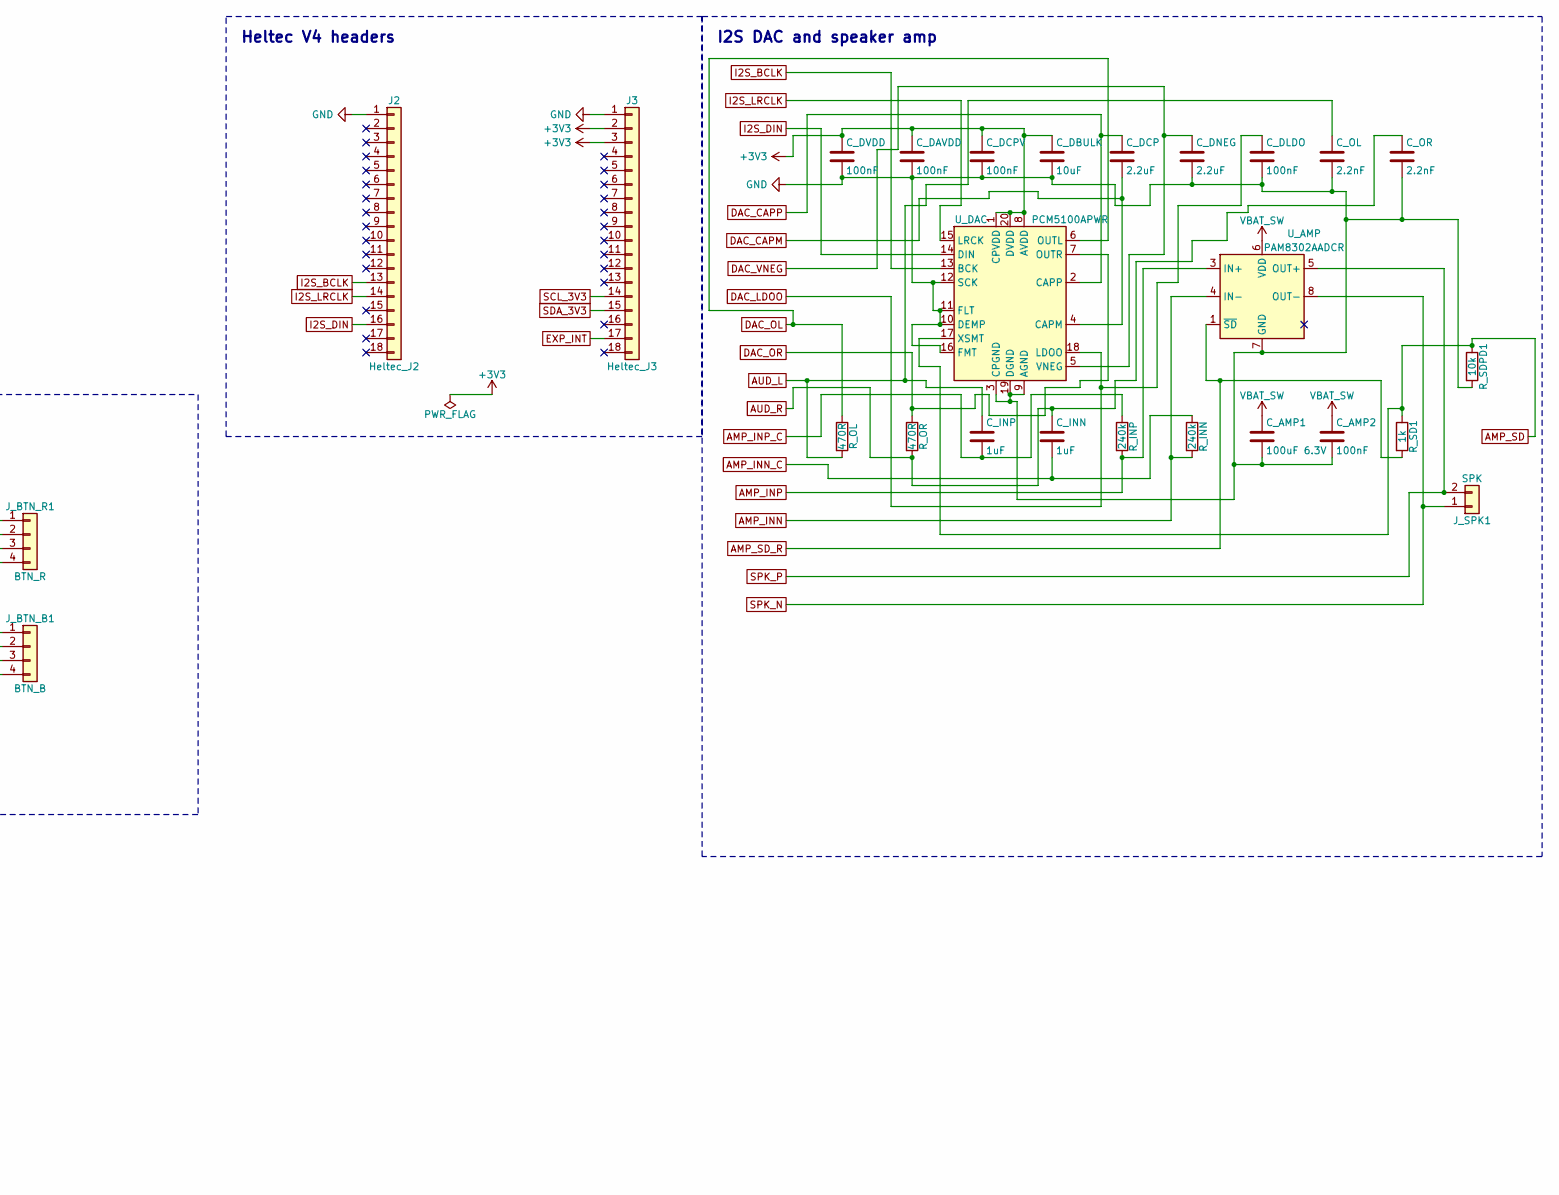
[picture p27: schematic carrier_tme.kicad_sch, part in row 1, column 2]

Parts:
C_AMP1: 100uF 6.3V; C_1206_3216Metric_Pad1.33x1.80mm_HandSolder
C_AMP2: 100nF; C_0805_2012Metric_Pad1.18x1.45mm_HandSolder
C_BB1: 100nF; C_0805_2012Metric_Pad1.18x1.45mm_HandSolder
C_BR1: 100nF; C_0805_2012Metric_Pad1.18x1.45mm_HandSolder
C_BULK1, C_BULK2: 47uF 10V; C_1206_3216Metric_Pad1.33x1.80mm_HandSolder
C_DAVDD: 100nF; C_0805_2012Metric_Pad1.18x1.45mm_HandSolder
C_DBULK: 10uF; C_0805_2012Metric_Pad1.18x1.45mm_HandSolder
C_DCP: 2.2uF; C_0805_2012Metric_Pad1.18x1.45mm_HandSolder
C_DCPV: 100nF; C_0805_2012Metric_Pad1.18x1.45mm_HandSolder
C_DLDO: 100nF; C_0805_2012Metric_Pad1.18x1.45mm_HandSolder
C_DNEG: 2.2uF; C_0805_2012Metric_Pad1.18x1.45mm_HandSolder
C_DVDD: 100nF; C_0805_2012Metric_Pad1.18x1.45mm_HandSolder
C_EXP1: 100nF; C_0805_2012Metric_Pad1.18x1.45mm_HandSolder
C_INN: 1uF; C_0805_2012Metric_Pad1.18x1.45mm_HandSolder
C_INP: 1uF; C_0805_2012Metric_Pad1.18x1.45mm_HandSolder
C_NFC1: 100uF 6.3V; C_1206_3216Metric_Pad1.33x1.80mm_HandSolder
C_OL: 2.2nF; C_0805_2012Metric_Pad1.18x1.45mm_HandSolder
C_OR: 2.2nF; C_0805_2012Metric_Pad1.18x1.45mm_HandSolder
D_FLY1: 1N4148W; D_SOD-123
H1, H2, H3, H4: M3; MountingHole_3.2mm_M3
J2: Heltec_J2; PinSocket_1x18_P2.54mm_Vertical
J3: Heltec_J3; PinSocket_1x18_P2.54mm_Vertical
J_BTN_B1: BTN_B; JST_XH_B4B-XH-A_1x04_P2.50mm_Vertical
J_BTN_R1: BTN_R; JST_XH_B4B-XH-A_1x04_P2.50mm_Vertical
J_BUZ1: BUZ; JST_XH_B2B-XH-A_1x02_P2.50mm_Vertical
J_HBAT1: HELTEC_BAT; JST_XH_B2B-XH-A_1x02_P2.50mm_Vertical
J_LCD1: LCD; JST_XH_B4B-XH-A_1x04_P2.50mm_Vertical
J_NFC1: NFC; JST_XH_B4B-XH-A_1x04_P2.50mm_Vertical
J_PWR1: PWR; JST_XH_B6B-XH-A_1x06_P2.50mm_Vertical
J_SPK1: SPK; JST_XH_B2B-XH-A_1x02_P2.50mm_Vertical
Q_BZ1: BSS138; SOT-23
Q_LB1: BSS138; SOT-23
Q_LR1: BSS138; SOT-23
Q_SCL1: BSS138; SOT-23
Q_SDA1: BSS138; SOT-23
R_GBZ1: 1k; R_0805_2012Metric_Pad1.20x1.40mm_HandSolder
R_GLB1: 1k; R_0805_2012Metric_Pad1.20x1.40mm_HandSolder
R_GLR1: 1k; R_0805_2012Metric_Pad1.20x1.40mm_HandSolder
R_INN: 240k; R_0805_2012Metric_Pad1.20x1.40mm_HandSolder
R_INP: 240k; R_0805_2012Metric_Pad1.20x1.40mm_HandSolder
R_INT1: 10k; R_0805_2012Metric_Pad1.20x1.40mm_HandSolder
R_LLB1: 0R; R_0805_2012Metric_Pad1.20x1.40mm_HandSolder
R_LLR1: 0R; R_0805_2012Metric_Pad1.20x1.40mm_HandSolder
R_OL: 470R; R_0805_2012Metric_Pad1.20x1.40mm_HandSolder
R_OR: 470R; R_0805_2012Metric_Pad1.20x1.40mm_HandSolder
R_PDBZ1: 10k; R_0805_2012Metric_Pad1.20x1.40mm_HandSolder
R_PDLB1: 10k; R_0805_2012Metric_Pad1.20x1.40mm_HandSolder
R_PDLR1: 10k; R_0805_2012Metric_Pad1.20x1.40mm_HandSolder
R_PUB1: 10k; R_0805_2012Metric_Pad1.20x1.40mm_HandSolder
R_PUR1: 10k; R_0805_2012Metric_Pad1.20x1.40mm_HandSolder
R_SB1: 1k; R_0805_2012Metric_Pad1.20x1.40mm_HandSolder
R_SCL3: 4k7; R_0805_2012Metric_Pad1.20x1.40mm_HandSolder
R_SCL5: 4k7; R_0805_2012Metric_Pad1.20x1.40mm_HandSolder; not fitted
R_SD1: 1k; R_0805_2012Metric_Pad1.20x1.40mm_HandSolder
R_SDA3: 4k7; R_0805_2012Metric_Pad1.20x1.40mm_HandSolder
R_SDA5: 4k7; R_0805_2012Metric_Pad1.20x1.40mm_HandSolder; not fitted
R_SDPD1: 10k; R_0805_2012Metric_Pad1.20x1.40mm_HandSolder
R_SR1: 1k; R_0805_2012Metric_Pad1.20x1.40mm_HandSolder
U2: TCA9534PWR; TSSOP-16_4.4x5mm_P0.65mm
U_AMP: PAM8302AADCR; SOIC-8_3.9x4.9mm_P1.27mm
U_DAC: PCM5100APWR; TSSOP-20_4.4x6.5mm_P0.65mm

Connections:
+3V3: C_DAVDD.1, C_DBULK.1, C_DCPV.1, C_DVDD.1, C_EXP1.1, C_NFC1.1, J3.2, J3.3, J_NFC1.2, Q_SCL1.1 (G), Q_SDA1.1 (G), R_INT1.1, R_PUB1.1, R_PUR1.1, R_SCL3.1, R_SDA3.1, U2.16 (VDD), U_DAC.1 (CPVDD), U_DAC.8 (AVDD), U_DAC.20 (DVDD)
+5V: D_FLY1.1 (K), J_BTN_B1.3, J_BTN_R1.3, J_BUZ1.1, J_LCD1.2, J_PWR1.4, R_SCL5.1, R_SDA5.1
AMP_INN: R_INN.2, U_AMP.4 (IN-)
AMP_INN_C: C_INN.2, R_INN.1
AMP_INP: R_INP.2, U_AMP.3 (IN+)
AMP_INP_C: C_INP.2, R_INP.1
AMP_SD: R_SD1.1, R_SDPD1.1, U2.10 (P5), U_DAC.17 (XSMT)
AMP_SD_R: R_SD1.2, U_AMP.1 (~SD)
AUD_L: C_INP.1, C_OL.1, R_OL.2
AUD_R: C_INN.1, C_OR.1, R_OR.2
BTN_B_IN: R_SB1.2, U2.5 (P1)
BTN_B_LEDK: J_BTN_B1.4, R_LLB1.2
BTN_B_SW: C_BB1.1, J_BTN_B1.1, R_PUB1.2, R_SB1.1
BTN_R_IN: R_SR1.2, U2.4 (P0)
BTN_R_LEDK: J_BTN_R1.4, R_LLR1.2
BTN_R_SW: C_BR1.1, J_BTN_R1.1, R_PUR1.2, R_SR1.1
BUZ_G: R_GBZ1.1, U2.9 (P4)
BUZ_K: D_FLY1.2 (A), J_BUZ1.2, Q_BZ1.3 (D)
DAC_CAPM: C_DCP.2, U_DAC.4 (CAPM)
DAC_CAPP: C_DCP.1, U_DAC.2 (CAPP)
DAC_LDOO: C_DLDO.1, U_DAC.18 (LDOO)
DAC_OL: R_OL.1, U_DAC.6 (OUTL)
DAC_OR: R_OR.1, U_DAC.7 (OUTR)
DAC_VNEG: C_DNEG.1, U_DAC.5 (VNEG)
EXP_INT: J3.17, R_INT1.2, U2.13 (~INT)
GND: C_AMP1.2, C_AMP2.2, C_BB1.2, C_BR1.2, C_BULK1.2, C_BULK2.2, C_DAVDD.2, C_DBULK.2, C_DCPV.2, C_DLDO.2, C_DNEG.2, C_DVDD.2, C_EXP1.2, C_NFC1.2, C_OL.2, C_OR.2, J2.1, J3.1, J_BTN_B1.2, J_BTN_R1.2, J_HBAT1.2, J_LCD1.1, J_NFC1.1, J_PWR1.1, J_PWR1.2, Q_BZ1.2 (S), Q_LB1.2 (S), Q_LR1.2 (S), R_PDBZ1.2, R_PDLB1.2, R_PDLR1.2, R_SDPD1.2, U2.1 (A0), U2.2 (A1), U2.3 (A2), U2.8 (GND), U_AMP.7 (GND), U_DAC.3 (CPGND), U_DAC.9 (AGND), U_DAC.10 (DEMP), U_DAC.11 (FLT), U_DAC.12 (SCK), U_DAC.16 (FMT), U_DAC.19 (DGND)
I2S_BCLK: J2.13, U_DAC.13 (BCK)
I2S_DIN: J2.16, U_DAC.14 (DIN)
I2S_LRCLK: J2.14, U_DAC.15 (LRCK)
LED_B_G: R_GLB1.1, U2.7 (P3)
LED_B_K: Q_LB1.3 (D), R_LLB1.1
LED_R_G: R_GLR1.1, U2.6 (P2)
LED_R_K: Q_LR1.3 (D), R_LLR1.1
Q_BZ_G: Q_BZ1.1 (G), R_GBZ1.2, R_PDBZ1.1
Q_LB_G: Q_LB1.1 (G), R_GLB1.2, R_PDLB1.1
Q_LR_G: Q_LR1.1 (G), R_GLR1.2, R_PDLR1.1
SCL_3V3: J3.14, J_NFC1.4, J_PWR1.6, Q_SCL1.2 (S), R_SCL3.2, U2.14 (SCL)
SCL_5V: J_LCD1.4, Q_SCL1.3 (D), R_SCL5.2
SDA_3V3: J3.15, J_NFC1.3, J_PWR1.5, Q_SDA1.2 (S), R_SDA3.2, U2.15 (SDA)
SDA_5V: J_LCD1.3, Q_SDA1.3 (D), R_SDA5.2
SPK_N: J_SPK1.1, U_AMP.8 (OUT-)
SPK_P: J_SPK1.2, U_AMP.5 (OUT+)
VBAT_SW: C_AMP1.1, C_AMP2.1, C_BULK1.1, C_BULK2.1, J_HBAT1.1, J_PWR1.3, U_AMP.6 (VDD)

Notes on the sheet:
Power in (from pack board)
I2S DAC and speaker amp
Heltec V4 headers
I2C level shifter, LCD (5 V), NFC (3.3 V)
GPIO expander (0x20), button inputs
Low-side drivers: button LEDs, buzzer
Mounting holes

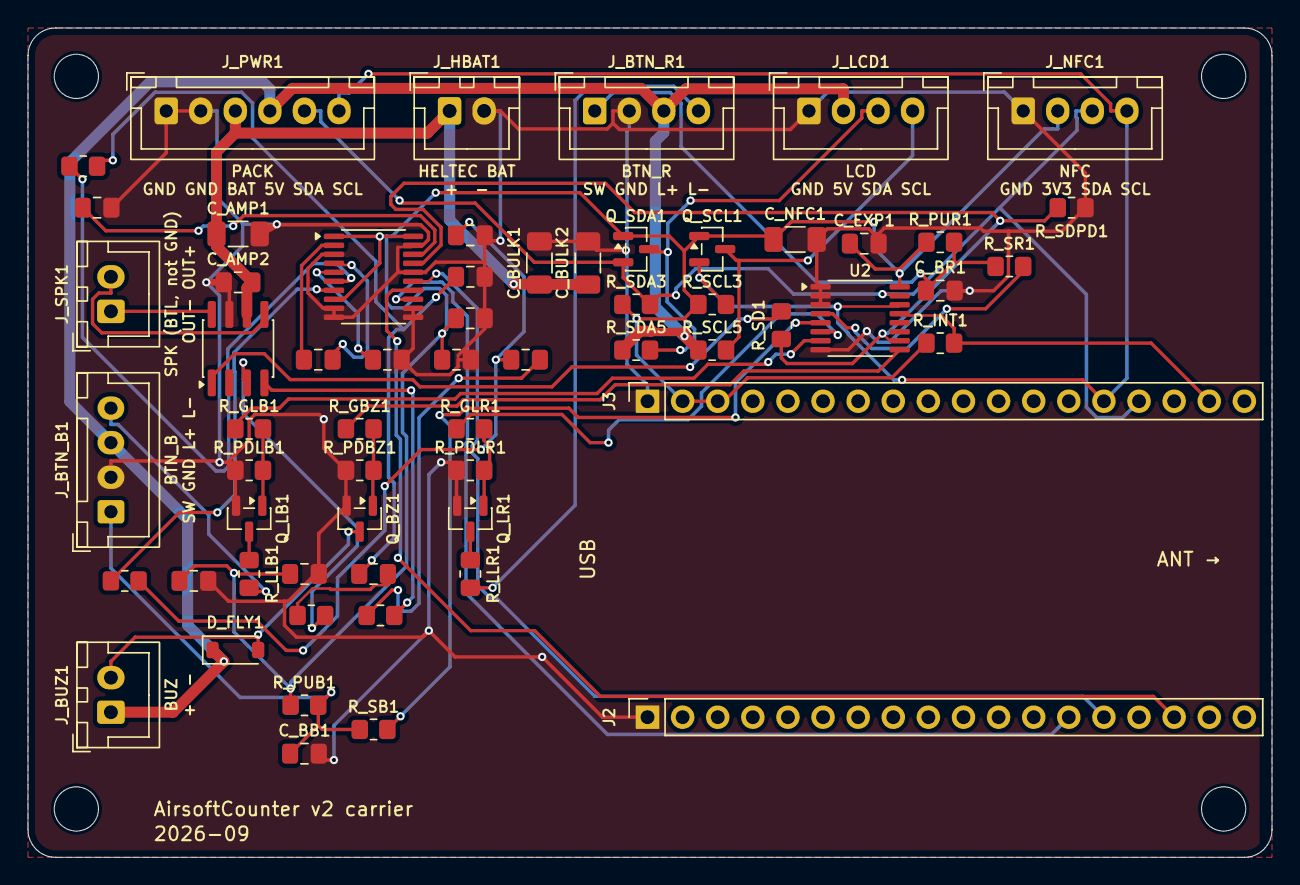
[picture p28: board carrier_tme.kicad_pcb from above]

Board: 2 copper layers, 90.0 x 60.0 mm, 65 parts (0 on the bottom side), 43 nets.

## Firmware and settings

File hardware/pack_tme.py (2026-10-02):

"""AirsoftCounter pack board, hand-build TME variant: iron-only, everything from TME.

Derived from pack.py by import and edit. The PAC1934 is replaced by four INA226s (one per cell,
their own 10R Kelvin split and ALERTs wired together), the C071 by an STM32L072KZT6 (the internal
bus moves to I2C3 on PA8/PB4, the carrier link to I2C1 on PB6/PB7), the BQ25601 onto the
hand-solder QFN footprint, the MT3608 boost by an MCP1640 (no catch diode), the SMD USB-C by a
through-hole USB4085 and the SMD tact switches by THT 6x6 ones. gen_sch.py / gen_pcb.py read it
through board.py (`make BOARD=pack_tme ...`). Run this file to self-check.

INA226, not the INA228 of the design doc: same pins and addresses, and TME had no INA228 (2026-10-02).

Source of truth: docs/plans/2026-10-02-tme-hand-build-design.md.
"""
import board
import pack
import tme

NAME = "pack_tme"
TITLE = "AirsoftCounter v2 pack (hand-build)"

LQFP32, SOT23_6, R0805, C0805 = pack.LQFP32, pack.SOT23_6, pack.R0805, pack.C0805
VSSOP10 = "Package_SO:VSSOP-10_3x3mm_P0.5mm"
QFN24_HAND = "local:QFN-24-1EP_4x4mm_P0.5mm_EP2.6x2.6mm_HandSolder"
USB_THT = "Connector_USB:USB_C_Receptacle_GCT_USB4085"
TACT_THT = "Button_Switch_THT:SW_PUSH_6mm"

# Variant A parts the hand build drops or replaces.
_REMOVED = {"U_MON", "R_PWRDN", "D1"}
PARTS = {r: v for r, v in pack.PARTS.items() if r not in _REMOVED}
PARTS["U_CHG"] = ("BQ25601RTWT", "Battery_Management:BQ25601", QFN24_HAND)
PARTS["U_MCU"] = ("STM32L072KZT6", "MCU_ST_STM32L0:STM32L072KZTx", LQFP32)
PARTS["C_MCU3"] = ("100nF", *C0805)          # second VDD pin (17)
PARTS["C_VDDA"] = ("1uF", *C0805)            # VDDA (5)
PARTS["J_USB1"] = ("USB4085-GF-A", pack.PARTS["J_USB1"][1], USB_THT)
PARTS["SW_BOOT"] = ("TACT 6x6", "Switch:SW_Push", TACT_THT)
PARTS["SW_RST"] = ("TACT 6x6", "Switch:SW_Push", TACT_THT)
PARTS["U1"] = ("MCP1640T-I/CHY", "Regulator_Switching:MCP1640x-xCHY", SOT23_6)
PARTS["L1"] = ("3u3", "Device:L", pack.LRN6045)      # MCP1640 takes 2.2-10 uH (no catch diode)
PARTS["R_FB2"] = ("24k", *R0805)                     # 1.21 V x (1 + 75/24) = 4.99 V
PARTS["TH_CHG"] = ("10k NTC 0603", *PARTS["TH_CHG"][1:])
for i in range(1, 5):
    PARTS[f"U_MON{i}"] = ("INA226AIDGSR", "Sensor_Energy:INA226", VSSOP10)
    PARTS[f"C_MON{i}"] = ("100nF", *C0805)

DNP = set(pack.DNP)   # R_BYP1..4 bring-up bypasses stay DNP
# Holders and bead NTCs come from LCSC (see fab/offboard), and the test pads are copper only. TH_CHG
# is now bought at TME, so unlike variant A it stays in the BOM.
NOT_TME = ({f"BT{i}" for i in range(1, 5)} | {f"TH{i}" for i in range(1, 5)}
           | {"TP_SWDIO", "TP_SWCLK", "TP_NRST", "TP_GND"})
NOT_ASSEMBLED = set(pack.NOT_ASSEMBLED) - {"TH_CHG"}
NC_PARTS = set()
NC_PINS = ({p for p in pack.NC_PINS if not p.startswith(("U_MCU.", "U1."))}
           | {f"U_MCU.{p}" for p in (2, 3, 19, 20)})
LCSC = {}
_KEYS = {(v, fp) for r, (v, sym, fp) in PARTS.items()
         if sym != "Mechanical:MountingHole" and r not in DNP | NOT_TME}
TME = tme.from_lcsc(pack.LCSC, _KEYS)
TME |= {
    ("BQ25601RTWT", QFN24_HAND): "BQ25601RTWT",
    ("STM32L072KZT6", LQFP32): "STM32L072KZT6",
    ("INA226AIDGSR", VSSOP10): "INA226AIDGSR",
    ("USB4085-GF-A", USB_THT): "USB4085-GF-A",
    ("TACT 6x6", TACT_THT): "B3F-1000",
    ("MCP1640T-I/CHY", SOT23_6): "MCP1640T-I/CHY",
    ("3u3", pack.LRN6045): "SRN6045-3R3Y",          # plain SRN6045, Isat 5 A; fits the TA pads
    ("24k", R0805[1]): "SMD0805-24K-1%",
    ("10k NTC 0603", R0805[1]): "NTCS0603E3103FLT",
}
MODULES, VARIANTS = {}, {"standard": set()}


def assembled(variant="standard"):
    """Nothing is machine-placed on a hand-build board."""
    return []


# --- nets: variant A with the MCU/monitor/boost pins replaced ----------------------------------
NETS = {n: [p for p in mem if not p.startswith(("U_MCU.", "U_MON.", "U1.", "D1.", "R_PWRDN."))]
        for n, mem in pack.NETS.items()}
del NETS["MON_PWRDN"]

MCU = {"+3V3": [1, 5, 17], "GND": [16, 32], "NRST": [4], "BOOT0": [31], "SWDIO": [23],
       "SWCLK": [24], "USB_DM": [21], "USB_DP": [22], "SCL_INT": [18], "SDA_INT": [27],
       "SCL_EXT": [29], "SDA_EXT": [30], "NTC_PWR": [10], "CHG_CE": [15], "CHG_INT": [26],
       "MON_ALERT": [28], "LED_MCU_DRV": [25],
       "NTC1": [6], "NTC2": [7], "NTC3": [8], "NTC4": [9],
       "SW1_DRV": [11], "SW2_DRV": [12], "SW3_DRV": [13], "SW4_DRV": [14]}
for net, pins in MCU.items():
    NETS.setdefault(net, []).extend(f"U_MCU.{p}" for p in pins)
NETS["SWCLK"] = NETS.get("SWCLK", []) + ["TP_SWCLK.1"]       # BOOT0 is its own pin now
NETS["BOOT0"] = [p for p in NETS["BOOT0"] if p != "TP_SWCLK.1"]
NETS["+3V3"] += ["C_MCU3.1", "C_VDDA.1", *(f"U_MON{i}.6" for i in range(1, 5)),
                 *(f"C_MON{i}.1" for i in range(3, 5)), "U_MON2.2"]   # C_MON1/2 already wired
NETS["GND"] += ["C_MCU3.2", "C_VDDA.2", "U1.2", *(f"U_MON{i}.7" for i in range(1, 5)),
                *(f"C_MON{i}.2" for i in range(3, 5)), *(f"U_MON{i}.1" for i in range(1, 5)),
                "U_MON1.2"]
NETS["SDA_INT"] += [*(f"U_MON{i}.4" for i in range(1, 5)), "U_MON3.2"]
NETS["SCL_INT"] += [*(f"U_MON{i}.5" for i in range(1, 5)), "U_MON4.2"]
NETS["MON_ALERT"] += [f"U_MON{i}.3" for i in range(1, 5)]
NETS["VBAT_SW"] += ["U1.6", "U1.3"]                 # MCP1640 VIN and EN tied to the switched rail
NETS["SW"] = ["U1.1", "L1.2"]
NETS["FB"] = ["U1.4", "R_FB1.2", "R_FB2.1"]
NETS["+5V"] += ["U1.5"]
for i in range(1, 5):
    NETS[f"SNS_F{i}"] = list(NETS[f"SNS_F{i}"]) + [f"U_MON{i}.10", f"U_MON{i}.8"]
    NETS[f"SNS_S{i}"] = list(NETS[f"SNS_S{i}"]) + [f"U_MON{i}.9"]


# --- layout: reused from variant A by assignment; edited in T5.2 --------------------------------
W, H, CORNER = pack.W, pack.H, pack.CORNER
NETCLASS_POWER = tuple(p for p in pack.NETCLASS_POWER if p != "+5V")   # 82 mA peak; U1's fine VOUT pad
NETCLASS_EXPECT = tuple((n, [0.8, 0.2] if n != "+5V" and w == 0.8 else [0.25, 0.15])
                        for n, (w, _) in pack.NETCLASS_EXPECT)
DEFAULT_CLEARANCE = 0.15   # the USB4085's own THT pads sit 0.15 mm apart
RAILS = pack.RAILS
PORT_LIB = pack.PORT_LIB
DRC_RULES = {**pack.DRC_RULES, "min_clearance": 0.15}   # USB4085 THT pads sit 0.15 mm apart
BOTTOM = pack.BOTTOM
_CELL_X, _CELL_Y = pack._CELL_X, pack._CELL_Y
_HOLDER_NPTH = pack._HOLDER_NPTH
PTH_COMPONENT_MIN = 0.4   # the through-hole USB4085 signal pins drill 0.4 mm (was 0.6 for the SMD part's shell)
NPTH_EXPECT = sorted([(x, y, 3.2) for x, y in pack.NPTH_XY]
                     + [(_CELL_X + dx, cy + dy, size) for cy in _CELL_Y
                        for dx, dy, size in _HOLDER_NPTH])   # the USB4085 adds no NPTH
LABELS = pack.LABELS
TEXTS = list(pack.TEXTS)
GND_VIAS = list(pack.GND_VIAS)
HELTEC_PADS = {}
SIZE_MM = pack.SIZE_MM
NPTH_XY = pack.NPTH_XY
HIDE_REF = pack.HIDE_REF + ("U_CHG", "R_ALERT", "C_VDDA", "C_MCU3", "SW_BOOT", "SW_RST")
SENSE_IN = pack.SENSE_IN
PLACE = dict(pack.PLACE)
for _gone in ("U_MON", "R_PWRDN", "D1"):   # replaced / dropped by the TME build
    del PLACE[_gone]
PLACE.update({
    # The BQ25601 hand-solder footprint is 1.2 mm larger and its exposed pad is soldered from the
    # back, so it leaves the holder floor for the holder-free right strip; the THT tact switches
    # move to the left margin (x < 8) for the same reason.
    "U_CHG": (90.0, 36.0, 0),
    "J_USB1": (87.0, 23.0, 90),   # pulled in so the USB4085's silk clears the board edge
    "SW_BOOT": (1.6, 48.0, 90), "SW_RST": (1.6, 60.0, 90),
    "J_PWR1": (90.0, 70.5, 90), "J_KEY1": (90.0, 79.2, 90),
    "C_MCU3": (59.0, 70.0, 0), "C_VDDA": (74.0, 66.5, 0),
})
for _i, _cy in enumerate(pack._CELL_Y, start=1):
    # One INA226 per cell band, its IN+/IN- facing that cell's 10R Kelvin split.
    PLACE[f"U_MON{_i}"] = (54.0, _cy, 0)
    PLACE[f"C_MON{_i}"] = (54.0, _cy + 6.5, 0)
REF_AT = dict(pack.REF_AT)
REF_AT.pop("U_MON", None)
REF_AT |= {f"U_MON{_i}": (54.0, _cy + 2.6, 0) for _i, _cy in enumerate(pack._CELL_Y, start=1)}
_tags = pack._tags
_cell = pack._cell


def _copy_blocks():
    out = []
    for b in pack.BLOCKS:
        nb = dict(b)
        nb["parts"] = dict(b["parts"])
        if "tags" in b:
            nb["tags"] = {n: list(t) for n, t in b["tags"].items()}
        if "fields" in b:
            nb["fields"] = {r: dict(f) for r, f in b["fields"].items()}
        if "flags" in b:
            nb["flags"] = list(b["flags"])
        if "wired" in b:
            nb["wired"] = set(b["wired"])
        out.append(nb)
    return out


BLOCKS = _copy_blocks()

# --- T5.2 layout -------------------------------------------------------------------------------
# The PAC1934's single monitor block becomes support only; each INA226 moves into the cell block
# it senses, beside that cell's 10R Kelvin split. One fewer long sense route per cell, and the
# four monitors spread over four blocks instead of crowding one.
BLOCKS[1] = {
    "title": "Diode-OR and 3V3 LDO", "at": (228.6, 12.7), "size": (114.3, 139.7),
    "parts": {
        "D_OR5": (25.4, 25.4, 0, None),
        "U_LDO": (50.8, 25.4, 0, None),
        "C_LDO1": (76.2, 25.4, 0, None),
        "C_LDO2": (25.4, 50.8, 0, None),
        "R_SCL_INT": (50.8, 50.8, 0, None),
        "R_SDA_INT": (76.2, 50.8, 0, None),
        "R_ALERT": (25.4, 76.2, 0, None),
    },
    "tags": _tags(["SCL_INT", "SDA_INT", "MON_ALERT", "SYS"], 12.7, 101.6, per_row=4),
}
# The L072 adds VDD (17) and VDDA (5) decoupling.
BLOCKS[2]["title"] = "STM32L072 MCU, reset/boot, test pads"
BLOCKS[2]["size"] = (165.1, 190.5)
BLOCKS[2]["parts"].update({
    "U_MCU": (58.42, 55.88, 0, None),     # the L072 is 25.4 mm wide; move it clear of the left column
    "C_MCU3": (30.48, 25.4, 0, None),
    "C_VDDA": (43.18, 25.4, 0, None),
    "TP_SWDIO": (95.25, 60.96, 0, None),
    "R_LED_MCU": (95.25, 76.2, 0, None),
    "LED_MCU": (105.41, 76.2, 90, None),
    "TP_GND": (95.25, 91.44, 0, None),
})
BLOCKS[2]["tags"].pop("MON_PWRDN", None)
# The L072's three +3V3 pins are adjacent on the top edge (2.54 mm apart), so they cannot each
# take a power port: wire the rails and name them with tags, as the carrier amp block does.
BLOCKS[2]["tags"]["+3V3"] = [(12.7, 186.69, "R")]
BLOCKS[2]["tags"]["GND"] = [(33.02, 186.69, "R")]
BLOCKS[2]["wired"] = {"+3V3", "GND"}
# The synchronous MCP1640 needs no catch diode.
del BLOCKS[3]["parts"]["D1"]

for _i in range(1, 5):
    _b = BLOCKS[3 + _i]
    _b["title"] = f"Cell {_i} branch + INA226"
    # The NTC bead and its divider resistor move down, clearing the INA226's right-hand pins.
    _b["parts"].update({
        f"U_MON{_i}": (63.5, 71.12, 0, None),
        f"C_MON{_i}": (63.5, 44.45, 0, None),
        f"TH{_i}": (83.82, 105.41, 0, None),
        f"R_NTC{_i}": (83.82, 125.73, 0, None),
    })
    _b["tags"] = (_tags([f"CELL{_i}_F", f"CELL{_i}_S", f"CELL{_i}_RAW", f"CELL{_i}_SRC"],
                         12.7, 152.4, per_row=4)
                   | _tags(["SDA_INT", "SCL_INT", "MON_ALERT"], 12.7, 165.1, per_row=3)
                   | {f"SNS_F{_i}": [(34.29, 68.58, "L")], f"SNS_S{_i}": [(40.64, 57.15, "L")],
                      f"NTC{_i}": [(83.82, 144.78, "R")]})


def check_branches():
    """Every cell in branch order, with its own INA226 across the 10R Kelvin split: IN+ and VBUS on
    the cell side of the shunt, IN- after it, addresses 0x40-0x43 by A1/A0, ALERTs wired together."""
    net_of = {p: n for n, m in NETS.items() for p in m}
    addr = {1: ("GND", "GND"), 2: ("GND", "+3V3"), 3: ("GND", "SDA_INT"), 4: ("GND", "SCL_INT")}
    for i in range(1, 5):
        assert net_of[f"BT{i}.1"] == net_of[f"F{i}.1"], f"cell {i}: holder+ not on fuse"
        assert net_of[f"F{i}.2"] == net_of[f"R_SH{i}.1"] == net_of[f"R_SNSF{i}.1"], \
            f"cell {i}: fuse -> shunt"
        assert net_of[f"R_SNSF{i}.2"] == net_of[f"U_MON{i}.10"] == net_of[f"U_MON{i}.8"], \
            f"cell {i}: IN+/VBUS"
        assert net_of[f"R_SH{i}.2"] == net_of[f"Q_A{i}.3"] == net_of[f"R_SNSS{i}.1"], \
            f"cell {i}: shunt -> FET"
        assert net_of[f"R_SNSS{i}.2"] == net_of[f"U_MON{i}.9"], f"cell {i}: IN-"
        assert net_of[f"Q_B{i}.3"] == "VPACK" and net_of[f"BT{i}.2"] == "GND", f"cell {i}: rail"
        assert (net_of[f"U_MON{i}.1"], net_of[f"U_MON{i}.2"]) == addr[i], f"INA226 {i} address"
        assert net_of[f"U_MON{i}.3"] == "MON_ALERT" and net_of[f"U_MON{i}.6"] == "+3V3"
        assert (net_of[f"U_MON{i}.4"], net_of[f"U_MON{i}.5"]) == ("SDA_INT", "SCL_INT")


def check_mcu():
    """The L072 pin roles and the boost this board relies on."""
    net_of = {p: n for n, m in NETS.items() for p in m}
    want = {"U_MCU.21": "USB_DM", "U_MCU.22": "USB_DP", "U_MCU.18": "SCL_INT",
            "U_MCU.27": "SDA_INT", "U_MCU.29": "SCL_EXT", "U_MCU.30": "SDA_EXT",
            "U_MCU.6": "NTC1", "U_MCU.7": "NTC2", "U_MCU.8": "NTC3", "U_MCU.9": "NTC4",
            "U_MCU.10": "NTC_PWR", "U_MCU.11": "SW1_DRV", "U_MCU.12": "SW2_DRV",
            "U_MCU.13": "SW3_DRV", "U_MCU.14": "SW4_DRV", "U_MCU.15": "CHG_CE",
            "U_MCU.26": "CHG_INT", "U_MCU.28": "MON_ALERT", "U_MCU.25": "LED_MCU_DRV",
            "U_MCU.31": "BOOT0", "U_MCU.4": "NRST", "U_MCU.23": "SWDIO", "U_MCU.24": "SWCLK"}
    for p, n in want.items():
        assert net_of.get(p) == n, f"{p} on {net_of.get(p)}, want {n}"
    assert PARTS["U_CHG"][2] == QFN24_HAND, "U_CHG must use the hand-solder footprint"
    assert "D1" not in PARTS, "the synchronous MCP1640 needs no catch diode"
    for p, n in (("U1.6", "VBAT_SW"), ("U1.3", "VBAT_SW"), ("U1.5", "+5V"), ("U1.4", "FB")):
        assert net_of[p] == n, f"{p} on {net_of[p]}, want {n}"


def check():
    import sys

    this = sys.modules[__name__]
    board.check_structure(this)
    check_branches()
    check_mcu()
    print(f"pack_tme ok: {len(PARTS)} parts, {len(NETS)} nets")


if __name__ == "__main__":
    check()

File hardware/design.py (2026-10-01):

"""AirsoftCounter v2 carrier board: single source of truth for parts and nets.

gen_sch.py and gen_pcb.py read PARTS and NETS from here. Run this file to
self-check the design (`python3 design.py`). Generators must call design.check()
at startup.

check() validates structure (unique pins, known parts, no single-pin nets, no
unconnected parts), every Heltec header pin, and that every assembled part has
an LCSC number (jlc.py builds the JLCPCB assembly files from LCSC). It does NOT validate pin
numbers of other parts or catch dangling 2-pin parts: gen_sch.py (symbol pin
lookup) and KiCad ERC catch those.
"""

# Footprints (and symbol + footprint pairs) shared by PARTS and LCSC below
R0805 = ("Device:R", "Resistor_SMD:R_0805_2012Metric_Pad1.20x1.40mm_HandSolder")
C0805 = ("Device:C", "Capacitor_SMD:C_0805_2012Metric_Pad1.18x1.45mm_HandSolder")
BSS138 = ("Transistor_FET:BSS138", "Package_TO_SOT_SMD:SOT-23")  # I2C shifter and low-side drivers
C1206 = "Capacitor_SMD:C_1206_3216Metric_Pad1.33x1.80mm_HandSolder"
TSSOP16 = "Package_SO:TSSOP-16_4.4x5mm_P0.65mm"
ESOP8 = "Package_SO:HSOP-8-1EP_3.9x4.9mm_P1.27mm_EP2.3x2.3mm_ThermalVias"  # NS4168 eSOP-8, EP 2.0 mm
XH2 = "Connector_JST:JST_XH_B2B-XH-A_1x02_P2.50mm_Vertical"
XH4 = "Connector_JST:JST_XH_B4B-XH-A_1x04_P2.50mm_Vertical"
XH6 = "Connector_JST:JST_XH_B6B-XH-A_1x06_P2.50mm_Vertical"
SOCKET18 = "Connector_PinSocket_2.54mm:PinSocket_1x18_P2.54mm_Vertical"
SOIC8EP = "Package_SO:SOIC-8-1EP_3.9x4.9mm_P1.27mm_EP2.41x3.3mm"

# ref: (value, symbol "lib:name", footprint "lib:name")
PARTS = {
    # Heltec WiFi LoRa 32 V4 headers (pin 1 at USB end). Rows are 22.86 mm apart.
    "J2": ("Heltec_J2", "Connector_Generic:Conn_01x18", SOCKET18),
    "J3": ("Heltec_J3", "Connector_Generic:Conn_01x18", SOCKET18),
    # Off-board connectors: JST-XH 2.50 mm vertical, pin count matching the wires (XH-2 for the
    # 2-wire loads, XH-4 where all four are used). J_PWR1 is the 6-pin link to the pack board.
    "J_HBAT1": ("HELTEC_BAT", "Connector_Generic:Conn_01x02", XH2),
    # Power from the pack board (the cell protector, key switch and 5 V boost moved there in P5).
    # 1-2 GND, 3 VBAT_SW, 4 +5V, 5 SDA_3V3, 6 SCL_3V3.
    "J_PWR1": ("PWR", "Connector_Generic:Conn_01x06", XH6),
    "J_LCD1": ("LCD", "Connector_Generic:Conn_01x04", XH4),
    "J_NFC1": ("NFC", "Connector_Generic:Conn_01x04", XH4),
    "J_BTN_R1": ("BTN_R", "Connector_Generic:Conn_01x04", XH4),
    "J_BTN_B1": ("BTN_B", "Connector_Generic:Conn_01x04", XH4),
    "J_BUZ1": ("BUZ", "Connector_Generic:Conn_01x02", XH2),
    "J_SPK1": ("SPK", "Connector_Generic:Conn_01x02", XH2),
    # Cell protection in the negative lead (the Heltec V4 has no under-voltage cutoff, see
    # fab/PARTS_REVIEW.md) now lives on the pack board: J_PWR1.3 already is the protected, switched
    # pack rail and board GND is the pack ground.
    # Power (bulk on the switched pack rail; the boost is on the pack board)
    "C_BULK1": ("47uF 10V", "Device:C", C1206),
    "C_BULK2": ("47uF 10V", "Device:C", C1206),
    "C_NFC1": ("100uF 6.3V", "Device:C", C1206),
    # I2C GPIO expander (address 0x20) for buttons, LED/buzzer drivers and the amp's CTRL
    "U2": ("TCA9534PWR", "Interface_Expansion:TCA9534", TSSOP16),
    # I2S class-D amp on VBAT_SW, BTL output to J_SPK1, fixed gain. Replaced the MAX98357A on 2026-09-30
    # (about $0.95 cheaper per board; same Extended setup fee). CTRL high = right I2S slot, low = off.
    "U3": ("NS4168", "local:NS4168", ESOP8),
    # Datasheet asks for ~100 uF + 1 uF at VDD; the 100 uF 6.3 V part is fine on a <= 4.2 V rail
    "C_AMP1": ("100uF 6.3V", "Device:C", C1206),
    # I2C level shifter (5V-side pull-ups DNP: LCD backpack has its own)
    "Q_SDA1": ("BSS138", *BSS138),
    "Q_SCL1": ("BSS138", *BSS138),
    "R_SDA3": ("4k7", "Device:R", "Resistor_SMD:R_0805_2012Metric_Pad1.20x1.40mm_HandSolder"),
    "R_SCL3": ("4k7", "Device:R", "Resistor_SMD:R_0805_2012Metric_Pad1.20x1.40mm_HandSolder"),
    "R_SDA5": ("4k7", "Device:R", "Resistor_SMD:R_0805_2012Metric_Pad1.20x1.40mm_HandSolder"),
    "R_SCL5": ("4k7", "Device:R", "Resistor_SMD:R_0805_2012Metric_Pad1.20x1.40mm_HandSolder"),
}
# Do not populate: the LCD backpack has its own 5V-side pull-ups.
DNP = {"R_SDA5", "R_SCL5"}


# Low-side drivers (loads are ~15 mA LED rings and an ~8 mA buzzer, well inside a BSS138): name -> load resistor value or None. The ONPOW LAS1-AGQ-11E/x/6V button LEDs
# have a built-in resistor, so R_LLR1/R_LLB1 are 0R jumpers (footprint kept as a brightness knob).
DRIVERS = {"LR": "0R", "LB": "0R", "BZ": None}
for n, r_load in DRIVERS.items():
    PARTS[f"Q_{n}1"] = ("BSS138", *BSS138)
    PARTS[f"R_G{n}1"] = ("1k", *R0805)
    PARTS[f"R_PD{n}1"] = ("10k", *R0805)
    if r_load:
        PARTS[f"R_L{n}1"] = (r_load, *R0805)
PARTS["D_FLY1"] = ("1N4148W", "Diode:1N4148W", "Diode_SMD:D_SOD-123")

# Button inputs: 10k pull-up, 100nF, 1k series
for t in ("R", "B"):
    PARTS[f"R_PU{t}1"] = ("10k", *R0805)
    PARTS[f"R_S{t}1"] = ("1k", *R0805)
    PARTS[f"C_B{t}1"] = ("100nF", *C0805)
PARTS["C_EXP1"] = ("100nF", *C0805)  # U2 decoupling
PARTS["R_INT1"] = ("10k", *R0805)  # U2 INT pull-up
PARTS["C_AMP2"] = ("100nF", *C0805)  # U3 VDD decoupling (next to C_AMP1)
# CTRL series resistor + pull-down: CTRL abs max is VDD (VBAT_SW, can sag below the 3V3 expander high),
# the 1k limits that current. No internal pull-down is documented, so the 10k (expander side; CTRL draws
# no current, so it still pulls CTRL to 0 V) holds the amp off while the expander pins float at reset.
PARTS["R_SD1"] = ("1k", *R0805)
PARTS["R_SDPD1"] = ("10k", *R0805)

for i in range(1, 5):
    PARTS[f"H{i}"] = ("M3", "Mechanical:MountingHole", "MountingHole:MountingHole_3.2mm_M3")

# JLCPCB assembly: (value, footprint) -> LCSC part number. Changing a part's value or footprint
# fails check() until a new part is picked (editing the shared R0805/C0805/BSS138 tuples moves
# their keys along). All verified live against JLCPCB's parts API on 2026-09-29.
# Type: B = Basic, P = Preferred Extended (no setup fee), E = Extended.
LCSC = {
    ("100nF", C0805[1]): "C49678",  # B YAGEO CC0805KRX7R9BB104 50V X7R
    ("47uF 10V", C1206): "C96123",  # B Samsung CL31A476MPHNNNE X5R
    ("100uF 6.3V", C1206): "C15008",  # B Samsung CL31A107MQHNNNE X5R
    ("1N4148W", "Diode_SMD:D_SOD-123"): "C81598",  # B ST Semtech 1N4148W
    ("TCA9534PWR", TSSOP16): "C783615",  # E TI TCA9534PWR
    ("NS4168", ESOP8): "C910588",  # E Nsiway NS4168 (lcsc.com 2026-09-30: $0.38, ~9.9k stock)
    ("BSS138", BSS138[1]): "C7420339",  # P hongjiacheng BSS138 (G=1 S=2 D=3)
    ("10k", R0805[1]): "C17414",  # B 0805W8F1002T5E
    ("0R", R0805[1]): "C17477",  # B UNI-ROYAL 0805W8F0000T5E
    ("1k", R0805[1]): "C17513",  # B 0805W8F1001T5E
    ("4k7", R0805[1]): "C17673",  # B 0805W8F4701T5E
    ("Heltec_J2", SOCKET18): "C2905422",  # E Kinghelm KH-2.54FH-1X18P-H8.5
    ("Heltec_J3", SOCKET18): "C2905422",
}
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

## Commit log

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2026-09-28 hardware: tighten design.py self-check (all header pins, DNP set)
    [design.py]
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2026-09-29 hardware: C_IN1 rotation, silk stroke, route.py review fixes
    C_IN1 at 270 deg puts its VBAT_SW pad next to L1.1: VBAT_SW routes via-free
    on F.Cu. Silk stroke 0.15 mm minimum. Zone island removal set explicitly.
    route.py: missing java and a missing GND pour exit cleanly; note that the
    unrouted-count regex follows Freerouting 2.4.1 log wording.
    [carrier.kicad_pcb]
2026-09-29 hardware: reproducible build and JLCPCB fab package
    Makefile chains design check -> schematic -> netlist parity -> placed
    board -> autoroute -> ERC/DRC -> fab outputs. check_gerbers.py parses
    the upload zip (layer set, 90x60 outline, drill sizes, NPTH holes).
    fab/ORDERING.md is the JLCPCB order-form checklist. routed_*.png are
    replaced by the byte-identical top/bottom.png.
    [bom.csv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]
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2026-09-29 hardware: fab check hardening, build dir, ordering wording
    - check_gerbers.py: layers that must draw need D01/D03 (header-only
    F.Cu now fails); Edge extent parsed from coordinate lines only; NPTH
    holes checked at their 4 positions; one error style; docstring states
    that open outlines are left to DRC.
    - Makefile: a zip failing the check is deleted; netlist and ERC/DRC
    reports go to gitignored build/ (path echoed on failure); drop
    .DELETE_ON_ERROR and clean; recipe comment moved above fab.
    - check_netlist.py defaults to build/carrier.xml.
    - fab/gerbers/ gitignored and untracked (the zip stays committed).
    - ORDERING.md: JLC via-size wording, hole position wording.
    - Plan doc: zip name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
    [carrier-B_Cu.gbl, carrier-B_Mask.gbs, carrier-B_Paste.gbp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]
2026-09-29 hardware: JLCPCB assembly BOM + CPL (full SMD+THT)
    design.py: LCSC map keyed by (value, footprint); check() fails if an
    assembled part (not DNP, not a mounting hole) has no LCSC number or an
    entry is unused. Part numbers verified live against JLCPCB's parts API
    on 2026-09-29. Cap values now state the picked parts' ratings:
    22uF 25V, 220uF 16V, 100uF 25V.
    jlc.py (run by make fab) writes fab/jlc_bom.csv and fab/jlc_cpl.csv from
    design.py and kicad-cli's pos export, and checks: BOM and CPL designators
    match exactly once, every row has an LCSC number, the pos anchors equal
    the board coordinates with Y negated (the Gerber convention), and every
    placement lies inside the Gerber Edge.Cuts extent.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
    [bom.csv, carrier.kicad_pcb, carrier.kicad_sch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]
2026-09-29 hardware: jlc.py courtyard centres, pcbnew-only CPL, review fixes
    - CPL Mid X/Y is the F.CrtYd bounding-box centre (asserted present). This
    fixes the 0.525 mm JST-XH body offset; J2/J3 move 0.029 mm, radial caps
    0.001 mm, SMD parts unchanged.
    - Reference, rotation (0-360) and side come from pcbnew alone. Dropped
    the kicad-cli pos export and the anchor cross-check that compared the
    two sources.
    - jlc.py calls design.check() first; make fab removes fab/jlc_*.csv
    before rebuilding, so a failed jlc.py leaves no stale CSVs.
    - design.py LCSC map reuses the R0805/C0805/AO3400A footprint strings.
    - ORDERING.md: Economic PCBA takes 2-50 boards, THT by wave soldering,
    stock figures dated.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
    [jlc_cpl.csv]
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2026-09-29 hardware: I2S speaker amp, TCA9534 expander, ceramic bulk caps
    Task A10 (design Part 6):
    - U2 TCA9534PWR (C783615) at 0x20 on the 3V3 I2C bus, INT on GPIO6
    (R_INT1 10k): buttons on P0/P1, LED/buzzer gate drives on P2-P4,
    amp SD_MODE on P5 (through R_SD1 1k, datasheet abs-max guidance).
    - U3 MAX98357AETE+T (C910544) on VBAT_SW, I2S on GPIO47/48/21, 12 dB,
    BTL output to J_SPK1 (pin 1 OUT-, silk "SPK (BTL, not GND)").
    - THT 220uF/100uF -> 2x 47uF 10V (C96123) + 100uF 6.3V (C15008) 1206
    Basic ceramics; F1 -> 2A PTC 1206L200/16NR (C22374899).
    - R_LLR1/R_LLB1 -> 0R (C17477): ONPOW 6V button LEDs have a resistor.
    - GND leaves the Power net class, Power clearance 0.2 mm, board min
    track 0.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
    [bom.csv, carrier.kicad_pcb, carrier.kicad_sch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]
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2026-09-29 device: esp32s3 scaffold and blinky (builds for V4-R2/R8)
    Generated with:
    cd firmware && esp-generate --headless -s -o esp32s3 -o unstable-hal \
    -o embassy -o log -o esp-backtrace -O . device
    (embassy requires unstable-hal). Adds asg-core path dep, v4-r2/v4-r8
    features with an exactly-one guard, board.rs pin map + Board split, and
    an Embassy blinky logging "alive". Flashing pending hardware.
    [board.rs, main.rs]
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2026-09-29 hardware: schematic picks paper size that fits (was overflowing A3)
    After A10 the last part row reached y=320 mm on a 297 mm A3 sheet, so
    C_EXP1/R_INT1/C_AMP2/R_SD1 fell outside the frame. gen_sch now picks the
    smallest sheet (A3/A2/A1) that holds all parts clear of the title block
    and fails loudly otherwise. Now A2; ERC/parity/DRC unchanged, board
    byte-identical.
    [carrier.kicad_sch]
2026-09-29 hardware: carrier schematic rebuilt as block-structured, A*-routed (replaces label-per-pin)
    [carrier.kicad_sch]
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2026-09-30 hardware: merge gate/pull-down resistors into 1k/10k; add parts review notes
    R_G* 100R -> 1k, R_PD* 100k -> 10k (two fewer BOM lines). Review notes cover
    the fuse derating, missing under-voltage protection (unverified), caps and diodes.
    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
    [design.py]
2026-09-30 hardware: regenerate for 4-pin XH, add XB8089D cell protection, power model
    Regenerated with KiCad 9 after the cloud parts review (make all: ERC 0, DRC 0,
    0 unrouted). Six 4-pin XH connectors do not fit the top edge, so J_BTN_R1 moves
    to the bottom edge under J2; the schematic connectors shift because Conn_01x04
    anchors on pin 2. Two-wire connectors label only pins 1-2 on silk.
    The Heltec V4.2 schematic shows no under-voltage cutoff (CN3165 charger, Q4 is
    reverse-polarity only), so U4 XB8089D (C79928) goes in the cell negative lead
    with R_PROT1 1k / C_PROT1 100nF. Symbol lives in the project lib local.kicad_sym.
    power_budget.py estimates runtime per scenario from the Heltec datasheet and
    m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
    [bom.csv, carrier.kicad_pcb, carrier.kicad_sch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]
2026-09-30 hardware: replace MAX98357A with NS4168 I2S amp
    U3 becomes an NS4168 (C910588, eSOP-8, ~$0.95 cheaper per board, same
    Extended setup fee). CTRL high selects the right I2S slot, so firmware must
    send audio in the right slot (or both) and hold CTRL low between clips
    (13 mA when on). R_SD1 stays in series (CTRL abs max is VDD); new R_SDPD1 10k
    on AMP_SD keeps the amp off while the expander floats at reset. C_AMP1 is now
    100 uF per the datasheet. Both reuse existing BOM lines.
    make all: ERC 0, DRC 0, 0 unrouted. Deluxe 20 BOM lines, Budget 19.
    [bom.csv, carrier.kicad_pcb, carrier.kicad_sch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]
2026-09-30 hardware: source-check the power budget, plan 100 mA LCD backlight
    Every input in power_budget.py checked against its source. The Heltec V4
    table 3.4 rows are exact as cited (75 / 750 / 170 mA, 20 uA), and the V4's
    3V3 is a CE6260B33M linear LDO, so the USB-measured mA does carry over to the
    battery. The airtime formula reproduces the published table (56.6 ms SF7/20 B,
    144 ms SF9/10 B, 991 ms SF12/10 B), so those are now asserts.
    Fixes:
    - two button LED rings are fitted, not one (design.py's own ~15 mA each)
    - GNSS 25 -> 29 mA (Quectel L76K hardware design; 41 mA with an active antenna)
    - cells 3400 -> 3350 mAh (the datasheet minimum, not the typical)
    - USABLE 0.90 -> 0.84: Heltec's own V4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
    [power_budget.py]
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2026-10-01 hardware: pack netlist fixes (D1 symbol, charger buck output, feedback divider)
    D1 was Device:SS34 (does not exist); L_CHG.2 belongs on SYS (buck output) and
    R_FB2.2 on GND (boost feedback divider bottom), found by running the schematic
    generator against the netlist.
    [pack.py]
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2026-10-01 hardware: pack board schematic layout (P3.1, P3.2)
    9 hand-placed blocks, one tag per block for every multi-block net, power ports
    for the six rails that carry power_in pins (PWR_FLAG on the five passive ones).
    gen_sch: a symbol body box no longer swallows its own pin cell (the NTC
    thermistor draws over its pin); byte-identical carrier output.
    make BOARD=pack sch -> netlist matches design.py
    kicad-cli sch erc --severity-all -> 0 violations
    [pack.kicad_sch]
2026-10-01 hardware: pack board outline and placement (P4.1)
    Board 140x100: the four 87.88x21.66 holder courtyards fill an 88x87 block,
    so the design doc's 90x85 has no room for a single-side SMD strip or the
    edge connectors. Branch parts sit under their own cell (held ~12 mm clear
    by the holder), the rest of the SMD assembly in the right strip.
    gen_sch: board modules may override DRC rules and rule severities.
    pack: min_hole_clearance 0.15 (stock USB-C footprint geometry),
    courtyards_overlap ignored (under-holder parts).
    DRC --severity-all on the unrouted board: 0 errors.
    [pack.kicad_pcb]
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2026-10-01 hardware: pack board 96x90 with bottom-side MYOUNG holders
    The Keystone 1042 holders were only 14.86 mm tall around an 18.3 mm
    cell, so parts placed under them could not fit. Swap to MYOUNG
    BH-18650-A6AJ012 (C19184084, THT, footprint in local.pretty from drawing
    MY-CP-0373) on the bottom side, with the MF52 bead NTCs in the holder
    floor window; every SMD part stays on top for single-side assembly. The
    board shrinks from 140 x 100 to 96 x 90 mm.
    gen_pcb.py: BOTTOM set flips footprints, project fp-lib-table adds the
    local library. VPACK/SYS split from the BQ25601 pins through 1206 0R
    jumpers so the rails can take the 0.8 mm Power class.
    make boards is green (ERC, DRC parity, gerbers, jlc).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
    [bom.csv, jlc_bom.csv, pack.kicad_pcb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]
2026-10-01 hardware: pack board without protector ICs, Basic diode-OR and TS pair
    Cost cut after a ~$140 quote for 5 assembled boards (15 SMD Extended
    types at ~$3 each). The per-cell MCU switches already default off, so a
    dead or reset MCU leaves every cell open; with the 5 A fuses and the
    BQ25601's CV/OVP they cover what the four XB8089D did. Holder- now goes
    straight to GND. A single shared protector was rejected: with all
    switches open the pack rail is 0 V and it would cut the MCU's ground
    return, so the board could never boot.
    - U_P1-4, R_PROT1-4, C_PROT1-4 removed.
    - Diode-OR: 3x BAT54C -> 5x B5819W SOD-123 (C8598, Basic), one per
    cell in its own band and D_OR5 for SYS.
    - TS bias 5.23k/30.9k -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
    [bom.csv, jlc_bom.csv, pack.kicad_pcb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]
2026-10-01 docs: pack board simplification delta and ordering update
    Design doc gains a "Simplification delta (2026-10-02)" section (what
    replaced each XB8089D job, the rejected shared protector, the remaining
    firmware-UV gap) and its per-cell chain, parts table, bring-up and risks
    follow. ORDERING.md section 7: 11 Extended types (~$33), 37 BOM lines,
    105 placements, 165 vias, SOD-123 diode-OR.
2026-10-01 hardware: one PAC1934 replaces the two INA3221s on the pack board
    Four channels in one chip (C623960, UQFN-16 4x4, KiCad
    Sensor_Energy:PAC1934x-xJQ), cell n on channel n, with on-chip power
    accumulators for coulomb counting. VBUS is read at SENSE+, which sits on
    the fuse side of the shunt, so each channel still sees its own cell with
    the switch open. ADDRSEL to GND = 0x10. SLOW/ALERT and PWRDN take the
    two MCU pins the INA alerts used (28, 29), both pulled up so the monitor
    runs without firmware; the pull-ups sit beside the MCU.
    Shunt 20 -> 10 mOhm (FMF06FTHR010-LH, C105362, 1 W): the PAC1934 allows
    only 500 mV across its sense pins, and with no protector IC a hard short
    drives about 25 A p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
    [bom.csv, jlc_bom.csv, pack.kicad_pcb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]
2026-10-01 docs: PAC1934 monitor in the pack design and ordering notes
    Simplification delta gains the monitor and shunt swap; block diagram,
    per-cell chain, MCU pin table, firmware loop (REFRESH then SLEEP,
    bidirectional channels), parts table and a PAC1934 datasheet-facts
    section follow. ORDERING.md section 7: fee list, U_MON placement check,
    104 placements, 142 vias.
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2026-10-02 docs: variant B review fixes; boards builds pack_b too
    From the whole-branch review: the design doc now states the firmware rule
    the hardware forces (never open the last closed cell - opening every cell
    removes the Heltec's own supply and the pack cannot recover without
    pulling all four cells), adds R_PWRDN to the Removed row, corrects the
    key-off drain arithmetic and rail (about 8 uA all-closed, ~20 uA
    all-open), and the variant-A cross-reference no longer calls variant B
    "design only". make boards now also builds BOARD=pack_b.
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2026-10-02 hardware: LiPo board parts and nets
    New standalone hardware/lipo.py (BOARD=lipo through board.py and make boards):
    XT60 solder pads -> 5 A fuse -> AO3407A reverse FET with a 12 V gate clamp ->
    SMBJ15A TVS -> two TPS54302 bucks (4.10 V VBAT_SW, 5.07 V +5V) and a
    HT7533-1 always-on 3.3 V LDO -> STM32C071 with always-on balance dividers and
    an open-drain buck kill. 59 parts, 30 nets. check_power_path asserts the input
    order and the EN wiring the latched cutoff depends on. L0.1 substitutions:
    1.5 mm2 solder pads (14 AWG) and 10 uF LDO caps.
    [board.py, lipo.py]
2026-10-02 hardware: LiPo board schematic
    Six hand-placed blocks wired by gen_sch.py: input/fuse/reverse-FET/TVS, the two
    TPS54302 bucks, key enable + MCU kill + J_PWR1, 3V3 LDO + STM32C071 + SWD pads,
    the balance dividers, and the mounting holes/PWR_FLAGs. check_netlist.py proves
    the netlist is lipo.py's. Layout fixes found by running gen_sch: J_BAL1 and
    J_PWR1 rotated so their pin stubs face open space, GND wired in the J_PWR1
    block with a GND tag (the pack.py pattern), and tags added for KILL_G, BAL1 and
    TAP3_MID.
    [lipo.kicad_sch]
2026-10-02 hardware: LiPo board placement
    70 x 50 mm board (the plan's 50 x 40 could not hold the two bucks, the LQFP32,
    three connectors and the input chain without courtyards colliding): LiPo pads
    left, balance lead top, J_PWR1/J_KEY1 right, M3 holes at the corners, the two
    bucks in the middle with their input caps, the MCU/LDO/test pads lower-left and
    the dividers along the top. gen_pcb + a standalone DRC pass show 0 courtyard
    overlaps, 0 silk/mask/edge violations (only the unrouted ratsnest remains).
    [lipo.kicad_pcb]
2026-10-02 hardware: LiPo board routed, fab package
    Freerouting: 462 tracks/vias, 0 unrouted. ERC 0, DRC 0 violations, 0 schematic
    parity issues. The two SW nodes moved from the Power class to Default: the
    stock TSOT-23-6 SW pad (0.95 mm pitch) cannot take a 0.8 mm track, so
    Freerouting left it unrouted. fab/lipo/: gerbers 11 files, outline 70x50,
    PTH 0.3/0.95/1.0/2.15 mm, 4 x 3.2 mm NPTH; the JLC BOM/CPL leave out J_IN1 and
    the five test pads. make boards rebuilds the carrier and both pack boards
    unchanged.
    [bom.csv, jlc_bom.csv, lipo.kicad_pcb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]
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2026-10-02 hardware: review fixes - assert SW_B, document the SW-node width
    Whole-branch review: the two SW nodes route at Default 0.25 mm (the TSOT-23-6
    SW pad cannot take a 0.8 mm track), which is at the edge of its ampacity for
    buck A's ~1.5-2 A RMS. NETCLASS_EXPECT now asserts SW_A and SW_B, and the
    design doc and ORDERING.md record the width, the ampacity estimate and why the
    autorouter cannot widen it (short run with GND pours on both layers, accepted).
    [lipo.py]
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2026-10-02 hardware: power model review fixes (typed weekend loop, parked-days note)
    [power_budget.py]
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2026-10-02 mech: quote for MJF PA12, not SLA
    MJF PA12 dyed black is the intended process: it takes the M3 self-tapping
    posts without cracking, needs no supports, and its minimum feature is well
    below this part's 1.0 mm mesh land. The sheet now names the process, asks the
    shop to hold the 20.4 mm sleeve bore and report the as-built figure, and
    states the outside envelope correctly (189.2 x 139.2 in a 190 x 140 box).
    [jlc3dp_quote_2026-10-02_step.csv, jlc3dp_quote_2026-10-02_stl.csv]
2026-10-02 mech: fix collisions with the box columns; halve the print cost
    The MJF quote was volume, and looking into it turned up two real bugs:
    - the lid panel was a full plate and the box's corner columns are solid to
    the rim, so 1200 mm3 of panel sat inside a column at three corners;
    - the tray's wall backings and cable clips did the same at three corners,
    and a firmware-side stem helper grew 2 mm past the wall on short walls.
    Both now have reliefs and clearances, and a geometric check intersects every
    part with the column solids so this cannot come back.
    Volume is also down 262 -> 180 cm3 by cutting the two features that were pure
    bulk: the backings were 26x12 mm solid blocks (now a 20x6 nu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
    [jlc3dp_quote_2026-10-02_step.csv, jlc3dp_quote_2026-10-02_stl.csv]
2026-10-02 mech: audit against the JLC3DP design guideline, fix four violations
    Read jlc3dp.com/help/article/3d-printing-design-guideline and asserted every
    MJF rule in check.py (build size, size-dependent wall, clearance, hole aperture
    vs depth, small columns, escape holes, embossed detail, threads). Four real
    problems:
    - tray floor field 1.2 mm where MJF wants 1.5 at a 189 mm part; mesh land
    1.0 mm where it wants 1.2. Floor is 1.6, mesh land 1.5 (3.5 mm holes at a
    5.0 mm pitch, still 42% open).
    - FIT 0.4 mm total is 0.2 per side, but MJF's hole tolerance is +-0.3 mm and
    holes shrink, so the drop-in gap was inside process noise. FIT is now 0.8.
    - the wall bushings were degenerate: with the hole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
    [jlc3dp_quote_2026-10-02_step.csv, jlc3dp_quote_2026-10-02_stl.csv]
2026-10-02 mech: process profiles, so the same model is validated and quoted per process
    The lid and tray are 88% of the MJF bill and are the wrong shape for a volume
    priced process, so the rule set is now switchable: MECH_PROCESS=mjf|fdm|sla
    picks the guideline column, and everything derived from it follows.
    - FIT now comes from max(clearance, hole tolerance) with margin, so MJF gets
    0.8 mm and FDM 1.3 mm without hand editing.
    - the tray floor field is sized off the rule (1.6 MJF, 2.1 FDM) instead of
    picked, because the difference is not a free choice.
    - the lid's button bosses grow the panel to 10.0 mm under FDM, which is what
    gets it over that process's 30 x 30 x 10 minimum.
    - MECH_PARTS limi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
    [jlc3dp_quote_2026-10-02_fdm_step.csv, jlc3dp_quote_2026-10-02_fdm_stl.csv, jlc3dp_quote_2026-10-02_mjf_step.csv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]
2026-10-02 mech: v2 tray - skeleton floor, no wall backings, slimmer saddles
    Measured the v1 tray feature by feature first, because the laser-plate plan
    rested on a guessed number and the guess was wrong: the floor is only 44.5 of
    117.7 cm3, so removing it entirely could never have saved the 75% claimed.
    Everything below it is structure that has to exist whatever the floor is.
    v2 instead takes the three changes that need no new supplier, no fasteners and
    no moved interface:
    - the floor's empty middle is cut away, leaving a rim and the two Y bands that
    carry the posts, clips and sleeves. 32% of the floor area. The windows stop
    exactly at the saddle rail edges so no sliver is left beside them.
    - th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
    [jlc3dp_quote_2026-10-02_fdm_stl.csv, jlc3dp_quote_2026-10-02_mjf_stl.csv]
2026-10-02 mech: quote sheet derives its numbers, and v2 volumes
    The sheet told the shop 'thinnest wall 2.0 mm' while the v2 floor field is
    1.6 mm. A supplier sheet that disagrees with the model is worse than no sheet,
    so the thinnest-material line, the clearance and the process name are all read
    from params now instead of typed, and the envelope/clearance line no longer
    hardcodes 0.4 mm. Also: FDM filament is not 'dyed', the colour belongs in the
    material label, and the FDM sleeve bore is printed from its own FIT.
    [jlc3dp_quote_2026-10-02_fdm_step.csv, jlc3dp_quote_2026-10-02_fdm_stl.csv, jlc3dp_quote_2026-10-02_mjf_step.csv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]
2026-10-02 hw: TME order lists for the boards and the off-board parts
    tme.py maps every LCSC number in the JLC BOMs to a TME symbol (make fab
    runs it after jlc.py) and writes tme_bom*.csv for TME Quick Buy upload,
    plus tme_other*.csv for the parts TME does not sell (STM32C071KBT6,
    MT3608, NS4168, TS-1088). Substitutes are commented in place.
    fab/offboard/ holds the per-device off-board lists; the enclosure's TME
    code in OFFBOARD_PARTS.md is corrected.
    [offboard_other.csv, tme_bom.csv, tme_bom_budget.csv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]
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2026-10-02 hw: board.py and the Makefile know the *_tme boards
    BOARD=carrier_tme|pack_tme|lipo_tme selects the hand-built modules, and
    make fab skips jlc.py for them (they have no JLCPCB BOM/CPL); the
    schematic BOM export still runs for both.
    [board.py]
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2026-10-02 hw: tme.py imports board as a module, not a name
    A board module imports tme for its table, and tme imported board's
    design name at import time, so the cycle broke: board was still mid-import
    when tme ran. Importing the module and reading board.design inside main()
    keeps tme.py standalone and cycle-free.
    [tme.py]
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2026-10-02 hw: carrier TME hand-build data
    carrier_tme.py derives from design.py: the NS4168 goes and a PCM5100A
    I2S DAC plus a PAM8302A SO-8 class-D amp come in, with the charge-pump,
    supply and output RC caps, the 240k input network, and AMP_SD driving
    the amp SD and the DAC XSMT. TME table of 28 entries replaces LCSC.
    [carrier_tme.py]
2026-10-02 hw: carrier TME hand-build board
    Schematic and PCB for the PCM5100A + PAM8302A carrier: the amp block is
    regenerated with explicit global labels for every DAC/amp net (the
    labeler cannot name the short DAC-to-amp runs) and +3V3/GND wired there
    because the DAC's three supply pins cannot each take a power port. DAC
    and amp sit in the J_SPK1 corner at >=1 mm from their neighbours; routed
    board is ERC 0/0 and DRC 0 violations / 0 unconnected / 0 parity. No JLC
    BOM/CPL; fab/carrier_tme/tme_bom.csv has 22 lines.
    [bom.csv, carrier_tme.kicad_pcb, carrier_tme.kicad_sch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]
2026-10-02 hw: pack A TME hand-build data
    pack_tme.py derives from pack.py: 4x INA228 replace the PAC1934 (own
    10R split, addresses 0x40-0x43, ALERTs together), STM32L072KZT6 (I2C3
    internal bus, I2C1 link), BQ25601RTWT on the hand-solder QFN, USB4085
    through-hole USB-C, THT 6x6 tact switches, MCP1640 boost without the
    catch diode, 4.7 uH L1, 24k FB divider, 0603 hand NTC. TME table of 38
    symbols replaces LCSC.
    [pack_tme.py]
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2026-10-02 hw: pack A TME hand-build board
    Four INA228s replace the PAC1934, one per cell block beside that cell's
    10R Kelvin split; the L072 MCU block moves and wires its rails; the
    MCP1640 drops D1. Board is routed with ERC/DRC clean.
    The USB4085's own THT pads sit 0.15 mm apart and the hand-solder QFN's
    pin-1 silk landed on its extended pads, so pack_tme lowers the Default
    clearance to 0.15 mm and the QFN's pin-1 marker moves to F.Fab.
    [bom.csv, pack_tme.kicad_pcb, pack_tme.kicad_sch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]
2026-10-02 hw: power model for the TME builds
    --tme swaps the pack MCU Stop current (L072 0.43 uA, DS10690 Table 37) and
    the monitor (4x INA228 2.8 uA shutdown) for the C071/PAC1934 figures, and
    the NS4168 for PCM5100A standby + PAM8302A quiescent. Both models pass the
    weekend target; the TME pack quiescent drops from 112 to 34 uA.
    [power_budget.py]
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
